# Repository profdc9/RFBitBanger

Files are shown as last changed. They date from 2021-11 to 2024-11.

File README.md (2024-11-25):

# RFBitBanger
The RFBitBanger is an off-the-grid QRP radio.  It is not just designed to be used off the grid, it is designed to be assembled and maintained off-the-grid.  Most radios require specialized parts that would be difficult to obtain in an extreme parts shortage or in remote places.  This radio is designed to be assembled and maintained using the most common jellybean components that might be in a hobbyist junkpile.  It will mainly support low bandwidth/digital modes to make the most of limited power.  

A presentation presented at the 2023 QSO Today conference on the RFBitBanger can be viewed on Youtube [here](https://www.youtube.com/watch?v=Fbgs_4QsKnE).

Design goals:

* A single band double-sideband radio, with the band changed by pluggable external filters on 20 m to 80 m.  A double-balanced ring mixer is used to provide good rejection of strong stations while not requiring any custom ICs such as SA612 or FST3253.  The mixer has strong drive to reduce nonlinearity.
* Can be assembled and operated by a properly licensed individual that may not have a great deal of electronics experience or experience at making HF contacts.  The radio is made from readily available through-hole parts which are widely available and have multiple vendor alternatives.  
* The parts needed are very common so that cheap spare parts can be stockpiled or scrounged from other equipment so that the radio may be more easily maintained in off-grid conditions.  The includes ATMEGA328P/Arduino Nano, LM358 op-amp, LM386 audio amplifier, 2N7000 MOSFETs, 2N3904 NPN transistor, SS8550 PNP transistor, and a HD44780 display.  It can use a SI5351A frequency synthesizer IC soldered to the board, or a plug-in SI5351A developmnet module.  There is a MS5351 workalike for this IC as well.  Ferrite cores are needed for transformers/chokes which can be easily bought (FT50-43) or scrounged as EMI suppression beads from cables.
* The radio has a novel digital mode called SCAMP, implemented on a ATMEGA328P (Arduino processor) which performs coherent FSK demodulation and forward error correction to achieve excellent performance in weak signal conditions.  No PC is required for this digital mode; it is implemented all on the Arduino.  The mode is designed to be simple to set up to make it easy to initiate a contact.
* It has a 50 ohm output and can use a simple quarter wave wire as an antenna.  A built-in RF ammeter with LED helps one adjust the length of the antenna for maximum radiation.
* The output power amplifier consists of 3 2N7000 transistors driven by a fourth 2N7000 transistor.  2N7000 transistors can be found generically for $0.03 each.  The output power stage is a class E amplifier with 3.5 to 5.0 W output based on serial resonance filters.  The best performance is obtained by using NP0/C0G capacitors and T50-6 core inductors, however, high voltage ceramic disc capacitors and air-core inductors can be used as substitutes with reduced performance.  The serial resonance filter is on a pluggable module that is replaced for each band.  BS170 transistors may be substituted for 2N7000 transistors easily as these have the reverse pinout to the 2N7000.
* It has PCBs available for the transceiver, but it could also be built on perfboard or using point-to-point wiring.  The PCB, however, is likely to be better performing.  There are also PCBs available for the filters.
* A jumper allows the amplifier board to be bypassed on receive to achieve MF and HF coverage.  The DSB receiver can be used with limitations as a receiver for the AM broadcast band and AM broadcast shortwave bands.
* It has an audio speaker output based on the LM386 IC.
* A second display board breaks out the display, and optional inputs for a microphone, a straight or iambic key, and a headphone/speaker jack.  
* A PS/2 keyboard is supported for full operation of the transceiver, including message entry, frequency selection, and data mode selection.
* There are five buttons corresponding to four arrow keys and an enter key.  Alphanumeric messages may be entered this way if necessary.
* There is a full complement of support for CW, including keyclick elimination on transmit, a built-in CW decoder, a CW encoder, and straight and iambic key support.
* RTTY 45/170 is supported as a mode for transmit and reception.
* Uses a common 2X16 HD44780-based LCD display.
* Supports SSB transmission based on the same method of the uSDX of frequency tracking and envelope recovery.
* Includes a 3d printable case, a 3d printable iambic key, and 3d printable coil forms for air core inductors.
* The PCBs are licensed under the CC-BY-SA 4.0 open source license, and the source code is licensed under the zlib open source license.

The RFBitBanger folder is the schematic and PCB for the radio itself.  The MatchTest is a PCB that has a directional coupler for measuring forward/reverse power as well as a reflection bridge to help match antenna impedance.  The Code folder contains the current RFBitBanger code.  The CAD directory contains FreeCAD parametric models and STL files. The Docs directory contains a guide to the transceiver and the details of the SCAMP digital mode implementation.

This design was started after a discuss on the [Collapse OS](http://collapseos.org) mailing list about hardware is maintainable even without access to parts suppliers, for example Digikey/Mouser, etc. or even Amazon.  Projects such as [civboot](https://github.com/civboot/civboot) seek to provide a means of resurrecting technology and infrastructure after a catastrophic event.  This design is to provide a means of communication if other forms of communications become unavailable, especially in rural areas or urban environments with compromised infrastructure.

Any comments to profdc9 AT gmail.com.

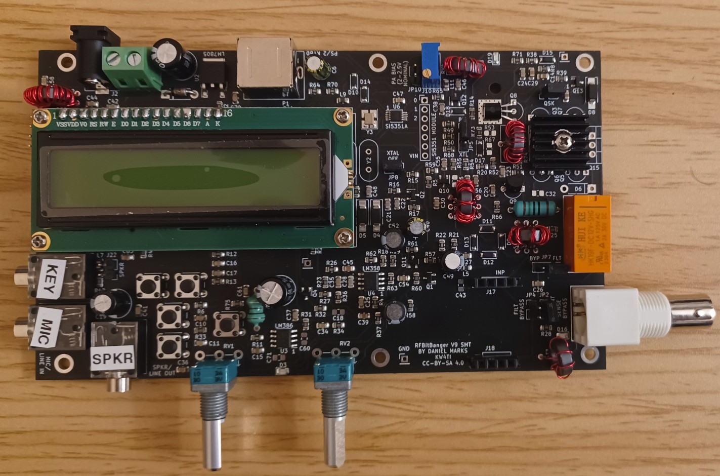
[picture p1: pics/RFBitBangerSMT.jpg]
RFBitBangerSMT

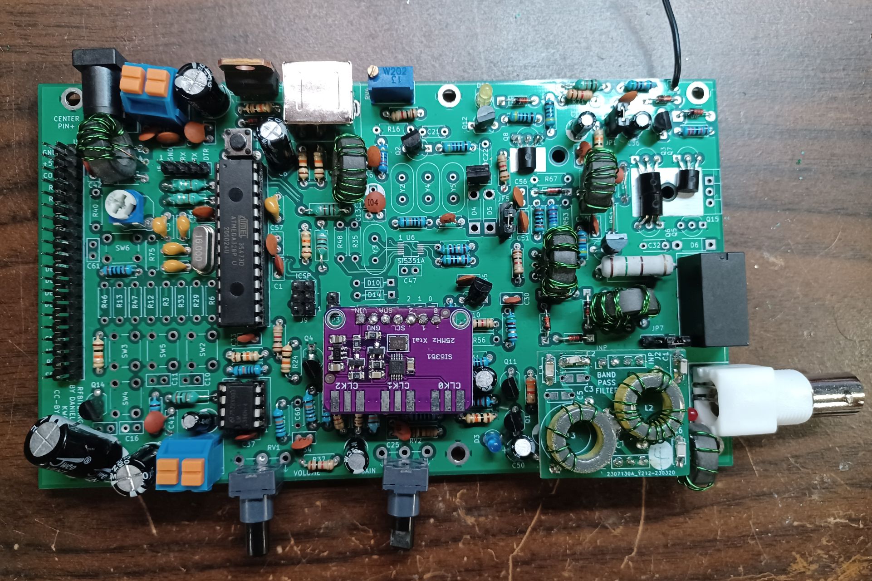
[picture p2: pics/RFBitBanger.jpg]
RFBitBanger

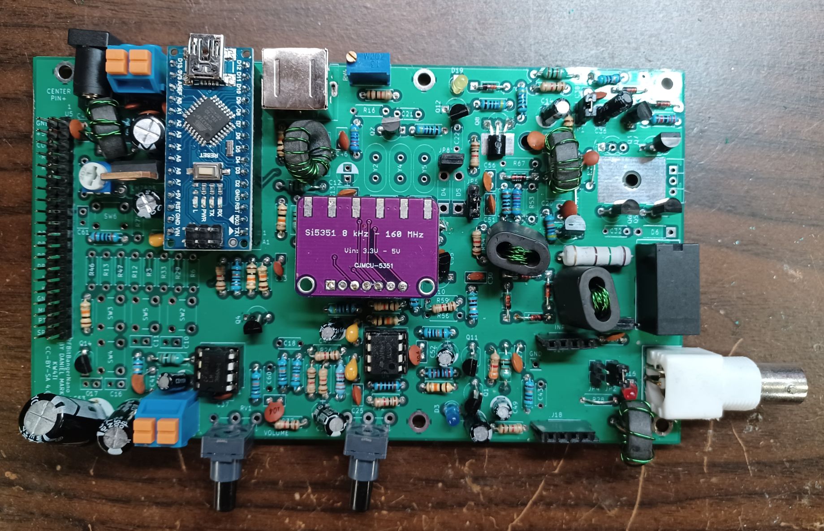
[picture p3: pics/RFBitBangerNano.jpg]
RFBitBangerNano


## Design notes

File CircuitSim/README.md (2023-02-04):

# RFBitBanger Circuit Simulations
These are simulations that were performed to verify aspects of the operation of the RFBitBanger.  They are created with [Qucs-S](https://https://ra3xdh.github.io/).  Only the schematic files are included and so the graphs and tables with the simulation results are blank when first loaded.  To perform the simulations, press F2 or click on the gear icon to compute the simulation results, and the graphs and tables of each simulation should be filled in.

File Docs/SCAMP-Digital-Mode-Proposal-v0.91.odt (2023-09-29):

Simple Conversational Amateur Messaging Protocol (SCAMP)

by Daniel Marks, KW4TI

Draft v0.91 2023-9-20

# Abstract

Modern digital modes for amateur radio tend to require complicated transceiver architectures. For example, most need upper sideband modulation with a very stable local oscillator. Furthermore, methods such as multiple FSK can be susceptible to effects such as intermodulation from strong adjacent stations. Earlier modulations such as CW, which uses on-off keying (OOK), and RTTY45, which uses 2 frequency-shift-keying (FSK) were usable on transceivers with much less demanding requirements. Recently, there has been a trend towards sending data with a very low symbol rate (e.g. FT8 and QRSS) in order to achieve communication with very low transmitter power and/or with poor receiving conditions. This is a proposal for a simple digital mode, Simple Conversational Amateur Messaging Protocol (SCAMP), that can be implemented with OOK or 2FSK for conversational or amateur radio contest QSOs, can be implemented with relatively crude transceivers, and on simple 8-bit microprocessors such as the ATMEGA328P used for the Arduino Uno or Nano. It has both conversational and data transfer modes, but is tailored more to low bit rate text connections.

# Introduction

There is now an abundance of amateur radio data modes. Early digital modes used FSK, for example, RTTY45, AMTOR, and its successors in packet radio. As personal computers became widely available with increasing processing power, as well as receivers with stable local oscillators, phase sensitive modes such as PSK31 and methods with small frequency shifts such as multiple frequency-shift keying (MFSK) (Olivia/Contestia) became possible, adding increased resistance to noise. Protocols specializing in very short messages, synchronized with a global time standard such as JT65/FT8/FT4 were designed for making QSOs with low power and in poor conditions. While there have been remarkable improvements in amateur radio data modes, with FT8 especially becoming quite popular, these require transceivers with very stable local oscillators that are resistant to intermodulation and other distortions. Furthermore, the computation required to decode some of these protocols requires a computer with powerful digital signal processing capability. There are instances when simple transmitters and receivers are desirable, that for example may only be capable of OOK (such as is used for CW transmission) or FSK (by selecting a PLL frequency or modulating a crystal oscillator). It would be further desirable if the processing ability of a microcontroller (for example, ATMEGA328P) was sufficient to encode and decode the data mode modulation. QRP transceivers, for example, often use simplified hardware, based on a PLL synthesizer or crystal oscillator with a direct conversion receiver. Controlled by a microprocessor, such QRP radios can be solar powered, are highly portable, and can serve as message relays, for telemetry, or for emergency use.

A de-facto specification for an efficient, reliable, portable HF communication protocol called Automatic Link Establishment exists, as specified in MIL-STD-188/141A. This protocol uses MFSK, forward error correction (FEC), frame interleaving, and automatic repeat request (ARQ), among other methods. This protocol has been very successful for its intended use, however, it requires the kind of complex transceivers and modems that this method wishes to avoid. However, there are aspects of such methods that can be adapted. In particular, few amateur radio modes combine simple modulation and forward error correction. Simple forms of forward error correction can be implemented on 8-bit processors, and other techniques like interleaving may also be used. Most forms of FEC require significant processing power to decode and use either dedicated hardware or high speed processors to implement methods like the Viterbi or Berlekamp-Massey algorithm. The extended (24,12,8) Golay code has been used in ALE and is a happy medium which achieves a ½ code rate and is able to correct 3 of 24 bits. Its primary disadvantage is that its short code length requires that the data is interleaved to be resistant to long error bursts. This is problematic for conversational modes for which long latency is an issue, especially for contesting. The Walsh/Hadamard codes used in Olivia/Contestia have this problem in particular because of their low code rate. The venerable extended (24,12,8) Golay code is a compromise solution that can be decoded by an 8-bit microcontroller, has reasonable latency, good code rate, and can correct up to 12.5% bit errors.

# Modulation layer

The modulation layer is of one of two types:

On Off Keying (OOK)– The carrier alternates between full power transmission and no transmission as a non-return to zero (NRZ) line code. The mark condition (or one bit) is transmitting and the space condition (or zero bit) is no transmission. Care should be taken that the transmitter does not significantly chirp the carrier when initiating a transmission. Envelope modulation may be built into the keying circuitry to prevent keyclick. The interval of each bit (transmitting or not transmitting) is identical and is given by the reciprocal of the baud rate.

2 Frequency Shift Keying (FSK) – When transmitting, the carrier alternates between two frequencies as a return-to-zero (RZ) line code. The mark condition corresponds to transmitting at one frequency and the space condition is transmitting on the other frequency. The mark frequency may be higher or lower than the space frequency. The separation between the two is determined by the baud rate. Ideally the separation is a multiple of ½ the baud rate, with a multiple of one corresponding to minimum shift keying (MSK). However, it is not expected that the transmitter can achieve a perfect separation frequency, nor can the receiver perfectly coherently decode a MSK signal. Therefore a separation equaling a multiple of the baud rate is used, so that for 100 mark or space intervals per second, these would be separated by 100 Hz. This nominally retains the orthogonality of the mark and space conditions but increases the tolerance to error in the separation frequency or local oscillator phase.

# Digital Encoding

Messages are sent as 30 bit data frames, in order of most significant bit to least significant bit (left to right as shown here). The format of each frame is

C XXXX C XXXX C XXXX C XXXX C XXXX C XXXX

MSB LSB

The 24 “X” are 24 data bits to be sent in the frame which are a Golay code word. Each “C” is the complement of the bit immediately following it. This ensures there are no more than five consecutive mark or spaces (ones or zeros) in a valid codeword or consecutive codewords. The transition between the mark and space condition is used to aid in clock recovery and to allow an initial or resynchronization phase to be recognized.

# Golay code word

Each Golay code word consists of two halves.

PPPP PPPP PPPP XXXX XXXX XXXX

MSB LSB

The Golay code word is a 24 bit code word that contains 12 bits of data payload to be sent, represented by “X” and 12 bits of parity, represented by “P”. The parity bits are calculated from the data bits using the (24,12,8) extended Golay encoding algorithm as given in the Appendix.

# Golay code word types

The Golay code word types are the 12-bit payload to be sent in the Golay code word. There are two Golay code word types.

Data code word type

1111 XXXX XXXX

MSB LSB

This encodes 8-bit raw binary data XXXX XXXX in order of MSB to LSB. This message is intended to be used for exchanging data for file transfer protocols and other uses left up to the users. It is not an efficient encoding of this data but is included so that the connection may be used for purposes other than text exchange.

Text code word type

YYYYYY XXXXXX

MSB LSB

These encode two 6 bit symbols XXXXXX and YYYYYY. The symbol XXXXXX precedes that of YYYYYY in the data stream, that is, when considered as part of a message, the symbol corresponding to XXXXXX precedes YYYYYY. The symbols encode characters as specified in a table in the Appendix. The 6-bit code corresponding to 000000 indicates “No symbol” so that no character should be decoded in the message for this 6-bit code. If only one code is to be sent in the code word, then XXXXXX should be the code, and YYYYYY should be 000000. A code word with both XXXXXX and YYYYYY being 000000 is valid and should be considered as two no symbols. This symbol may be sent continuously during a connection one wishes to send a real-time typing message, or alternatively one can initiate a resynchronization.

For additional redundancy, the same text code word may be sent multiple times in a row. If the receiver decodes the same code multiple times before receiving a different code, it should discard the redundant decodes of the code word. If the same code word needs to be sent multiple times and not have its redundant copies discarded, at least one no symbol code (000000 000000) should be sent between the code word and its next copy so that the receiver decodes a different code. Redundant copies should be sent in immediate succession, that is, there should be no delay between sending the redundant copies of the code word. This enables the copies of the code word to be coherently summed by the receiver. Redundantly sent data code words (as opposed to text code words) should not be discarded.

Reserved code word type

XXXXYY 1111YY

MSB LSB

where XXXX is not 1111. There are 240 possible reserved codes. These codes are listed in the Appendix.

# Frame Synchronization

One of the aspects of a protocol that is most susceptible to corruption is desynchronization of the bit stream, that is, incorrectly starting a 30-bit frame at the wrong point in the bit stream. Therefore a synchronization protocol is necessary that can synchronize the beginning of a 30-bit frame. A fixed 30-bit synchronization frame is used that the receiver can recognize to indicate when a full frame has been received, with the next 30-bit data frame starting immediately afterwards. To not be mistaken as a data frame, the synchronization codeword must not be likely to be received as a valid data frame, even with added noise corruption. As the 30-bit data frame has complement bits inserted into it, the synchronization code word should not have complement bits at the same positions for as few shifts of the code word as possible so that the synchronization and data frames are unlikely to be confused with added noise. Furthermore, the synchronization frame should have low autocorrelation sidelobes so that it is unlikely that a shift of the frame in the presence of noise triggers a synchronization.

The synchronization frame is given by the 30 bit number

11111 01101 00011 00111 01000 11110 or 0x3ED19D1E

which is sent MSB to LSB, or in order of left to right as written here. This codeword has a maximum of two complemented bits for any shift and an autocorrelation, given a bipolar encoding such that 1 is +1 and 0 is -1:

30 3 -2 -3 0 -1 -2 3 0 -3 -2 -1 4 1 2 -1 -4 1 2 3 -4 1 -2 -1 4 3 2 1 0 -1

so that the maximum off-peak autocorrelation without noise has a magnitude of 4 for a noise rejection capability of 20 log10 (30/4) = 17.5 dB. The receiver should continuously cross-correlate the incoming bit stream with this code word and reset the clock edge timer so that the first bit of the subsequent data code word is sampled at one bit interval after the peak of the cross-correlation occurs, or the synchronization frame is approximately matched by the last 30 bits. The codeword may be resent periodically to aid in resynchronization.

When first keying up a transmission, a receiver must be given time to start receiving. Furthermore, if the FSK mode is used, the receiver must determine which of the two FSK frequencies corresponds to the mark condition. To do this, a sequence of 24 mark intervals are sent at the beginning of the transmission, followed by 010101 to make a total of 30 bits to complete a frame, and finally the 30-bit synchronization code word. This pattern may be restarted at any time during the transmission to resynchronize the receiver with the transmitter. So in full, at the beginning of the transmission the following is sent:

11 1111 1111 1111 1111 1111 1101 0101

11 1110 1101 0001 1001 1101 0001 1110

The initial 24 one bit intervals provides sufficient time for the receiver to begin to receive. If the FSK mode is used, the receiver uses the received frequency with at least 15 consecutive bit lengths to denote the one bit. The 010101 provides six bit edges to synchronize with to make 30 bits for the first frame. The second frame is the synchronization frame to help ensure that the subsequent frames of 30 bits are correctly separated.

When a data frame is received without error, six pairs of complement bits should be received corresponding to the bit pairs 1 and 2, 6 and 7, 11 and 12, 16 and 17, 21 and 22, and 26 and 27. If six pairs of complement bits are not received, there are several possibilities as to what caused the error. Firstly, one of the bits may have been inverted, so for example only five rather than six pairs of complement bits are observed. However, another possibility is that an extra bit transition was observed, or a bit transition was missed. With the erroneous bit transition, it is unlikely that the six complemented bits will be observed in their proper positions. If an extra bit transition occurs in error, then the thirty bits of a frame occurs one bit sooner than it should for the uncorrupted frame. In this case, if the number of complement bits are counted for the frame with the frame being advanced one bit, ideally five complement bits should be counted, as this indicates that waiting for another bit transition would add the sixth complement bit pair and therefore complete the frame, though with bit errors (which might be corrected using FEC). If a bit transition is missed, then by examining the frame delayed by one bit, one should ideally count six complement bits, and this indicates that one counted an extra bit during the frame, and that the frame is the thirty bits that are delayed by one bit from the current bit. Furthermore, the most recently received bit is the first bit of the next frame. Importantly, by examining the number of complement bits in frames delayed or advanced by one bit, one can detect frame synchronization errors and possibly correct them by advancing or delaying the bit stream by one bit to compensate for the error.

# Appendices

## Six-bit symbol encoding

The following is a table of the six bit code. One or two of these codes form a 12-bit Golay code word which can send one or two character symbols. The six bit code is as follows:

| 000 | 001 | 010 | 011 | 100 | 101 | 110 | 111
000xxx | No symbol | Backspace | End of Line | (space) | ! (exclam- ation mark) | “ (double quote) | ‘ (single quote) | ( left parenthesis
001xxx | ) right parenthesis | * (asterisk) | + (plus) | , (comma) | - (minus) | . (period) | / (slash) | 0
010xxx | 1 | 2 | 3 | 4 | 5 | 6 | 7 | 8
011xxx | 9 | : (colon) | ; (semi colon) | = (equal) | ? (question mark) | @ (at) | A | B
100xxx | C | D | E | F | G | H | I | J
101xxx | K | L | M | N | O | P | Q | R
110xxx | S | T | U | V | W | X | Y | Z
111xxx | \ (backslash) | ^ (carat) | ` (grave) | ~ (tilde) | INVALID | INVALID | INVALID | INVALID

The codes 111100, 111101, 111110, and 111111 are invalid and are never to be used.

For languages that have diacritics, the single quote, carat, grave, tilde, and backslash may be interpreted as diacritics, with the diacritic applying to the previously sent character. The backslash may be interpreted as an umlaut. It is highly recommended to send the character and the diacritic in the same Golay codeword so that these are decoded in the same word. A “No symbol” (000000) can be placed in the previous codeword to ensure that the next symbol is included with its diacritic.

For other characters representable by 8-bit bytes, for example UTF-8 encoding could be used. However, as UTF-8 has variable length symbols, missed bytes could result in sustained decoding failures, which is a serious drawback for amateur communications unless there is a redundancy check and an automatic retransmit request mechanism.

## Reserved Word Code Types

The following reserved words are defined. Note that the first four binary digits of the reserved word must not be 1111.

000000 111100: End of transmission. This instructs the receiver to return to listening for the synchronization protocol so that further data/text frames are not decoded until another synchronization protocol is completed. This may be sent multiple times at the end of transmission as it is idempotent.

XXXXXX 111111: 28 codes that are reserved for switching to a character set. A reserved word to switch to a character set may be sent multiple times to ensure the correct character set is selected; these codes are idempotent. For standard six bit encodings, there are only 59 available characters to define in each set (000001-111011) with 0 and 60-63 reserved. Because of this, there many be some compromises to a language’s orthography. For twelve bit encodings which encode only one character in each frame (for example Chinese or Devanagari), there are 59×59=3481 possible codes which are likely to correspond to Unicode characters. Here are tentative codes designated for some common character sets:

000000 111111: Latin (6 bit)

000001 111111: Augmented Latin (12 bit)

000010 111111: Cyrillic (6 bit)

000011 111111: Greek (6 bit)

000100 111111: Arabic (6 bit)

000101 111111: Hebrew (6 bit)

000110 111111: Simplified Chinese (12 bit)

000111 111111: Traditional Chinese (12 bit)

001000 111111: Japanese (Wabun Japanese text in Morse code character set) (6 bit)

001001 111111: Japanese (Hiragana, Katakana, and Kanji) (12 bit)

001010 111111: Hangul (6 bit)

001011 111111: Devanagari (12 bit)

## It is quite likely that embedded applications with limited storage will only support subsets of these characters, for example, Hiragana/Katakana only for Japanese.

## Golay Matrix and Encoding/Decoding

The Golay matrix is for the extended (24,12,8) Golay code. The code is implemented using the perfect (23,11,7) Golay code with an extra parity bit included. This can be implemented by multiplying the 12-bit code word with the Golay parity check matrix to obtain the 12-bit Golay parity check word. The Golay matrix is its own inverse, so that applying the matrix to a 12-bit word, and then again to the result, yields the original word. The implementation of the Golay coding is in the code Appendix.

The encoded word is simply the 12-bit word to be send with the 12-bit parity code prepended to it. The Golay code can correct up to 3 bit errors, and so to decode every possible error up to 3 bits, this code performs the following:

1. Check to see if all three error bits are in the sent parity bits by calculating the parity code of the sent 12-bit word and seeing if there are three or fewer difference bits between the sent parity and the calculated parity. If so, the sent 12-bit word is correct.

2. Check to see if all three errors are in the sent 12-bit word. Calculate the 12-bit word that would be obtained with the given parity code and see if there are three or fewer difference bits between the sent word and the calculated word. If so, the calculated word is correct.

3. Try flipping every bit in the sent 12-bit word and see if there are 2 or fewer errors between the calculated parity and the sent parity. If so, we know which bit of the 12-bit word is wrong and it is corrected.

4. Try flipping every bit in the sent parity code and see if there are 2 or fewer errors between the calculated 12-bit word and the sent word. If so, we know which bits are wrong in the sent word and it is corrected.

5. Otherwise, the error is uncorrectable or undetectable.

## Golay Implementation Example

const uint16_t golay_matrix[12] =

{

0b110111000101,

0b101110001011,

0b011100010111,

0b111000101101,

0b110001011011,

0b100010110111,

0b000101101111,

0b001011011101,

0b010110111001,

0b101101110001,

0b011011100011,

0b111111111110

};

uint16_t golay_mult(uint16_t wd_enc)

{

uint16_t enc = 0;

uint8_t i;

for (i=12;i>0;)

{

i--;

if (wd_enc & 1) enc ^= golay_matrix[i];

wd_enc >>= 1;

}

return enc;

}

uint8_t golay_hamming_weight_16(uint16_t n)

{

uint8_t s = 0, v;

v = (n >> 8) & 0xFF;

while (v)

{

v = v & (v - 1);

s++;

}

v = n & 0xFF;

while (v)

{

v = v & (v - 1);

s++;

}

return s;

}

uint32_t golay_encode(uint16_t wd_enc)

{

uint16_t enc = golay_mult(wd_enc);

return (((uint32_t)enc) << 12) | wd_enc;

}

uint16_t golay_decode(uint32_t codeword, uint8_t *biterrs)

{

uint16_t enc = codeword & 0xFFF;

uint16_t parity = codeword >> 12;

uint8_t i, biterr;

uint16_t syndrome, parity_syndrome;

/* if there are three or fewer errors in the parity bits, then

we hope that there are no errors in the data bits, otherwise

the error is uncorrected */

syndrome = golay_mult(enc) ^ parity;

biterr = golay_hamming_weight_16(syndrome);

if (biterr <= 3)

{

*biterrs = biterr;

return enc;

}

/* check to see if the parity bits have no errors */

parity_syndrome = golay_mult(parity) ^ enc;

biterr = golay_hamming_weight_16(parity_syndrome);

if (biterr <= 3)

{

*biterrs = biterr;

return enc ^ parity_syndrome;

}

/* we flip each bit of the data to see if we have two or fewer errors */

for (i=12;i>0;)

{

i--;

biterr = golay_hamming_weight_16(syndrome ^ golay_matrix[i]);

if (biterr <= 2)

{

*biterrs = biterr+1;

return enc ^ (((uint16_t)0x800) >> i);

}

}

/* we flip each bit of the parity to see if we have two or fewer errors */

for (i=12;i>0;)

{

i--;

uint16_t par_bit_synd = parity_syndrome ^ golay_matrix[i];

biterr = golay_hamming_weight_16(par_bit_synd);

if (biterr <= 2)

{

*biterrs = biterr+1;

return enc ^ par_bit_synd;

}

}

return 0xFFFF; /* uncorrectable error */

}

## Implementation of the Finite Impulse Reponse (FIR) filters

The following describes a method of implementing the FIR filters that can be performed with only two multiplications per sample per filter. The FIR filter prevents cumulative error from precision loss. Therefore low precision multiplication operations (even 8 by 8 bit or 16 by 16 bit multiplication operations) can be used.

The following approach is used. An analog anti-aliasing filter can be applied before the signal from the mixer is samples by an analog-to-digital converter (ADC). This removes harmonics that do not need to be filtered in software, making the application of a quadrature demodulator and low-pass filter relatively easy.

The filters are driven by a master sample clock which is typically the sample rate of the ADC. This frequency is denoted here by f and the corresponding sampling period T=1/f. Each period T, the ADC is sampled as a sample x[n], usually as the first operation in an interrupt service routine to apply the filter. In-phase and quadrature filters must be applied to the data stream. Because of this, the filter length N must be divisible by four. The recursive FIR filter formula for a filter of length m is

yi[n] = yi[n-1] + Im[n mod m](x[n] – x[n-N])

yq[n] = yq[n-1] + Qm[n mod m](x[n] – x[n-N])

A circular buffer of samples of length N may be used to hold previous samples. Because the same value is subtracted at the beginning and end of the filter, there is no cumulative error. An approximation to the magnitude of the signal may be calculated as

mr[n] = max(abs(yi[n]),abs(yq[n])) + floor[(abs(yi[n])+abs(yq[n])) / 2]

The divide by two operation is an unsigned right shift by one bit operation.

The 16-bit representations of the filters used in SCAMP are as follows:

I8[n]={ 16384,-11585,0,11585,-16384,11585,0,-11585 } (750 Hz)

Q8[n]={ 0,11585,-16384,11585,0,-11585,16384,-11585 }

I12[n]={ 16384,-8192,-8192,16384,-8192,-8192,16384,-8192,-8192,16384,-8192,-8192 } (667 Hz)

Q12[n]={ 0,14189,-14189,0,14189,-14189,0,14189,-14189,0,14189,-14189 }

I16[n]={ 16384,-6270,-11585,15137,0,-15137,11585,6270,-16384,6270,11585,-15137,0,15137,-11585,-6270 } (625 Hz)

Q16[n]={ 0,15137,-11585,-6270,16384,-6270,-11585,15137,0,-15137,11585,6270,-16384,6270,11585,-15137 }

I20[n]={ 16384,-5063,-13255,13255,5063,-16384,5063,13255,-13255,-5063,16384,-5063,-13255,13255,5063,-16384,5063,13255,-13255,-5063 } (600 Hz)

Q20[n]={ 0,15582,-9630,-9630,15582,0,-15582,9630,9630,-15582,0,15582,-9630,-9630,15582,0,-15582,9630,9630,-15582 }

I24[n]={ 16384,-4240,-14189,11585,8192,-15826,0,15826,-8192,-11585,14189,4240,-16384,4240,14189,-11585,-8192,15826,0,-15826,8192,11585,-14189,-4240 } (583 Hz)

Q24[n]={ 0,15826,-8192,-11585,14189,4240,-16384,4240,14189,-11585,-8192,15826,0,-15826,8192,11585,-14189,-4240,16384,-4240,-14189,11585,8192,-15826 }

Two of these filters are mutually orthogonal if a filtering period is taken that is the least common multiple of the length of the filter. For example, the filters of length 12 and 20 have a least common multiple of 60, so N must be a multiple of 60 for the filters to be orthogonal. Similarly, the filters 8 and 24 have a least common multiple of 24, so N must be a multiple of 24 for the filters to be orthogonal. The symbol period is then a multiple of N samples for the orthogonality to be preserved.

The standard sample rate for SCAMP is 2000 Hz, so that the filter 8 length frequency corresponds to 750 Hz, the filter 12 length frequency corresponds to 667 Hz, the filter 16 length frequency corresponds to 625 Hz, the filter 20 length frequency corresponds to 600 Hz, and the filter 24 length frequency corresponds to 583 Hz.

## Standard SCAMP Modes and Variable Frequency Oscillator (VFO) frequency selection

SCAMP is intended to be used with both double sideband (DSB) transceivers and single sideband (SSB) transceivers in the upper sideband. To accommodate this, the following conventions are used.

For direct conversion double sideband transceivers (such as the RFBitBanger), there is an ambiguity because a SCAMP signal may be decoded either on the upper or lower sideband. For SCAMP OOK modes, there is a single frequency fmark, while for FSK modes there are two frequencies fmark and fspace. If the VFO is set to a frequency fvfo, for OOK modes the transmitted SCAMP signal mark frequency is fvfo while for FSK modes, the mark transmission is at the frequency fvfo+(fmark-fspace)/2 and the space transmission is at the frequency fvfo+(fspace-fmark)/2 (note the difference in order) so that the mark and space frequencies are symmetrically separated about fvfo. When receiving, the local oscillator (LO) is set to fvfo-fmark for OOK modes, and fvfo-(fspace+fmark)/2 for FSK modes. Therefore the beat frequency for the mark tone is at fmark and the beat frequency for the space tone (for FSK modes) is fspace. This will place the mark and space beat frequencies aligned with the digital filters so that the audio sampling can demodulate them. Note that if the VFO is tuned above a received SCAMP transmission center frequency by fmark (OOK) or (fspace+fmark)/2 (FSK) (rather than below as would normally occur), reception will occur successfully on the lower sideband rather than the upper sideband, however, response transmissions will be above the frequency at which the other station expects the response by a frequency of 2fmark (OOK) or (fspace+fmark) (FSK). Therefore an operator of the DSB radio must ensure that the upper sideband is selected by tuning the VFO such that the tone frequency of the receiving station decreases as the VFO frequency is increased.

For single sideband transceivers operated in the upper sideband (USB), the choice of VFO frequency depends on the type of modem used. A software modem implemented on a personal computer or mobile phone with sufficient signal processing power can dynamically change filter frequencies and/or transmitted signal frequencies easily and so can accommodate processing the SCAMP signals at any frequency within the USB passband (usually 1.5 -3.0 kHz wide), and furthermore, frequently such software modems may decode several received signals simultaneously within the USB passband. For modems without much processing power (for example ATMEGA328P-based hardware), however, the audio signal must be aligned with digital filter frequencies programmed into the SCAMP modem. The VFO of the SSB transceiver must then be set to place the received SCAMP frequencies to be aligned with the digital filter frequencies within the USB passband. This would typically be accomplished by tuning the VFO of the transceiver with a signal strength indicator on the modem determining when the received signal is aligned with the digital filter frequencies.

The following are the standard modes for SCAMP. The sample clock signal is 2 kHz, so one sample corresponds to 0.5 ms. For FSK modes, the MARK and SPACE frequencies are interchangeable. Note that the tuning sensitivity is approximately ¼ to 1/3 the symbol rate, so for example, the SCAMP FSK SLOW mode with a symbol rate of 16.7 bits/second needs to be tuned within 2-4 Hz to be properly decoded. The SCAMP FSK VSLW mode is even more stringent, with tuning within 1-2 Hz for the most reliable decoding. This is a reason why a method of easily and accurately aligning transmitting and receiver LO is needed.

SCAMP OOK:

MARK IF = 625 Hz (length 16 filter)

Symbol length N=64 samples (32 ms, 31.25 bits per second, 25.0 WPM)

SCAMP OOK SLOW:

MARK IF = 625 Hz (length 16 filter)

Symbol length N=144 samples (72 ms, 13.89 bits per second, 11.1 WPM))

SCAMP FSK:

SPACE IF=600 Hz (length 20 filter), MARK IF=667 Hz (length 12 filter).

Symbol length N=60 samples (30 ms, 33.3 bits per second, 26.6 WPM).

SCAMP FSK FAST:

SPACE IF=583 Hz (length 24 filter), MARK IF=750 (length 8 filter).

Symbol length N=24 samples (12 ms, 83.3 bits per second, 66.7 WPM).

SCAMP FSK SLOW:

SPACE IF=625 Hz (length 16 filter), MARK IF=667 Hz (length 12 filter).

Symbol length N=144 samples (72 ms, 13.89 bits per second, 11.1 WPM).

SCAMP FSK VERY SLOW:

SPACE IF=312.5 Hz (length 16 filter), MARK IF=333.3 Hz (length 12 filter,

1000 Hz sample rate achieved by summing together every two samples at 2000 Hz).

Symbol length N=144 samples (144 ms, 6.94 bits per second, 5.56 WPM).

## Error probability and frame probabilty vs. Eb/N0

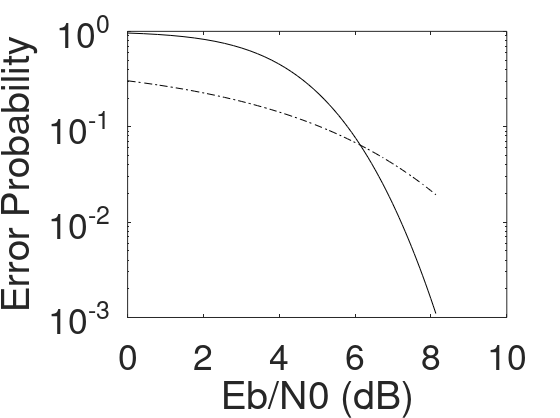
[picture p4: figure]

Dotted curve, bit error rate (BFSK).

Solid curve, frame error rate (probability of 4 or more bit errors).

Conversion between 2500 Hz SNR_per_bit, SNR@2500 Hz and Eb/N0:

Eb/N0 = SNR_per_bit / k (k=1 for BFSK, k=2 for 4FSK, k=3 for 8FSK, etc.)

SNR@2500Hz = SNR_per_bit (bits per second / 2500 Hz)

For 10⁻³ frame error, the Eb/N0 required is 8.1 dB, and the SNR_per_bit is 8.1 dB.

For SCAMP FSK FAST, the SNR@2500Hz required is 8.1 dB – 10 log(83.3/2500) = -6.67 dB

For SCAMP FSK, the SNR@2500Hz required is 8.1 dB – 10 log(26.6/2500) = -11.6 dB

For SCAMP FSK SLOW, the SNR@2500Hz required is 8.1 dB – 10 log(13.9/2500) = -14.5 dB

For SCAMP FSK VERY SLOW, the SNR@2500Hz required is 8.1 dB – 10 log(6.9/2500) = -17.5 dB

## A crude implementation of the FIR filters

If one does not have a hardware integer multiplication unit available, the processor may be too slow even to apply two multiplications per sample per filter. In this case, an approximation that uses only adds and subtracts may be used. These filters admit odd harmonics of the fundamental frequency and so analog filtering is required to reduce these to prevent aliasing. Note that the length 8 and length 24 filters are not orthogonal, and so this method can not be used for the SCAMP FSK FAST mode. Here are the filters in FIR form:

I8[n]={ 1,1,1,1,-1,-1,-1,-1 } (250 Hz)

Q8[n]={ 1,1,-1,-1,-1,-1,1,1 }

I12[n]={ 1,1,1,1,1,1,-1,-1,-1,-1,-1,-1 } (167 Hz)

Q12[n]={ 1,1,1,-1,-1,-1,-1,-1,-1,1,1,1 }

I16[n]={ 1,1,1,1,1,1,1,1,-1,-1,-1,-1,-1,-1,-1,-1, } (125 Hz)

Q16[n]={ 1,1,1,1,-1,-1,-1,-1,-1,-1,-1,-1,1,1,1,1 }

I20[n]={ 1,1,1,1,1,1,1,1,1,1,-1,-1,-1,-1,-1,-1,-1,-1,-1,-1 } (100 Hz)

Q20[n]={ 1,1,1,1,1,-1,-1,-1,-1,-1,-1,-1,-1,-1,-1,1,1,1,1,1 }

I24[n]={ 1,1,1,1,1,1,1,1,1,1,1,1,-1,-1,-1,-1,-1,-1,-1,-1,-1,-1,-1,-1 } (83.3 Hz)

Q24[n]={ 1,1,1,1,1,1,-1,-1,-1,-1,-1,-1,-1,-1,-1,-1,-1,-1,1,1,1,1,1,1 }

## These have the simple form that is more convenient for implementation:

Im[n] = 1 for 0 ≤ n < m/2

Im[n] = -1 for m/2 ≤ n < m

Qm[n] = 1 for 0 ≤ n < m/4 or 3m/4 ≤ n < m

Qm[n] = -1 for m/4 ≤ n < 3m/4

Note that the offsets of the filters are 500 Hz lower than the offsets in the integer multiplication versions of the FIR filters. To match up the send and receive frequencies between a transmitter using the higher offsets, a receive incremental tuning (RIT) method could be used to offset the receive frequency from the VFO frequency by 500 Hz.

## Other candidate synchronization code words

During the search for code words, these other candidate 30-bit code words were discovered. The chosen code word was decided by having the maximum number of preceding ones so it would be part of a constant carrier signal. These code words all have a maximum of two complement bits for any shift of the word and a correlation magnitude of 4. These were found by exhaustive computer search.

syncword: 1,0,0,0,0,1,1,1,0,1,0,0,0,1,1,0,0,1,1,1,0,1,0,0,1,0,0,0,0,0

autocor: 30 3 -2 -3 0 -1 -2 3 0 -3 -2 -1 4 1 2 -1 -4 1 2 3 -4 1 -2 -1 4 3 2 1 0 -1

syncword: 1,0,0,0,0,1,1,1,1,0,1,1,1,1,1,0,0,1,0,1,0,0,1,1,1,0,1,1,0,0

autocor: 30 3 -2 -1 -4 3 -2 1 -4 -3 -4 -1 4 3 4 -3 2 3 -2 3 -2 -3 -2 -3 0 -1 2 3 0 -1

syncword: 1,0,0,0,0,1,1,1,1,1,0,0,1,1,1,0,1,1,1,0,1,1,1,0,1,0,0,1,0,0

autocor: 30 3 -2 -1 2 -3 0 1 4 3 -2 -3 -2 1 0 1 -2 -3 0 -3 -4 -1 2 -3 2 1 0 3 0 -1

syncword: 1,0,0,0,0,1,1,1,1,1,0,1,1,1,1,0,0,1,1,0,1,1,0,1,1,0,0,0,1,0

autocor: 30 3 -4 3 -2 -3 4 3 -4 -1 -2 1 4 -1 0 1 -2 -1 -2 -3 -4 -1 -2 3 2 1 0 -1 2 -1

syncword: 1,0,1,1,1,0,0,1,0,0,1,0,0,1,1,0,0,0,0,1,0,0,0,0,0,1,1,1,1,0

autocor: 30 3 -4 3 -2 -3 4 3 -4 -1 -2 1 4 -1 0 1 -2 -1 -2 -3 -4 -1 -2 3 2 1 0 -1 2 -1

syncword: 1,0,1,1,1,0,1,0,0,1,0,0,0,0,1,0,0,0,1,1,0,0,0,0,0,1,1,1,0,0

autocor: 30 3 -2 -3 0 3 2 3 2 1 -2 -1 4 -1 -2 -1 4 -1 -2 -1 -4 1 0 3 0 -1 -2 1 0 -1

syncword: 1,1,0,0,0,1,1,1,1,0,1,0,0,0,1,0,0,0,1,1,0,0,1,0,0,1,0,0,0,0

autocor: 30 3 -4 -1 2 -1 0 1 4 1 -4 3 4 3 2 -1 -4 3 2 -1 -2 -3 -2 -3 2 3 0 -1 -2 -1

syncword: 1,1,0,0,0,1,1,1,1,1,0,0,1,1,1,0,1,1,1,1,0,1,1,0,1,0,0,0,1,0

autocor: 30 3 -2 -3 0 3 2 3 2 1 -2 -1 4 -1 -2 -1 4 -1 -2 -1 -4 1 0 3 0 -1 -2 1 0 -1

syncword: 1,1,0,0,1,0,0,0,1,1,0,1,0,1,1,0,0,0,0,0,1,0,0,0,0,1,1,1,1,0

autocor: 30 3 -2 -1 -4 3 -2 1 -4 -3 -4 -1 4 3 4 -3 2 3 -2 3 -2 -3 -2 -3 0 -1 2 3 0 -1

syncword: 1,1,0,1,1,0,1,0,0,0,1,0,0,0,1,0,0,0,1,1,0,0,0,0,0,1,1,1,1,0

autocor: 30 3 -2 -1 2 -3 0 1 4 3 -2 -3 -2 1 0 1 -2 -3 0 -3 -4 -1 2 -3 2 1 0 3 0 -1

syncword: 1,1,0,1,1,0,1,1,1,1,0,0,1,1,1,0,0,0,1,0,1,1,1,1,0,1,0,0,0,0

autocor: 30 3 0 -1 -4 3 -2 -3 0 3 -2 1 2 3 4 -3 -2 3 0 1 -4 -1 2 -3 0 -1 -2 -1 -2 -1

syncword: 1,1,1,0,0,1,1,0,1,0,1,0,1,1,0,1,1,1,1,1,0,1,1,1,1,0,0,0,0,0

autocor: 30 3 4 1 0 3 2 1 -2 -3 -4 3 -4 -1 -2 -1 4 3 2 -1 -2 1 4 1 0 -1 -2 -3 -2 -1

syncword: 1,1,1,1,0,1,0,0,0,0,1,0,1,1,1,0,0,0,1,1,0,0,0,0,1,0,0,1,0,0

autocor: 30 3 0 -1 -4 3 -2 -3 0 3 -2 1 2 3 4 -3 -2 3 0 1 -4 -1 2 -3 0 -1 -2 -1 -2 -1

syncword: 1,1,1,1,0,1,1,0,1,1,0,0,1,1,1,0,1,1,1,0,1,0,0,0,0,1,1,1,0,0

autocor: 30 3 -4 -1 2 -1 0 1 4 1 -4 3 4 3 2 -1 -4 3 2 -1 -2 -3 -2 -3 2 3 0 -1 -2 -1

syncword: 1,1,1,1,1,0,0,0,0,1,0,0,0,0,0,1,0,0,1,0,1,0,1,0,0,1,1,0,0,0

autocor: 30 3 4 1 0 3 2 1 -2 -3 -4 3 -4 -1 -2 -1 4 3 2 -1 -2 1 4 1 0 -1 -2 -3 -2 -1

syncword: 1,1,1,1,1,0,1,1,0,1,0,0,0,1,1,0,0,1,1,1,0,1,0,0,0,1,1,1,1,0

autocor: 30 3 -2 -3 0 -1 -2 3 0 -3 -2 -1 4 1 2 -1 -4 1 2 3 -4 1 -2 -1 4 3 2 1 0 -1

## Software License for Code

The code examples in this document are licensed under the zlib license, the text of which is included below.

/*

* Copyright (c) 2021 Daniel Marks

This software is provided 'as-is', without any express or implied

warranty. In no event will the authors be held liable for any damages

arising from the use of this software.

Permission is granted to anyone to use this software for any purpose,

including commercial applications, and to alter it and redistribute it

freely, subject to the following restrictions:

1. The origin of this software must not be misrepresented; you must not

claim that you wrote the original software. If you use this software

in a product, an acknowledgment in the product documentation would be

appreciated but is not required.

2. Altered source versions must be plainly marked as such, and must not be

misrepresented as being the original software.

3. This notice may not be removed or altered from any source distribution.

*/

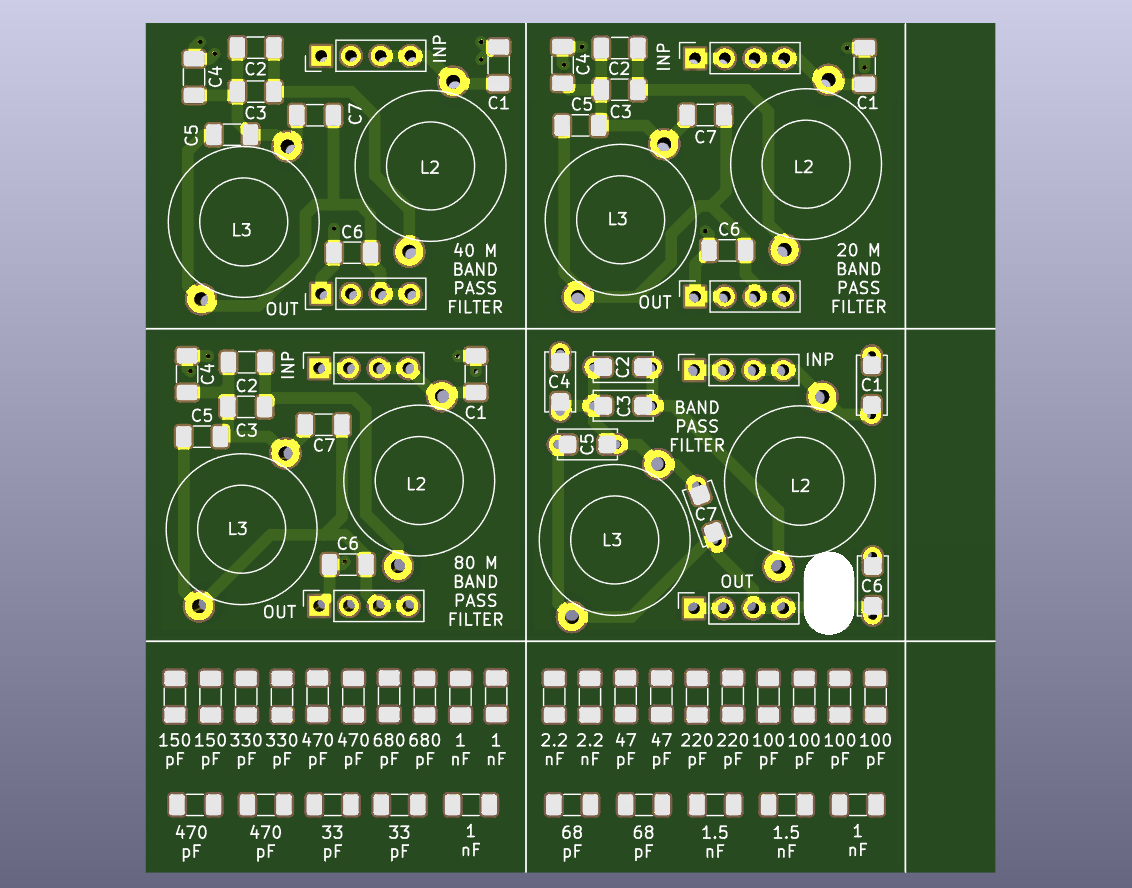
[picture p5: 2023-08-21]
SerialResonantFilterSMT/SerialResonantFilter.png

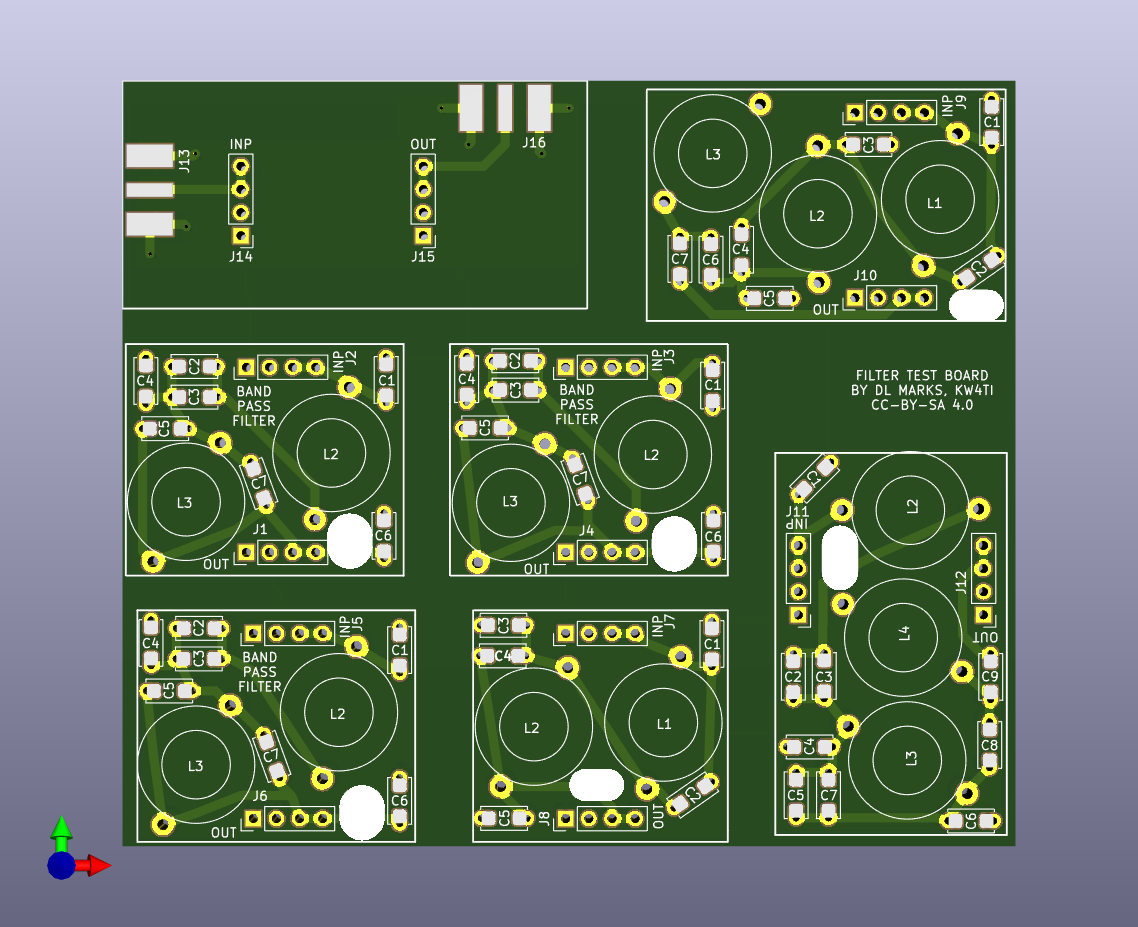
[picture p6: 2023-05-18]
BandPassFilter/BandPassFilter.png

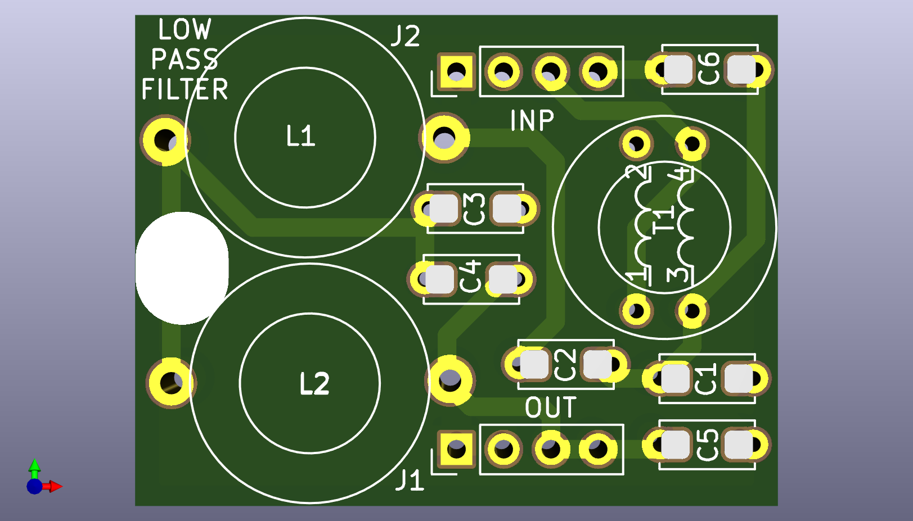
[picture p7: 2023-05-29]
LowPassFilter/LowPassFilter.png

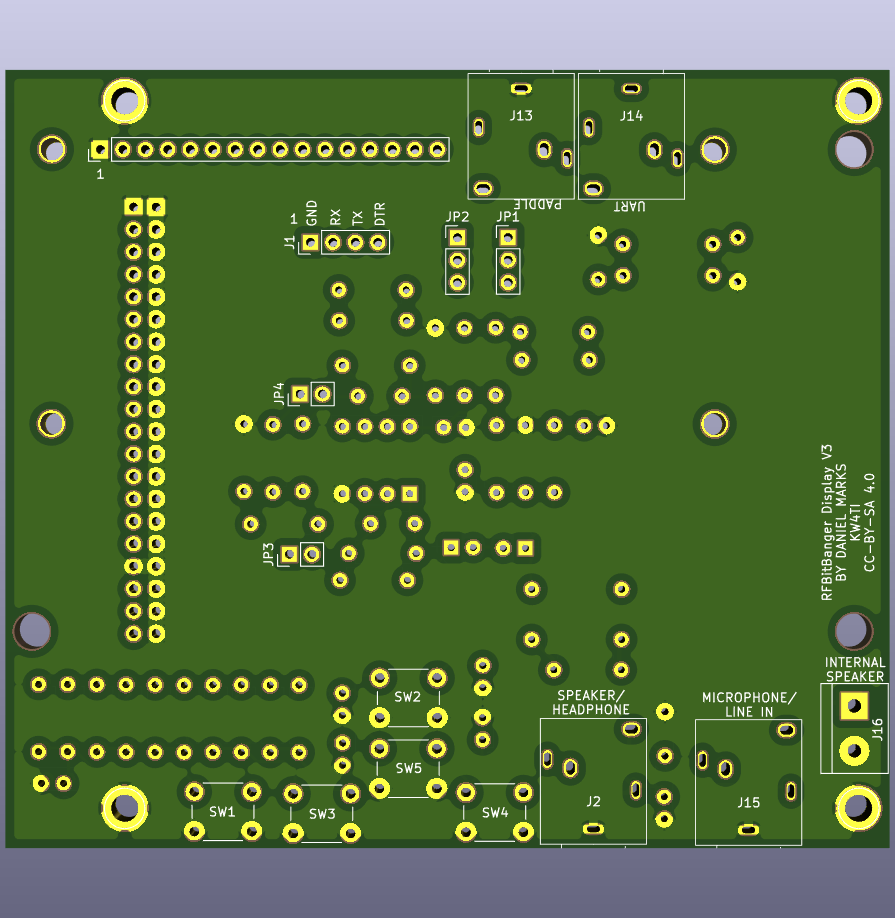
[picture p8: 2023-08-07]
BitBangDisplay/BitBangDisplay.png

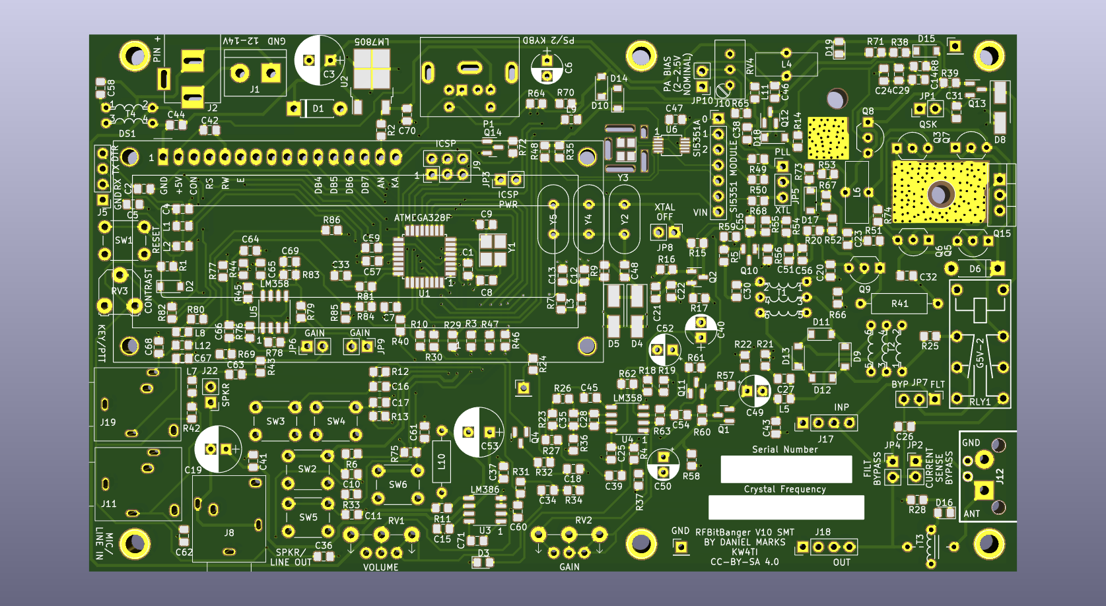
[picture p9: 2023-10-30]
RFBitBangSMT/RFBitBangSMT.png

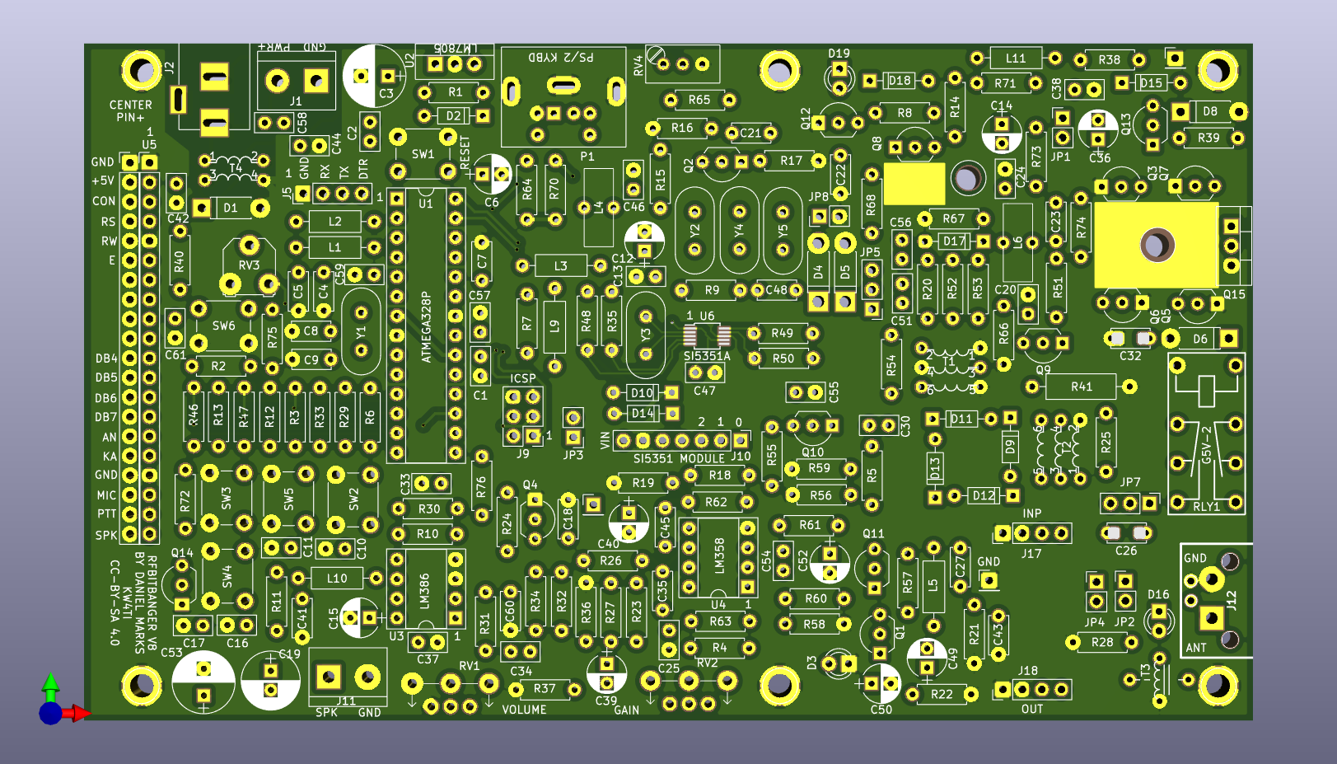
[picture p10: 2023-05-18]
RFBitBanger/RFBitBanger.png

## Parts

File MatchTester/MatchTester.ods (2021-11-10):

 | DirectionalCoupler Bill of Materials
Ref | Value
 | FT50-43 ferrite toroid with 15 secondary turns of 0.25 to 0.5 mm wire
 | FT50-43 ferrite toroid with 15 secondary turns of 0.25 to 0.5 mm wire
C1 | 10 nF 50 V ceramic disc capacitor
C2 | 10 nF 50 V ceramic disc capacitor
C3 | 10 nF 50 V ceramic disc capacitor
C4 | 10 nF 50 V ceramic disc capacitor
C5 | 10 nF 50 V ceramic disc capacitor
C6 | 10 nF 50 V ceramic disc capacitor
C7 | 10 nF 50 V ceramic disc capacitor
C8 | 10 nF 50 V ceramic disc capacitor
C12 | 10 nF 50 V ceramic disc capacitor
D1 | 1N5711 (or ebay “1N60P”)
D2 | 1N5711 (or ebay “1N60P”)
D3 | 1N4744A
D4 | 1N4004
D5 | 1N4004
D7 | 1N4148
D8 | 1N4148
F1 | Keystone 3544-2 / SL-506P
J1 | 2 position 5.08 mm screw terminal block
J2 | 2 position 5.08 mm screw terminal block
J3 | 2 position 5.08 mm screw terminal block or right-angle BNC isolated PCB receptacle
J4 | 2 position 5.08 mm screw terminal block or right-angle BNC isolated PCB receptacle
J17 | DC Barrel_Jack
J18 | 2 position 5.08 mm screw terminal block or right-angle BNC isolated PCB receptacle
J19 | 2 position 5.08 mm screw terminal block
J20 | 2 position 5.08 mm screw terminal block or right-angle BNC isolated PCB receptacle
J33 | 1 rows of 3 pin headers 2.54 mm spacing
JP1 | 1 rows of 3 pin headers 2.54 mm spacing
JP2 | 1 rows of 2 pin headers 2.54 mm spacing
JP3 | 1 rows of 2 pin headers 2.54 mm spacing
JP4 | 1 rows of 2 pin headers 2.54 mm spacing
JP5 | 1 rows of 2 pin headers 2.54 mm spacing
JP6 | 1 rows of 2 pin headers 2.54 mm spacing
JP7 | 1 rows of 2 pin headers 2.54 mm spacing
JP8 | 1 rows of 2 pin headers 2.54 mm spacing
JP9 | 1 rows of 2 pin headers 2.54 mm spacing
JP12 | 1 rows of 2 pin headers 2.54 mm spacing
L1 | 100 uH RF choke inductor wound around ferrite rod
R1 | 100R 1 watt resistor
R2 | 100R 1 watt resistor
R3 | 100R 1 watt resistor
R4 | 100R 1 watt resistor
R5 | 10k ¼ watt resistor
R6 | 10k ¼ watt resistor
R7 | 10k ¼ watt resistor
R8 | 10k ¼ watt resistor
R21 | 10k ¼ watt resistor
R23 | 1k ¼ watt resistor

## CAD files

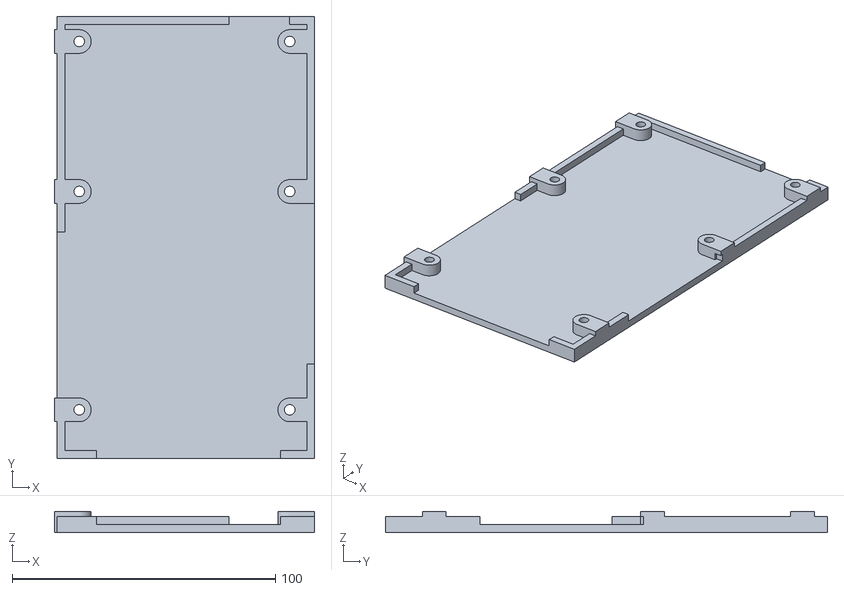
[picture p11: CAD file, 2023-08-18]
CAD/BottomCase-SMT-BottomCaseBody.stl
99.0 x 168.0 x 8.00

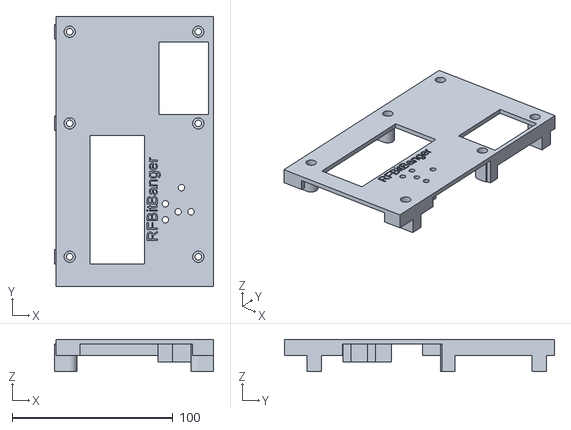
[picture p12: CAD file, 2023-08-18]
CAD/TopCase-SMT-TopCaseBody.stl
99.0 x 168.0 x 20.0

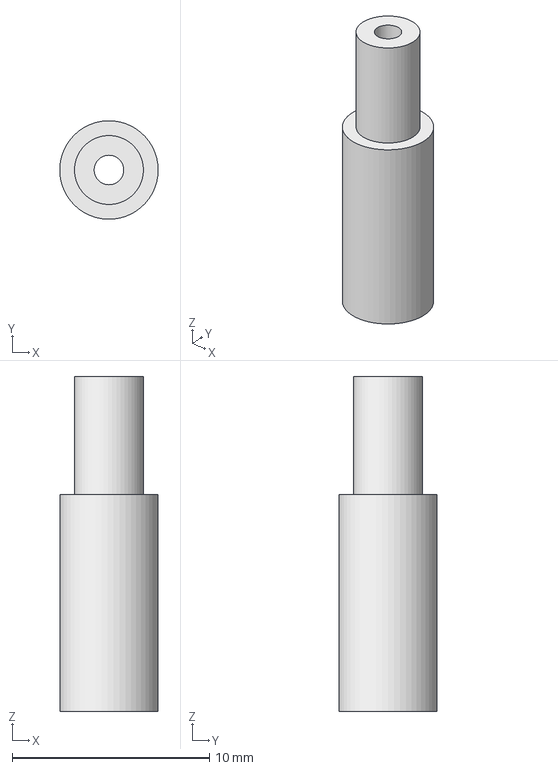
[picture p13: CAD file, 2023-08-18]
CAD/ButtonExtension.FCStd
5.00 x 5.00 x 17.0 mm

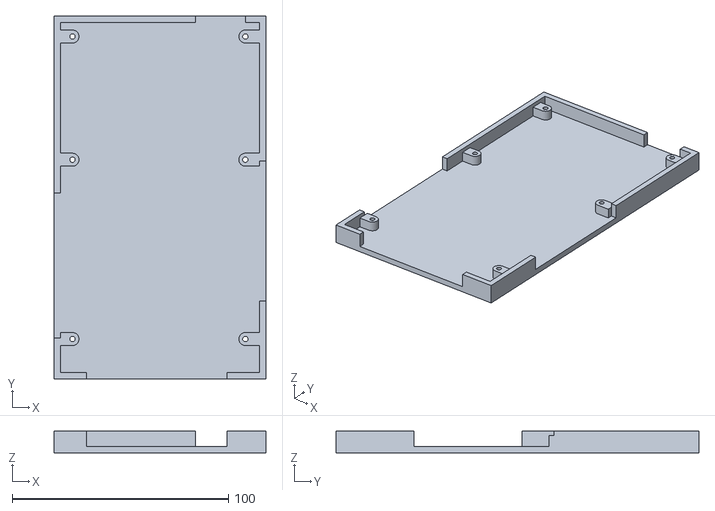
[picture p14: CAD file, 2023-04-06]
CAD/BottomCase-BottomCaseBody.stl
98.0 x 168.0 x 10.0

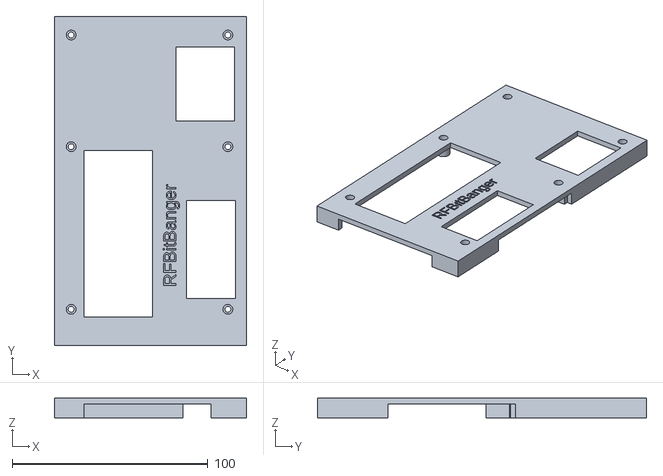
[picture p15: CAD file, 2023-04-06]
CAD/TopCase-TopCaseBody.stl
98.0 x 168.0 x 10.0

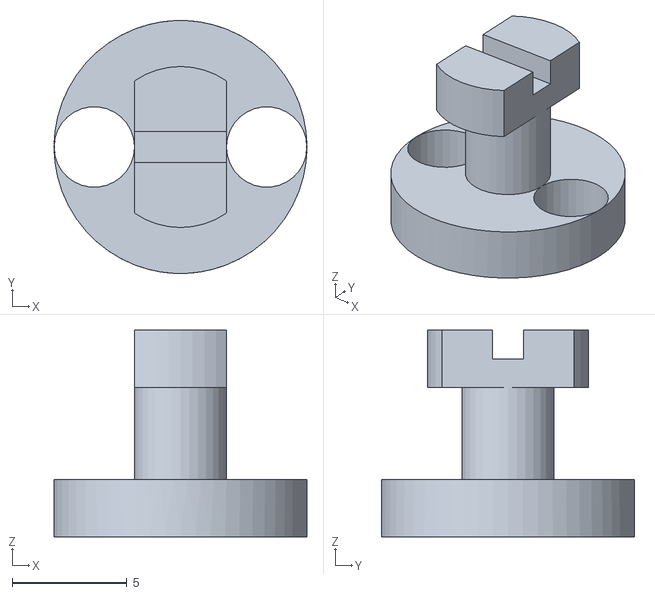
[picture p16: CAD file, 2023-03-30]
CAD/InductorBobbin-BobbinT-180nH.stl
11.0 x 11.0 x 9.00

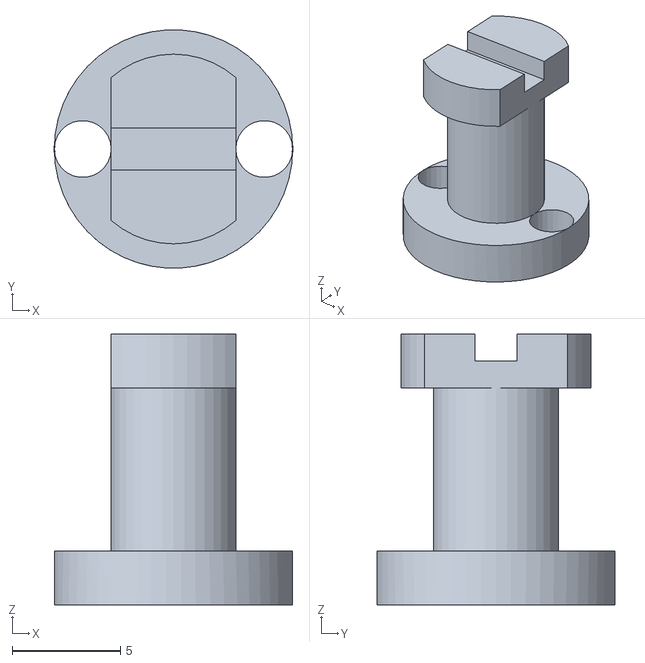
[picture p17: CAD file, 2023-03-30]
CAD/InductorBobbin-BobbinT-750 nH.stl
11.0 x 11.0 x 12.5

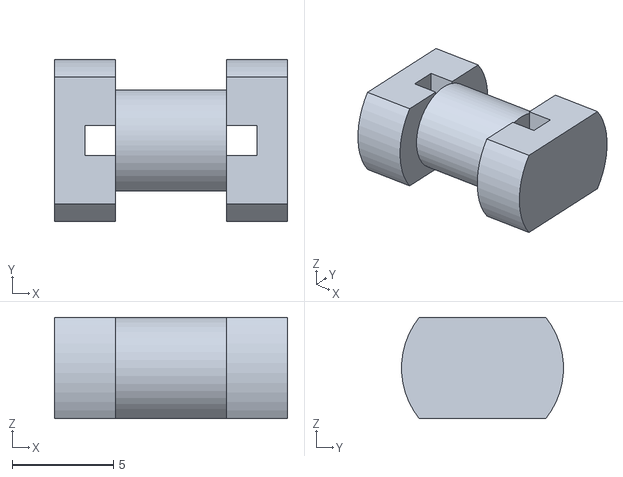
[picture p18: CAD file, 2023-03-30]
CAD/AxialInductorBobbin-AxialBobbinT-360 nH.stl
11.5 x 7.98 x 5.00

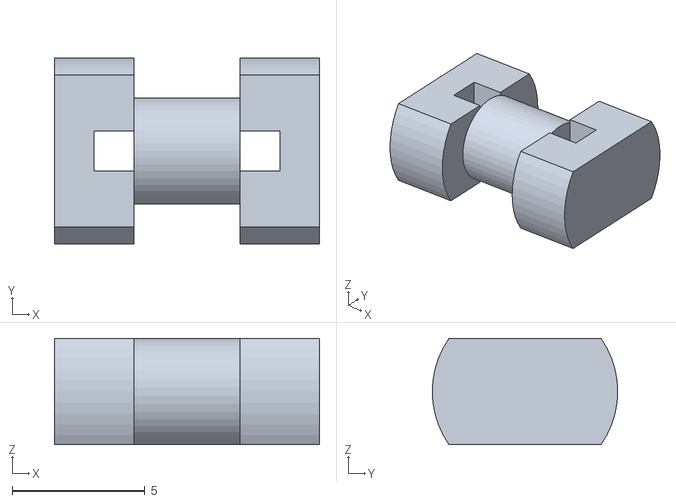
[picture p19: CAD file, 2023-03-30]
CAD/AxialInductorBobbin-AxialBobbinT-180 nH.stl
10.0 x 7.00 x 4.00

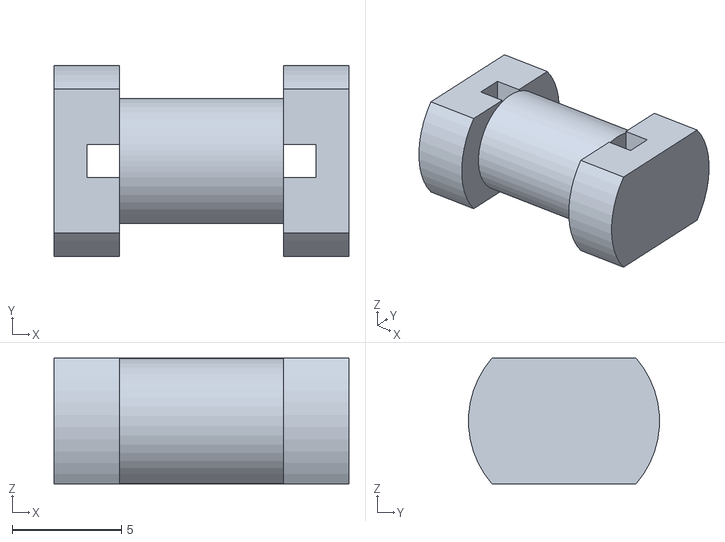
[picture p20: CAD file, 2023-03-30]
CAD/AxialInductorBobbin-AxialBobbinT-750 nH.stl
13.5 x 8.73 x 5.75

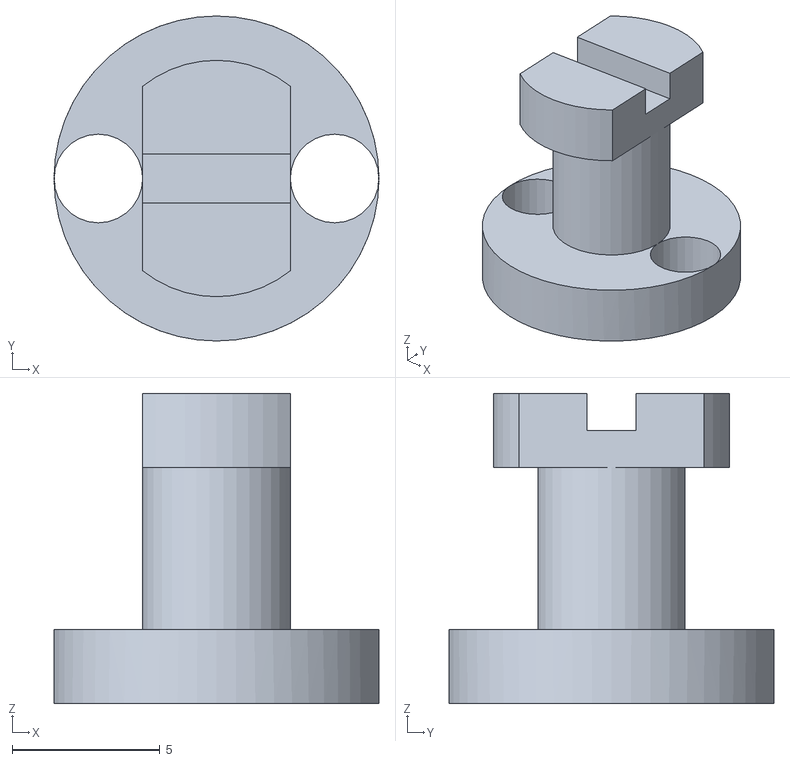
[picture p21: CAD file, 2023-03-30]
CAD/InductorBobbin-BobbinT-360nH.stl
11.0 x 11.0 x 10.5

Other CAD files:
CAD/BottomCase-SMT.FCStd
CAD/ButtonExtension-ButtonBody.stl
CAD/TopCase-SMT.FCStd
CAD/TopCase.FCStd
CAD/BottomCase.FCStd
CAD/InductorBobbin.FCStd
CAD/AxialInductorBobbin.FCStd
CAD/PaddlesKey-PaddlesKeyBody.stl
CAD/PaddlesKey.FCStd
CAD/PaddlesKeyGroundCenter-PaddlesKeyBody.stl
CAD/PaddlesKeyGroundCenter.FCStd

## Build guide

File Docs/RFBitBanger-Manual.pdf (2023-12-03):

# RFBitBanger Manual

# by Daniel Marks, KW4TI

2023-Oct-15, document version 0.7
NOTE: If you intend to be able to use the RFBitBanger without a computer available to view this document, print out these instructions and keep them with your radio.
Make a note of the calibrated crystal frequencies here in case the nonvolatile memory of the radio is corrupted. This can be found in the “Xtal Freq” under the “Cfg” menu. This frequency is usually close to 25 MHz.

## Radio Serial Number Crystal Frequency (Hz)

NOTE: The operator of the radio is responsible for compliance with all applicable telecommunications regulations, especially those regarding operating high frequency transmitters. An amateur radio license is generally required to be permitted to transmit with this radio in most countries.

1

## Introduction

The RFBitBanger is a self-contained high frequency long-distance two-way transceiver radio (frequencies 1.8 MHz to 30 MHz). It is designed to be easy to build, easy to maintain, easy to operate, and able to communicate hundreds or thousands of kilometers with low levels of RF power. It can be built without any surface mount parts. It is constructed from the minimum number of specialized parts so that replacement parts can be located more easily. The design of this radio prioritizes robustness and maintainability over efficiency. Parts have been selected on the basis of high availability and low cost when performance is not significantly compromised. The radio has many features included intended to make long-distance contacts easier to conduct.
The RFBitBanger is intended to be self-contained so that only the transceiver itself is needed to communicate alphanumeric messages long distances. The radio specializes in text-based transactions, through CW, RTTY, or a new protocol created for this radio called SCAMP which uses forward error correction to achieve more reliable transmission. It provides keyboard input to make control easier, but the transceiver can be operated from just five buttons. The radio can also be controlled remotely using a sound card, so that FSK modes, for example, FT8 may also be used. Therefore it is hoped that this can be used for ordinary contacts, but also be usable and maintainable should there we widespread supply chain or communications disruptions. This radio receives dual sideband DSB and can transmit voice (phono) upper or lower sideband (USB/LSB) using a frequency tracking/PLL and envelope modulation method.
This radio is intended to be able to be assembled and maintained off the grid without access to parts suppliers. The parts should be sufficiently inexpensive so that many replacement parts can be kept on hand. Where possible, there should be multiple vendors that can provide similarly working parts. For example, the ATMEGA328P is used in the transceiver which is one of the most common microcontrollers available as it is used in the Arduino Uno and Nano, and furthermore Logic Green has a part that is designed to be a near drop-in replacement. The SI5351A is used as a frequency synthesizer, which is readily available in the form of a prototyping board, and there is also a work-alike MS5351 part. LM358 and LM386 are used which are produced by many manufacturers. A diode ring mixer is constructed from 1N4148 diodes which are some of the most commonly available diodes. The 2N7000 is used as an RF MOSFET, which is very similar to the BS170 except for the 2N7000 having a pinout of source-gate-drain, and the BS170 having the opposite pinout drain-gate-source. The
MOSFET is the most likely part to be damaged. At the time of this writing 2N7000 transistors can be bought for approximately $0.03 each USD in quantity 100. The HD44780-type displays are probably the most common LCDs available.

2

The radio is first and foremost intended to be used with low-bandwidth modes such as CW and RTTY. A new protocol called SCAMP was created especially for this radio. SCAMP is designed to be simple enough to be implemented on an 8-bit microcontroller but incorporates features such as forward error correction. It has several modes which can be selected based on desired symbol rate and receiving conditions, and user selectable levels of redundancy which can be increased to compensate for poor receiving conditions. This protocol is both described in a standards document and has an open source implementation included with the RFBitBanger.

## Features and specifications

The RFBitBanger has the following features and specifications:
- Supports the high frequency (HF) band between 1.8 and 30 MHz, with the best performance obtained at the 80m, 60m, 40m, 30m, and 20m bands (3.5 to 14.35 MHz).
- Uses a simple direct conversion receiver architecture with demodulation using a double sideband (DSB) balanced ring mixer. This does not require any specialized integrated circuits, only 1N4148 diodes and 2N3904 NPN transistors.
- Achieves 4 W or greater radiated power on the 80 to 20 m bands.
- Supports CW (Morse code) transmission and reception, with a built-in decoder.
- Supports RTTY (radio teletype) transmission and reception.
- Supports a new protocol called SCAMP for teletype-like communication that is narrow bandwidth and uses forward error correction.
- Supports upper sideband (USB) or lower sideband (LSB) voice/phono communication using a frequency tracking/PLL and envelope modulation method.
- Has an external control mode which can be used with the audio card of a PC for FSK data protocols, for example FT8.
- Supports replaceable bandpass modules for each frequency band.
- All functions can be controlled with five buttons, even alphanumeric message entry.
- Supports an external PS/2 keyboard for easier message entry.
- Signal strength bar graph to aid in tuning.
- Has an external speaker for listening to audio and data signals.
- Volume and gain control potentiometers.

3

- External microphone, line out, and keyer jacks.
- A jumper can be pulled to support full break-in QSK.

## Radio Ports

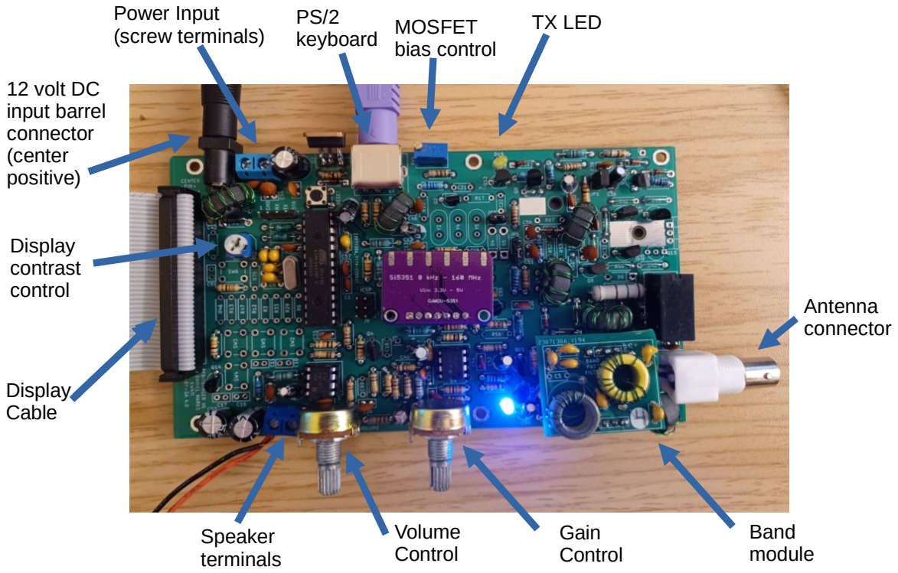
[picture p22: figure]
Display Cable; Display contrast control; Power Input; (screw terminals); MOSFET; bias control; PS/2 keyboard; TX LED; Speaker terminals; Antenna connector; Band module; Gain Control; Volume Control; 12 volt DC input barrel connector (center positive)
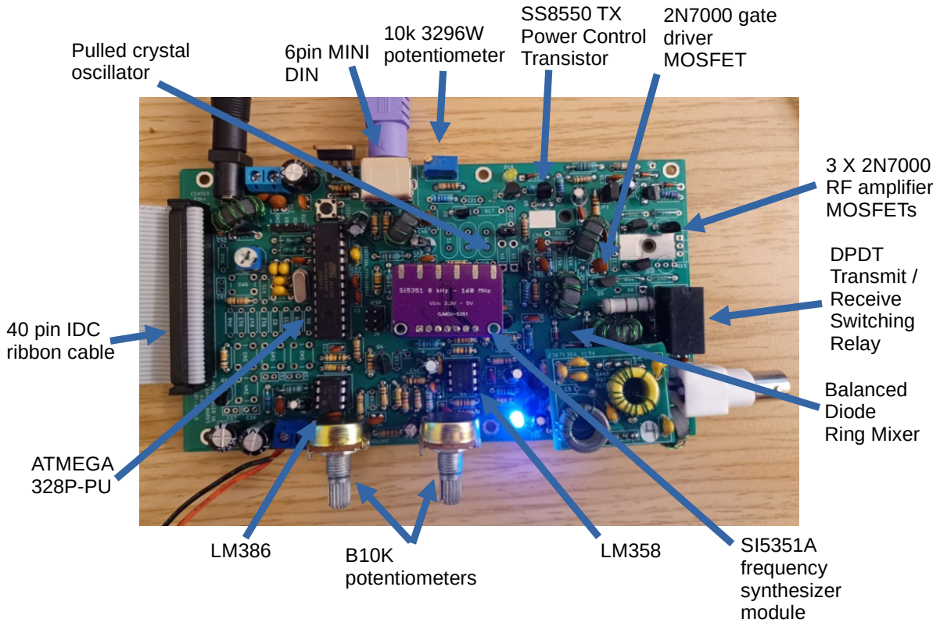
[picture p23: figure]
ATMEGA 328P-PU; 10k 3296W 6pin MINI potentiometer DIN; Pulled crystal oscillator; DPDT Transmit / Receive Switching Relay; SI5351A frequency synthesizer module; potentiometers; SS8550 TX Power Control Transistor; 3 X 2N7000 RF amplifier MOSFETs; Balanced Diode Ring Mixer; 40 pin IDC ribbon cable; 2N7000 gate driver MOSFET

4

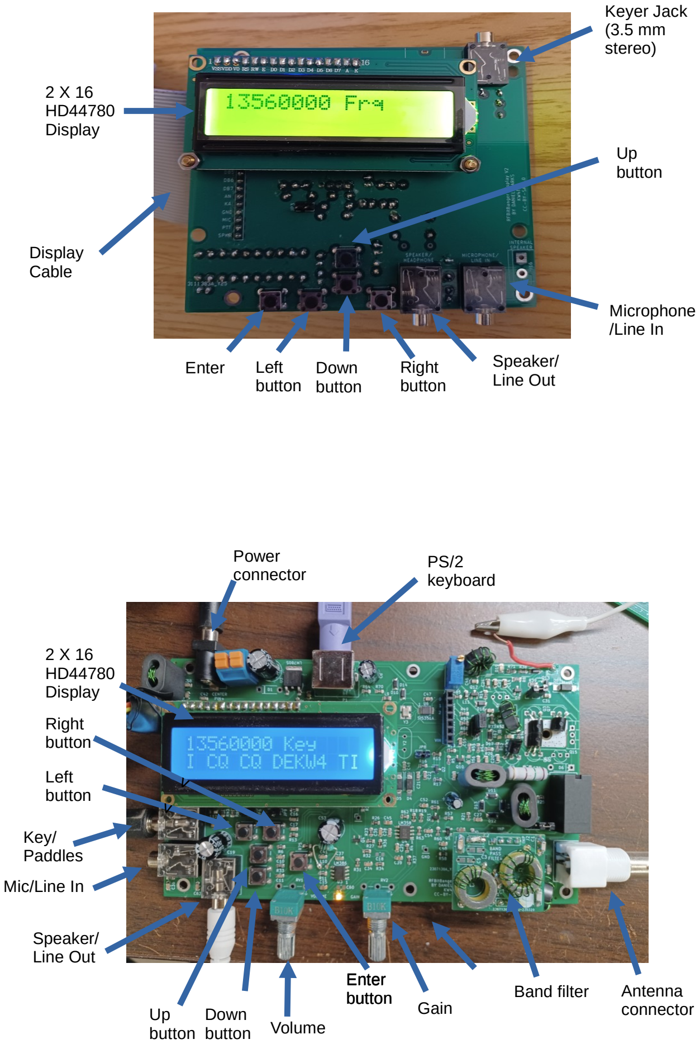
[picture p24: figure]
Display Cable; Microphone /Line In; 2 X 16 HD44780 Display; Keyer Jack (3.5 mm stereo); Down button; Speaker/ Line Out; Enter; Left; button; Right button; Up button; Antenna connector; Key/ Paddles; Enter button; Power connector; Left button; Gain; Volume; Mic/Line In; Band filter; PS/2 keyboard

5

## Before operating the transceiver

Check the following before operating the transceiver:
- For the through-hole version of the RFBitBanger, check that the main transceiver PCB and the display PCB are connected using a 40-pin IDC ribbon cable.
- A 12V to 14.6V DC power supply is connected to the barrel jack or screw terminals. The center pin of the barrel jack is positive.
- Connect an antenna for a particular frequency band to the antenna connector. This antenna may operate only on a single band, or may be designed to operate on multiple bands.
- Insert a bandpass module, which has dual 4 pin sockets, onto the dual 4-pin connectors. One of the pin sockets and pins is silkscreened “INP,” and the other of the pin sockets is silkscreened “OUT.” Plug the 4 pin socket on the band module marked “INP” to the 4 pin port on the transceiver marked “INP.” Similarly, plug the 4 pin socket on the band module marked “OUT” to the 4 pin port on the transceiver marked “OUT.” Check to make sure that both are firmly secured and are not offset by a pin.
- Ensure the bandpass module is appropriate to the frequencies being used. Consult the bandpass module table to determine which band module is indicated for each set of frequencies. A white spot on the band module silkscreen is reserved so that a number indicating the identity of the band module can be written on it.
- A PS/2 keyboard may be connected to the mini 6 pin DIN connector if used.
- If operating using a sound card, connect 3.5 mm stereo patch cables, one from the SPEAKER/HEADPHONE output of the transceiver to the microphone input of the sound card, and a second from the MICROPHONE/LINE IN of the transceiver to the line output of the sound card. Jumpers JP6/JP9 on the SMT version and jumpers JP3/JP4 on the RFBitBanger display board should be closed if a microphone input is used, and left open if line-level input is used.
- If using a key, connect it to the keyer jack. If using a push-to-talk (PTT) button, this can be connected to the keyer jack. The “dit” paddle of a keyer or a straight key may be used as the PTT button. The dah paddle should not be pressed when input audio is present.

6

## Bandpass module frequency ranges

Bandpass module / number | Frequencies (Hz)
160 m / “16” | 1800000 – 2000000
80 m / “8” | 3500000 – 4000000
60 m / “6” | 5250000 – 5450000
40 m / “4” | 7000000 – 7300000
30 m / “3” | 10000000 – 10150000
20 m / “2” | 14000000 – 14350000
17 m / “17” | 18068000 – 18168000
15 m / “15” | 21000000 – 21450000
12 m / “12” | 24890000 – 24990000
10 m / “10” | 28000000 – 29700000

7

## Gain, volume, and sensitivity

The RFBitBanger has two potentiometer controls for adjusting reception: gain and volume. The gain control determines the amount of amplification of a demodulated radio frequency before it is decoded by digital processing or amplified for the audio speaker. When adjusting the gain so that a signal can be decoded off of the air, there is a bar graph on the upper right hand corner of the display. Increasing the gain (turning the knob clockwise) increases the magnitude of the signal as shown on the bar graph. It also increases the loudness of the sound in the speaker or headphones. There are four bar positions of the bar graph. The ideal setting of the gain is such that the magnitude of the bar graph barely reaches the fourth bar. If the gain is too high, the noise is overly amplified and reduces the ability of the noise to be distinguished from the signal. If the gain is too low, the signal is insufficient to be decoded. If there is strong interference near the decoded signal, decreasing the gain may help the digital processing reject the interference while keeping enough of the desired signal to decode.
The maximum gain is over 120 dB (amplifying 1 uV to 1 V) to ensure that the sensitivity of the receiver is limited only by the noise in the receiver and not the gain. However, at the highest gain and volume settings, one will notice some microphonic noise, especially with no antenna connected, when buttons are pressed in the speaker as even tiny vibrations of circuit board components are amplified to produce an audible signal. This is normal and generally does not prevent successful decoding of signals.
The volume does not affect the signal being decoded by the digital processing, only the loudness of the sound in the speaker or headphones. Therefore the gain should be adjusted for the most accurate digital processing (signal level in the bar graph), and the volume adjusted for the desired loudness. The loudness control is generally set to a much higher setting for an external speaker than headphones. When connecting the speaker output to a computer line-in, the volume should be set at a low level as to not exceed the limits of the analog-to-digital converter.
The RFBitBanger is a direct conversion receiver with a VFO generated by a fractional phase-locked-loop integrated circuit (SI5351A) or a crystal oscillator. A fractional phase-locked-loop integrated circuit generates many spurious frequencies internally in the process of synthesizing an output frequency. Because of the high sensitivity of the RFBitBanger receiver, and the fact that it is a direct conversion receiver, these frequencies can be detected by the receiver and unfortunately interfere with a desired signal. This is an unfortunate disadvantage of a PLL synthesizer and the simple direct conversion architecture used. These frequencies tend to be confined to 1-10 Hz bandwidths and so can be worked around by tuning the frequency slightly.

8

## Operating the menu system

The user interface consists of an alphanumeric LCD and five buttons, the buttons being up, down, left, right, and enter. The transceiver can be completely controlled using only these give buttons: menus of the transceiver may be navigated, and numbers and messages may be entered using these buttons. If a PS/2 keyboard is connected, the four arrow keys of the PS/2 keyboard act as the left/right/up/down buttons, and the enter key on the keyboard acts as the enter key on the transceiver. Numbers and alphanumeric messages can be entered using the keyboard as well. For example, the frequency may be changed in the “Frq” menu option using either the numeric keys or the arrow keys.
To navigate a menu, the up/down buttons are used, and to select a menu option, the left/right buttons or the enter buttons are pressed.

## The radio main menu:

The 2 by 16 LCD display is divided into several areas:

In the main menu, the current frequency is displayed at the upper left. The current menu option is displayed next to it (for example “Frq”), and to the right of that is a signal strength bar indicating the signal strength of the signal being decoded in the current mode.
The bottom line is reserved for decoded text. For example, if “CW” transmission mode is selected, when CW is decoded, the message scrolls across the bottom line of the display.
When entering an alphanumeric message, the top line is replaced by the message being entered. Pressing the up/down buttons cycles through the various main menu options, with three letters indicating the option being displayed in the top line. An option can be selected by pressing the left or right button, or the enter button.

## Changing the frequency

To change the VFO frequency, select the “Frq” option. If the left button is pressed, the cursor is placed on the rightmost (least significant) digit. If the right button or enter button is pressed, the cursor is placed on the leftmost (most significant) digit.

9

07000000 Frq||||
CQ CQ DE KW4TI

07000000 Frq||||
CQ CQ DE KW4TI

Pressing the up/down button on a digit increments or decrements that digit by one. The frequency is immediately changed, and the demodulated audio can be heard in the speaker.
When tuning the frequency for best reception of a data mode, the signal strength bar can be used. For on-off keying modes, such as CW, the signal strength bar pulses with the transmission. Tune the frequency for the maximum bar length when the signal is received. For frequency-shift keying modes, such as RTTY or SCAMP, tune the signal strength bar so that the bar is as long as possible, and the bar is on constantly. The frequency-shift keying mode consists of two tones, and if the signal strength indicates a strong signal when only one of the two tones occurs, the frequency is only aligned with one of the two tones, and should be changed by a small amount (less than 250 Hz) so that both tones cause the signal strength bar to remain at a high level. For very low data rate modes, often 1 to 10 Hz increment adjustments may be necessary to maximize the signal.
The buttons are used in lieu of a rotary encoder to change frequency as replacements for buttons may be more readily improvised than a replacement rotary encoder.

## Scanning for a signal

The RFBitBanger can automatically scan for a signal with high signal strength. The “ScF” option scans for a signal “fast” or with 100 Hz scan increments, while the “ScS” option scans for a signal “slow” with 30 Hz scan increments. Select the “ScF” or “ScS” option with the up/down buttons. Pressing the right button scans with increasing frequency starting at the current frequency, while pressing the left button scans with decreasing frequency starting at the current frequency. Pressing the enter button aborts scanning.
The RFBitBanger will step in a 100 or 30 Hz increments until it finds a high strength signal. It will then back up and scan back over the last 300 Hz of bandwidth with smaller 10 Hz steps to maximize the signal strength. The RFBitBanger stops once it maximizes the signal. If the signal is not found when backing up, three attempts are made are finding the signal, and if this fails, the scanning is resumed to look for a new strong signal.

## Selecting a transmission mode

10

07000000 ScF||||
CQ CQ DE KW4TI
CW | TrM|||| CQ CQ DE KW4TI

To select the transmission mode, the “TrM” menu option may be selected. The transmission mode can then be selected using the left and right buttons, with the enter button selecting a transmission mode. As of the time of writing, these are the available modes:
- CW continuous wave (Morse code) with the BFO 667 Hz below the transmitted frequency (USB).
- USB. Upper sideband voice (phono) transmission.
- LSB. Lower sideband voice (phono) transmission.
- RTTY, or radioteletype 45/170, that is 45.45 symbols per second with a 170 Hz separation between mark and space frequencies, with the space frequency 583 Hz above the VFO, and the mark frequency 750 Hz above the VFO.
- RTTYREV, or radioteletype 45/170 on the lower sideband, with the space frequency 750 Hz below the VFO, and the mark frequency 583 Hz below the VFO.
- SCAMPFSK, the standard SCAMP FSK mode. Use this mode by default for SCAMP communications. See the SCAMP protocol description document for more details (26 bits/s).
- SCAMPOOK, the standard SCAMP OOK mode (26 bits/s).
- SCFSKFST the higher symbol rate FSK SCAMP (83 bits/s).
- SCFSKSLW the slow symbol rate FSK SCAMP (14 bits/s).
- SCOOKSLW the slow symbol rate OOK SCAMP (14 bits/s).
- SCFSKVSL the very slow symbol rate FSK SCAMP (7 bits/s).
Generally the slower the symbol rate, the high the signal-to-noise ratio and the lower the communications error rate.
If a new mode is selected, the “Mode Set” message appears briefly.
Because USB/LSB uses audio input rather than key/paddle or text input, transmission is activated differently. Rather than using the “Key” or “Tx” modes, the push-to-talk (PTT) button is pressed, and one speaks into a microphone plugged into the MIC/Line In jack, and the transmitter is automatically keyed. The PTT input is the same as the “dit” paddle/straight key input. One will not receive a band-change warning in this instance. For sufficient amplification of the audio signal, the gain jumpers (JP6/JP9 on SMT board or JP3/JP4 on display board) should be placed on the microphone audio circuit. While one is transmitting, the signal strength bar shows the magnitude of the audio signal. Speak so that it fills the entire range of the bar, but only briefly peaks at the end of the range rather than spending most of its time peaked, so that the audio is not overmodulated.

11

## Reviewing the receive buffer

To review the received decoded message buffer, the “Rxv” option may be selected. If the option is selected with the enter or right button, the leftmost edge of the buffer is shown. If the option is selected with the left button, the rightmost edge of the buffer is shown. The left/right buttons may be used to move through the receive buffer to show its entire contents across the bottom line of the display. New decodes are added to the message buffer when received. Press the enter button to leave the review mode.

## Transmit message mode

To enter and transmit a message, select the “Tx” option. If the right or enter button is pressed, the cursor is placed at the left edge of the transmit buffer. If the left button is pressed, the cursor is placed at the right edge of the transmit buffer. Any previous message remains in the transmit buffer until it is deliberately cleared or power is lost. To enter a character, the up and down buttons may be used to scroll through the available characters with which a message may be composed at the current cursor position. The left or right buttons may be used to change the cursor position. If a PS/2 keyboard is present, this may be used to enter a message.
When one has finished composing the message, the enter button can be pressed. The top line then contains transmit options, which may be viewed using the up and down buttons, and selected with the enter button. The options are:
- Return: return to message composition.
- Txmit: transmit the message immediately. As the message is transmitted, the outgoing message is scrolled across the display, with the cursor indicating the current symbol being transmitted. Pressing enter again aborts the transmission.
- Quit: leave the transmit message mode back to the main menu. The contents of the transmit message buffer are preserved.
- Clear: clear the contents of the transmit buffer and re-enter the transmit buffer compose mode, with the cursor at the left edge of the buffer.

12

07000000 Rxv||||
OLD MESSAGE CQCQ

_
CQ CQ DE KW4TI

## Band change warning

If one attempts to transmit at a frequency that does not correspond to an amateur frequency band, the following message is displayed when entering transmit, keying, and external control modes:

For example, this is an ISM band frequency (13.56 MHz), which is not a valid amateur radio band frequency, and so the RFBitBanger reminds the operator that this is not a valid frequency.
If one attempts to transmit in a known band, but this band is different than the last band in which the radio transmitted, the following message is displayed:

For example, if the last transmission was in the 40 meter band, perhaps 7.074 MHz, and a transmit is attempted in the 20 meter band, at 14.074 MHz, this message is displayed.
When these messages are displayed, the right button may be pressed to proceed, or the left button may be pressed to return to the main menu.
When one attempts to transmit with the radio the first time after powering on, the “Chg band module” message is displayed to remind the operator to check to see if the installed band module is appropriate for the transmit frequency.
The “Band Warn Off” under the configuration “Cfg” may be set to 1 to eliminate this warning. However, having the wrong band module inserted when transmitting may cause damage to the output RF transistors, so it is wise to keep the warning turned on so that one is reminded to change the band module any time the transmit band is changed.

## Keying Mode

Keying mode may be entered by selecting the “Key” option. “Keying Mode” is briefly displayed when entering this mode. To exit this mode, press the enter button, and “Keying Exit” is briefly displayed. The CW transmission mode is automatically selected when entering the keying mode. In this mode, one can use an external key or the buttons to send CW. Either a straight key may be used, in which case the tip of the connector is the key, or an iambic key is supported, with the tip being the dit and the ring being the dah. The CW WPM should be configured if iambic key is used to control the lengths of

13

13560000 Tx ||||
Unknown band

14074000 Tx ||||
Chg band module

07000000 Key||||
CQ CQ DE KW4TI the dits, dahs, and interelement pauses. The down button can be used to key the transmitter in straight key mode. The transmitted signal at the shown VFO frequency and the BFO frequency is 667 Hz below the VFO frequency. Incoming CW transmissions are decoded with the built-in CW decoder if these fall within the receive filter centered at the VFO frequency. Outgoing transmissions are also decoded.
If the “CW Practice” option in the configuration “Cfg” menu is set to 1, the transceiver does not transmit when in the keying mode and decodes the keyed input, so that one can practice keying with the built-in radio CW decoder.

## External Control Mode

External control mode may be used to operate the transceiver using a sound card with FSK modes. This would be commonly used for FT8 and other modes of WSJTX. Digital mode software should be configured for VOX rig control as the presence of a tone is used to key the transmitter. Before entering the external control mode, the frequency should be set to the VFO frequency assuming upper sideband modulation (for example 7.074 MHz for FT8 in the 40 m band). Select the external control mode and press the enter button, and the “Ext Mode” message is displayed briefly. Tones received in the microphone input port prompt the transmitter to key up and transmit the tone at an offset from the VFO frequency. The received audio is transmitted through the speaker/headphone jack. The volume and gain should be set at a moderate level so that the software can decode the signal. Pressing the enter button leaves the external control mode, with the message “Ext Exit” being displayed briefly.

## Configuration Mode

The configuration mode brings up a menu of items that can be changed to customize the radio’s operation and calibrate the crystal frequency. Each item is a number that may be changed by using the left and right buttons to select a digit, up and down buttons to change the digit, and the enter button to accept the change. The options are:
- Quit: return to the main menu.
- Save Conf: save the configuration in EEPROM to be restored on power-up.

14

07074000 Ext||||

CW WPM
20

- Calib Xtal Src: calibrate the crystal frequency by tuning to an external transmission (see procedure).
- Wide Filters: 0 for narrowband standard filters for CW and RTTY decode, 1 for wide filters.
- Backlight: backlight off (0) or on (1).
- CW WPM: send speed for CW in words per minute.
- SSB Gain: a number from 0-31 indicating the gain of the audio signal.
- SCAMP Resync: how often a resync signal should be sent during a SCAMP transmission. Zero means only send at the beginning of a transmission. A nonzero number indicates a sync to be resent again after the number of frames have been transmitted. More frequent resync transmissions prevents desynchronization at the receiver.
- SCAMP Repeat: how many times each SCAMP frame should be repeated. The default is one, which means each frame should be sent only once, but it can be increased to try and ensure the message gets through.
- RTTY Repeat: how many times letters and figures codes should be repeated. The default is one, but more repeats can help the receiver be more resistant to selecting the wrong character set.
- RIT Shift Freq: The RIT (Receiver Incremental Tuning) frequency is an offset that the receiving frequency should be from the transmitting frequency. Normally this is zero, so that a transmitted and received signal occur at the same frequency. By specifying a nonzero RIT shift frequency, the receive frequency may be above or below the transmit frequency.
- RIT Dir 0+ 1-: This specifies the direction of the frequency shift for RIT. 0 means that the receive frequency is higher than the transmit frequency by the shift frequency, 1 means the receive frequency is lower than the transmit frequency by the shift frequency.
- Sidetone Freq: frequency in Hz that should be sounded over the speaker (not over the transmission) when a dit or dah is transmitted.
- Sidetone On: whether or not a sound should occur over the speaker when a dit or dah is transmitted. 0 is no sidetone, 1 adds sidetone.
- Ext Fast Mode: set to one for a faster but less accurate way to measure external tone frequency in external control mode which is useful for faster FSK modes. Generally set this to zero for WSJTX.
- Ext LSB: directs the external control mode to transmit on the lower side band (=1) rather than the upper side band (=0). Generally leave this zero.

15

- CW Iambic: Iambic paddle mode (1) or straight key mode (0).
- CW Iambic Type: Iambic mode B (1) or iambic mode A (0).
- Iambic switch: swap the dit and dah paddles (1) or do not swap (0).
- CW Practice: if this equals one, then the radio does not transmit in Keyer mode and decodes the keyed input.
- CW Mark->Spaces: Determine the spaces timing from the marks timing when decoding CW, rather than determining these independently.
- CW Smooth: Smooth the received amplitude envelope when decoding CW, which is helpful when decoding slow CW in heavy noise. It is recommended to use smooth or sticky interval at a given time, but not both.
- CW Sticky Interval: Increase/decrease the amount of time before a change in or mark or space is registered when decoding CW. It is recommended to use smooth or sticky interval at a given time, but not both. A longer sticky interval (6 to 9) is useful for slower CW receive speeds with noisy conditions.
- Band Warn Off: If this equals one, disable band change warnings. If this equals zero, display a band change warning when first transmitting on startup, and also when transmitting on a different band than before.
- Erase on send: erase the outgoing message buffer after sending the message (1), or keep the outgoing message buffer and it must be manually erased (0).
- Xtal Freq: the frequency of the crystal on the SI5351A oscillator. It can be calibrated using a frequency counter by setting the Xtal Freq to 25000000 Hz, setting the VFO frequency to 25000000 Hz, and then measuring the frequency on jumper JP5 with the frequency counter. This frequency can then be entered as the Xtal Freq. If the crystal calibration becomes corrupted, changing the Xtal Freq back to 25000000 Hz can be useful as a default calibration.

## Calibrating the crystal oscillator frequency with a source on the air

The crystal in the radio can be calibrated using a broadcasted frequency standard such as WWV at 10 MHz. Here is the procedure for doing so:

1. Turn on the radio and wait 15 minutes or so for the crystal to reach an equilibrium temperature.

16

2. Set the transmission mode to CW.
3. Set the VFO frequency (in the Frq menu option) to the nominal calibration frequency, for example, for WWV at 10 MHz, set the VFO to 10000000.
4. Tune the VFO frequency down until the signal strength bar indicates a maximum amplitude. One should be able to get the signal strength to vary on a scale of +/- 10 Hz. Make sure the calibration signal is in the upper sideband (the BFO frequency is below the calibration frequency). If one increases the VFO frequency, the beat frequency tone should lower in pitch, and if one decreases the VFO frequency, the beat frequency tone should raise in pitch, if the calibration frequency is above the BFO frequency. If it is reversed, decrease the VFO frequency by approximately 1300 Hz and tune again for maximum amplitude.
5. Once the signal strength bar is maximized in amplitude, enter the “Cfg” menu option and the “Calib Xtal Src.”
6. Use the buttons to enter the actual nominal frequency. The frequency should already be filled in with a value close to the actual nominal frequency. For example, if the broadcasted frequency is 10 MHz, enter 10000000 and press the enter button.
7. The radio performs an adjustment of the crystal frequency. Save the data to EEPROM memory and turn the radio off and on to have the calibration take effect.
8. Select the “Xtal Freq” in the “Cfg” menu. This should show the calibrated crystal frequency.
9. Set the radio to CW mode and tune to the actual nominal frequency. The signal strength should now be peaked at the nominal frequency if the procedure is performed properly.
10. Write this frequency on the front page of this document to save it in case the calibration should be erased from the EEPROM memory.

17

## Using the serial port for external control

The serial port of the ATMEGA328P may be used for various functions. It is set up at 2400 baud, 8 bits, 1 stop bit, no parity. A USB-TTL interface such as a FT232R, FT232H, CP2102, or CH340 serial TTL converter may be used to connect to the RFBitBanger for both control of the transceiver and to flash the firmware. The GND pin of the RFBitBanger should be connected to the GND of the serial TTL converter, the RX of the RFBitBanger should be connected to the TX of the serial TTL converter, and the TX of the RFBitBanger should be connected to the RX of the serial TTL converter. The DTR pin of the RFBitBanger should be connected to the DTR pin of the serial TTL converter ONLY when flashing new firmware onto the RFBitBanger.
It is best used with a “split terminal” program with separate areas for inputting data to be sent to the RFBitBanger serial port, and another area to display data received from the RFBitBanger serial port. The Arduino serial terminal is a split terminal. Another split terminal program is ScriptCommunicator ( https://sourceforge.net/projects/scriptcommunicator/ ) which does not require the full Arduino development environment and is available for Windows, Mac OS X, or Linux.
Any text that is decoded by the RFBitBanger is sent to the serial port so that it might be logged by the terminal software. Menu options can be selected through the serial port by either entering a digit (1-9) for menu options 1 to 9, or (A-Z) for menu options 1 to 26 for menus that have more than 9 options. The “!” (exclamation point) character may be sent to abort from a menu, so that sending the “!” multiple times can abort multiple menus to return to the top-level menu.
By selecting the “Tx” menu option and entering message composition mode, text may be sent through the serial port to fill the transmit buffer, and then by sending the carriage return twice, the message is transmitted. This way the serial terminal may be used to enter messages and receive the decoded text. The decoded text received is prefixed by “rx:” and the transmitted text prefixed by “tx:” in the receive window so that it shows a transcript of the communication. The received text is word-wrapped to an 80 character terminal.

18

## Constructing a wire antenna

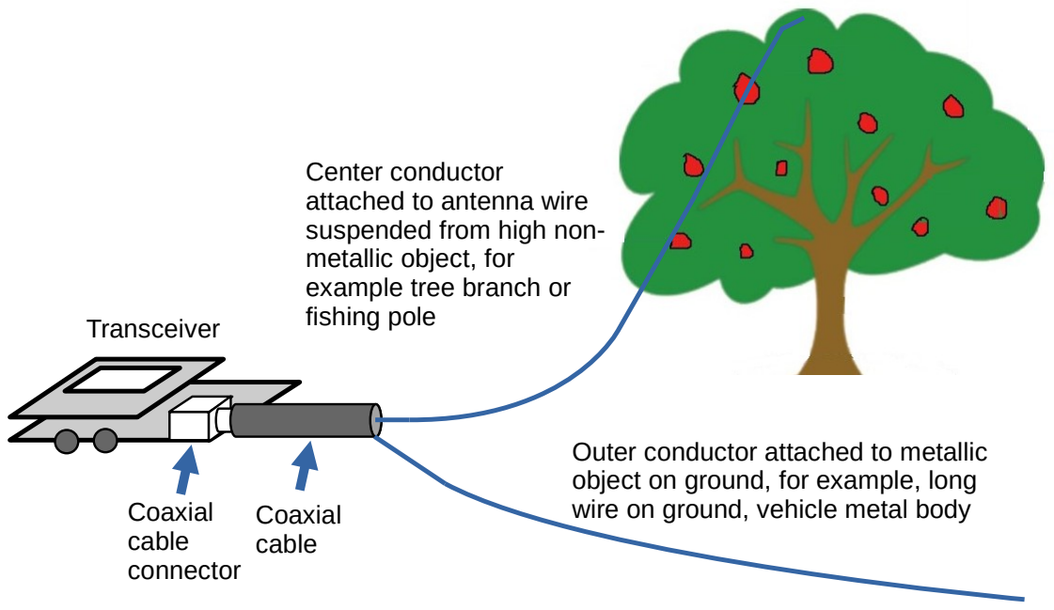
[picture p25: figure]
Transceiver; Center conductor attached to antenna wire suspended from high non- metallic object, for example tree branch or fishing pole; Coaxial cable connector; Coaxial cable; Outer conductor attached to metallic object on ground, for example, long wire on ground, vehicle metal body

A quarter-wavelength wire antenna can be easily constructed for a particular frequency band. The length of an antenna for a frequency band with a given wavelength is 0.235 to 0.24 times the wavelength, so for example, for the 40 meter band, the antenna length would be 9.4 to 9.6 m. If more objects are closer to the antenna, or the antenna element is closer to the ground, the antenna length tends to be shorter. In feet, the antenna length is 0.75 to 0.79 times the band wavelength in meters, so for example, for the 40 meter band, the antenna length is 30 to 31.6 feet long. If you are unsure of how long the antenna should be, start off with the antenna cut long because it is much more difficult to add length to an antenna than to cut off length. The following table shows the range of antenna lengths for the common bands:

Bandpass module / number | Antenna length range (meters) | Antenna length range (feet)
160 m / “16” | 36.8 – 38.4 m | 120.0 – 126.4 ft (120’0” – 126’5”)
80 m / “8” | 18.4 – 19.2 m | 60.0 – 63.2 ft (60’0” - 63’2”)
60 m / “6” | 13.8 – 14.4 m | 45.0 – 47.4 ft (45’0” - 47’5”)

19

40 m / “4” | 9.2 – 9.6 m | 30.0 – 31.6 ft (30’0” – 31’7”)
30 m / “3” | 6.9 – 7.2 m | 22.5 – 23.7 ft (22’6” – 23’8”)
20 m / “2” | 4.6 – 4.8 m | 15.0 – 15.8 ft (15’0” – 15’10”)
17 m / “17” | 3.9 – 4.1 m | 12.7 – 13.5 ft (12’8” – 13’6”)
15 m / “15” | 3.45 – 3.6 m | 11.3 – 11.8 ft (11’4” – 11’10”)
12 m / “12” | 2.75 – 2.9 m | 9.0 – 9.5 ft (9’0” – 9’6”)
10 m / “10” | 2.3 – 2.4 m | 7.5 – 7.9 ft (7’6” - 7’11”)

The antenna system consists of two parts: the wire antenna, which needs to be cut to the correct length and suspended from a high, nonconductive object such as a tree branch, and the ground, which is a large metallic object placed on or near the ground. The ground may be a long wire on the ground, a metal plate or sheet metal shed, a metal vehicle body, a water pipe, or other such improvised metal objects. Do not use pipes containing natural gas or other flammable contents as the ground.
The transceiver has two types of connections for antennas: a coaxial cable connection and a screw terminal connection. The coaxial cable connection is a metallic round connector over which a coaxial cable is connected. The coaxial cable has an inner conductor surrounded by an insulating dielectric, and an outer conductor which surrounds the inner conductor. The inner and outer conductor may be carefully separated so that they are not touching or electrically shorted together by ensuring the insulator between them remains intact. The antenna wire can be attached to the inner conductor by twisting the two wires together, or alternatively soldering or crimping them together. The outer conductor can be twisted with the ground wire, or the ground wire can be tied tightly around the conductor. Keep the wire connecting the outer conductor and the ground object (for example vehicle body) as short as possible, and try to get the end of the antenna wire as high as possible. For example, one might be able to tie the end of the antenna wire to a weight and throw the weight up into a tree. The transceiver may be equipped with screw terminals for the antenna and ground wire connections rather than a coaxial connector. If this is the case, the terminal closer to the corner of the circuit board is the antenna terminal and should be marked “ANT” while the ground terminal is further from the corner of the circuit board and should be marked “GND.” A small screwdriver may be used to loosen the antenna terminal screw and open and widen the gap which holds the wires. One should see the gap widen as one loosens the screw. Insert the end of the wire into the gap and tighten the screw in order to secure it. The gap closes as the screw is tightened, clasping the wire. After the screw is tightened, give the wire a gentle tug to make sure it is being held firmly by the terminal.

20

## Using the built-in RF ammeter

There is a built-in RF ammeter that can be used to optimize the antenna length for maximum power output. This is enabled by removing a shorting jumper from JP2. The red LED D16 glows brighter as the RF current through the antenna port increases. The power and LED brightness is maximized when the length of the antenna is slightly less than one-quarter wavelength at the frequency used as explained in the previous section. Output power can be transmitted briefly by entering Keying mode and using the down button to key up the transmitter. A dummy load such as a 50 ohm, 3 watt resistor may be attached to see how brightly the LED should glow with a matched antenna. A ground should be connected to the radio such as a large metallic object or counterpoise wire. The jumper JP2 should be replaced for normal operation. It is normal for the red LED to glow weakly during normal transmission even with JP2 shorted.
To tune an antenna, start with the antenna wire longer than the expected. Test the antenna by attempting to transmit. Note the level of glowing of the LED, and compare the brightness of glowing to that of the 50 ohm dummy load resistor. Disconnect the antenna wire from the transmitter, shorten it about 5 cm at a time by clipping the end of the wire, reconnect the new end into the transmitter, and transmit again. As the wire is shortened, it should become a more efficient radiator and the LED should gradually get brighter. The antenna may not be able to light up the LED quite as brightly as the dummy load, but the levels should be comparable.

21

## Choosing a frequency band

High frequency radio waves (1.8 MHz to 30 MHz) rely on a number of effects to be able to propagate around the world, and it is beyond the scope of this document to describe these effects. Propagation on a particular frequency band depends on the time of day, season, and current solar activity, among other factors. Some simple rules of thumb may be used to select a frequency band.
The frequency band that is most likely to be available at any time is the 40 m band (7000 to 7300 kHz in Region 2, 7000 to 7200 kHz other regions), and so if the most reliable communication is required, this band should be considered first. It is generally available both during the daytime and at nighttime, with night propagation being slightly better.
During the day, the most likely frequency band that is useful is the 20 m band (14000 to 14350 kHz). This band typically becomes available in the early morning and lasts until dusk. Propagation is most likely on this band between two stations that are both on the daylight side of the planet.
During the night, a useful frequency band is the 80 m band (3500 to 4000 kHz). This band becomes available in early evening and lasts until dawn. During summer months, lightning strikes and thunderstorms can create a significant noise background heard as pops in the receiver. Propagation is most likely on this band between two stations that are both on the nighttime side of the planet.
The 60 m, 30 m, 17 m, and 12 m bands are known as WARC bands and tend to be less frequented, but also less congested, than the main three bands of 20, 40, and 80 m bands.
Each band generally has a “band plan” which indicates which types of transmissions that are favored by amateur radio operators on particular frequency ranges inside the band. A response is more likely if the transmission type conforms to the band plan. Generally, the lowest frequencies of a band are reserved for low bandwidth modes such as CW, RTTY, and low bandwidth data modes, and the higher frequencies tend to be phone/AM/SSB and high bandwidth data modes. For example, CW is most often communicated in CW in the 80 meter band at 3500-3570 kHz, in the 40 meter band at 7000-7070 kHz, and in the 20 meter band at 14000-14070 kHz. These are not hard limits and only guidelines. Because the RFBitBanger specializes in low bandwidth modes, a response is more likely to a call on the lower frequencies on a band as permitted by one’s station license.

22

## International Amateur Radio Union Emergency Communications Frequencies

The following is a table of the frequencies designated by the IARU for emergency communications. This does not include other frequencies that countries designate for emergency communications. Because of message traffic congestion, one may need to connect on a nearby frequency up to 20 kHz from the designated frequency.
Region 1
Europe, Africa, Russia, Middle
East west of the Persian Gulf (kHz)

Region 2
North America, South America, Greenland
(kHz)

Region 3
East Asia, India, Australia, New Zealand, Oceania, Middle East east of the Persian Gulf (kHz)
3760 | 3750 or 3985 | 3600
7110 | 7060, 7240, or 7275 | 7110
14300 | 14300 | 14300
18160 | 18160 | 18160
21360 | 21360 | 21360

The IARU has information about published emergency communications frequencies: https://www.iaru-r1.org/about-us/committees-and-working-groups/emcomm/emergency-communications-frequencies/ (https://www.iaru-r1.org/about-us/committees-and-working-groups/emcomm/emergency-communications-frequencies/)
Write down any emergency frequencies below:

Frequency (kHz) Description

23

## Listening to terrestrial AM broadcasts and shortwave stations with the RFBitBanger

The RFBitBanger may be used to listen to AM (amplitude modulation) stations in the terrestrial broadcast band in the range of 530 to 1700 kHz, however, it is not ideal for doing so. If the radio receiver is tuned to an AM broadcast station, a strong tone is likely to be heard as well as a “warbling” sound. This is because the demodulator of the RFBitBanger uses a mixer, not an envelope detector, as a typical AM broadcast receiver would use. However, if one tunes the receive frequency so that the tone is as low frequency as possible as to be inaudible, so that the receiver frequency is closely aligned with the carrier frequency of the AM station, the tone and warbling effects are minimized and the station can become clearly audible. However, this may require tuning the radio to a frequency accuracy better than 10 Hz.
Similarly, shortwave radio stations that use AM broadcasting can be similarly tuned. The following are common shortwave broadcast bands:
Frequency Range
2.3 – 2.5 MHz | Mostly used locally in tropical regions.
3.2 – 3.4 MHz | Mostly used locally in tropical regions.
3.9 – 4.0 MHz | Mostly used in the Eastern Hemisphere after dark.
4.75 – 4.995 MHz | Mostly used locally in tropical regions.
5.9 – 6.2 MHz | Night-time reception year-round.
7.2 – 7.45 MHz | Good reception at night, 7.2 – 7.3 MHz is in 40 m amateur radio band in ITU
| Region 2.
9.4 – 9.9 MHz | Night-time reception year-round, during the day at various times of the year.
11.6 – 12.1 MHz | Best during the summer and around sunset every season.
13.57 – 13.87 MHz | Used in Europe and Asia, best in summer.
15.1 – 15.83 MHz | Daytime reception is good, nighttime intermittent, best season is summer.
17.48 – 17.9 MHz | Daytime reception is good, nighttime intermittent, best season is summer.

24

## Constructing the RFBitBanger

The RFBitBanger is designed to have options for its construction:
- A SI5351A may be used as the oscillator for the VFO. A SI5351A and crystal may be soldered directly to the PCB, or a SI5351A module may be plugged into the PCB through a seven pin socket.
- A pulled crystal oscillator may also be used as the VFO, which can tune over a narrow bandwidth.
- The RFBitBanger may be constructed to not require the display PCB. The push buttons may be added to the main PCB, or may be added to the display PCB. The HD44780 display itself can be attached to the main PCB or the display PCB. Push buttons should not be soldered onto the main PCB and the display PCB at the same time or both sets of buttons may become inoperable.
- The MOSFETs may either be 2N7000 or BS170 types. 2N7000 types have the order of the leads as source-gate-drain, while BS170 have the order as drain-gate-source, and so BS170s may be used in place of the 2N7000s if these are soldered in the opposite way.
- Transistors Q3, Q5, Q6, Q7, and Q8 may be placed in contact with the PCB so that the PCB can act as a heatsink. Holes in the PCB can be used with appropriate screws, nuts, and washers (4/40 or M3) to put pressure on the transistors against the PCB, and heatsink compound between the transistors and the PCB can also help heat conduction.
- Two different types of potentiometers are supported: B10K-types, and ALPS miniature types, both being 10k in maximum resistance.
- The 100 uH axial RF choke inductors can be wound on small ferrite beads or cores if the axial inductors are not available, as the value of the inductance is not sensitive.

## Schematic indications and footprints

- Resistors and capacitors that are marked as “NC” indicate no connection and should be omitted.
- Resistors that are marked as “0R” mean 0 ohms and may be substituted with a zero ohm resistor or a wire.
- All resistors are ¼ watt through-hole types, except where as indicated.

25

- 10 nF and 100 nF are 2.5 mm lead spacing ceramic disc capacitors, all others are 5 mm lead spacing capacitors, except for a few 10 and 100 nF capacitors that also have 5 mm lead spacing.
- All TO-92 devices use a wide lead spacing for easy mounting and repair.

## Winding and mounting the toroids

- The wire used should be a minimum of 0.5 mm diameter (26 AWG) magnet wire.
- The wire enamel may be removed from the wire by drawing the wire through sandpaper several times with gentle pressure applied. A razor blade may also be used to scrape the enamel off carefully, as the copper wire cuts easily.
- L4 and L6 are RF chokes wound on T37-43 or T50-43. There should be at least 12 turns of 0.5 mm wire on these toroids. These will stand up on the PCB.
- T4 is a bifilar common-mode choke wound on a T37-43 or T50-43 core. Twist two magnet wires together for a total length of approximately 30 cm. Wind them together around the core at least 7 times. Separate the two pairs of wires on each side and use a continuity tester to determine which wire is connected to the other on each side. Keep the two ends of the two wires together on each side; do not swap the ends of the wires. Solder one of the connected wires between the pads marked 1 and 2, and the other connected wire between be pads marked 3 and 4. If the two ends of the two wires are kept together and soldered into pads 1 and 3, and the other two ends of the two wires are soldered into the other two pads 2 and 4, the toroid should stand up freely on the PCB and not be twisted over by the wires. The silkscreening shows the pads that are connected together by wires through the ferrite core.
- T1 and T2 are trifilar (three winding) balun transformers wound on a T37-43 or T50-43 core. Twist three wires together for a total length of approximately 30 cm. Wind them together around the core at least 5 times. Separate the ends of the three wires on each side and use a continuity tester to determine which wire on each side is connected to each wire on the other side. Keep each end of the three wires separated on each side; do not swap the ends of the wires. Solder one of the connected wire between the pads marked 1 and 2, another of the wires between the pads marked 3 and 4, and a last of the three wires between the pads marked 5 and
6. If the three ends of the wires are kept together on one side and soldered in pads 1, 3, and 5, and the other three ends of the wires are kept together on the other side and soldered in the pads market 2, 4, and 6, the toroid should stand up freely on the PCB and not be twisted over by the wires.
- T3 is the current sampling transformer. There are five turns around T3 that connect to the two pads with the undulating line between them. There is a single turn (a wire passing through) the

26 center of the toroid which is soldered between the two pads that are connected by the dotted line.
- The toroids on the band pass filter PCBs are on T37-2 or T50-6 forms. Wind the indicated number of turns through the toroid and solder the toroid down to the PCB through the mounting holes. These lay flat on the PCB.

## Jumpers used on the main PCB

JP1: This is normally shorted, and is removed for full break in QSK.
JP2: This is shorted to take the RF current sample LED out of the circuit, or opened so that the RF sample LED grows brightly with added RF current at the antenna port.
JP4: This may be placed to bypass the output bandpass filter. The transceiver should always be operated with a bandpass filter in order to comply with telecommunications regulations, however, in an emergency, this jumper may be placed to bypass the filter so that a signal may be transmitted.
JP5: This selects either the SI5351A oscillator or the pulled crystal oscillator.
JP8: This should be shorted if the pulled crystal oscillator is not used.
JP6/JP9: SMT only-Closed when a microphone is attached to input, open for line-level audio input.

## Jumpers used on the display PCB (through-hole only)

JP1, JP2: Swap RX/TX to tip/ring of 3.5 mm jack used for a serial connection.
JP3/JP4: Closed when a microphone is attached to input, open for line-level audio input.

## Adjustment potentiometers

RV3: This is used to adjust the contrast on the LCD. If the LCD appears blank or has dark bars on it, adjust this so that the letters appear.
RV4: This is the MOSFET bias adjustment. This should be adjusted so that the bias on the MOSFET gates Q3, Q5, Q6, Q7, Q15 is 2.0 to 2.5 volts. If power consumption is excessive when transmitting,

27 this voltage may be reduced. The voltage on the MOSFET gates can be measured using a voltmeter either at the center lead of Q3, Q5, Q6, or Q7, or at the cathode of diode D17.

## Connecting the main and display PCB

A 40 pin dual female IDC ribbon cable is used to connect the main and display PCB. A short cable can be made by pressing two 40 pin IDC female connectors onto a 40 pin ribbon cable, all of which often can be found from old IDE cables. If the cable is too long, often the connector can be pried off the cable and reclamped at another place.

## Constructing the serial resonant bandpass filters

Each serial resonant bandpass filter is assembled onto a small PCB that plugs into the main PCB in the lower right corner. There are two pin sockets on the filter, the input socket “INP” and the output socket “OUT” which are connected to the same silkscreened sockets on the main PCB. The components used in each filter are denoted in the table below. The capacitors C2 and C3 may be either a single capacitor of the full value, or two capacitors that add up to the total capacitance. The range of capacitance and two common values capacitances that add up to the total capacitance are suggested in the table. Similarly, C5 and C7 may be a single capacitor or two capacitors that add up to the total capacitance shown in the table. There are two inductors L2 and L3. These should be wound onto the toroid types given, for example T50-6 (which is a ½ inch or 50/100” diameter toroid made of type 6 powder iron core material and is a yellow color, or T37-2 (which is a 37/100” diameter toroid made of type 2 powder iron core material and is a red color). For the smallest values of inductance, an air core inductor may be used, which is wound on a 1/4” or 3/8” diameter form. A drill bit is convenient to use as a form. The wire used is 1 mm diameter or 18 AWG so that it more readily holds its shape. The inductance of the air core may be fine tuned by separating the coils to decrease the inductance. Paper may be placed over the form before winding the coil, especially a slippery paper such as wax paper, so that it is easier to slide the coil off of the form after winding.
The capacitors used in the serial resonant bandpass filter should be NP0/C0G which have low loss and a nearly constant capacitance with temperature. The capacitors found in most ceramic capacitor assortment kits are X7R or Y5V type and are unfortunately unsuitable, and so it is likely that NP0/C0G types have to be specially obtained. Unfortunately, through-hole ceramic disc NP0/C0G capacitors have become quite rare and expensive as of the time of this writing. Mica capacitors can also be substituted as well, but may be even harder to obtain. For this reason, 1206-size NP0/C0G surface mount capacitors are recommended to be used. These are relatively inexpensive and large enough to handle so that most people comfortable who can solder ceramic disc capacitors can also solder 1206-size surface mount capacitors. The surface mount capacitors can be held with tweezers or tacked

28 down temporarily with tape so that one terminal of the capacitor is soldered, at which point the temporary support can be removed and the other terminal soldered. The footprints on the serial resonant filter PCB are designed to take either a 1206 surface mount or a ceramic disc through-hole capacitor, and a 0805-size capacitor can be attached as well.
The 4 pin headers should be added last to the serial resonant bandpass PCB as this will make the PCB easier to assemble. These should be inserted into the bottom side of the PCB. There is a white region of the silkscreen on which a number indicating the filter band may be written.

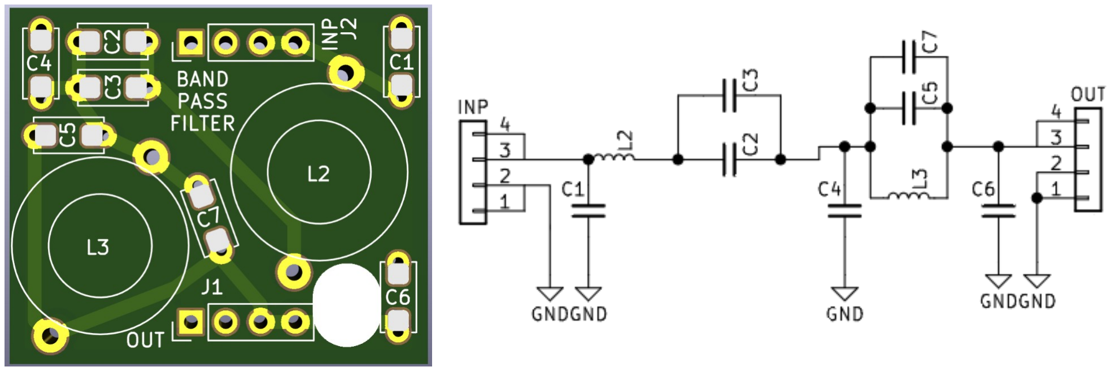
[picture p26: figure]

Under normal circumstances, the transceiver should be operated with the appropriate bandpass filter so that when transmitting, the signal being transmitted complies with telecommunications regulations. However, in an emergency, the JP4 jumper may be closed to bypass the bandpass filter. The resulting radiated signal will be inefficient and rich in harmonics, however, the signal should be able to be received.

## Serial resonant bandpass filters component values

29

Band | C1 | C2+C3 | C4, C6 | C5+C7 | L2 | L3
80 m | 680 pF | 2200 pF | 2200 pF | 680 pF | 1.45 uH T50-6 or T37-2, 19 turns air coil, 1 mm wire, 13-14 turns around 12.5 mm (1/2” drill bit) form | 0.68 uH T50-6 or T37-2, 13 turns air coil, 1 mm wire, 10-11 turns around 9.5 mm (3/8” drill bit) form
60 m | 470 pF | 1500 pF | 1500 pF | 470 pF | 1.05 uH T50-6 or T37-2, 16 turns air coil, 1 mm wire, 10-11 turns around 12.5 mm (1/2” drill bit) form | 0.49 uH T50-6 or T37-2, 8-9 turns air coil, 1 mm wire, 15-16 turns around 9.5 mm (3/8” drill bit) form
40 m | 330 pF | 1000 pF | 1000 pF | 330 pF | 0.77 uH T50-6 or T37-2, 12 turns air coil, 1 mm wire, 12-13 turns around 9.5 mm (3/8” drill bit) form | 0.36 uH T50-6 or T37-2, 8 turns air coil, 1 mm wire, 7-8 turns around 9.5 mm (3/8” drill bit) form
30 m | 220 pF | 680 pF | 680 pF | 220 pF | 0.54 uH T50-6 or T37-2, 11 turns air coil, 1 mm wire, 9-10 turns around 9.5 mm (3/8” drill bit) form | 0.25 uH T50-6 or T37-2, 7 turns air coil, 1 mm wire, 5-6 turns around 9.5 mm (3/8” drill bit) form
20 m | 150 pF | 470 pF | 470 pF | 150 pF | 0.39 uH T50-6, 9 turns, air coil, 1 mm wire, 7-8 turns around 9.5 mm (3/8” drill bit) form | 0.18 uH T50-6, 5 turns air coil, 1 mm wire, 4-5 turns around 9.5 mm (3/8” drill bit) form
17 m | 100 pF | 390 pF | 390 pF | 100 pF | 0.32 uH T50-6, 8 turns air coil, 1 mm wire, 5-6 turns around 9.5 mm (3/8” drill bit) form | 0.14 uH T50-6, 5 turns air coil, 1 mm wire, 5-6 turns around 9.5 mm (3/8” drill bit) form
15 m | 68 pF | 330 pF | 330 pF | 100 pF | 0.26 uH T50-6, 8 turns air coil, 1 mm wire, 5-6 turns around 9.5 mm (3/8” drill bit) form | 0.12 uH T50-6, 5 turns air coil, 1 mm wire, 5-6 turns around 6.25 mm (1/4” drill bit) form
12 m | 47 pF | 330 pF | 330 pF | 100 pF | 0.22 uH T50-6, 7 turns air coil, 1 mm wire, 5-6 turns around 9.5 mm (3/8” drill bit) form | 0.10 uH T50-6, 4 turns air coil, 1 mm wire, 5-6 turns around 6.25 mm (1/4” drill bit) form
10 m | 33 pF | 270 pF | 220 pF | 82 pF | 0.19 uH T50-6, 7 turns air coil, 1 mm wire, 4-5 turns around 9.5 mm (3/8” drill bit) form | 0.09 uH T50-6, 4 turns air coil, 1 mm wire, 4-5 turns around 6.25 mm (1/4” drill bit) form

30

Nominal air-core inductance values calculated from 1 mm diameter wire with 1 to 1.5 mm turn spacing. When in doubt, an extra turn or two can be added to the coil length and the inductance decreased by spacing coils apart.

## Troubleshooting the serial resonant bandpass filters

The serial resonant bandpass filters are resonant and so tuning the filter for maximum power is generally desirable. Because the capacitors are fixed values, the inductors are easier to tune in value. By spacing the turns on an inductor toroid or solenoid further apart, the inductance may be decreased. Therefore an extra turn or two may be wound on the inductor to increase the inductance over the nominal value and then the inductance increased by spacing out the turns, or increased by bunching up the turns. The components L2 and C2+C3 form a series resonant circuit that is tuned so that it is resonant at the frequency band of interest, or perhaps up to 10% in frequency above the band of interest. The components L3 and C5+C7 form a parallel resonant circuit that is tuned so that it is resonant at the second harmonic (two times) the frequency band of interest, or up to 20% above the frequency band of interest. If one has access to a VNA such as the NanoVNA, one can sweep out the frequency range between 1 MHz and 30 MHz. In the frequency band of interest, generally the transmitted power S21 should be -1 dB to 0 dB. At the second harmonic, the transmitted power should be -40 dB or less. One then can adjust the spacing of the inductor turns to adjust the inductance. Once the desired inductance value is achieved, cyanoacrylate glue can be placed on the turns to tack them down to immobilize the turns. Moisture, such as from one’s breath, can be used to accelerate the curing of the glue.
In case a NanoVNA or other VNA is not available, there are some other tips to try. If one has access to a dummy load with a power meter, one can troubleshoot the filter by measuring the power output. By temporarily shorting across L3, one can remove the influence of the second harmonic filter. If the power improves, then it is likely that the parallel resonant frequency of the combination of L3 and C5+C7 is too low. One can separate the turns of L3 to increase the parallel resonant frequency, or if that is insufficient, remove a turn from L3. If even after shorting across L3 the power is still too low, one can tune the series resonance frequency of the combination of L2 and C2+C3 by spreading or bunching the coils of L2. One can try transmitting into the dummy load on frequencies above or below the frequency of interest to determine if the power improves, taking care to minimize the spurious radiation. If one transmits into the dummy load at a lower frequency than the desired band and the power improves, then the resonance frequency needs to be increased by either spreading the turns of L2 apart, removing a turn from L2, or in some cases decreasing C2+C3 by substituing in a smaller capacitance. If one transmits into the dummy load at a higher frequency than the desired band and the power improves, then bunching up the turns on L2, or perhaps adding a turn to L2, or in some cases increasing the capacitance of C2+C3 by adding a small capacitor can improve the power. In some

31 cases, decreasing C1 may also help increase output power but may decrease overall efficiency of the amplifier.
One can construct a dummy load with a peak detector to measure the power being outputted by the RFBitBanger. A simple circuit can be used to measure the power output of the transceiver as shown below. The CW mode with a straight key (down button) may be used to transmit a continuous wave signal for measurement. A dummy load of 50 ohm and 5 W resistor is used, or perhaps two 100 ohm resistors in parallel rated for 3 W, and it should be a thick or thin film metal resistor or a carbon resistor, but not a wirewound resistor which has significant inductance. The dummy load should be placed into a shielded metal enclosure to minimize spurious radiation with the shield of the coaxial cable connected to the enclosure. One can wrap aluminum or copper tape around an insulating box if a metal enclosure is not available. A diode is used to rectify the RF voltage and it is measured on a ceramic capacitor using a voltmeter (for example a multimeter or galvanometer). The voltage output V is the peak RF voltage, and the RF power P can be calculated by P=V

2
/100 so for example 20 V peak output voltage corresponds to 4 W of RF power.

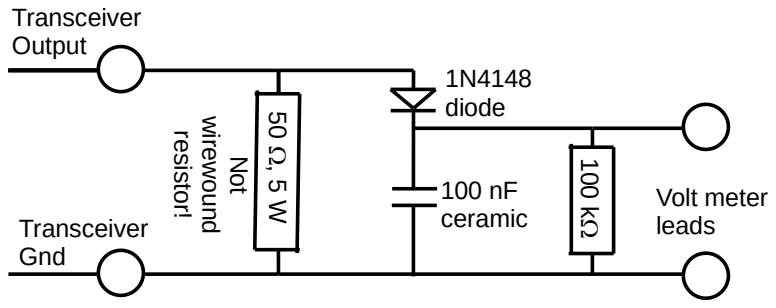
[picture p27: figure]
Transceiver Output; Transceiver Gnd; 1N4148 diode; 100 nF ceramic; wire; w ound; resistor!; Volt meter leads

32

## 3-D printable parts in the RFBitBanger project

There are a number of helpful 3-D printable forms included in the RFBitBanger project. These were designed with the FreeCAD software ( https://www.freecad.org/ ) as parametric models and so their dimensions can be modified by changing values in a spreadsheet.
RFBitBanger Case for SMT version: a case consists of three files “TopCase-SMT.stl,” “BottomCase-SMT.stl,” and “ButtonExtension.stl.” The “TopCase-SMT” and “BottomCase-SMT” files are a top and bottom piece that clamp over the SMT version of the radio. They are held together by 4-40 X ½” screws and nuts or M2.5 X 12 screws and nuts. Five “ButtonExtension” parts are used to push through the “Topcase-SMT” part so that the buttons on the PCB can be pressed from the outside of the case.

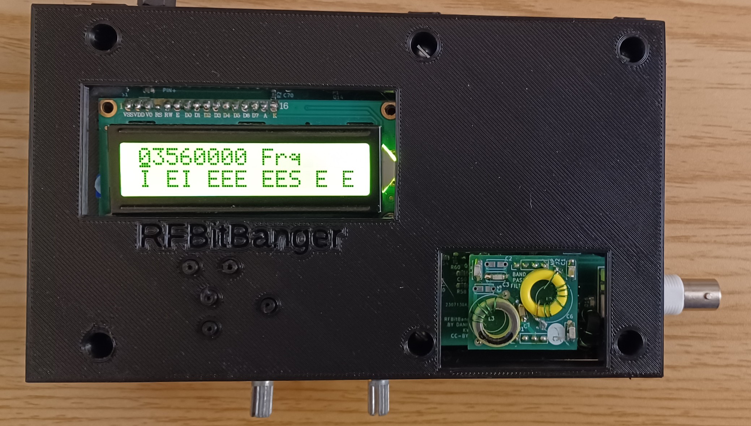
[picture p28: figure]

“InductorBobbin” and “AxialInductorBobbin”: these are parametric FreeCAD files that can be used to design printable coil forms for air core inductors. The various dimensions of the form are entered at the top of the form and the part is modified to conform to these dimensions. At the same time, the wire diameter may be entered to determine the pitch. The inductance, resistance, and reactance of the coil form with the given wire diameter and number of turns is calculated, and the form dimensions may be adjusted to achieve a desired inductance. The axial inductor bobbin and the corresponding spreadsheet is shown below.

33

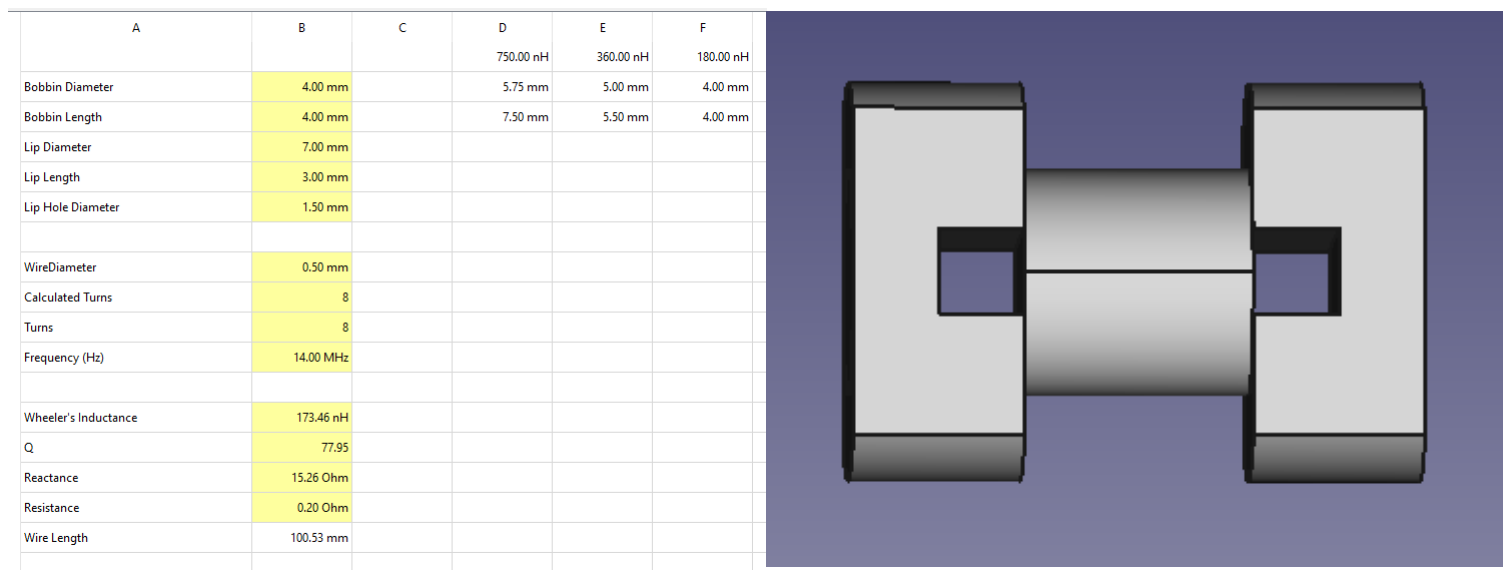
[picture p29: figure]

“PaddlesKey” and “PaddlesKeyGroundCenter”: two iambic keys, the difference between them being that the ground center is the more common arrangement with the two paddles wire to the tip and ring of the jack and a grounded post between the paddles, while the other arrange is with the less common arrangement with two posts wired to the tip and the ring, and each paddle grounded.

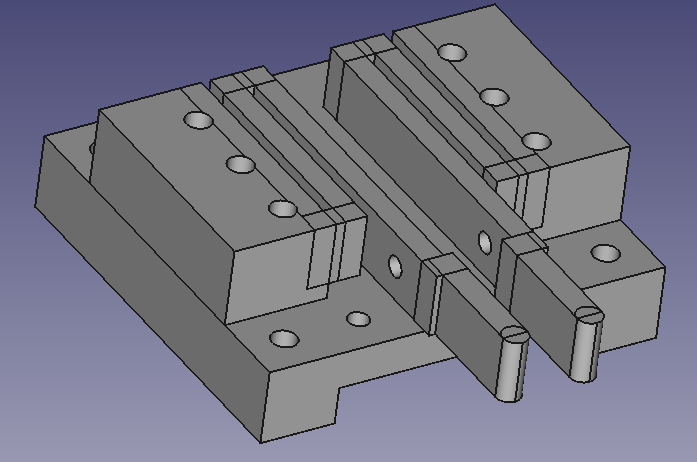
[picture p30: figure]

34

## Replacing the crystal with a temperature compensated crystal oscillator (TCXO)

The crystal may be replaced with a TCXO for additional frequency stability, which is especially helpful when using low bit rate SCAMP modes. A 3225-sized TCXO may be fitted, with pin 1 of the TCXO coinciding with the corner of the L shape on the silkscreen. This has been tested with the ECS-TXO-3225MV-250-TR TCXO, 25 MHz, 2 ppm -40 to 85 C TCXO. This TCXO has pin 1 floating, pin 2 grounded, pin 3 oscillator output, and pin 4 connected to 3.3V. The ABRACON I538-2O7- 25.000 MHz may also be suitable as well. To install the TCXO, first remove the existing crystal. A hot air rework station may be used to remove it. The TCXO may be placed, applying flux to the pads, placing the TCXO on the pads, and using hot air to solder the TCXO to the pads. Then cut the trace from pin 3 of the SI5351A to pin 1 of the TCXO, so that pin 1 of the TCXO is floating, which is shown in the picture below surrounded by double black boxes. Note other TCXOs may require pin 1 to be grounded. The solder jumper JP11 should be bridged to connect power to the TCXO.

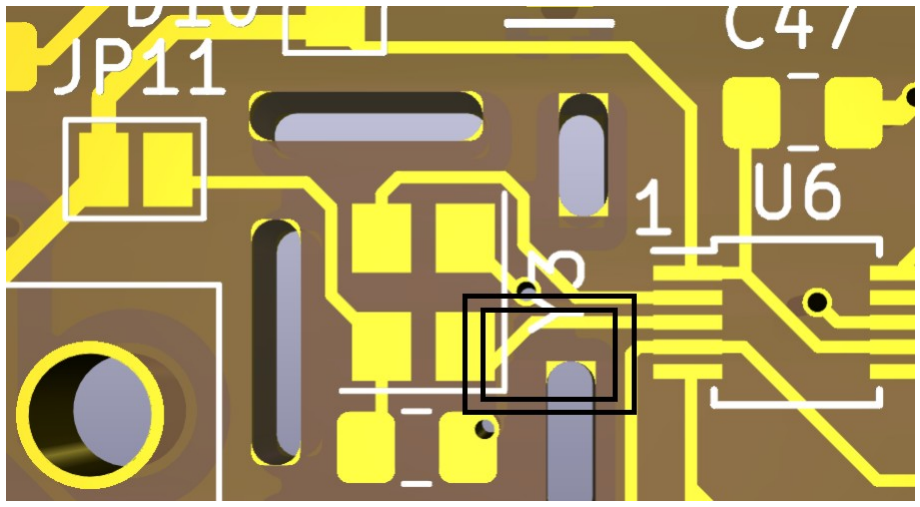
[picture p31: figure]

35

## Troubleshooting problems with the RFBitBanger

If the RFBitBanger stops functioning, usually it is due to a few types of problems.
First, make sure the gain and volume are turned up so that the audio can be heard and that the speaker is connected.
Like any electronic device, 90% of the time when there is a failure, it is because of a mechanical problem. It can be, for example, a loose cable or a worn connector. One can gently push on a questionable connector or part with one’s finger to determine if it is making intermittent contact. If so, sometimes the problem is because the connector is worn and needs to be replaced. If integrated circuits are socketed, push the integrated circuits back into their sockets to make sure these are firmly seated and no pins are bent out of the socket. Near the integrated circuit socket, the digit “1” has been silkscreened to indicate the position of pin 1 of the integrated circuit. The side of the integrated circuit with pin 1 is usually marked with a notch on the edge of the package, or a dot on the package in the corner with pin 1. Cables should also be pushed back onto their pins to make sure they are seated properly, and are not offset by a row or column of pins.
Sometimes it is because of a solder joint that has either cracked, because solder is a brittle metal, or because the solder joint was not formed properly. In either case, one can reheat the solder joint with a soldering iron to melt and reform the joint. There is usually little risk in reheating a solder joint, so any questionable connections can be reheated as needed as long as the heat is applied only long enough for the solder to melt. If electricity is not available, there are soldering irons that are heated by butane torches, or the end of a metal rod can be heated and placed in contact with the solder joint.
If the radio does not transmit, it is likely that one or more of the 2N7000 transistors which are positions Q3,Q5,Q6, and Q7 could be damaged. If when transmitting, one or more of the transistors becomes too hot to touch in a few seconds, this transistor has likely failed. The transistor should be removed and replaced. The flat side of the transistor should face the same direction as the flat side of the half-circle showing the orientation of the transistor on the silk screen.
The thin magnet wires on the toroids should be inspected to see there are any kinks or cuts as these are rather thin and can be severed easily. If the wire on the toroid is broken, it can be replaced with an insulated wire that is thin enough to be wrapped a sufficient number of times around the toroid.

36

## Schematic and PCB Layout of the Main PCB

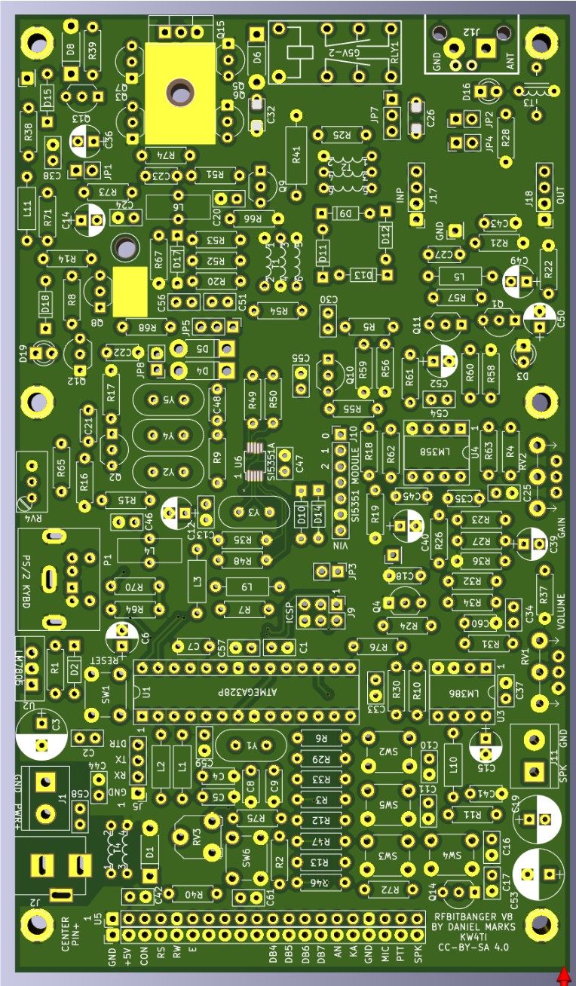
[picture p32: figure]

37

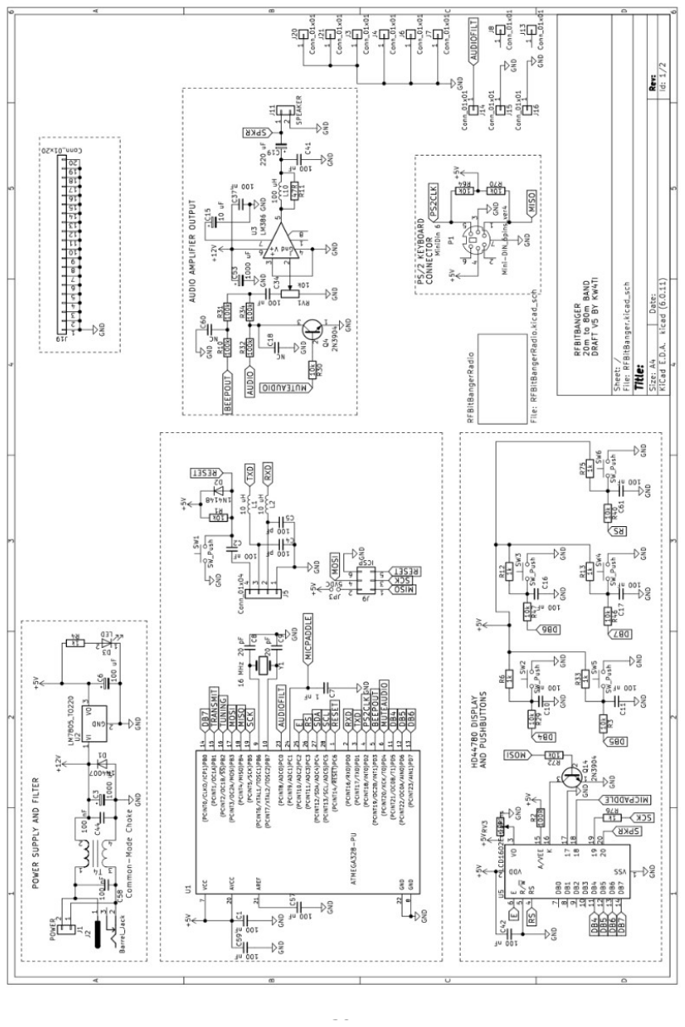
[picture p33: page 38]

38

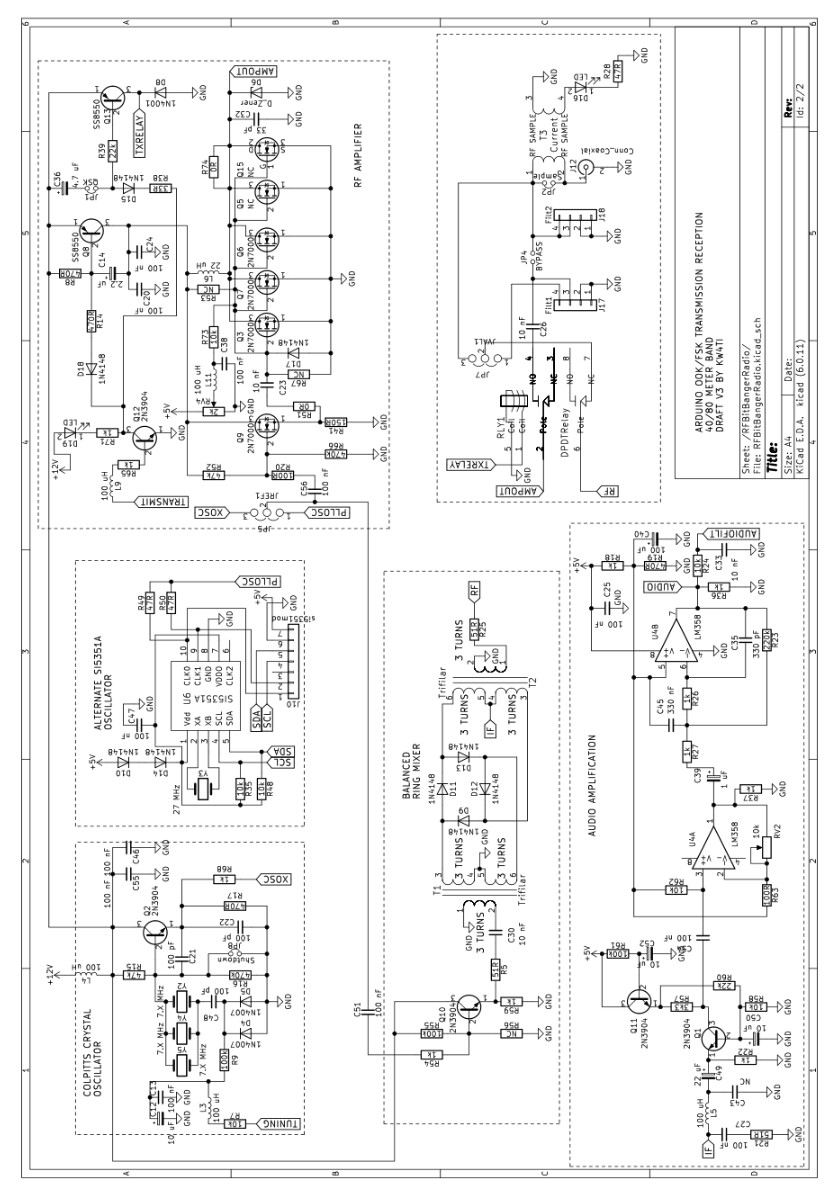
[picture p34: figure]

39

## Bill of Materials, Main PCB

Ref | Value | Footprint
C1 | 100 nF | 50 V, 2.5 mm lead spacing ceramic disc capacitor
C2 | 100 nF | 50 V, 2.5 mm lead spacing ceramic disc capacitor
C3 | 1000 uF | 10 mm, 25 V radial electrolytic capacitor
C4 | 100 pF | 50 V, 5 mm lead spacing ceramic disc capacitor
C5 | 100 pF | 50 V, 5 mm lead spacing ceramic disc capacitor
C6 | 100 uF | 50 V, 2.5 mm lead spacing ceramic disc capacitor
C7 | 1 nF | 50 V, 5 mm lead spacing ceramic disc capacitor
C8 | 20 pF | 50 V, 5 mm lead spacing ceramic disc capacitor
C9 | 20 pF | 50 V, 5 mm lead spacing ceramic disc capacitor
C10 | 100 nF | 50 V, 2.5 mm lead spacing ceramic disc capacitor
C11 | 100 nF | 50 V, 2.5 mm lead spacing ceramic disc capacitor
C12 | 10 uF | 5 mm, 25 V radial electrolytic capacitor
C13 | 100 nF | 50 V, 2.5 mm lead spacing ceramic disc capacitor
C14 | 2.2 uF | 50 V, 2.5 mm lead spacing ceramic disc capacitor
C15 | 10 uF | 5 mm, 25 V radial electrolytic capacitor
C16 | 100 nF | 50 V, 2.5 mm lead spacing ceramic disc capacitor
C17 | 100 nF | 50 V, 2.5 mm lead spacing ceramic disc capacitor
C18 | NC | Open circuit
C19 | 220 uF | 8 mm, 25 V radial electrolytic capacitor
C20 | 100 nF | 50 V, 2.5 mm lead spacing ceramic disc capacitor
C21 | 100 pF | 50 V, 5 mm lead spacing ceramic disc capacitor
C22 | 100 pF | 50 V, 5 mm lead spacing ceramic disc capacitor
C23 | 10 nF | 50 V, 2.5 mm lead spacing ceramic disc capacitor
C24 | 100 nF | 50 V, 2.5 mm lead spacing ceramic disc capacitor
C25 | 100 nF | 50 V, 2.5 mm lead spacing ceramic disc capacitor
C26 | 10 nF | 50 V, 2.5 mm lead spacing ceramic disc capacitor
C27 | 100 nF | 50 V, 2.5 mm lead spacing ceramic disc capacitor
C30 | 10 nF | 50 V, 2.5 mm lead spacing ceramic disc capacitor
C32 | 33 pF | 50 V, 5 mm lead spacing ceramic disc capacitor
C33 | 10 nF | 50 V, 2.5 mm lead spacing ceramic disc capacitor
C34 | 100 nF | 50 V, 2.5 mm lead spacing ceramic disc capacitor
C35 | 330 pF | 50 V, 5 mm lead spacing ceramic disc capacitor
C36 | 4.7 uF | 5 mm, 25 V radial electrolytic capacitor
C37 | 100 nF | 50 V, 2.5 mm lead spacing ceramic disc capacitor
C38 | 100 nF | 50 V, 2.5 mm lead spacing ceramic disc capacitor
C39 | 1 uF | 5 mm, 25 V radial electrolytic capacitor
C40 | 100 uF | 50 V, 2.5 mm lead spacing ceramic disc capacitor
C41 | 100 nF | 50 V, 2.5 mm lead spacing ceramic disc capacitor
| | 40

C42 | 100 nF | 50 V, 2.5 mm lead spacing ceramic disc capacitor
C43 | NC | 50 V, 2.5 mm lead spacing ceramic disc capacitor
C44 | 100 nF | 50 V, 2.5 mm lead spacing ceramic disc capacitor
C45 | 330 nF | 50 V, 5 mm lead spacing ceramic disc capacitor
C46 | 100 nF | 50 V, 2.5 mm lead spacing ceramic disc capacitor
C47 | 100 nF | 50 V, 2.5 mm lead spacing ceramic disc capacitor
C48 | 100 pF | 50 V, 5 mm lead spacing ceramic disc capacitor
C49 | 22 uF | 5 mm, 25 V radial electrolytic capacitor
C50 | 10 uF | 50 V, 2.5 mm lead spacing ceramic disc capacitor
C51 | 100 nF | 50 V, 2.5 mm lead spacing ceramic disc capacitor
C52 | 10 uF | 50 V, 2.5 mm lead spacing ceramic disc capacitor
C53 | 1000 uF | 10 mm, 25 V radial electrolytic capacitor
C54 | 100 nF | 50 V, 2.5 mm lead spacing ceramic disc capacitor
C55 | 100 nF | 50 V, 2.5 mm lead spacing ceramic disc capacitor
C56 | 100 nF | 50 V, 2.5 mm lead spacing ceramic disc capacitor
C57 | 100 nF | 50 V, 2.5 mm lead spacing ceramic disc capacitor
C58 | 100 nF | 50 V, 2.5 mm lead spacing ceramic disc capacitor
C59 | 100 nF | 50 V, 2.5 mm lead spacing ceramic disc capacitor
C60 | NC | NC
C61 | 100 nF | 50 V, 2.5 mm lead spacing ceramic disc capacitor
D1 | 1N4007 | DO-41 axial diode
D2 | 1N4148 | DO-35 axial diode
D3 | LED | LED 3 mm
D4 | 1N4007 | DO-41 axial diode
D5 | 1N4007 | DO-41 axial diode
D6 | D_Zener | optional zener diode DO-41 1N4757A
D8 | 1N4007 | DO-41 axial diode
D9 | 1N4148 | DO-35 axial diode
D10 | 1N4148 | DO-35 axial diode
D11 | 1N4148 | DO-35 axial diode
D12 | 1N4148 | DO-35 axial diode
D13 | 1N4148 | DO-35 axial diode
D14 | 1N4148 | DO-35 axial diode
D15 | 1N4148 | DO-35 axial diode
D16 | LED | RED LED 3 mm
D17 | 1N4148 | DO-35 axial diode
D18 | 1N4148 | DO-35 axial diode
D19 | LED | LED 3 mm
J1 | POWER | 5.08 mm spacing screw terminal block
J2 | Barrel_Jack | Dc Barrel Jack 2.5 mm
J5 | Conn_01x04 | 4 pin header 2.54 mm pitch
J9 | ICSP | 2 by 3 (6 pins) header 2.54 mm pitch
J10 | si5351mod | 7 pin socket 2.54 mm pitch
| | 41

J11 | SPEAKER | 5.08 mm spacing screw terminal block
J12 | Conn_Coaxial | PCB BNC Board Edge Connector e.g. (LCSC C2837588, Shenzhen
| | Kinghelm Elec KH-BNC75-3511)
J17 | Filt1 | 4 pin header 2.54 mm pitch
J18 | Filt2 | 4 pin header 2.54 mm pitch
J19 | Conn_01x20 | 20 pin header 2.54 mm pitch
JP1 | QSK | 2 pin header 2.54 mm pitch
JP2 | Sample | 2 pin header 2.54 mm pitch
JP3 | 5VDC | 2 pin header 2.54 mm pitch
JP4 | BYPASS | 2 pin header 2.54 mm pitch
JP5 | JREF1 | 3 pin header 2.54 mm pitch
JP7 | JVAL1 | 3 pin header 2.54 mm pitch
JP8 | Shutdown | 2 pin header 2.54 mm pitch
L1 | 10 uH | 10 uH axial inductor, 100 mA maximum
L2 | 10 uH | 10 uH axial inductor, 100 mA maximum
L3 | 100 uH | 100 uH axial inductor, 100 mA maximum
L4 | 100 uH | RF choke, FT37-43 or FT50-43, wind to instructions
L5 | 100 uH | 100 uH axial inductor, 100 mA maximum
L6 | 22 uH | RF choke, FT37-43 or FT50-43, wind to instructions
L9 | 100 uH | 100 uH axial inductor, 100 mA maximum
L10 | 100 uH | 100 uH axial inductor, 100 mA maximum
L11 | 100 uH | 100 uH axial inductor, 100 mA maximum
P1 | Mini-DIN_6pins_ver4 | MiniDin 6 female connector, e.g. (LCSC C77848, CONNFLY
| | DS1093-01-PN60)
Q1 | 2N3904 | TO-92 NPN transistor, EBC
Q2 | 2N3904 | TO-92 NPN transistor, EBC
Q3 | 2N7000 | TO-92 N-channel MOSFET, SGD
Q4 | 2N3904 | TO-92 NPN transistor, EBC
Q5 | NC | Optional fourth TO-92 MOSFET, EBC
Q6 | 2N7000 | TO-92 N-channel MOSFET, SGD
Q7 | 2N7000 | TO-92 N-channel MOSFET, SGD
Q8 | SS8550 | TO-92 PNP transistor (LCSC C8541), 1.5A max collector current,
| | EBC
Q9 | 2N7000 | TO-92 N-channel MOSFET, SGD
Q10 | 2N3904 | TO-92 NPN transistor, EBC
Q11 | 2N3904 | TO-92 NPN transistor, EBC
Q12 | 2N3904 | TO-92 NPN transistor, EBC
Q13 | SS8550 | TO-92 PNP transistor (LCSC C8541), 1.5A max collector current,
| | EBC
Q14 | 2N3904 | TO-92 NPN transistor, EBC
Q15 | NC | NC (optional TO-220 MOSFET, e.g. IRF510), GDS
R1 | 10k | ¼ watt axial resistor metal film
R2 | 100R | ¼ watt axial resistor metal film
| | 42

R3 | 10k | ¼ watt axial resistor metal film
R4 | 1k | ¼ watt axial resistor metal film
R5 | 51R | ¼ watt axial resistor metal film
R6 | 1k | ¼ watt axial resistor metal film
R7 | 10k | ¼ watt axial resistor metal film
R8 | 470R | ¼ watt axial resistor metal film
R9 | 100k | ¼ watt axial resistor metal film
R10 | 100k | ¼ watt axial resistor metal film
R11 | 47R | ¼ watt axial resistor metal film
R12 | 1k | ¼ watt axial resistor metal film
R13 | 1k | ¼ watt axial resistor metal film
R14 | 470R | ¼ watt axial resistor metal film
R15 | 47k | ¼ watt axial resistor metal film
R16 | 470k | ¼ watt axial resistor metal film
R17 | 470R | ¼ watt axial resistor metal film
R18 | 1k | ¼ watt axial resistor metal film
R19 | 470R | ¼ watt axial resistor metal film
R20 | 100R | ¼ watt axial resistor metal film
R21 | 51R | ¼ watt axial resistor metal film
R22 | 1k | ¼ watt axial resistor metal film
R23 | 220k | ¼ watt axial resistor metal film
R24 | 10k | ¼ watt axial resistor metal film
R25 | 51R | ¼ watt axial resistor metal film
R26 | 1k | ¼ watt axial resistor metal film
R27 | 1k | ¼ watt axial resistor metal film
R28 | 47R | ¼ watt axial resistor metal film
R29 | 10k | ¼ watt axial resistor metal film
R30 | 10k | ¼ watt axial resistor metal film
R31 | 100k | ¼ watt axial resistor metal film
R32 | 100k | ¼ watt axial resistor metal film
R33 | 1k | ¼ watt axial resistor metal film
R34 | 100k | ¼ watt axial resistor metal film
R35 | 10k | ¼ watt axial resistor metal film
R36 | 1k | ¼ watt axial resistor metal film
R37 | 1k | ¼ watt axial resistor metal film
R38 | 33R | ¼ watt axial resistor metal film
R39 | 22k | ¼ watt axial resistor metal film
R40 | 10k | ¼ watt axial resistor metal film
R41 | 150R | 2 watt axial resistor metal film
R46 | 10k | ¼ watt axial resistor metal film
R47 | 10k | ¼ watt axial resistor metal film
R48 | 10k | ¼ watt axial resistor metal film
R49 | 47R | ¼ watt axial resistor metal film
| | 43

R50 | 47R | ¼ watt axial resistor metal film
R51 | 0R | Wire jumper
R52 | 47k | ¼ watt axial resistor metal film
R53 | NC | Open circuit
R54 | 1k | ¼ watt axial resistor metal film
R55 | 100k | ¼ watt axial resistor metal film
R56 | NC | Open circuit
R57 | 3k3 | ¼ watt axial resistor metal film
R58 | 10k | ¼ watt axial resistor metal film
R59 | 1k | ¼ watt axial resistor metal film
R60 | 22k | ¼ watt axial resistor metal film
R61 | 100k | ¼ watt axial resistor metal film
R62 | 10k | ¼ watt axial resistor metal film
R63 | 100R | ¼ watt axial resistor metal film
R64 | 10k | ¼ watt axial resistor metal film
R65 | 1k | ¼ watt axial resistor metal film
R66 | 470k | ¼ watt axial resistor metal film
R67 | NC | Open circuit
R68 | 1k | ¼ watt axial resistor metal film
R70 | 10k | ¼ watt axial resistor metal film
R71 | 1k | ¼ watt axial resistor metal film
R72 | 10k | ¼ watt axial resistor metal film
R73 | 10k | ¼ watt axial resistor metal film
R74 | 0R | Wire jumper
R75 | 1k | ¼ watt axial resistor metal film
R76 | 1k | ¼ watt axial resistor metal film
RLY1 | DPDTRelay | Omron G5V-2 type DPDT relay, e.g. Hongfa HK19F, 12 volt coil,
| | LCSC C42803
RV1 | 10k | B10K potentiometer
RV2 | 10k | B10K potentiometer
RV3 | 10k | 10k trimmer-type potentiometer (e.g. BOURNS 3306P-1-103,
| | LCSC C840697)
RV4 | 2k | 2k 3296W-type potentiometer, e.g. LCSC C118206
SW1 | SW_Push | 6 mm normally open push button, e..g Diptronics DTS-62K-V,
| | LCSC C100057
SW2 | SW_Push | 6 mm normally open push button, e..g Diptronics DTS-62K-V,
| | LCSC C100057
SW3 | SW_Push | 6 mm normally open push button, e..g Diptronics DTS-62K-V,
| | LCSC C100057
SW4 | SW_Push | 6 mm normally open push button, e..g Diptronics DTS-62K-V,
| | LCSC C100057
SW5 | SW_Push | 6 mm normally open push button, e..g Diptronics DTS-62K-V,
| | LCSC C100057
| | 44

SW6 | SW_Push | 6 mm normally open push button, e..g Diptronics DTS-62K-V,
| | LCSC C100057
T1 | Trifilar | Transformer (balun) on FT37-43, FT50-43 core, wind according to
| | instructions
T2 | Trifilar | Transformer (balun) on FT37-43, FT50-43 core, wind according to
| | instructions
T3 | RF Current Sampler | Transformer on FT37-43, FT50-43 core, wind according to
| | instructions
T4 | Common-Mode Choke | Transformer on FT37-43, FT50-43 core, wind according to
| | instructions
U1 | ATMEGA328-PU | ATMEGA328P-PU 28 pin DIP microcontroller
U2 | LM7805_TO220 | LM7805 5 volt regulator
U3 | LM386 | LM386 8-pin DIP speaker amplifier
U4 | LM358 | LM358 8-pin DIP dual opamp
U5 | LCD1602ExtraPins | 20 pin header 2.54 mm pitch
U6 | SI5351A | SI5351A integrated circuit (only install if no module)
Y1 | 16 MHz | HC-49 16 MHz crystal
Y2 | 7.X MHz | HC-49 crystal for pulled oscillator
Y3 | 25 MHz | 25 MHz crystal for SI5351A (only install if no module)
Y4 | 7.X MHz | HC-49 crystal for pulled oscillator
Y5 | 7.X MHz | HC-49 crystal for pulled oscillator

45

## Schematic and PCB Layout of the Display PCB

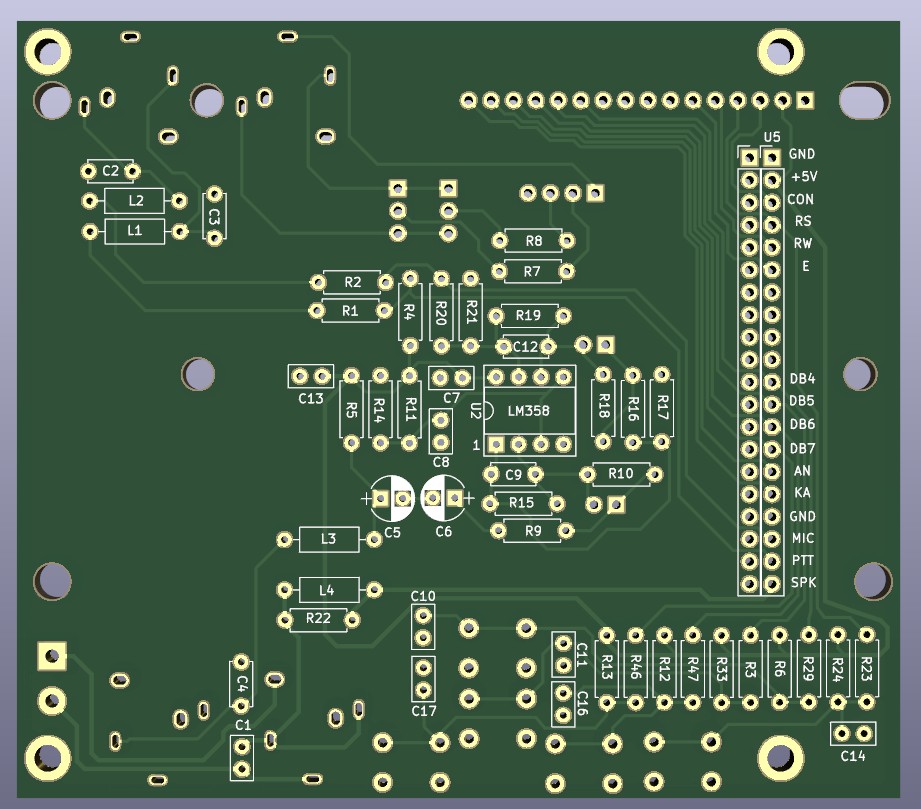
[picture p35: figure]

46

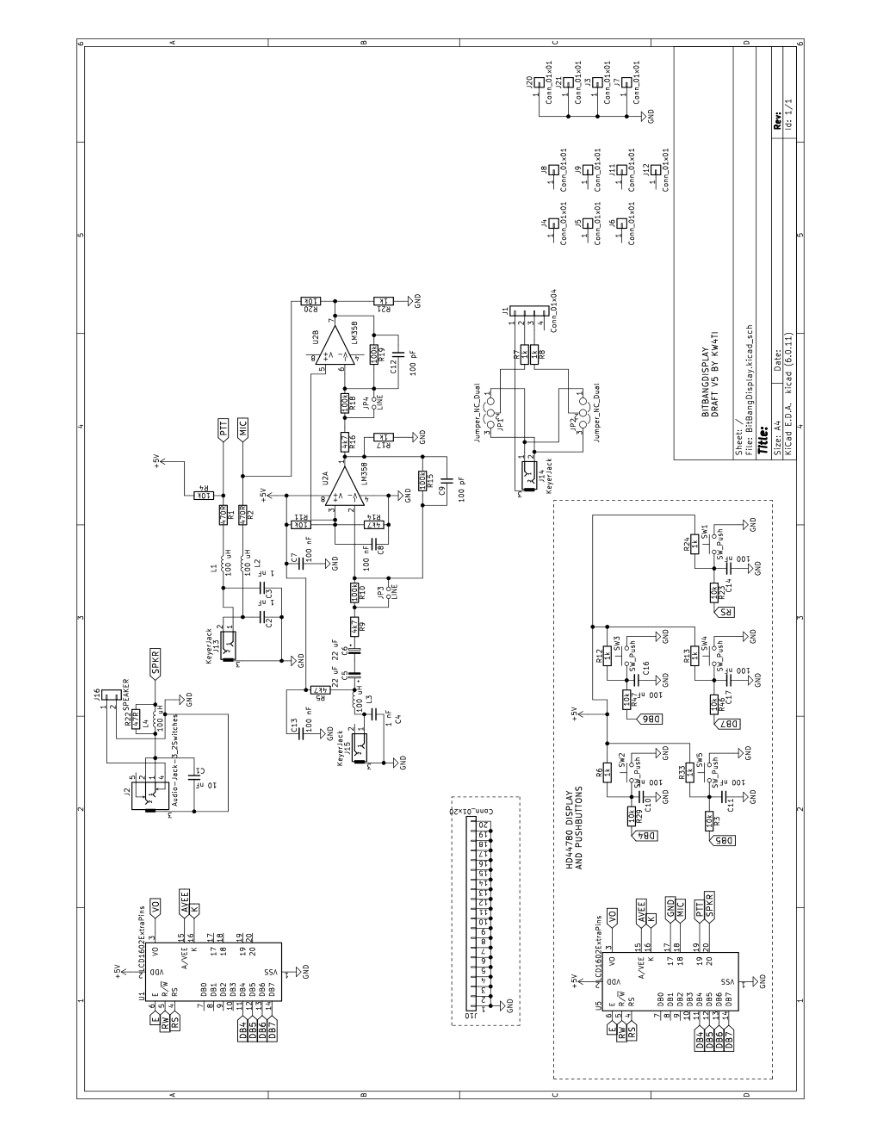
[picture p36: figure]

47

## Bill of Materials, Display PCB

Ref | Value | Component
C1 | 10 nF | 50 V, 2.5 mm lead spacing ceramic disc capacitor
C2 | 1 nF | 50 V, 5 mm lead spacing ceramic disc capacitor
C3 | 1 nF | 50 V, 5 mm lead spacing ceramic disc capacitor
C4 | 1 nF | 50 V, 5 mm lead spacing ceramic disc capacitor
C5 | 22 uF | 5 mm, 25 V radial electrolytic capacitor
C6 | 22 uF | 5 mm, 25 V radial electrolytic capacitor
C7 | 100 nF | 50 V, 2.5 mm lead spacing ceramic disc capacitor
C8 | 100 nF | 50 V, 2.5 mm lead spacing ceramic disc capacitor
C9 | 100 pF | 50 V, 5 mm lead spacing ceramic disc capacitor
C10 | 100 nF | 50 V, 2.5 mm lead spacing ceramic disc capacitor
C11 | 100 nF | 50 V, 2.5 mm lead spacing ceramic disc capacitor
C12 | 100 pF | 50 V, 5 mm lead spacing ceramic disc capacitor
C13 | 100 nF | 50 V, 2.5 mm lead spacing ceramic disc capacitor
C14 | 100 nF | 50 V, 2.5 mm lead spacing ceramic disc capacitor
C16 | 100 nF | 50 V, 2.5 mm lead spacing ceramic disc capacitor
C17 | 100 nF | 50 V, 2.5 mm lead spacing ceramic disc capacitor
J1 | Conn_01x04 | 4 pin header 2.54 mm pitch
J2 | 3.5 mm stereo jack | 3.5 mm stereo jack (Korean Hroparts Elec, PJ-3240-
| | 5A, LCSC C148514)
J10 | Conn_01x20 | 20 pin header 2.54 mm pitch
J13 | 3.5 mm stereo jack | 3.5 mm stereo jack (Korean Hroparts Elec, PJ-3240-
| | 5A, LCSC C148514)
J14 | 3.5 mm stereo jack | 3.5 mm stereo jack (Korean Hroparts Elec, PJ-3240-
| | 5A, LCSC C148514)
J15 | 3.5 mm stereo jack | 3.5 mm stereo jack (Korean Hroparts Elec, PJ-3240-
| | 5A, LCSC C148514)
J16 | Speaker connector | 5.08 mm spacing screw terminal block
JP1 | Jumper_NC_Dual | 3 pin header 2.54 mm pitch
JP2 | Jumper_NC_Dual | 3 pin header 2.54 mm pitch
JP3 | LINE | 2 pin header 2.54 mm pitch
JP4 | LINE | 2 pin header 2.54 mm pitch
L1 | 100 uH | 100 uH axial inductor, 100 mA max
L2 | 100 uH | 100 uH axial inductor, 100 mA max
L3 | 100 uH | 100 uH axial inductor, 100 mA max
L4 | 100 uH | 100 uH axial inductor, 100 mA max
R1 | 470R | ¼ watt axial resistor metal film
R2 | 470R | ¼ watt axial resistor metal film
R3 | 10k | ¼ watt axial resistor metal film
| | 48

R4 | 10k | ¼ watt axial resistor metal film
R5 | 4k7 | ¼ watt axial resistor metal film
R6 | 1k | ¼ watt axial resistor metal film
R7 | 1k | ¼ watt axial resistor metal film
R8 | 1k | ¼ watt axial resistor metal film
R9 | 4k7 | ¼ watt axial resistor metal film
R10 | 100k | ¼ watt axial resistor metal film
R11 | 10k | ¼ watt axial resistor metal film
R12 | 1k | ¼ watt axial resistor metal film
R13 | 1k | ¼ watt axial resistor metal film
R14 | 4k7 | ¼ watt axial resistor metal film
R15 | 100k | ¼ watt axial resistor metal film
R16 | 4k7 | ¼ watt axial resistor metal film
R17 | 1k | ¼ watt axial resistor metal film
R18 | 100k | ¼ watt axial resistor metal film
R19 | 100k | ¼ watt axial resistor metal film
R20 | 10k | ¼ watt axial resistor metal film
R21 | 1k | ¼ watt axial resistor metal film
R22 | 47R | ¼ watt axial resistor metal film
R23 | 10k | ¼ watt axial resistor metal film
R24 | 1k | ¼ watt axial resistor metal film
R29 | 10k | ¼ watt axial resistor metal film
R33 | 1k | ¼ watt axial resistor metal film
R46 | 10k | ¼ watt axial resistor metal film
R47 | 10k | ¼ watt axial resistor metal film
SW1 | SW_Push | 6 mm normally open push button, e..g Diptronics
| | DTS-62K-V, LCSC C100057
SW2 | SW_Push | 6 mm normally open push button, e..g Diptronics
| | DTS-62K-V, LCSC C100057
SW3 | SW_Push | 6 mm normally open push button, e..g Diptronics
| | DTS-62K-V, LCSC C100057
SW4 | SW_Push | 6 mm normally open push button, e..g Diptronics
| | DTS-62K-V, LCSC C100057
SW5 | SW_Push | 6 mm normally open push button, e..g Diptronics
| | DTS-62K-V, LCSC C100057
U1 | LCD1602ExtraPins | 16 pin header 2.54 mm pitch, HD44780 display
U2 | LM358 | 8 pin DIP socket
U5 | LCD1602ExtraPins | 20 pin header 2.54 mm pitch

49

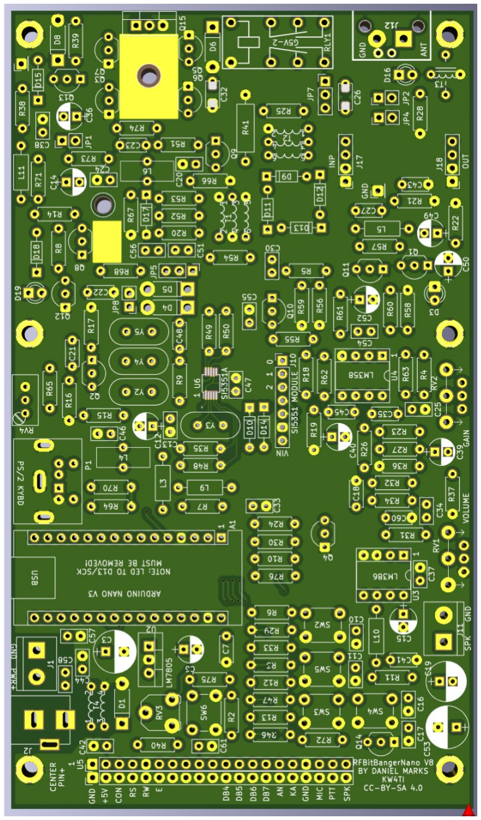
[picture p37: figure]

50

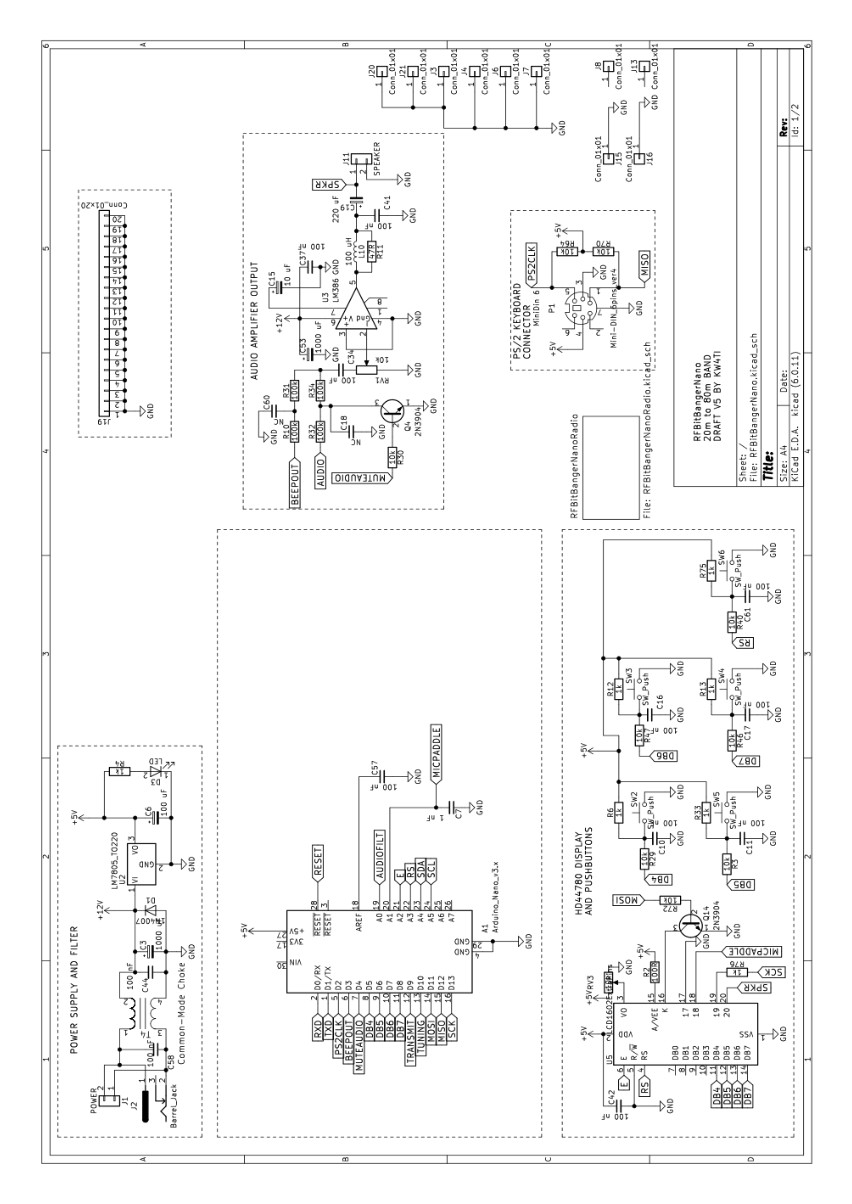
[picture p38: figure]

51

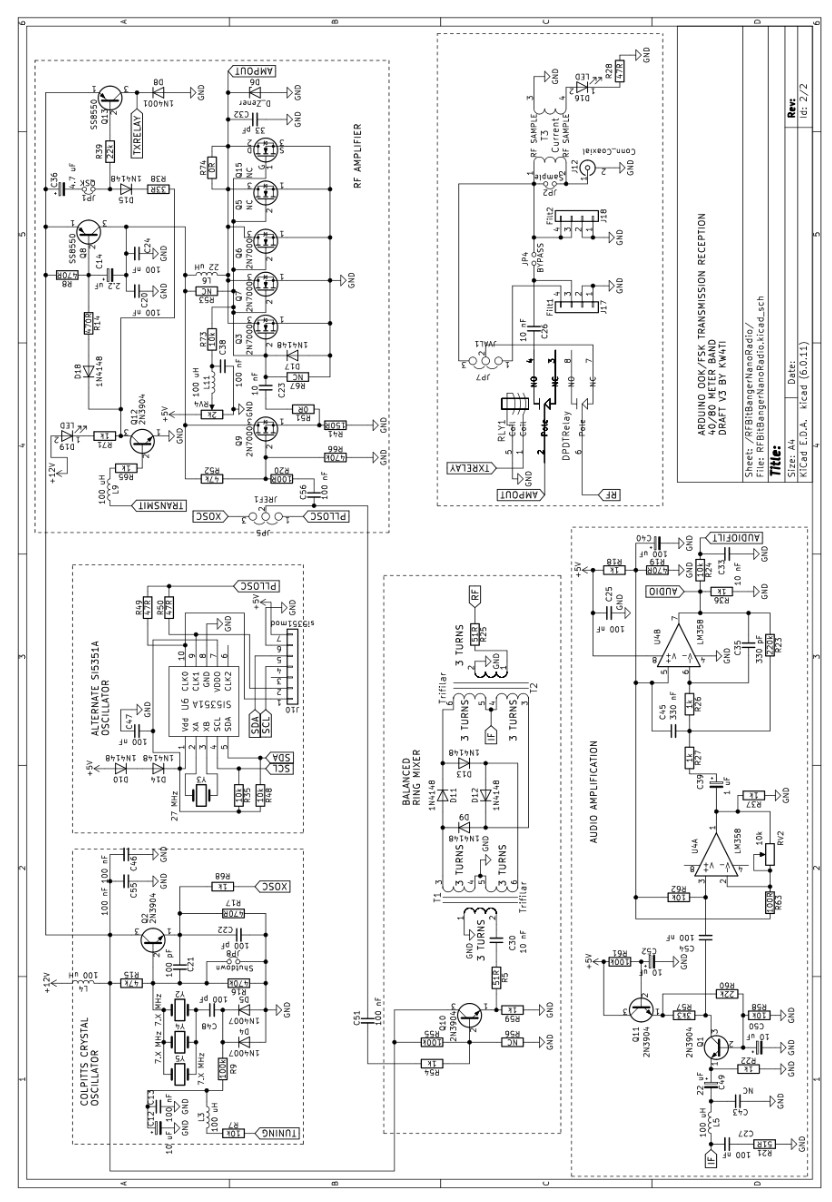
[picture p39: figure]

52

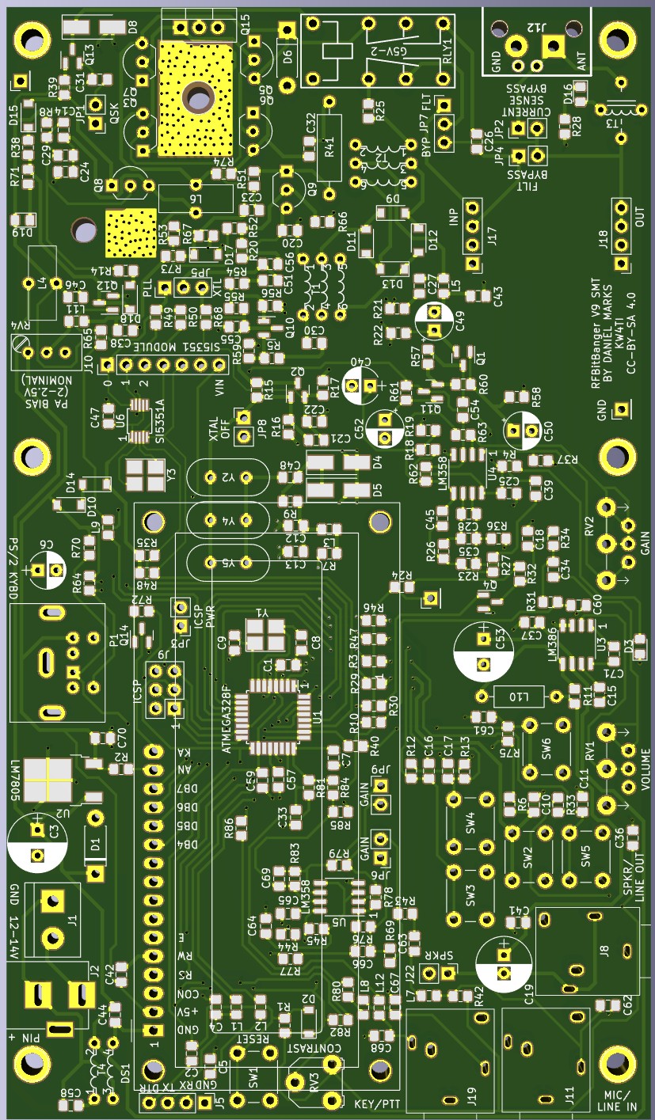
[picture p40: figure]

53

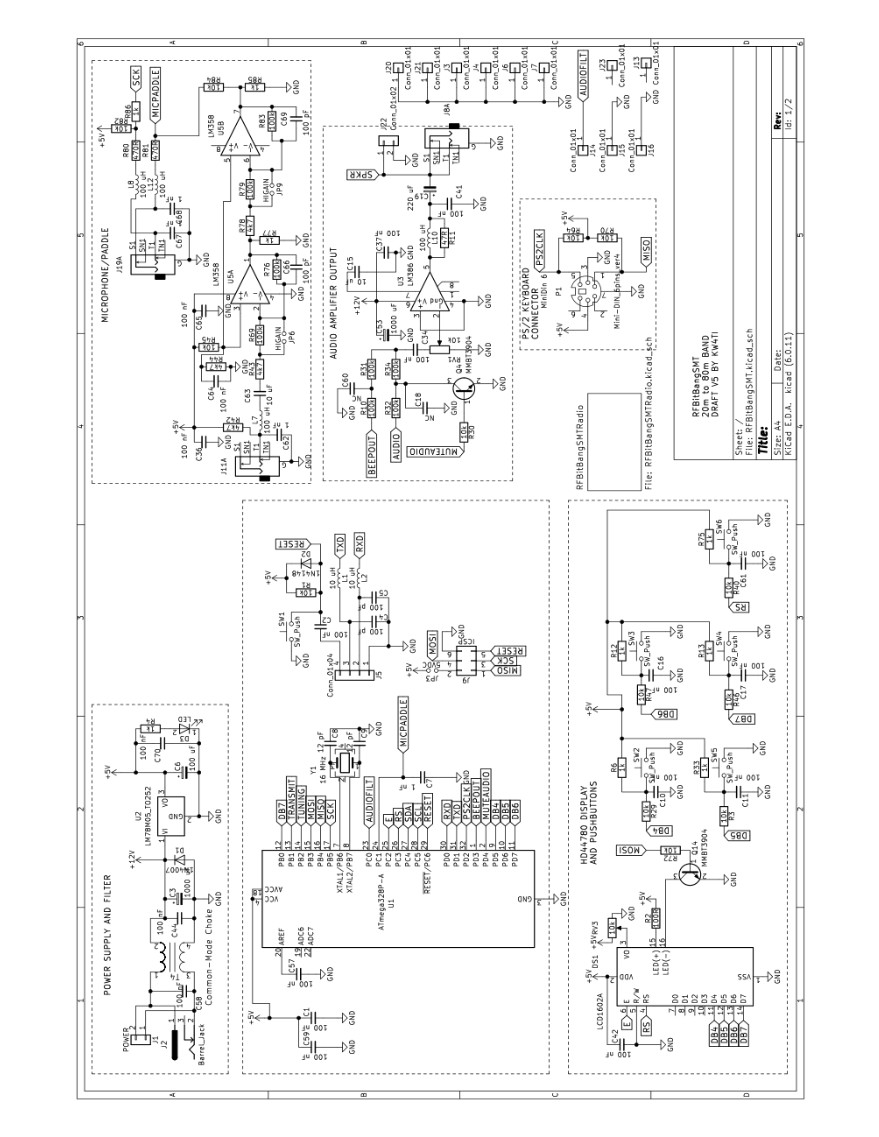
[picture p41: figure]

54

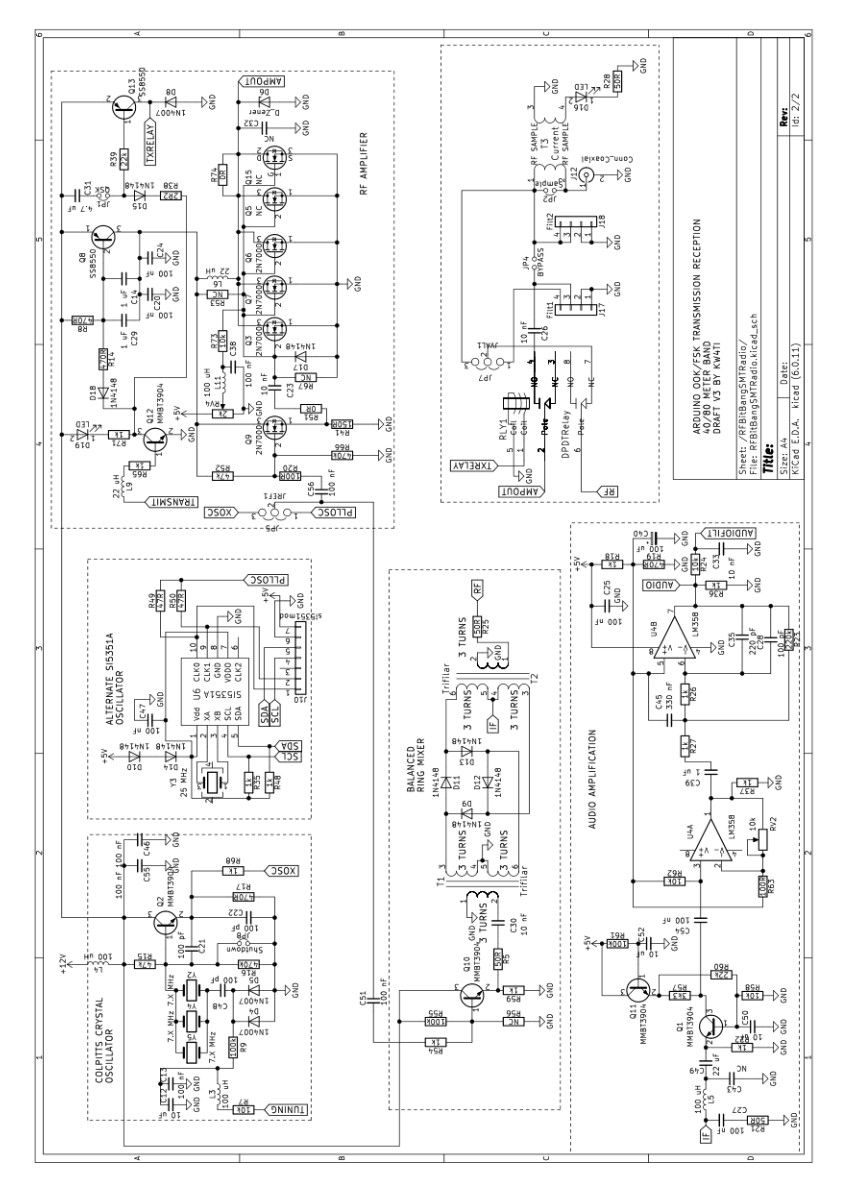
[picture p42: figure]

55

## Arduino Uno/Nano equivalent pins to ATMEGA328P

If one constructs the transceiver using an Arduino Uno/Nano and point-to-point wiring, here is the correspondence between the Arduino Uno/Nano pins and the ATMEGA328P pins:

PD0 | 2 | Digital Pin 0
PD1 | 3 | Digital Pin 1
PD2 | 4 | Digital Pin 2
PD3 | 5 | Digital Pin 3
PD4 | 6 | Digital Pin 4
PD5 | 11 | Digital Pin 5
PD6 | 12 | Digital Pin 6
PD7 | 13 | Digital Pin 7
PB0 | 14 | Digital Pin 8
PB1 | 15 | Digital Pin 9
PB2 | 16 | Digital Pin 10
PB3 | 17 | Digital Pin 11
PB4 | 18 | Digital Pin 12
PB5 | 19 | Digital Pin 13
PC0 | 23 | Analog Input 0
PC1 | 24 | Analog Input 1
PC2 | 25 | Analog Input 2
PC3 | 26 | Analog Input 3
PC4 | 27 | Analog Input 4
PC5 | 28 | Analog Input 5
PC6 | 1 | Reset
AREF | 21 | Analog Reference (Leave Open)
AVCC | 20 | Analog Voltage (Connect to +5V)
VCC | 7 | LM7805 5V output
GND | 8,22 GND

## Programming the ATMEGA328P/Arduino

The RFBitBanger software has been created to be compiled in the Arduino IDE environment with the Arduino Uno/Nano as a target. The ATMEGA328P operates at a frequency and with fuse bits identical to the standard Arduino Uno/Nano configuration. The Arduino bootloader may be flashed onto the ATMEGA328P. To do this, a ISP programmer such as the ArduinoISP or ATTinyUSB may be connected to the ICSP connector and the “Burn Bootloader” may be invoked in the Arduino development environment with the “Arduino Uno” or “Arduino Nano” selected as the target / board.

| | 56

This programs the bootloader and the correct fuse bits for operation of the ATMEGA328P with the RFBitBanger software.
A serial/TTL USB interface (e.g. CP2102 or CH340) may be used to program the ATMEGA328P once the bootloader is installed. The four pin header J5 has a ground pin, RX, TX, and DTR/reset pins. The ground on the RFBitBanger should be connected to the serial programmer ground, the RX pin on the RFBitBanger should be connected to the TX pin on the serial programmer, the TX pin on the RFBitBanger should be connected to the RX pin on the serial programmer, and the DTR pin should be connected to the DTR pin on the serial programmer. Once these are connected, the RFBitBanger can be programmed using the Upload Sketch function of the Arduino IDE. The RFBitBanger needs to be powered on to be programmed. The serial programmer should be able to reset the ATMEGA328P through the DTR pin to invoke the bootloader, but if it fails to do so, holding down the reset button on the RFBitBanger after invoking the Upload Sketch function and releasing it when it starts to attempt to upload usually allows successful contact with the bootloader.

57

## Hardware and Software Licenses

Hardware is licensed under the Creative Commons, Share-Alike, Attribution 4.0 license (CC-BY-SA 4.0).
Software is licensed under the zlib license:

/*
* Copyright (c) 2021 Daniel Marks

This software is provided 'as-is', without any express or implied warranty. In no event will the authors be held liable for any damages arising from the use of this software.

Permission is granted to anyone to use this software for any purpose, including commercial applications, and to alter it and redistribute it freely, subject to the following restrictions:

1. The origin of this software must not be misrepresented; you must not claim that you wrote the original software. If you use this software in a product, an acknowledgment in the product documentation would be appreciated but is not required.
2. Altered source versions must be plainly marked as such, and must not be misrepresented as being the original software.
3. This notice may not be removed or altered from any source distribution. */

58

## Alphabetical Index

2N7000 | 2, 21
AM broadcasts | 20
Amateur radio | 1, 10
Antenna | 5, 15ff., 23
Arduino | 2, 41f.
ATMEGA328P | 2, 36, 41f.
Balun | 22, 36
Band change warning | 10, 13
Bandpass module | 3, 5f., 15
Bifilar | 22
Bill of Materials | 31, 39
BS170 | 2, 21
Calibrating the crystal oscillator frequency | 14
Coaxial | 16, 33
Common-Mode Choke | 22, 36
Configuration | 11f., 41
Current sampling transformer | 22
CW | 2f., 7ff., 11ff., 18
EEPROM | 12, 14
Emergency Communications Frequencies | 19
External control mode | 3, 11ff.
Frequency band | 3, 5, 10, 15, 18
FT8 | 2f., 11
Jumpers | 23

59

Keyer | 3, 6, 11, 13
Keying mode | 8, 11, 17
LCD | 7
License | 1, 43
LM358 | 2, 36, 40
LM386 | 2, 36
PCB Layout | 28, 37
Potentiometers | 3, 21, 23
PS/2 keyboard | 3, 6f., 10
Pulled crystal | 21, 23
QSK | 3, 23, 33
Receive | 9, 11
Ribbon cable | 5, 24
RIT | 12f.
RTTY | 2f., 8f., 12, 18
SCAMP | 2f., 8f., 12
Scanning for a signal | 8
Schematic | 21, 28, 37
Serial resonant bandpass filters | 24f.
Shortwave stations | 20
SI5351A | 2, 13, 21, 23, 36
Signal strength | 3, 7f., 14
Speaker | 3, 6, 8, 12ff., 33, 36, 39
Transmit | 1, 9ff., 17
Trifilar | 22, 36
VFO | 7, 9, 11ff., 21

60

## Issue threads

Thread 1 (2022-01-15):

RFBitBanger

gdelpech, 2022-01-15:
Hello Daniel

I have order the PCB from JLCPCB.
But I have the old versions. Does the project still have to move or is it already a stable version?
I am interested in the project because I am part of the emergency network in France.
We train to make transmissions in MFSK64 or 128 with FLDIGI.

73 QRO Gilles F1BFU  ADRASSEC 79/FNRASEC

profdc9, 2022-01-16:
I'm still working on it... please don't order it yet!  It's very much a
word in progress.  I would be happy to accept any help  to develop it.  I
just started it recently and got the hardware working.  I am preparing the
next version which fixes a lot of stuff.

The radio is optimized to actually send/receive low bandwidth protocols
directly with the arduino, not requiring a computer.  It will support
CW/RTTY and a new mode I am designing called SCAMP directly on the radio
itself.  The requirement to implement the digital signal processing
directly on the Arduino results in some limitations of the protocols that
can be implemented.  But I'm always open to having my expectations
surpassed.

Dan

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

fermino, 2023-08-20:
Hi! I'm super interested in the project! What is the status of it? Is there any help needed? Thanks! :)

profdc9, 2023-08-21:
You might consider joining the slack channel at the Open Research Institute
( http://www.openresearch.institute ).  It is currently being offered as a
kit by them for a donation.

https://www.openresearch.institute/2023/08/08/rfbitbanger-kit-defcon31-show-special/

I am working on getting the project into the hands of those who have
ordered the kit.  I hope they will help provide feedback on the transceiver
and help improve it.  My main interest right now is to finalize the feature
set and make the radio software and hardware robust.  So if you can get
your hands on a radio, whether you order it or build it yourself, using the
radio and SCAMP and providing feedback would be valuable.

73,
Dan
KW4TI

On Sun, Aug 20, 2023 at 6:21 PM Fermín Olaiz ***@***.***>
wrote:

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

profdc9, 2023-08-21:
You can send an email to

***@***.***

to joint the slack channel.

On Sun, Aug 20, 2023 at 6:21 PM Fermín Olaiz ***@***.***>
wrote:

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

hello42world, 2023-08-24:
Question from a passerby: What would be the approximate range of this device when working in this text transmission SCAMP mode?

profdc9, 2023-08-24:
Well, not to be evasive, but it depends a lot on band conditions.  If we
relate it to similar modes like FT8, then probably on the order of hundreds
to thousands of km.  The distance can depend very strongly on the time of
the day and the state of the ionosphere between two stations.  For a mode
like FT8, often the goal is to make contacts, but not contacts in specific
places at specific times, and SCAMP like FT8 should be able to accomplish
that.  If your goal is to reliably establish a connection between two
particular stations at any time, this requires selecting a suitable band
(especially given the time of day and season) and above all having a
matched antenna as high as you can get it.

On Thu, Aug 24, 2023 at 12:42 PM hello42world ***@***.***>
wrote:

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

profdc9, 2023-08-24:
You should look up NVIS (Near Vertical Incident Skywave) for the kind of
propagation suitable to your application.

On Thu, Aug 24, 2023 at 1:37 PM hello42world ***@***.***>
wrote:

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

FK8IH, 2024-03-30:
With my Hermes Lite 2 and an EFHW antenna I realized 15,000KM range QSO using FT8 mode on frequencies well fitted to the conditions of the day, currently high HF like 15 or 10M bands. No doubt a RFBitBanger can do marvels with SCAMP mode.

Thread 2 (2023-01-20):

Pi pico viability?

jdude104, 2023-01-20:
Would the Arduino component be able to be easily replaced with a pico as the target board? Well the atmel chip is good for a SHTF scenario, in the current global climate it's much easier to get a bulk amount of picos, so being able to use one in place would increase the usability.

profdc9, 2023-01-20:
I seriously looked into this, however, the ADC bug on the current Pico is
going to compromise the sensitivity of the receiver by probably 10 dB at
least.  It would be a much superior chip to use in many ways, and if this
bug did not exist in the current silicon, would be a viable target.

https://electronics.stackexchange.com/questions/613537/how-is-this-peak-dnl-error-in-rp2040-adc-realised-in-actual-use
https://forums.raspberrypi.com/viewtopic.php?t=323704

That said, it may be worth pursuing now in anticipation it will be fixed at
a later date.

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

kholia, 2024-08-30:
Pico 2 has fixed this ADC bug and should be available widely in next 4 to 6 weeks.

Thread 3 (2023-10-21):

Can't get FT8 working correctly.

larryl719, 2023-10-21:
Hi,

First, I'd like to say Thanks!  This is a very interesting radio and was easy to assemble and play with.  I have built a full set of band boards and am starting to put it to use.

Maybe I'm missing something (that would be great!) but when I'm trying to get it to operate on FT8, I see a couple of things happening:
1. I need to use EXT mode to control the transceiver and it says it is the way to do it.
    When I enter EXT mode and the words "EXT Mode" appear and then go away, I can hear the frequency of the receiver shifting.  My measurements seem to indicate a move of about 700Hz.  If I keep the radio tuned to 14.074, my audio output ends up 700Hz too high, and in many cases, it's above the audio passband of the signal so that no one can hear me.  Tuning lower might be the answer but then there appears to be another issue. (below)
    When exiting EXT mode, the frequency returns to the original value.  I only really figured this out by using another radio to monitor my transmission and see that my signal was above the audio passband used for FT8.

2. When transmitting FT8 signals in EXT mode (and possibly shifting the frequency), I notice that it sounds "choppy" with some additional "artifacts" on the signal; normal FT8 signals tend to sound very smooth.  When I use "Tune" mode in WSJTX, the signal is very clean and sounds normal.  (My X6100 shows the audio spectrum on the display and there are "lobes" at lower amplitude under the main signal.  Also, the signal sounds very different on the X6100 than other FT8 signals.)

3. In the manual there are instructions (In the EXT mode description) to tune to the upper sideband (14.074) when doing FT8.  This is the normal way of doing FT8, so that's not unusual.  But, in looking at the code (and watching what happens), when EXT mode has been activated the mode is changed to CW and stays there.  While I don't think that is an issue exactly, I was wondering why change it and whether it might be related to the above problems in some way.
4. I'm sorry to say I haven't tested out the other modes like SCAMP or RTTY mostly because 10m is really open so far this year and I'm having a great time making QRP contacts on 10m all over the world.  That has also meant that I've spent a lot of time trying to get a bit more power out at 10m (with "normal" builds of the boards I'm getting about 0.5W out).  IF everything else was working well, I'd enjoy the challenge of the QRP contacts at 0.5W, but so far the issues above are keeping me from making contacts.

If there is anything I can do or try, please let me know, I'd be happy to help.  I haven't tried reprogramming the radio yet because I wanted to spend more time with the original design before I mess with it in any way.

Thanks again!
Larry, WB6JSO (wb6jso@hotmailDOTcom)

profdc9, 2023-10-21:
Here are a few hints:

1.  Make sure the output of your soundcard is turned up to maximum volume.
You may also want to fit a jumper onto JP6 (this will involve temporarily
removing the LCD).  The radio measures the audio frequency from the sound
card.  It can be a square wave, so it's ok to have it distorted.  It's not
like a normal transceiver where an overdriven input creates harmonics.
2.  The mode is not actually used in Ext mode, it is just set to CW to
force the SSB code to turn off.  The code below it takes control of the
frequenc
3.  When you are in CW mode, the BFO is set to 667 Hz below the selected
VFO frequency so that the CW creates a beat of 667 Hz (the sidetone
frequency).  So for example, if you tune 14074000 Hz, and you are in CW
mode, before the Ext mode is selected, you should hear a faint signal from
the BFO of 14074000 Hz - 667 Hz = 14073333 Hz.  Once the Ext mode is
selected, the BFO should be at 14074000 Hz.  That's why it is jumping up by
about 700 Hz.
4. When the soundcard sends a tone, for example 1.2 kHz, the radio should
transmit a frequency of 14074000 + 1200 Hz = 14075200 Hz.  If this is not
the case then there is something wrong.

Check these things and see if that helps.

73,
Dan
KW4TI

  When external control mode is selected, the BFO should increase to
2.  The operation in Ext mode doesn't depend on the selected mode.

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

larryl719, 2023-10-22:
I've gotten some pictures of the results...

With the RFBitBanger in EXT mode, tuned to 14074 and using WSJTX to "TUNE" at 2000 Hz (and later at 1000Hz), the signal received on the X6100 showed a strong signal at about 2700 Hz and at 1700 Hz.  BTW, the radio was in CW mode when I put it into EXT mode (I figured using SSB didn't make sense since it would change anyway.).  I'm wondering if the 667Hz is being added twice.  (or on top of the actual frequency)
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

I hope this helps,
Larry
WB6JSO

profdc9, 2023-10-22:
Just to be sure, are you using the latest build from the RFBitBanger code
repository?  If not, could you upload the new code and see if that helps?

73,
Dan
KW4TI

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

profdc9, 2023-10-22:
BTW, I tested the FT8 again yesterday on the RFBitBanger ext mode and I was
able to make 6 or 7 contacts on 20 meters, so I'm a little baffled as to
what's going on.

73,
Dan
KW4TI

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

profdc9, 2023-10-22:
Also, did you calibrate the frequency using WWV?  The instructions are in
the manual.  If not, since it's not using a TCXO, the frequency could be
off by as much as several hundred Hz.

73,
Dan
KW4TI

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
>>> I've gotten some pictures of the results...
>>>
>>> With the RFBitBanger in EXT mode, tuned to 14074 and using WSJTX to
>>> "TUNE" at 2000 Hz (and later at 1000Hz), the signal received on the X6100
>>> showed a strong signal at about 2700 Hz and at 1700 Hz. BTW, the radio was
>>> in CW mode when I put it into EXT mode (I figured using SSB didn't make
>>> sense since it would change anyway.). I'm wondering if the 667Hz is being
>>> added twice. (or on top of the actual frequency)
>>> [image: IMG_20231021_214236]
>>> <https://user-images.githubusercontent.com/36279690/277146385-8525e59c-be5d-4900-9f62-7af420862c35.jpg>
>>> [image: IMG_20231021_214151]
>>> <https://user-images.githubusercontent.com/36279690/277146435-5ec80a8e-7bc4-4688-96e1-c84c6b7a26fc.jpg>
>>> [image: vlcsnap-2023-10-21-22h24m32s605]
>>> <https://user-images.githubusercontent.com/36279690/277146879-accb60a3-781a-47e0-8304-ad51989efa27.png>
>>>
>>> I hope this helps,
>>> Larry
>>> WB6JSO
>>>
>>> —
>>> Reply to this email directly, view it on GitHub
>>> <https://github.com/profdc9/RFBitBanger/issues/3#issuecomment-1774000747>,
>>> or unsubscribe
>>> <https://github.com/notifications/unsubscribe-auth/AKFIJZBLHLQZK6B3HYXGB2LYASWC3AVCNFSM6AAAAAA6KH2CVSVHI2DSMVQWIX3LMV43OSLTON2WKQ3PNVWWK3TUHMYTONZUGAYDANZUG4>
>>> .
>>> You are receiving this because you commented.Message ID:
>>> ***@***.***>
>>>
>>

larryl719, 2023-10-22:
Thanks Dan,

I am running the code delivered with this first production run.  (1.0?)  I will take a look at the newer code and try that.  I am one of "those people" who often load the latest right away and I've had my share of bricking things, so I decided to hold back this time and test the actual release first.  (I have been itching to try reloading it... :-)

I did calibrate it once on WWV but wasn't confident that it had all come out right, so I backed it out.  My first attempt did give me something like 300Hz and, lacking confidence ( I get a fair amount of noise on WWV at times), I figured I'd see how things worked otherwise first.  I'll go redo that and try the later code.  I'll let you know what I find out.

The fact that it's working great for you makes me feel much more confident, thanks!

Larry
WB6JSO

larryl719, 2023-10-22:
Dan,

Success!  The issue was the calibration.  I redid it with WWV a couple of times but did have a lot of noise.  I finally realized that I could set the frequency to match what I wanted to see on 14.074 FT8 and then calibrate that.  I'm now within Hertz of where it needs to be.  My XTAL calibration is 25001602 Hz, so it was off a bunch.

I don't know if it can help anyone else, but what I did was:

1. Transmit on FT8, see (using my X6100) where it was "landing" in the passband in EXT mode  (which does shift the frequency) and WSJTX.
2. Adjust the frequency (down in this case) by the amount I was off in FRQ menu. (Goes back to CW frequency)
3. Repeat until I was close when transmitting.
4. In CFG, calibrate the XTAL to 14.074MHz (where it should have started).
5. Check it again, repeat if necessary.

I made three contacts on 20m at about 4W and 1 on 10m with 1.5W.

Now I can really play with it.

Thanks so much for your help,
Larry
WB6JSO

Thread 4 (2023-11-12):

Adjustments needed to support non-Arduino builds for SCAMP encode/decode

brucemack, 2023-11-12:
Issue created to track a few minor adjustments that will allow the SCAMP encode/decode to be built outside of the Arduino environment.

profdc9, 2023-11-18:
I pulled your request and merged it with the main line after a few modifications.  Please check it out and if its satisfactory, close the PR.

brucemack, 2023-11-21:
Looks good, many thanks!

Closed 2023-11-21.

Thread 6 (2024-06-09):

Manual errata: serial resonant bandpass filters component values

vk2tty, 2024-06-09:
TL;DR:
- 40m should read L2=0.58µH, L3=0.26µH not L2=0.77µH, L3=0.36µH
- 10m, 15m, 80m bands seem OK
- 80m C1=680pF mismatch batch 2 winding table C1=1000pF
- Remaining data might benefit from checking

G'day! I spotted a discrepancy in the band filter L2 and L3 columns while taking notes for a quick LCR check before soldering. Double-checking against [toroids.info](https://toroids.info/T50-6.php) for the 80m, 40m, 15m. and 10m bands found another typo. I haven't checked the others.

I also noticed the 80m C1 values didn't line up with the batch 2 builder's notes in OpenResearchInstitute/[RFBitBanger-kit](https://github.com/OpenResearchInstitute/RFBitBanger-kit) but don't know what to use as a tie-breaker.

While you're in there, tightening the C2+C3 column might let you widen L2 and L3 in turn making the table short enough to fit on the page with its header, which is currently widowed? Tiny nit-pick, I know.

73, VK2TTY

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

vk2tty, 2024-07-10:
G'day again! The manual's main PCB bill of materials gives 22µH for L6 and 100µH for L4.

The winding guide advises 12 turns on an FT37-43 for both, which toroids.info calculates as 50µH: half the manual's L6 inductance, and double the manual's L4 inductance. For what it's worth, both mine measured at 50µH with 12 turns.

Which of these figures should be corrected, and how?

gweep, 2025-05-19:
Hi vk2tty,   My 80m and 40m filters work well as-built to the batch-2 instructions.  I did have to play with the winding spacing to get a nice filter response.

My 20m filter (again built to batch-2 instructions) seems to be better suited for 17m with a peak around 18.1 MHz and a notch better suited for 20m (about 29MHz).

Double checked my parts count and it appears I used all the correct parts.

It looks like I am going to have to add turns to my 20m L2.   What is the source of your table above?  Not finding it in the Batch-2 docs.

Does anyone have a link to the design equations for the RFBB low pass output filters?  I am not finding a suitable reference.

Thanks,   (the slack message board is just a clutter of posts.  I find it hard to use.)

Mike

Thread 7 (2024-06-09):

Question on measuring the inductors

vk2tty, 2024-06-09:
Are there any calculators that take how much of the toroid is wound into account, or ways to measure them that'll give the values indicated in the calculators and table?

I thought I'd measure my inductors after I'd would them, hoping to avoid the (tr)uSDX tuning game of soldering, measuring, de-soldering, dropping a turn, lathering, rinsing, and repeating. Now I've done so, I regret I've got another mystery on my hands.

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

|turns|measured|calculated|
|-|-|-|
|4|0.13|0.06|
|5|0.23|0.10|
|7|0.35|0.20|
|8|0.38|0.26|
|12|0.89|0.58|
|13|1.07|0.68|
|15|1.44|0.90|
|16|1.59|1.02|
|17|1.72|1.16|
|18|1.96|1.30|
|19|2.10|1.44|

Measurements with Peak® atlas LCR45 at 200kHz, 15–19 turns using the 80m toroid dropping a turn at a time until I got within cooee of the required value. Calculations with [toroids.info](https://toroids.info/T50-6.php) at 0.2MHz.

vk2tty, 2024-07-22:
Belated update: after eventually trusting my LCR and VNA and dropping turns until the inductors measured within cooee, I confirmed correct resonance and suppression for the 10m band with my VNA.

Overall method might end up:

- Try the instructions‘ turn count
- Adjust spread and turn count until measurement OK
- THEN solder
- Short out the pi filter
- Adjust spread of serial resonance coil to move S11 resonance
- Remove short
- Adjust spread of pi filter coil to move notch on S21 log mag
- THEN plug into radio
- Check power and efficiency

I'll post turn counts and suggested amendments to the procedure when I've done the lot for 10m, 15m, 40m, and 80m.

If you're using batch 2 with the included wire, you might be able to save time in the second step by starting with fewer turns per my measurements above:

- Find the batch 2 winding guide turn count on the X axis
- Trace up until you hit the “calculated” line
- Trace left until you hit the “measured” line
- Trace down to the X axis for your adjusted starting turn count

If you've substituted your own wire, or your own toroids, try measuring from 19 turns down to 4 to make your own graph or lookup table.

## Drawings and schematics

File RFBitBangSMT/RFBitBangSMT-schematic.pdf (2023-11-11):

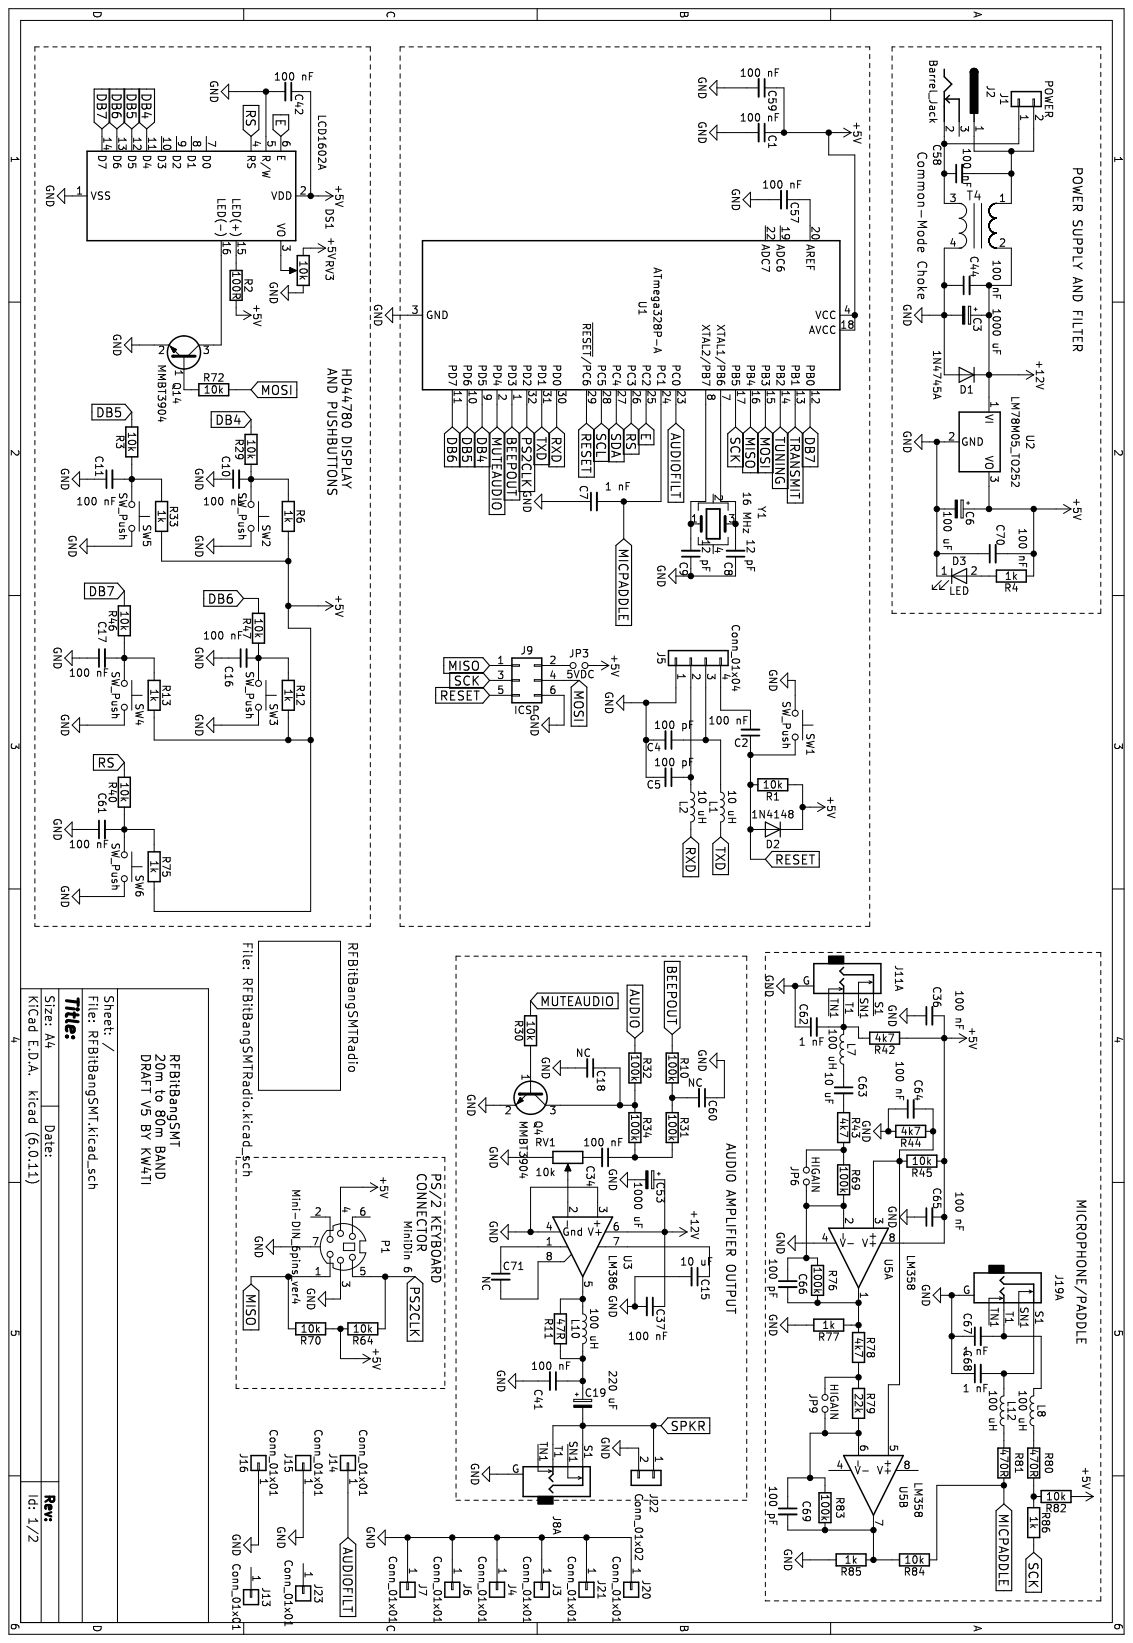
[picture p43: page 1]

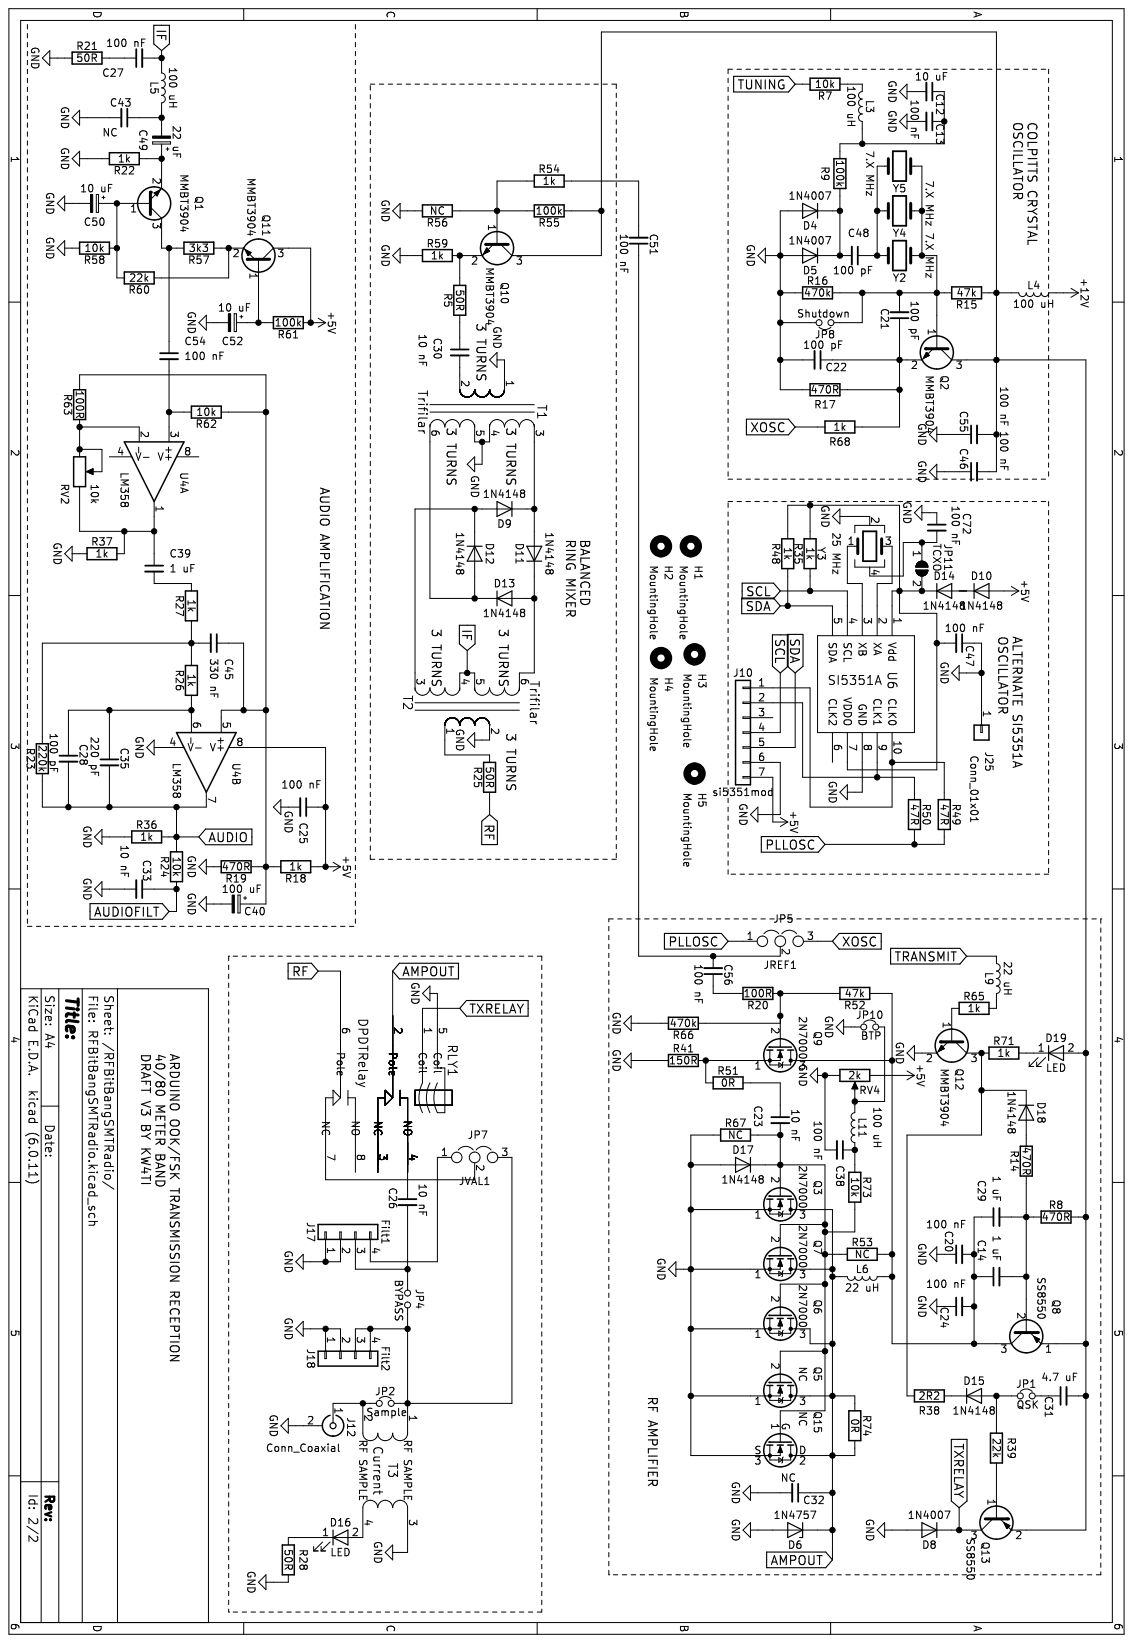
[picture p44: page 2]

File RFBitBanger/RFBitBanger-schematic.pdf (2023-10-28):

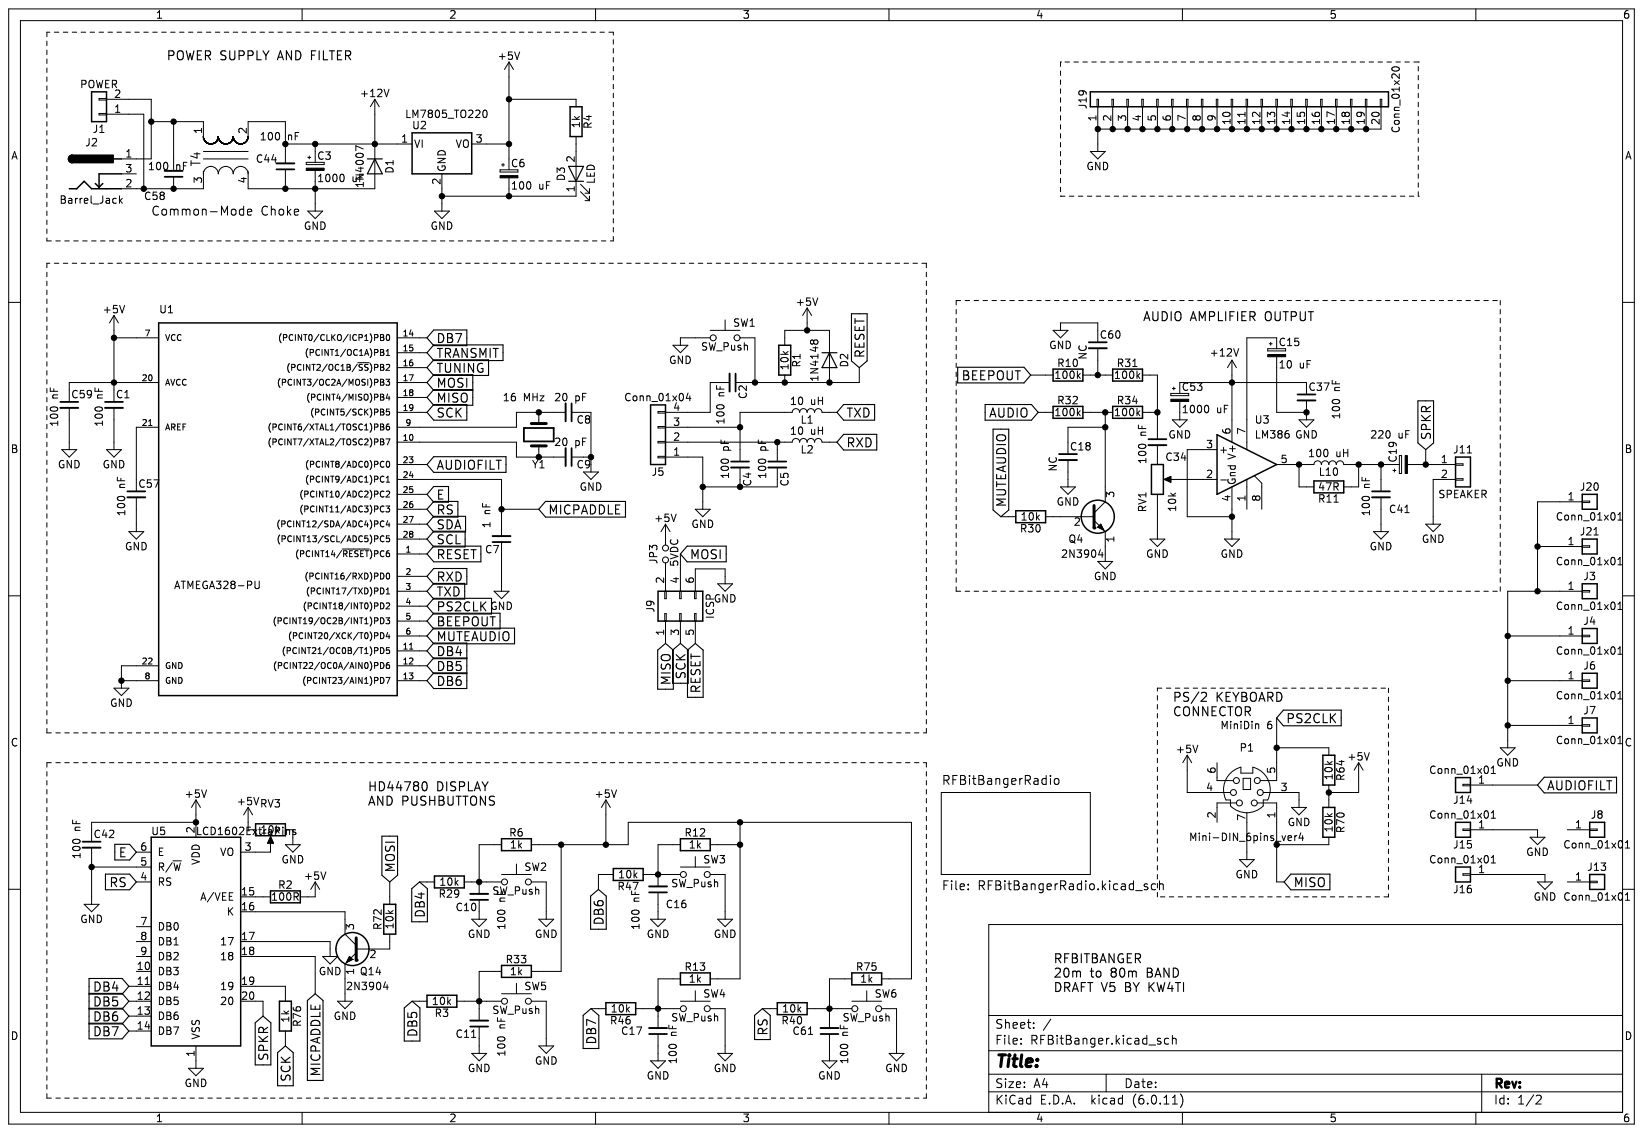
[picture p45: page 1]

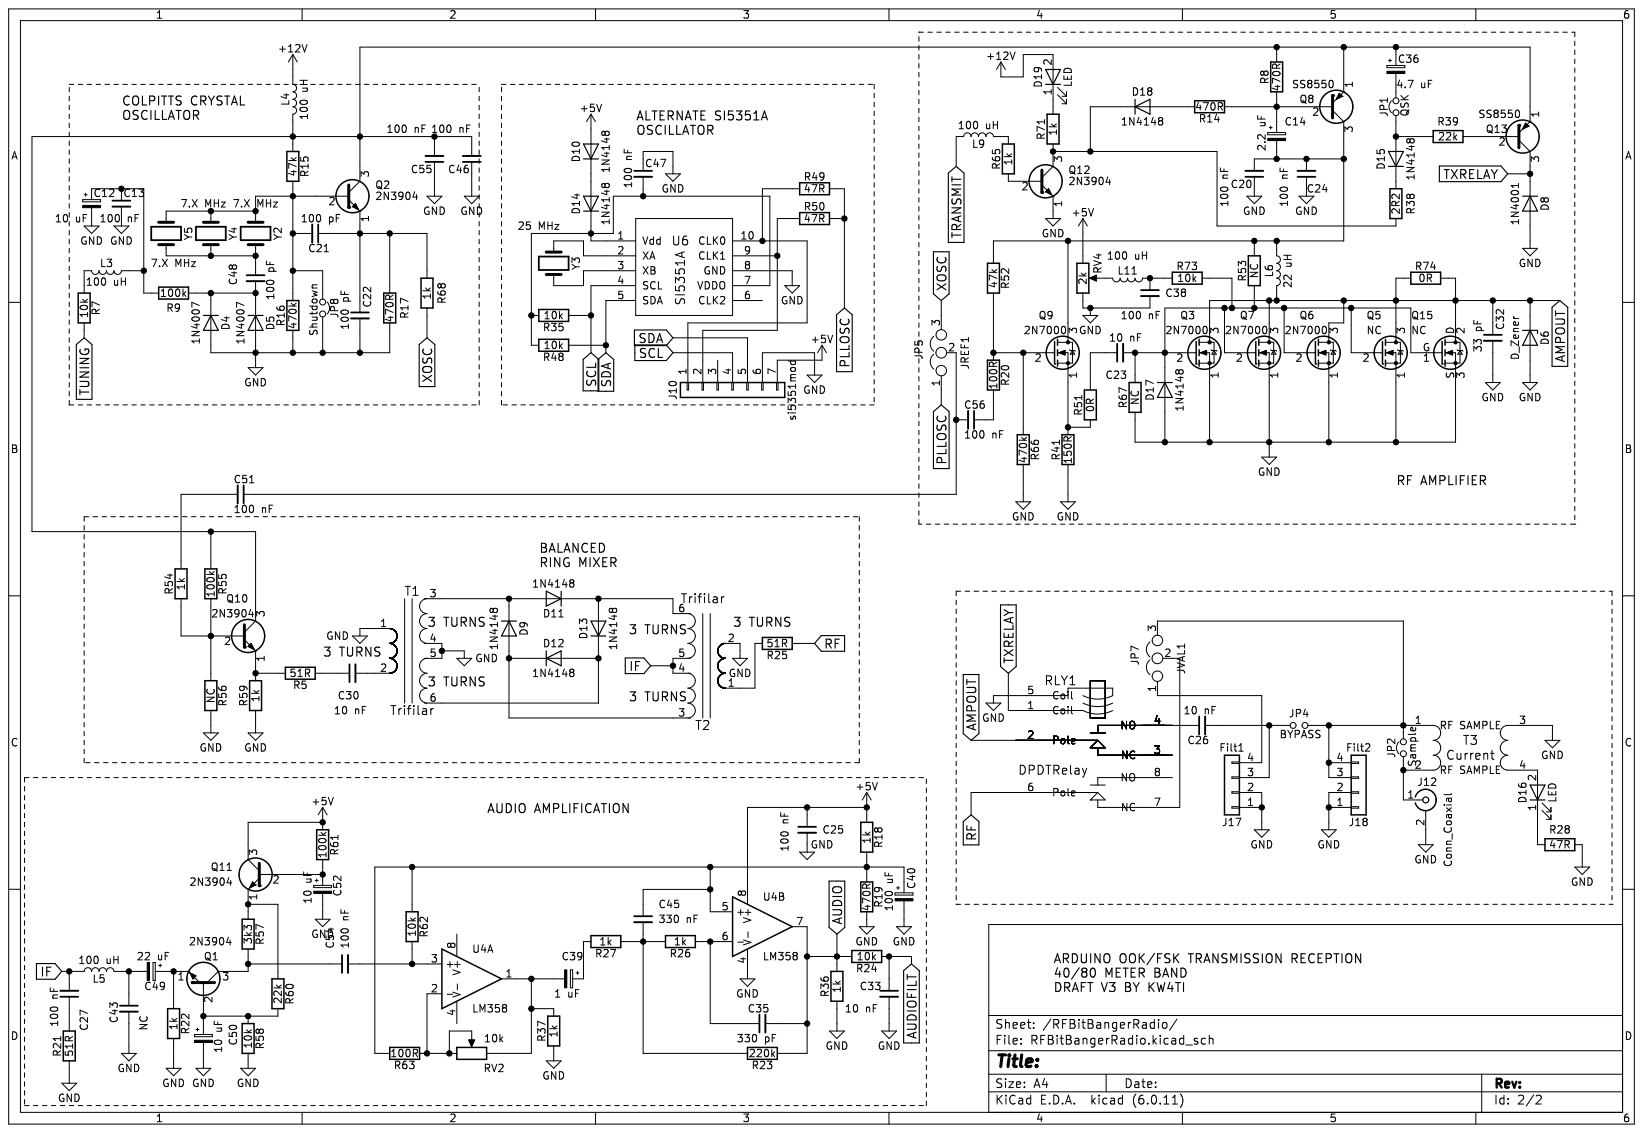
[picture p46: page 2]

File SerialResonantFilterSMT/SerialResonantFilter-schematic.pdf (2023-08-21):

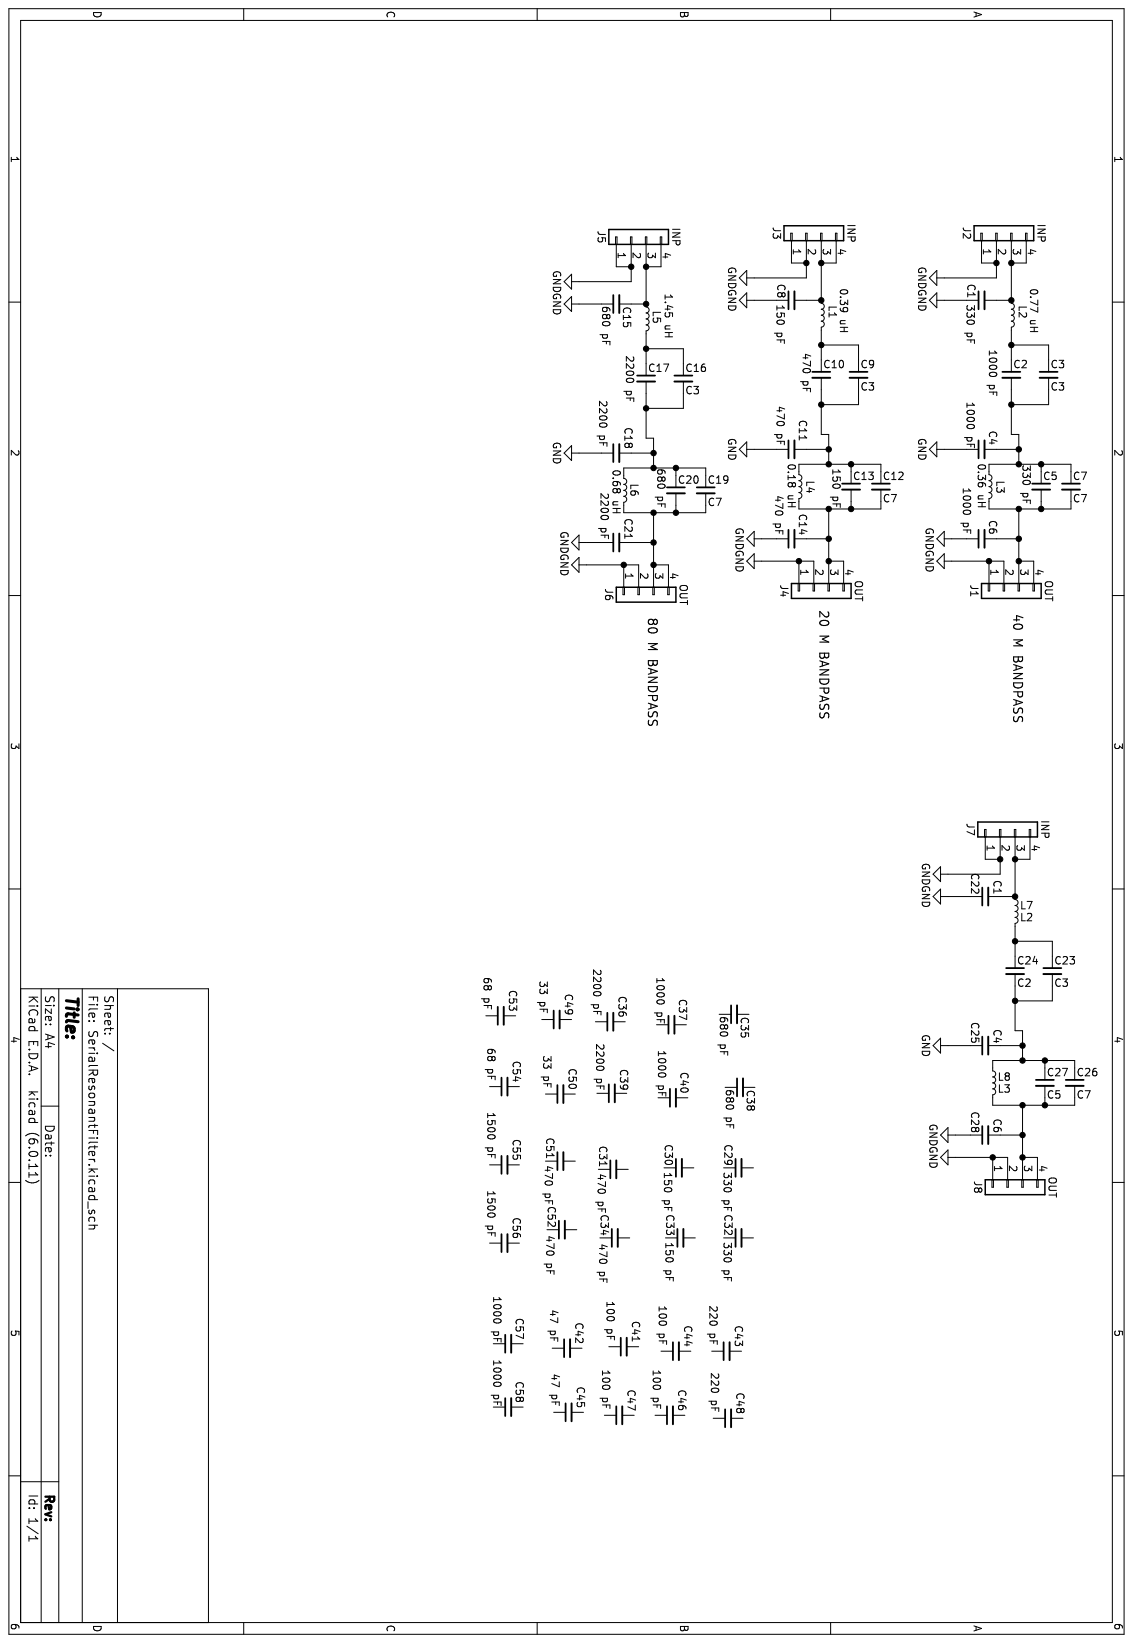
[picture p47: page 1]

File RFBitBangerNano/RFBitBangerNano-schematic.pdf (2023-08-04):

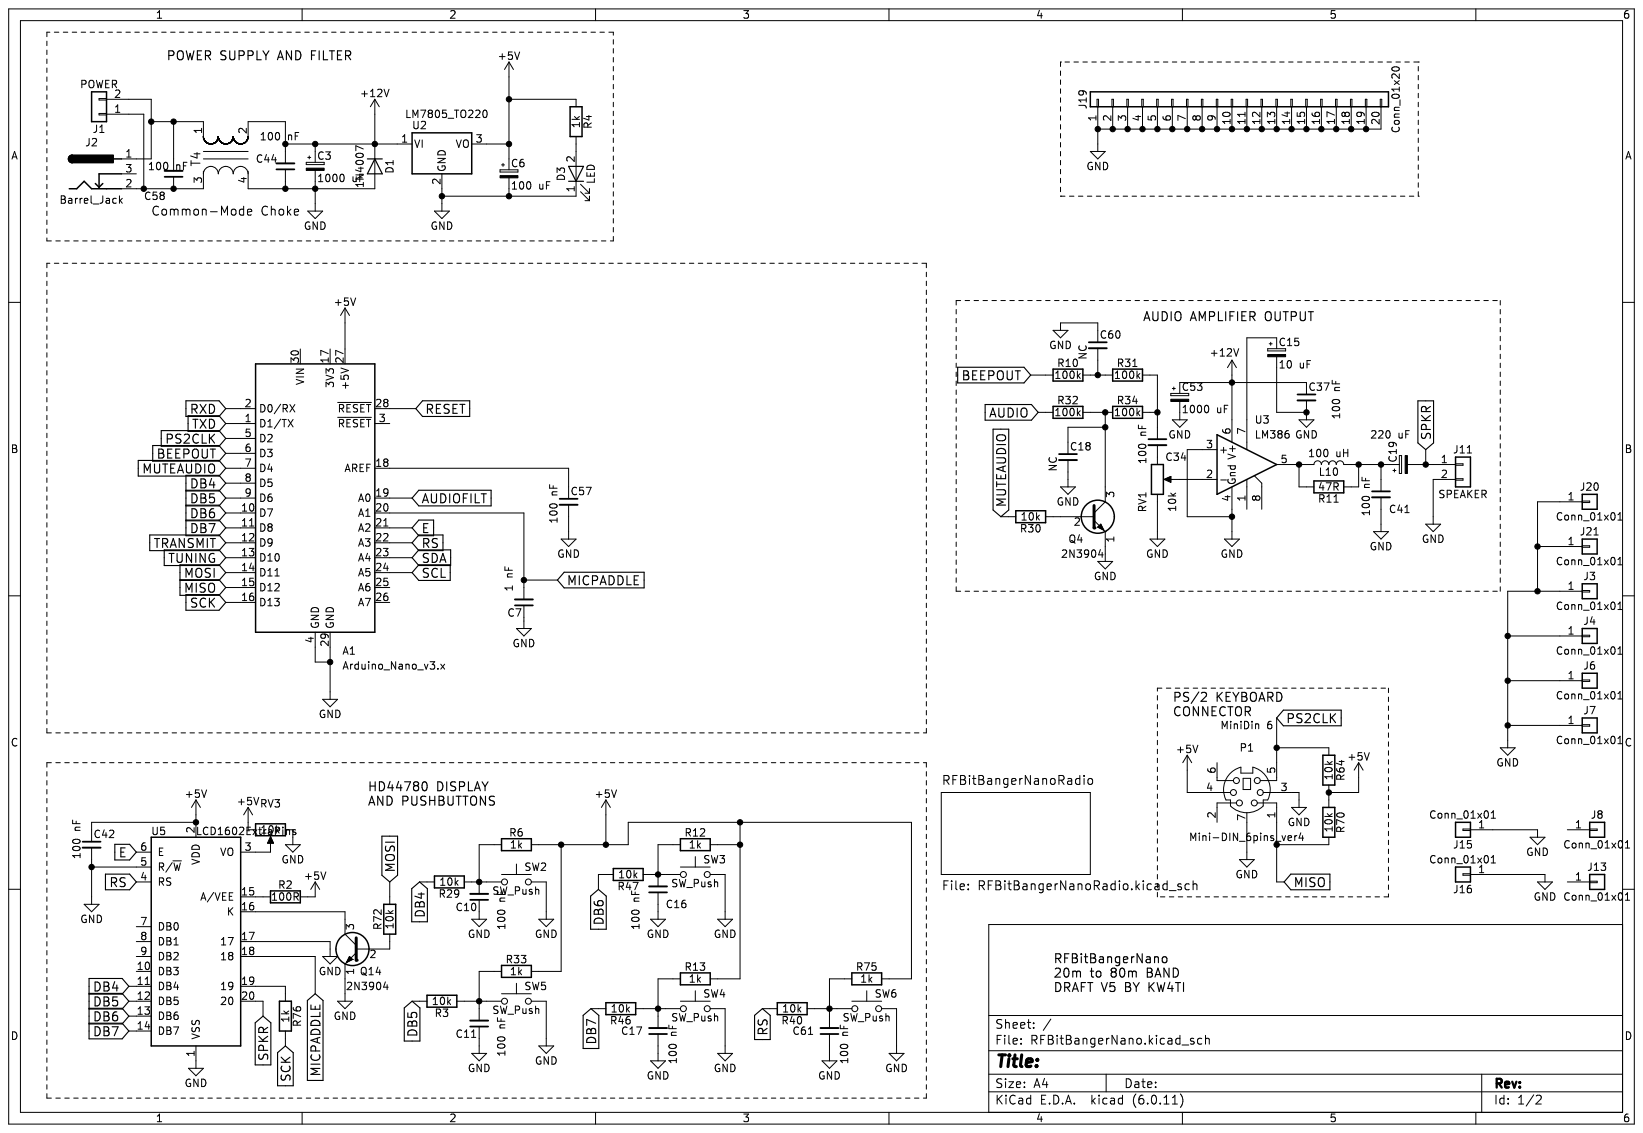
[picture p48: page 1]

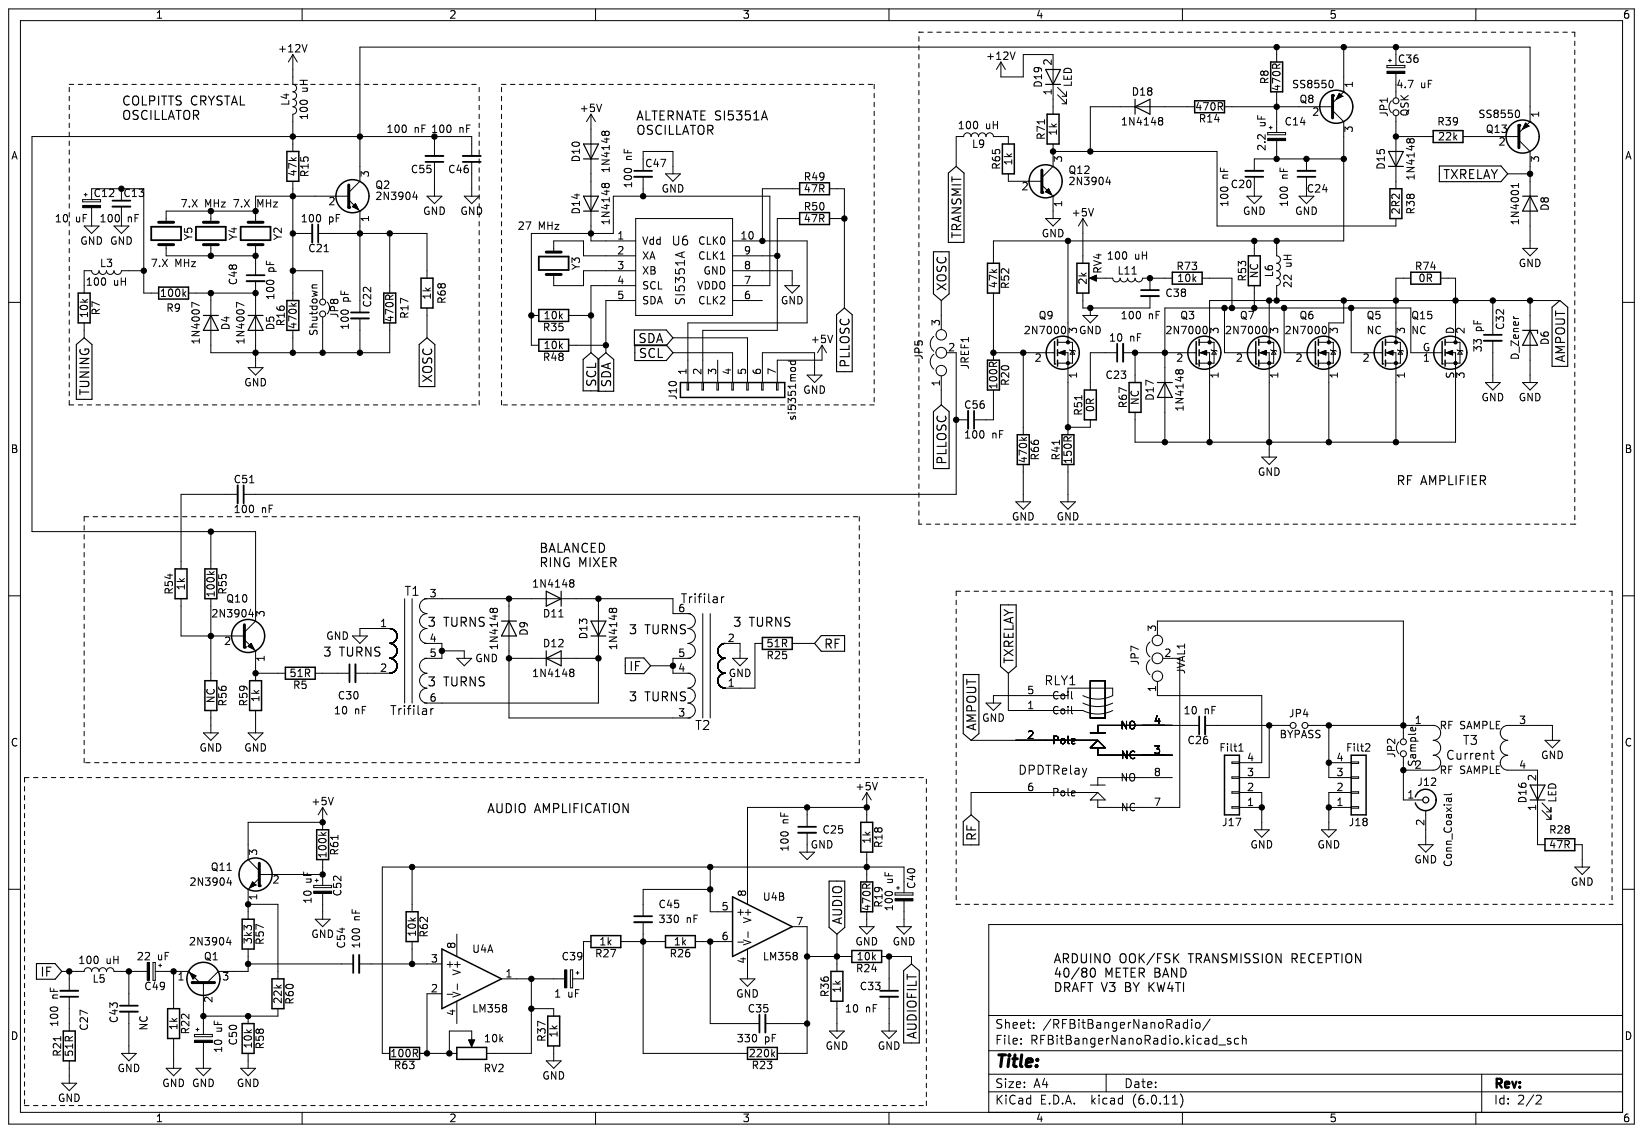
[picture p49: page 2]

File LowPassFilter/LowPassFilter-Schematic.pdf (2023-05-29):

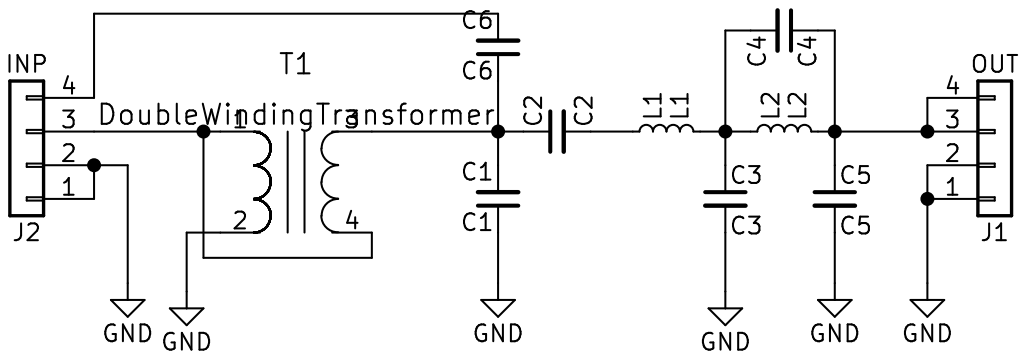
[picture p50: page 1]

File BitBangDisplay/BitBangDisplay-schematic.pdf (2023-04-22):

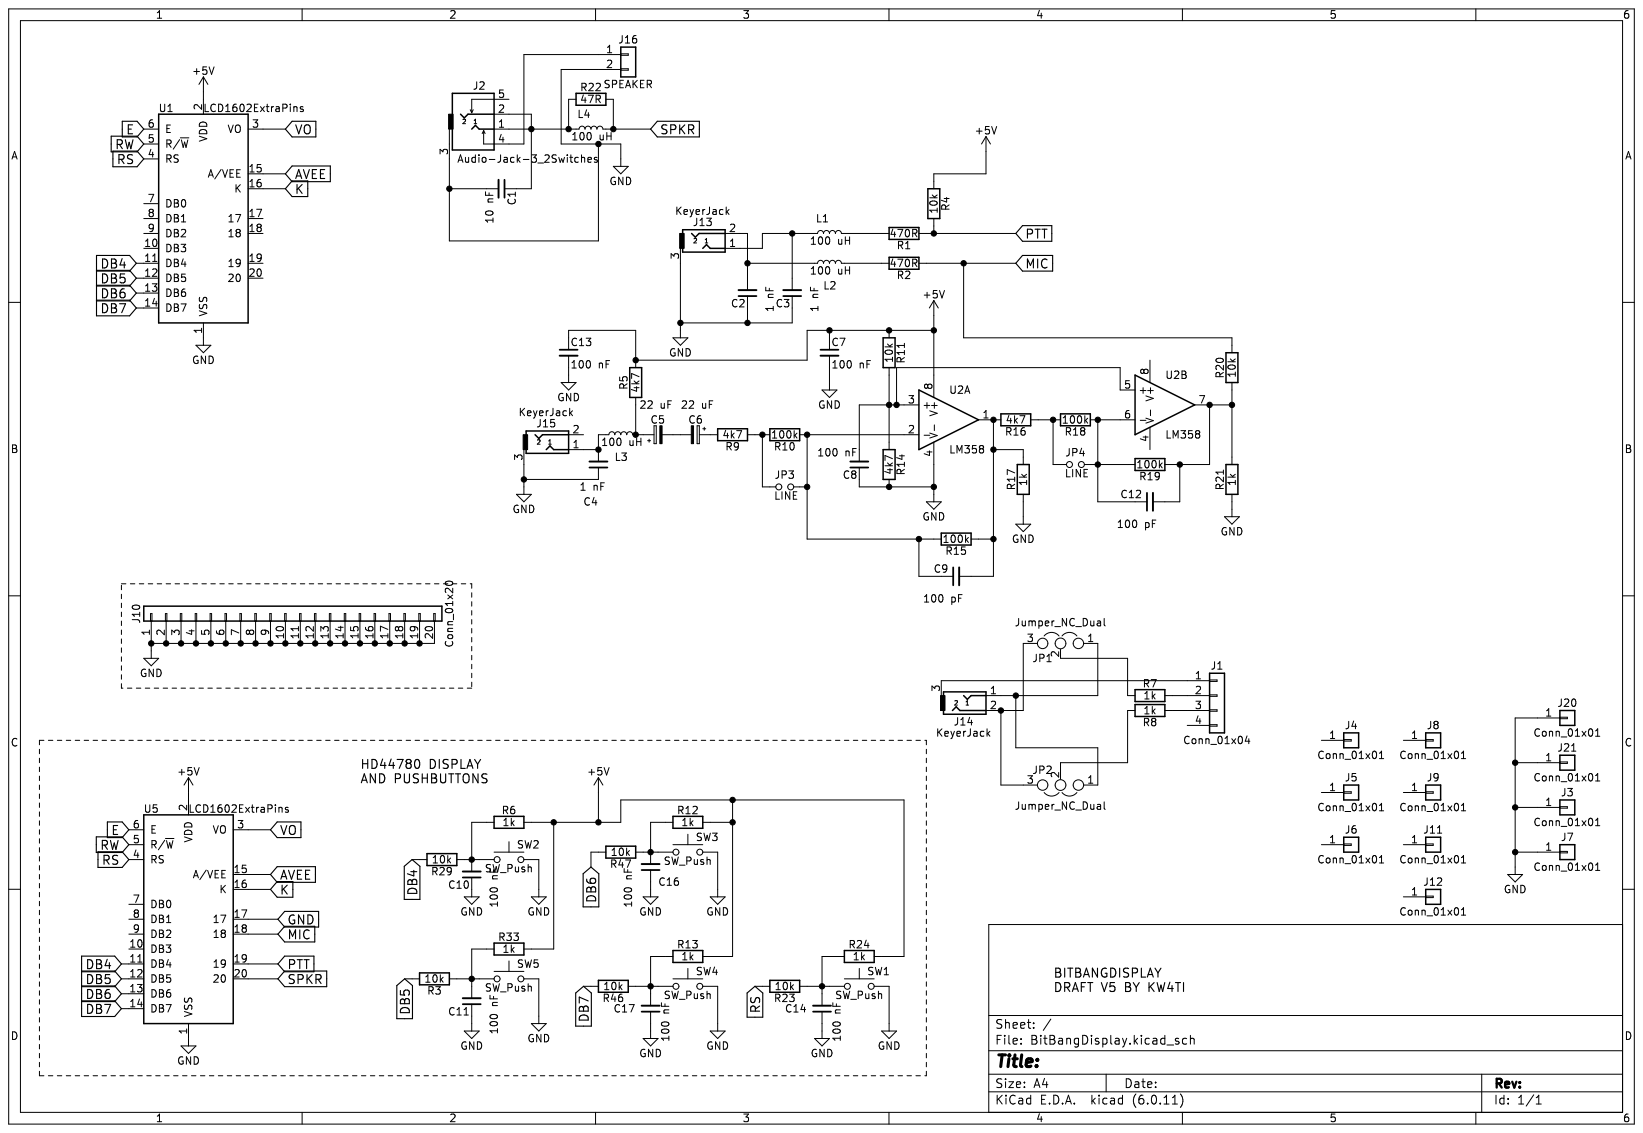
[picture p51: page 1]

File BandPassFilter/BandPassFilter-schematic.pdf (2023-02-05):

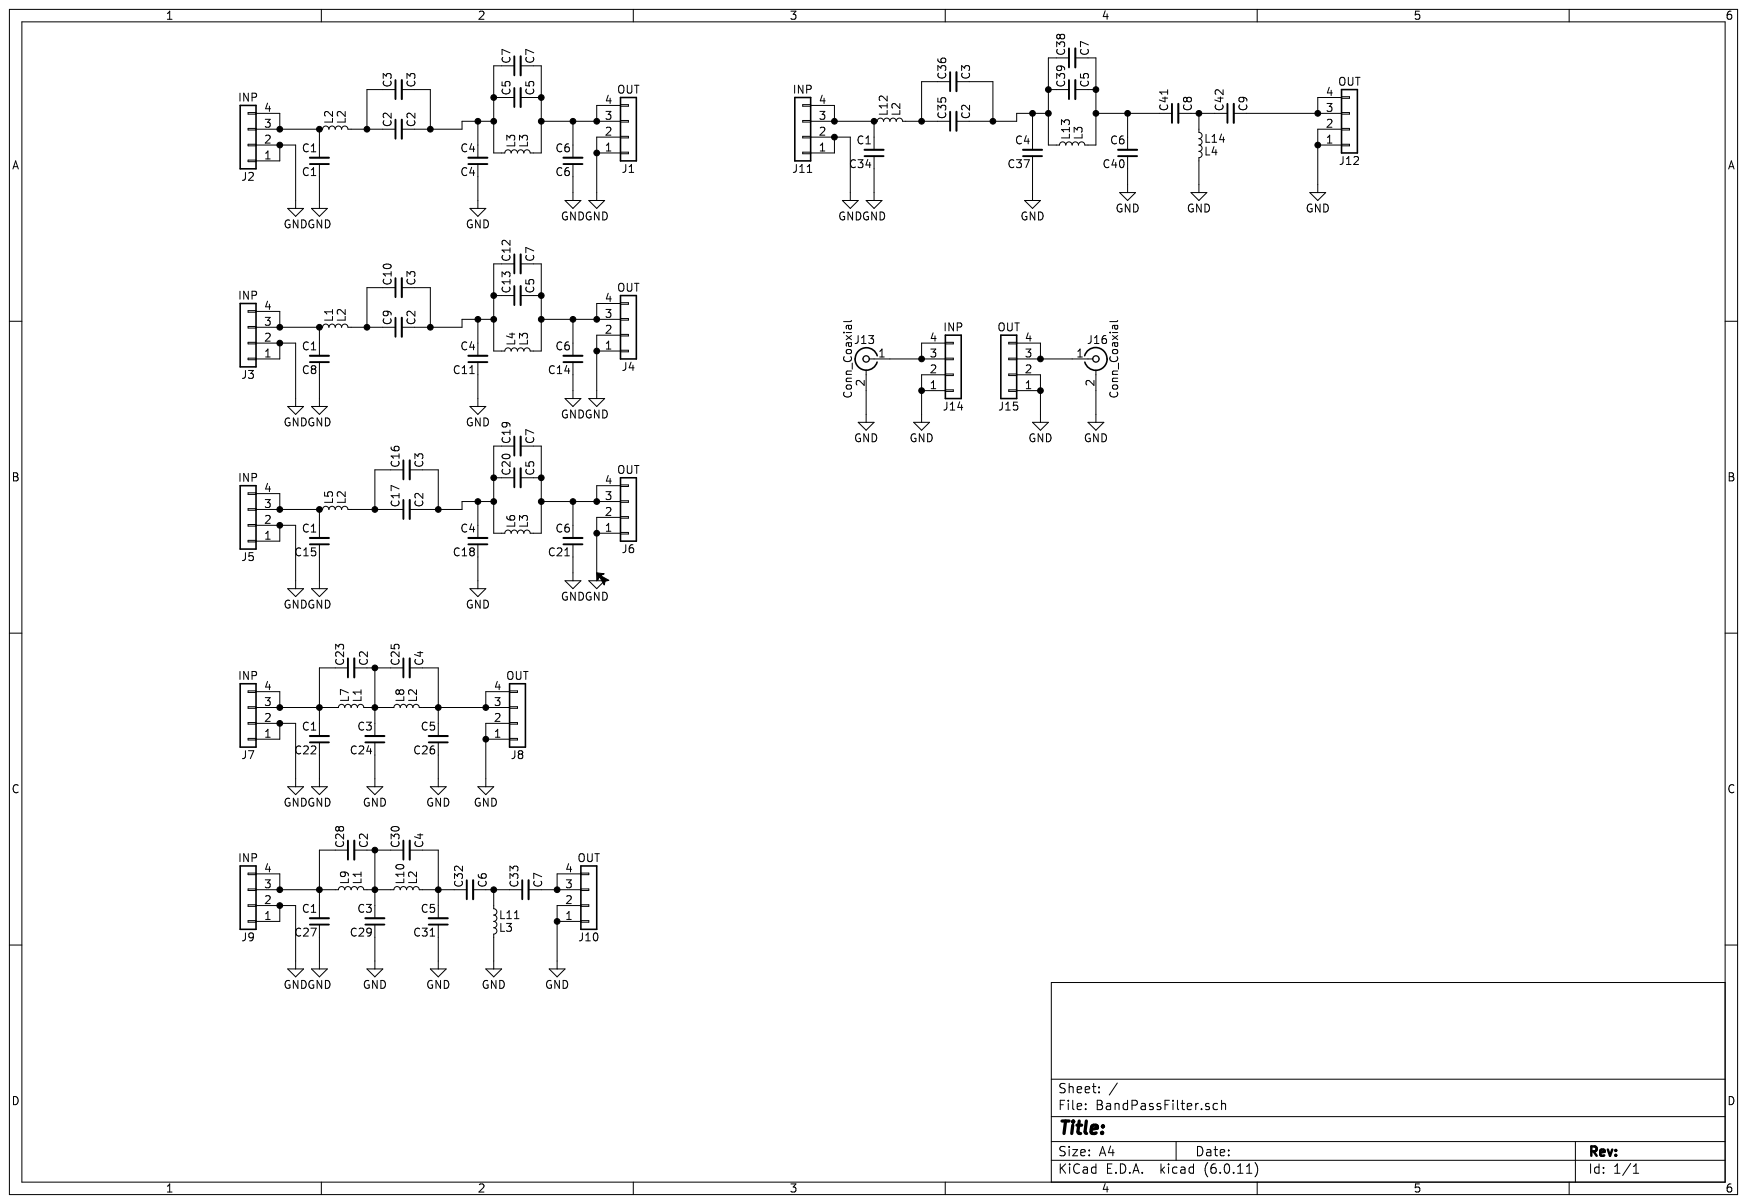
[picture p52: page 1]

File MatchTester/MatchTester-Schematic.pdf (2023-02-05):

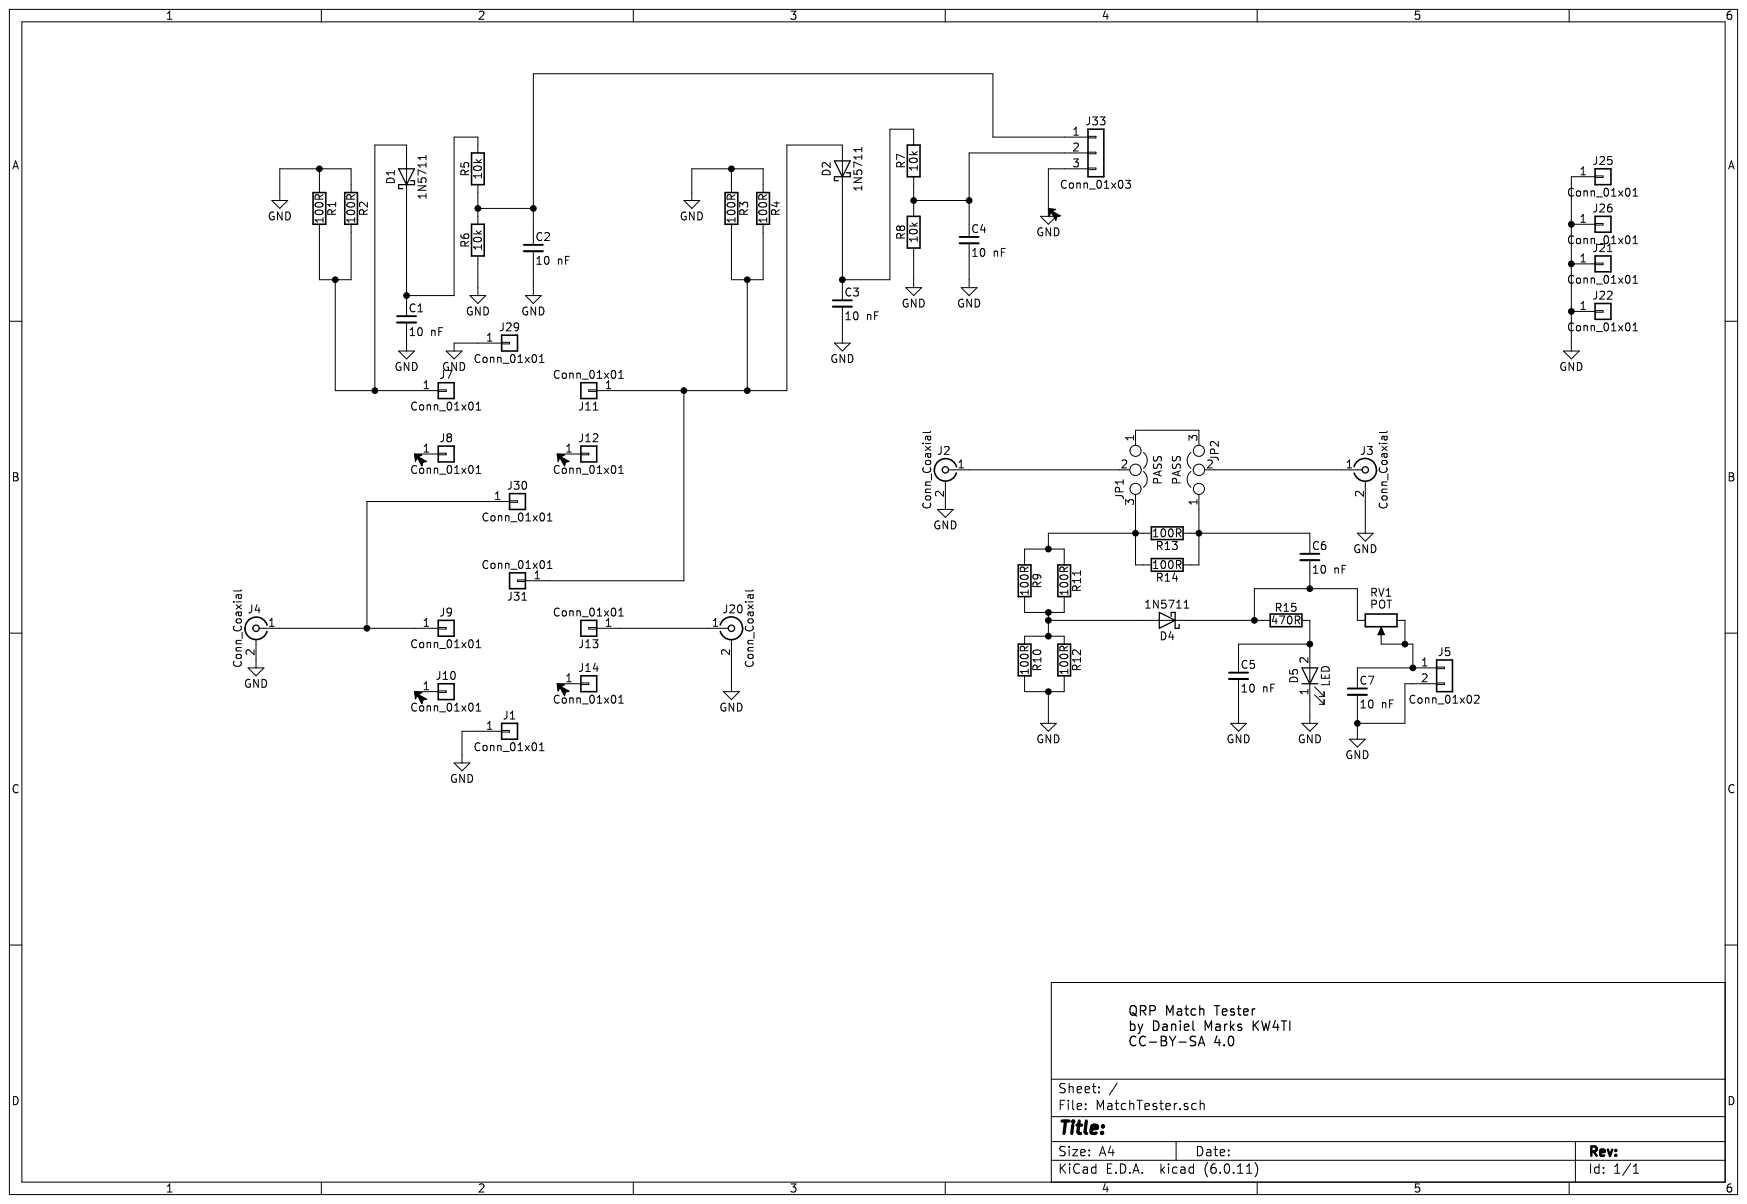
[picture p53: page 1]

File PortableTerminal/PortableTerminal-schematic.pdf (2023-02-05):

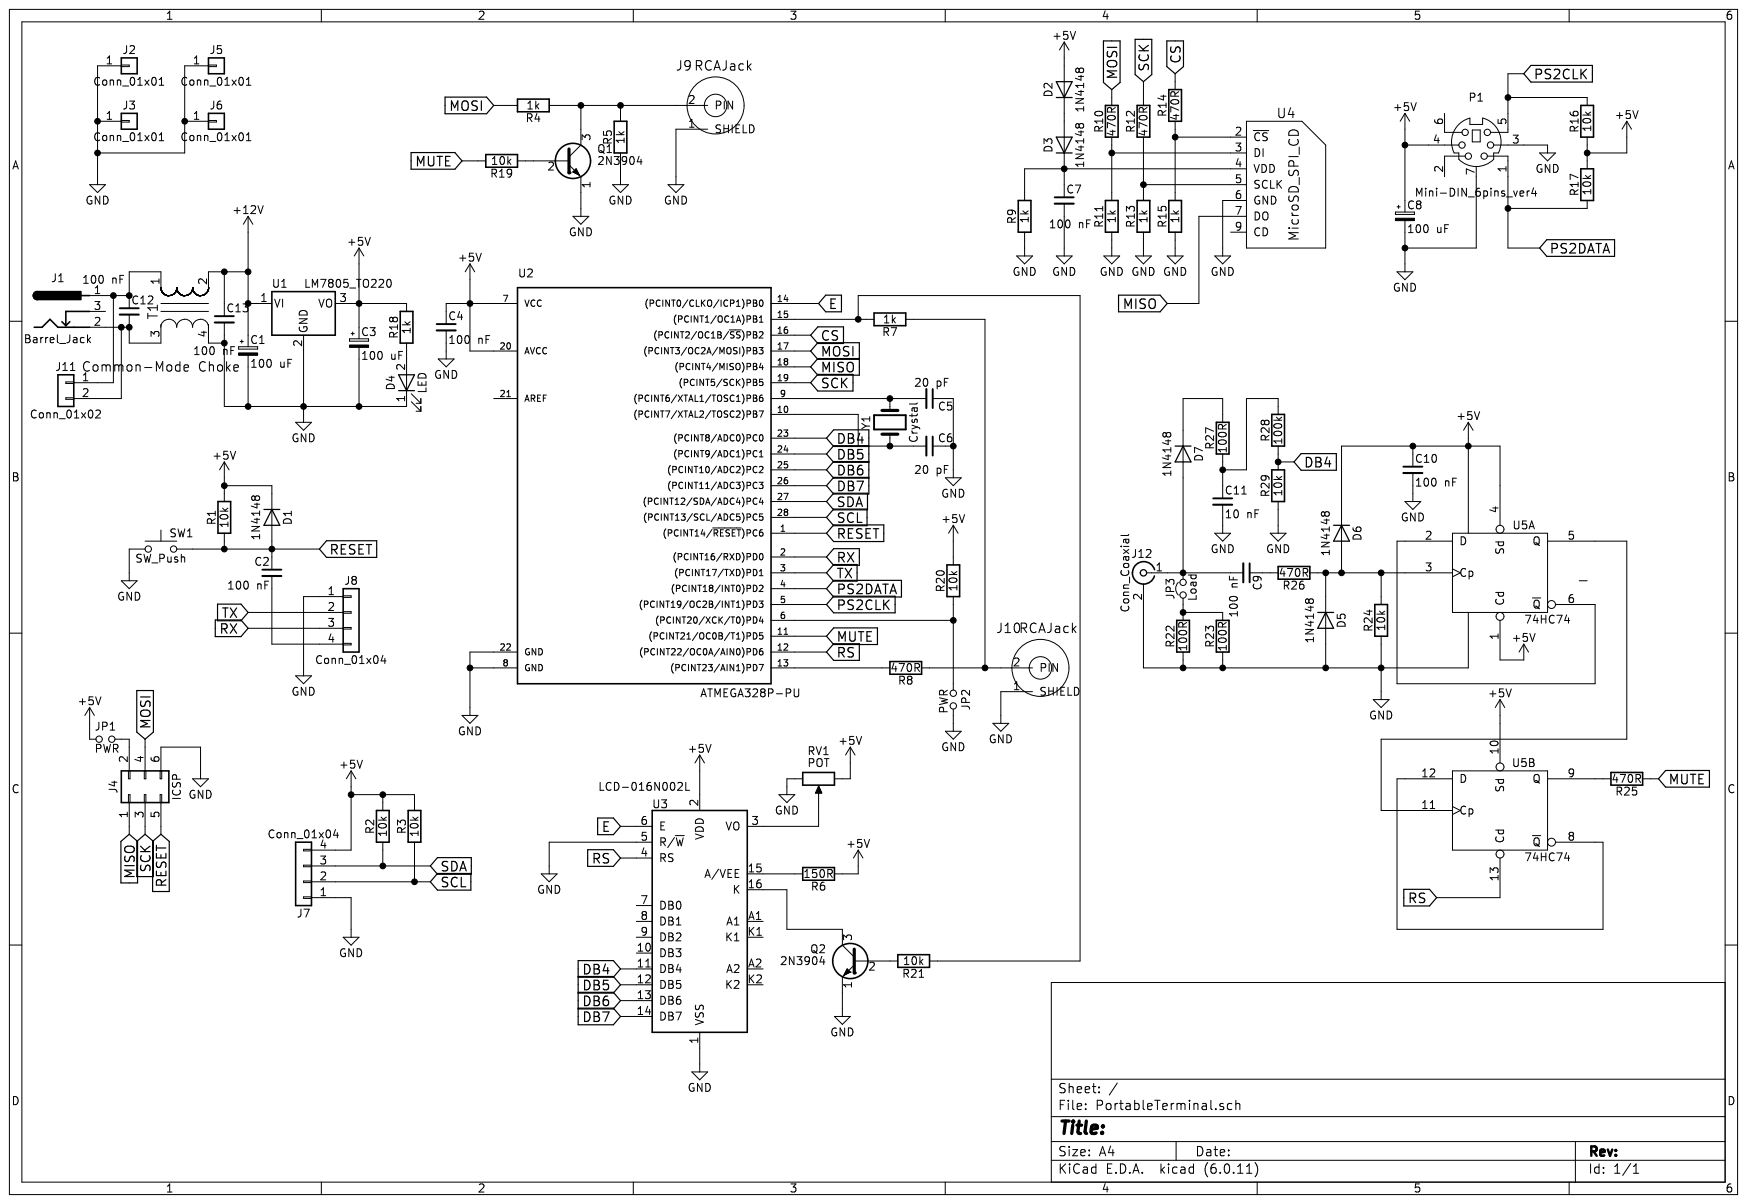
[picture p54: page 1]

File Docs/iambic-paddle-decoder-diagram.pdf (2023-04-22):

Dit debounce; Dit; Dah debounce; Dit register; Dah register; Set; Yes; Dit latch; Dah latch; Poll state; Reverse; symbol register dit↔dah; Dit set?; Symbol; Latch clear; Skip to latch clear; Reverse symbol register dit↔dah; Set timing; Symbol register set to dah; Is symbol register dit?; Set timing register to 1 unit, set mark state; Start symbol; Iambic mode B?; Clear dit and dah latches; End Poll state; Mark state; Timing register expired?; Set space state, set timing register to 1 unit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

Iambic paddle state machine, version 0.1 by Daniel L. Marks KW4TI

Dit and/or
dah register
set?

Both dit and

Set dit latch to
dit register,
dah latch to

Dit latch
and/or dah
latch set?

register
set to dit

Symbol
set to dah

dah latches

Dit latch set
and symbol
register is
dah?

Timing register:
number of units
A timing unit is equal to
1200/WPM in ms

register to 3
units, set mark
state

register:
dit or dah

Asynchronous Key Sampling

Dah latch set
register is dit?

Dah
(Positive logic: dit/dah is high
means paddle pressed)

Rising edge: paddle pressed

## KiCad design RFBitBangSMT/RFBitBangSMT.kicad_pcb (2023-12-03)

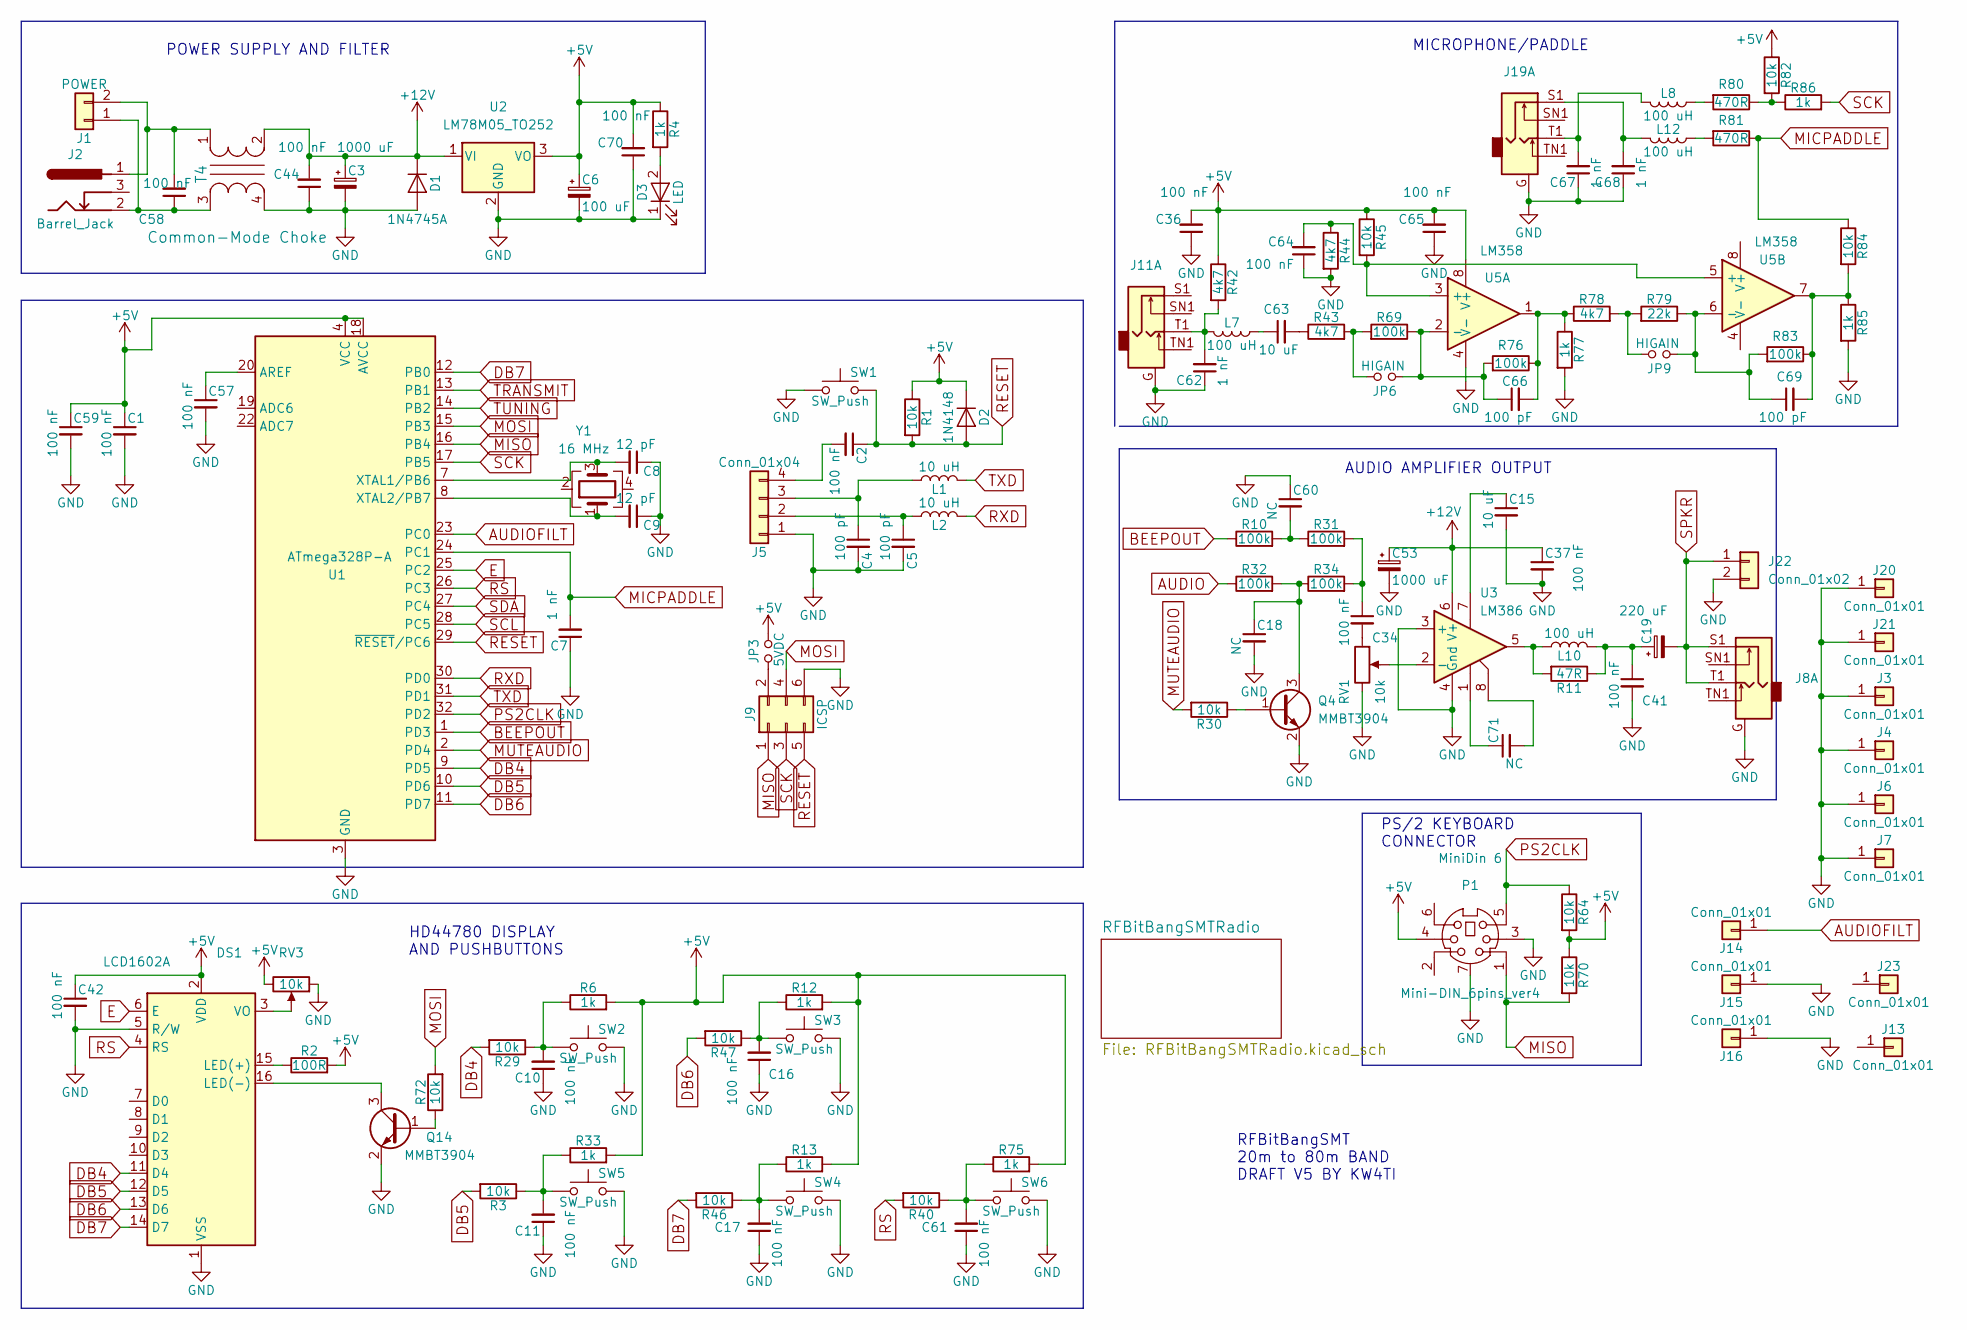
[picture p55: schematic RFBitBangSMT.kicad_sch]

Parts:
C1, C2, C10, C11, C16, C17, C36, C37, C41, C42, C44, C57, C58, C59, C61, C64, C65, C70: 100 nF; C_0805_2012Metric_Pad1.18x1.45mm_HandSolder; LCSC C49678
C3, C53: 1000 uF; CP_Radial_D8.0mm_P3.50mm
C4, C5, C66, C69: 100 pF; C_0805_2012Metric_Pad1.18x1.45mm_HandSolder; LCSC C1790
C6: 100 uF; CP_Radial_D5.0mm_P2.50mm
C7, C62, C67, C68: 1 nF; C_0805_2012Metric_Pad1.18x1.45mm_HandSolder; LCSC C46653
C8, C9: 12 pF; C_0805_2012Metric_Pad1.18x1.45mm_HandSolder; LCSC C1792
C15, C63: 10 uF; C_0805_2012Metric_Pad1.18x1.45mm_HandSolder; LCSC C15850
C18, C60, C71: NC; C_0805_2012Metric_Pad1.18x1.45mm_HandSolder
C19: 220 uF; CP_Radial_D7.5mm_P2.50mm
C34: 100 nF; C_0805_2012Metric_Pad1.18x1.45mm_HandSolder
D1: 1N4745A; D_DO-41_SOD81_P7.62mm_Horizontal
D2: 1N4148; D_SOD-123; LCSC C81598
D3: LED; LED_0805_2012Metric_Pad1.15x1.40mm_HandSolder; LCSC C2296
DS1: LCD1602A; WC1602A
J1: POWER; TerminalBlock_bornier-2_P5.08mm
J2: Barrel_Jack; BARREL_JACK
J3, J4, J6, J7, J13, J20, J21: Conn_01x01; 1pin
J5: Conn_01x04; Pin_Header_Straight_1x04_Pitch2.54mm
J8, J11, J19: AudioJack2_Dual_Ground_Switch; PJ-3240-35mm-stereo
J9: ICSP; Pin_Header_Straight_2x03_Pitch2.54mm
J14, J15, J16: Conn_01x01; Pin_Header_Straight_1x01_Pitch2.54mm
J22: Conn_01x02; PinHeader_1x02_P2.54mm_Vertical
J23: Conn_01x01; MountingHole_3.2mm_M3
JP3: 5VDC; Pin_Header_Straight_1x02_Pitch2.54mm
JP6, JP9: HIGAIN; PinHeader_1x02_P2.54mm_Vertical
L1, L2: 10 uH; L_0805_2012Metric_Pad1.15x1.40mm_HandSolder; LCSC C1046
L7, L8, L12: 100 uH; L_0805_2012Metric_Pad1.15x1.40mm_HandSolder; LCSC C68035
L10: 100 uH; L_Axial_L6.6mm_D2.7mm_P10.16mm_Horizontal_Vishay_IM-2; LCSC C1017
P1: Mini-DIN_6pins_ver4; MiniDin 6
Q4, Q14: MMBT3904; SOT-23; LCSC C20526
R1, R3, R29, R30, R40, R45, R46, R47, R64, R70, R72, R82, R84: 10k; R_0805_2012Metric_Pad1.20x1.40mm_HandSolder; LCSC C17414
R2: 100R; R_0805_2012Metric_Pad1.20x1.40mm_HandSolder; LCSC C17408
R4, R6, R12, R13, R33, R75, R77, R85, R86: 1k; R_0805_2012Metric_Pad1.20x1.40mm_HandSolder; LCSC C17513
R10, R31, R32, R34, R69, R76, R83: 100k; R_0805_2012Metric_Pad1.20x1.40mm_HandSolder; LCSC C149504
R11: 47R; R_0805_2012Metric_Pad1.20x1.40mm_HandSolder; LCSC C17714
R42, R43, R44, R78: 4k7; R_0805_2012Metric_Pad1.20x1.40mm_HandSolder; LCSC C17673
R79: 22k; R_0805_2012Metric_Pad1.20x1.40mm_HandSolder; LCSC C17560
R80, R81: 470R; R_0805_2012Metric_Pad1.20x1.40mm_HandSolder; LCSC C17710
RV1: 10k; Potentiometer_Big_Small_Combined
RV3: 10k; Potentiometer_Triwood_RM-065
SW1, SW2, SW3, SW4, SW5, SW6: SW_Push; SW_PUSH_6mm
T4: Common-Mode Choke; DoubleWindingTransformer
U1: ATmega328P-A; TQFP-32_7x7mm_P0.8mm; LCSC C14877
U2: LM78M05_TO252; TO-252-2; LCSC C58069
U3: LM386; SOP-8_3.9x4.9mm_P1.27mm; LCSC C383071
U5: LM358; SOP-8_3.9x4.9mm_P1.27mm; LCSC C7950
Y1: 16 MHz; Crystal_SMD_3225-4Pin_3.2x2.5mm_HandSoldering; LCSC C13738

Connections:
+5V: C1.1, C6.1, C36.2, C42.1, C59.1, C65.2, C70.2, D2.1 (K), DS1.2 (VDD), JP3.2, P1.4, R1.1, R2.2, R4.1, R6.2, R12.2, R13.2, R33.2, R42.1, R45.1, R64.2, R70.1, R75.2, R82.1, RV3.3, U1.4 (VCC), U1.6 (VCC), U1.18 (AVCC), U2.3 (VO), U5.8 (V+); also elsewhere on the board
+12V: C3.1, C37.1, C44.2, C53.1, D1.1 (K), T4.2, U2.1 (VI), U3.6 (V+); also elsewhere on the board
AUDIO: R32.1; also elsewhere on the board
AUDIOFILT: J14.1, U1.23 (PC0); also elsewhere on the board
BEEPOUT: R10.1, U1.1 (PD3)
DB4: DS1.11 (D4), R29.2, U1.9 (PD5)
DB5: DS1.12 (D5), R3.2, U1.10 (PD6)
DB6: DS1.13 (D6), R47.2, U1.11 (PD7)
DB7: DS1.14 (D7), R46.2, U1.12 (PB0)
E: DS1.6 (E), U1.25 (PC2)
GND: C1.2, C3.2, C4.2, C5.2, C6.2, C7.1, C8.1, C9.1, C10.1, C11.1, C15.2, C16.1, C17.1, C18.2, C36.1, C37.2, C41.2, C42.2, C44.1, C53.2, C57.2, C59.2, C60.1, C61.1, C62.1, C64.1, C65.1, C67.1, C68.1, C70.1, D1.2 (A), D3.1 (K), DS1.1 (VSS), DS1.5 (R/W), J3.1, J4.1, J5.1, J6.1, J7.1, J8.G, J9.6, J11.G, J15.1, J16.1, J19.G, J20.1, J21.1, J22.2, P1.3, P1.7 (Shell), Q4.2 (E), Q14.2 (E), R44.2, R77.2, R85.2, RV1.3, RV3.1, SW1.1, SW2.2, SW3.2, SW4.2, SW5.2, SW6.2, T4.4, U1.3 (GND), U1.5 (GND), U1.21 (GND), U2.2 (GND), U3.3 (+), U3.4 (Gnd), U5.4 (V-); also elsewhere on the board
MICPADDLE: C7.2, R81.1, R84.1, U1.24 (PC1)
MISO: J9.1, P1.1, R70.2, U1.16 (PB4)
MOSI: J9.4, R72.2, U1.15 (PB3)
MUTEAUDIO: R30.2, U1.2 (PD4)
unnamed: C2.2, J5.4
unnamed: C4.1, J5.3, L1.1
unnamed: C5.1, J5.2, L2.1
unnamed: C8.2, U1.7 (XTAL1/PB6), Y1.3
unnamed: C9.2, U1.8 (XTAL2/PB7), Y1.1
unnamed: C10.2, R6.1, R29.1, SW2.1
unnamed: C11.2, R3.1, R33.1, SW5.1
unnamed: C15.1, U3.7
unnamed: C16.2, R12.1, R47.1, SW3.1
unnamed: C17.2, R13.1, R46.1, SW4.1
unnamed: C18.1, Q4.3 (C), R32.2, R34.1
unnamed: C19.1, C41.1, L10.2, R11.1
unnamed: C34.1, R31.2, R34.2
unnamed: C34.2, RV1.1
unnamed: C57.1, U1.20 (AREF)
unnamed: C58.1, J1.1, J2.2, T4.3
unnamed: C58.2, J1.2, J2.1, T4.1
unnamed: C60.2, R10.2, R31.1
unnamed: C61.2, R40.1, R75.1, SW6.1
unnamed: C62.2, J11.T1, L7.2, R42.2
unnamed: C63.1, L7.1
unnamed: C63.2, R43.1
unnamed: C64.2, R44.1, R45.2, U5.3 (+), U5.5 (+)
unnamed: C66.1, JP6.1, R69.1, R76.2, U5.2 (-)
unnamed: C66.2, R76.1, R77.1, R78.1, U5.1
unnamed: C67.2, J19.T1, L8.2
unnamed: C68.2, J19.S1, L12.2
unnamed: C69.1, JP9.1, R79.1, R83.2, U5.6 (-)
unnamed: C69.2, R83.1, R84.2, R85.1, U5.7
unnamed: C71.1, U3.1
unnamed: C71.2, U3.8
unnamed: D3.2 (A), R4.2
unnamed: DS1.3 (VO), RV3.2
unnamed: DS1.15 (LED(+)), R2.1
unnamed: DS1.16 (LED(-)), Q14.3 (C)
unnamed: J9.2, JP3.1
unnamed: JP6.2, R43.2, R69.2
unnamed: JP9.2, R78.2, R79.2
unnamed: L8.1, R80.2
unnamed: L10.1, R11.2, U3.5
unnamed: L12.1, R81.2
unnamed: Q4.1 (B), R30.1
unnamed: Q14.1 (B), R72.1
unnamed: R80.1, R82.2, R86.1
unnamed: RV1.2, U3.2 (-)
PS2CLK: P1.5, R64.1, U1.32 (PD2)
RESET: C2.1, D2.2 (A), J9.5, R1.2, SW1.2, U1.29 (~RESET/PC6)
RS: DS1.4 (RS), R40.2, U1.26 (PC3)
RXD: L2.2, U1.30 (PD0)
SCK: J9.3, R86.2, U1.17 (PB5)
SCL: U1.28 (PC5); also elsewhere on the board
SDA: U1.27 (PC4); also elsewhere on the board
SPKR: C19.2, J8.S1, J8.T1, J22.1
TRANSMIT: U1.13 (PB1); also elsewhere on the board
TUNING: U1.14 (PB2); also elsewhere on the board
TXD: L1.2, U1.31 (PD1)

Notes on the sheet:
POWER SUPPLY AND FILTER
PS/2 KEYBOARD CONNECTOR
MICROPHONE/PADDLE
AUDIO AMPLIFIER OUTPUT
RFBitBangSMT 20m to 80m BAND DRAFT V5 BY KW4TI
HD44780 DISPLAY AND PUSHBUTTONS

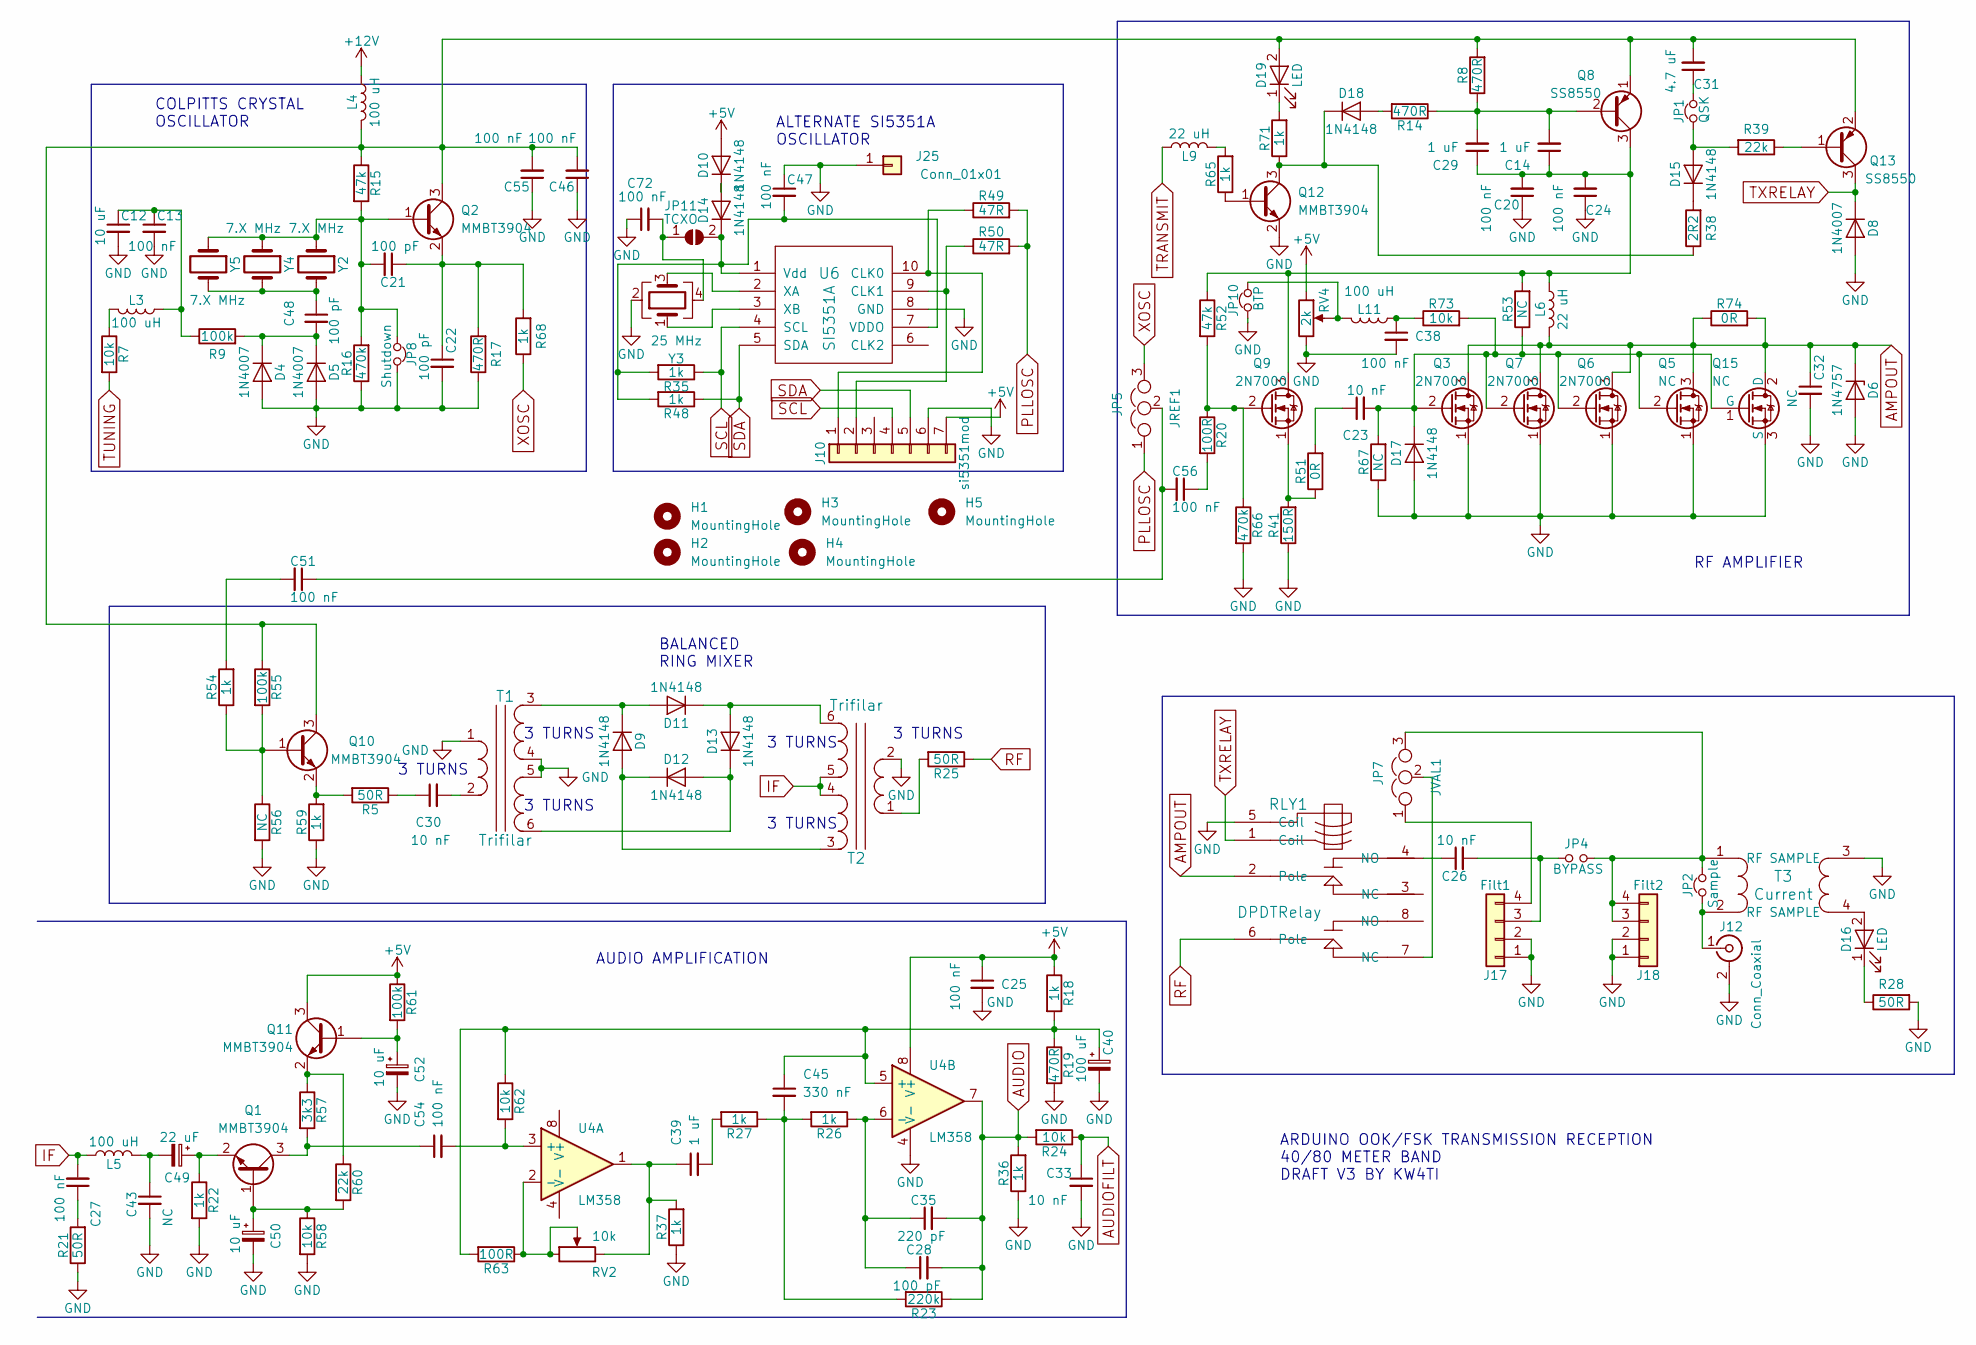
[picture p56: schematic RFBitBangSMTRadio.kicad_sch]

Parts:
C12: 10 uF; C_0805_2012Metric_Pad1.18x1.45mm_HandSolder; LCSC C15850
C13, C20, C24, C25, C27, C38, C46, C47, C51, C54, C55, C56, C72: 100 nF; C_0805_2012Metric_Pad1.18x1.45mm_HandSolder; LCSC C49678
C14, C29, C39: 1 uF; C_0805_2012Metric_Pad1.18x1.45mm_HandSolder; LCSC C28323
C21, C22, C28, C48: 100 pF; C_0805_2012Metric_Pad1.18x1.45mm_HandSolder; LCSC C1790
C23, C26, C30, C33: 10 nF; C_0805_2012Metric_Pad1.18x1.45mm_HandSolder; LCSC C1710
C31: 4.7 uF; C_0805_2012Metric_Pad1.18x1.45mm_HandSolder; LCSC C1779
C32, C43: NC; C_0805_2012Metric_Pad1.18x1.45mm_HandSolder
C35: 220 pF; C_0805_2012Metric_Pad1.18x1.45mm_HandSolder; LCSC C107145
C40: 100 uF; CP_Radial_D5.0mm_P2.50mm
C45: 330 nF; C_0805_2012Metric_Pad1.18x1.45mm_HandSolder; LCSC C1740
C49: 22 uF; CP_Radial_D5.0mm_P2.50mm
C50, C52: 10 uF; CP_Radial_D5.0mm_P2.50mm
D4, D5, D8: 1N4007; D_SMA_Handsoldering; LCSC C95872
D6: 1N4757; D_DO-41_SOD81_P7.62mm_Horizontal
D9, D10, D11, D12, D13, D14, D15, D17, D18: 1N4148; D_SOD-123; LCSC C81598
D16, D19: LED; LED_0805_2012Metric_Pad1.15x1.40mm_HandSolder; LCSC C2296
H1, H2, H3, H4, H5: MountingHole; CutSlot
J10: si5351mod; Pin_Header_Straight_1x07_Pitch2.54mm
J12: Conn_Coaxial; bnc_90_1-1337543-0_pad_combo
J17: Filt1; Pin_Header_Straight_1x04_Pitch2.54mm
J18: Filt2; Pin_Header_Straight_1x04_Pitch2.54mm
J25: Conn_01x01; PinHeader_1x01_P2.00mm_Vertical
JP1: QSK; Pin_Header_Straight_1x02_Pitch2.54mm
JP2: Sample; Pin_Header_Straight_1x02_Pitch2.54mm
JP4: BYPASS; Pin_Header_Straight_1x02_Pitch2.54mm
JP5: JREF1; Pin_Header_Straight_1x03_Pitch2.54mm
JP7: JVAL1; Pin_Header_Straight_1x03_Pitch2.54mm
JP8: Shutdown; Pin_Header_Straight_1x02_Pitch2.54mm
JP10: BTP; PinHeader_1x02_P2.54mm_Vertical
JP11: TCXO; SolderJumper-2_P1.3mm_Open_Pad1.0x1.5mm
L3, L5, L11: 100 uH; L_0805_2012Metric_Pad1.15x1.40mm_HandSolder; LCSC C68035
L4: 100 uH; SmallVerticalToroid
L6: 22 uH; SmallVerticalToroid
L9: 22 uH; L_0805_2012Metric_Pad1.15x1.40mm_HandSolder; LCSC C32375
Q1, Q2, Q10, Q11, Q12: MMBT3904; SOT-23; LCSC C20526
Q3, Q6, Q7, Q9: 2N7000; TO-92_Inline_Wide
Q5: NC; TO-92_Inline_Wide
Q8: SS8550; TO-92_Inline_Wide
Q13: SS8550; SOT-23; LCSC C8542
Q15: NC; TO-220-3_Vertical
R5, R21, R25, R28: 50R; R_0805_2012Metric_Pad1.20x1.40mm_HandSolder; LCSC C17720
R7, R24, R58, R62, R73: 10k; R_0805_2012Metric_Pad1.20x1.40mm_HandSolder; LCSC C17414
R8, R14, R17, R19: 470R; R_0805_2012Metric_Pad1.20x1.40mm_HandSolder; LCSC C17710
R9, R55, R61: 100k; R_0805_2012Metric_Pad1.20x1.40mm_HandSolder; LCSC C149504
R15, R52: 47k; R_0805_2012Metric_Pad1.20x1.40mm_HandSolder; LCSC C17713
R16, R66: 470k; R_0805_2012Metric_Pad1.20x1.40mm_HandSolder; LCSC C17709
R18, R22, R26, R27, R35, R36, R37, R48, R54, R59, R65, R68, R71: 1k; R_0805_2012Metric_Pad1.20x1.40mm_HandSolder; LCSC C17513
R20, R63: 100R; R_0805_2012Metric_Pad1.20x1.40mm_HandSolder; LCSC C17408
R23: 220k; R_0805_2012Metric_Pad1.20x1.40mm_HandSolder; LCSC C17556
R38: 2R2; R_0805_2012Metric_Pad1.20x1.40mm_HandSolder; LCSC C17521
R39, R60: 22k; R_0805_2012Metric_Pad1.20x1.40mm_HandSolder; LCSC C17560
R41: 150R; R_Axial_DIN0309_L9.0mm_D3.2mm_P12.70mm_Horizontal
R49, R50: 47R; R_0805_2012Metric_Pad1.20x1.40mm_HandSolder; LCSC C17714
R51, R74: 0R; R_0805_2012Metric_Pad1.20x1.40mm_HandSolder; LCSC C17477
R53, R56, R67: NC; R_0805_2012Metric_Pad1.20x1.40mm_HandSolder
R57: 3k3; R_0805_2012Metric_Pad1.20x1.40mm_HandSolder; LCSC C26010
RLY1: DPDTRelay; G2VRelay
RV2: 10k; Potentiometer_Big_Small_Combined
RV4: 2k; Potentiometer_Trimmer_Bourns_3296W
T1, T2: Trifilar; TripleWindingTransformerRef
T3: Current; SamplingTransformer
U4: LM358; SOP-8_3.9x4.9mm_P1.27mm; LCSC C7950
U6: SI5351A; MSOP-10_3x3mm_Pitch0.5mm; LCSC C1509083
Y2, Y4, Y5: 7.X MHz; Crystal_HC49-U_Vertical
Y3: 25 MHz; Crystal_SMD_3225-4Pin_3.2x2.5mm; LCSC C9006

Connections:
+5V: C25.1, D10.2 (A), J10.7, Q11.3 (C), R18.1, R61.1, RV4.1, U4.8 (V+); also elsewhere on the board
+12V: L4.1; also elsewhere on the board
AMPOUT: C32.1, D6.1 (K), L6.2, Q3.3 (D), Q5.3 (D), Q6.3 (D), Q7.3 (D), Q15.2 (D), R74.1, R74.2, RLY1.2 (Pole)
AUDIO: C28.2, C35.2, R23.1, R24.2, R36.2, U4.7; also elsewhere on the board
AUDIOFILT: C33.1, R24.1; also elsewhere on the board
GND: C12.2, C13.2, C20.1, C22.2, C24.1, C25.2, C32.2, C33.2, C38.2, C40.2, C43.2, C46.1, C47.1, C50.2, C52.2, C55.1, C72.1, D4.2 (A), D5.2 (A), D6.2 (A), D8.2 (A), D17.2 (A), J10.6, J12.2 (Ext), J17.1, J17.2, J18.1, J18.2, J25.1, JP8.2, JP10.1, Q3.1 (S), Q5.1 (S), Q6.1 (S), Q7.1 (S), Q12.2 (E), Q15.3 (S), R16.1, R17.1, R19.2, R21.1, R22.2, R28.2, R36.1, R37.1, R41.1, R56.2, R58.2, R59.1, R66.2, R67.1, RLY1.5 (Coil), RV4.3, T1.1, T1.4, T1.5, T2.2, T3.3 (SAMPLE), U4.4 (V-), U6.8 (GND), Y3.2; also elsewhere on the board
IF: C27.2, L5.1, T2.4, T2.5
unnamed: C12.1, C13.1, L3.1, R9.1
unnamed: C14.1, C20.2, C24.2, C29.1, L6.1, Q8.3 (C), Q9.3 (D), R52.1, R53.2
unnamed: C14.2, C29.2, Q8.2 (B), R8.1, R14.1
unnamed: C21.1, C22.1, Q2.2 (E), R17.2, R68.2
unnamed: C21.2, JP8.1, Q2.1 (B), R15.2, R16.2, Y2.1, Y4.1, Y5.1
unnamed: C23.1, R51.2
unnamed: C23.2, D17.1 (K), Q3.2 (G), Q5.2 (G), Q6.2 (G), Q7.2 (G), Q15.1 (G), R53.1, R67.2, R73.2
unnamed: C26.1, RLY1.4 (NO)
unnamed: C26.2, J17.3, JP4.1
unnamed: C27.1, R21.2
unnamed: C28.1, C35.1, R26.1, U4.6 (-)
unnamed: C30.1, R5.1
unnamed: C30.2, T1.2
unnamed: C31.1, JP1.2
unnamed: C31.2, C46.2, C55.2, D19.2 (A), L4.2, Q2.3 (C), Q8.1 (E), Q10.3 (C), Q13.2 (E), R8.2, R15.1, R55.1
unnamed: C38.1, L11.1, R73.1
unnamed: C39.1, R37.2, RV2.3, U4.1
unnamed: C39.2, R27.2
unnamed: C40.1, C45.1, R18.2, R19.1, R62.1, R63.2, U4.5 (+)
unnamed: C43.1, C49.2, L5.2
unnamed: C45.2, R23.2, R26.2, R27.1
unnamed: C47.2, D14.1 (K), JP11.2 (B), R35.2, R48.2, U6.1 (Vdd), U6.7 (VDDO)
unnamed: C48.1, Y2.2, Y4.2, Y5.2
unnamed: C48.2, D4.1 (K), D5.1 (K), R9.2
unnamed: C49.1, Q1.2 (E), R22.1
unnamed: C50.1, Q1.1 (B), R58.1, R60.2
unnamed: C51.1, C56.2, JP5.2
unnamed: C51.2, R54.2
unnamed: C52.1, Q11.1 (B), R61.2
unnamed: C54.1, Q1.3 (C), R57.2
unnamed: C54.2, R62.2, U4.3 (+)
unnamed: C56.1, R20.2
unnamed: C72.2, JP11.1 (A), Y3.4
unnamed: D10.1 (K), D14.2 (A)
unnamed: D11.1 (K), D13.2 (A), T2.6
unnamed: D9.1 (K), D11.2 (A), T1.3
unnamed: D9.2 (A), D12.1 (K), T2.3
unnamed: D12.2 (A), D13.1 (K), T1.6
unnamed: D15.1 (K), R38.2
unnamed: D15.2 (A), JP1.1, R39.2
unnamed: D16.1 (K), R28.1
unnamed: D16.2 (A), T3.4 (SAMPLE)
unnamed: D18.1 (K), Q12.3 (C), R38.1, R71.1
unnamed: D18.2 (A), R14.2
unnamed: D19.1 (K), R71.2
unnamed: J10.1, R49.1, U6.10 (CLK0)
unnamed: J10.2, R50.1, U6.9 (CLK1)
unnamed: J12.1 (In), JP2.1, T3.2 (RF)
unnamed: J17.4, JP7.1
unnamed: J18.3, J18.4, JP2.2, JP4.2, JP7.3, T3.1 (RF)
unnamed: JP7.2, RLY1.7 (NC)
unnamed: JP10.2, L11.2, RV4.2
unnamed: L3.2, R7.1
unnamed: L9.2, R65.2
unnamed: Q9.1 (S), R41.2, R51.1
unnamed: Q9.2 (G), R20.1, R52.2, R66.1
unnamed: Q10.1 (B), R54.1, R55.2, R56.1
unnamed: Q10.2 (E), R5.2, R59.2
unnamed: Q11.2 (E), R57.1, R60.1
unnamed: Q12.1 (B), R65.1
unnamed: Q13.1 (B), R39.1
unnamed: R25.2, T2.1
unnamed: R63.1, RV2.1, RV2.2, U4.2 (-)
unnamed: U6.2 (XA), Y3.3
unnamed: U6.3 (XB), Y3.1
PLLOSC: JP5.1, R49.2, R50.2
RF: R25.1, RLY1.6 (Pole)
SCL: J10.4, R35.1, U6.4 (SCL); also elsewhere on the board
SDA: J10.5, R48.1, U6.5 (SDA); also elsewhere on the board
TRANSMIT: L9.1; also elsewhere on the board
TUNING: R7.2; also elsewhere on the board
TXRELAY: D8.1 (K), Q13.3 (C), RLY1.1 (Coil)
XOSC: JP5.3, R68.1

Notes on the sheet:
AUDIO AMPLIFICATION
ARDUINO OOK/FSK TRANSMISSION RECEPTION 40/80 METER BAND DRAFT V3 BY KW4TI
3 TURNS
ALTERNATE SI5351A OSCILLATOR
3 TURNS
COLPITTS CRYSTAL OSCILLATOR
RF AMPLIFIER
BALANCED RING MIXER

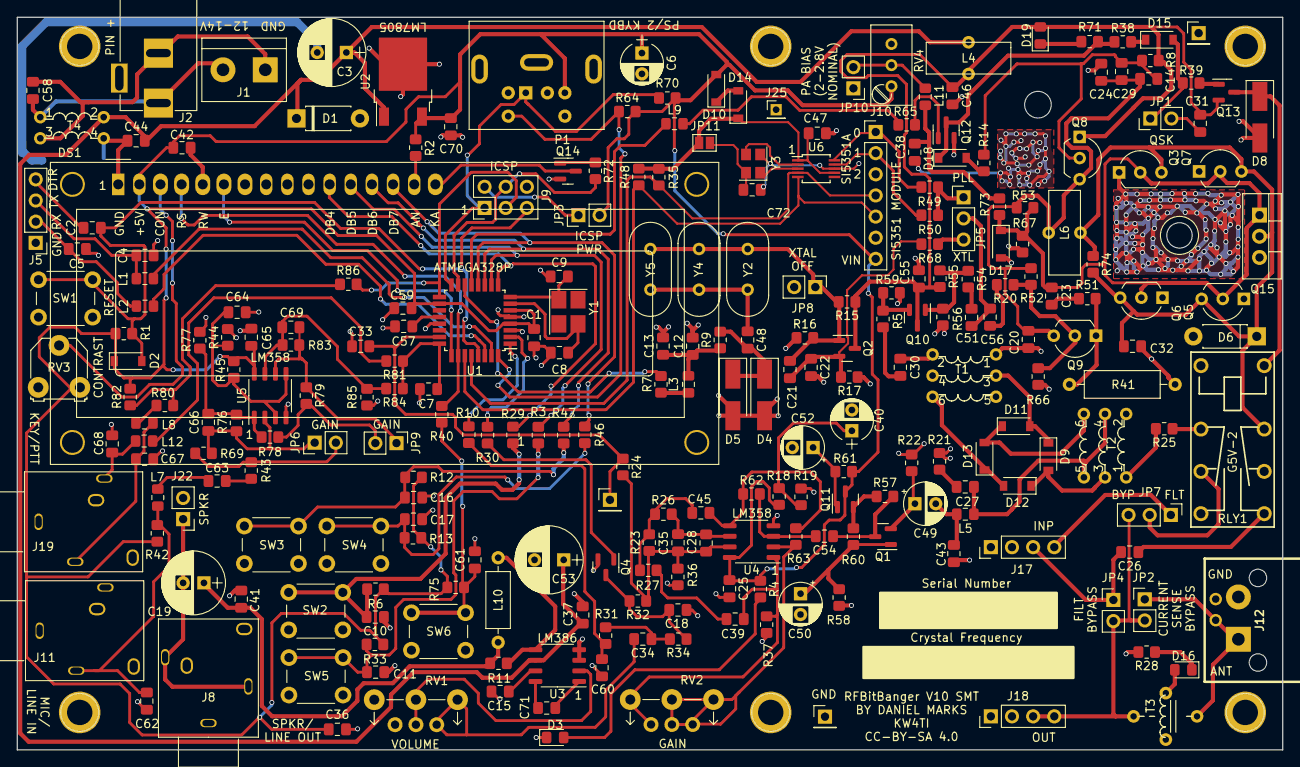
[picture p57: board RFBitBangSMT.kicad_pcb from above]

Board: 2 copper layers, 152.0 x 88.0 mm, 271 parts (0 on the bottom side), 142 nets.

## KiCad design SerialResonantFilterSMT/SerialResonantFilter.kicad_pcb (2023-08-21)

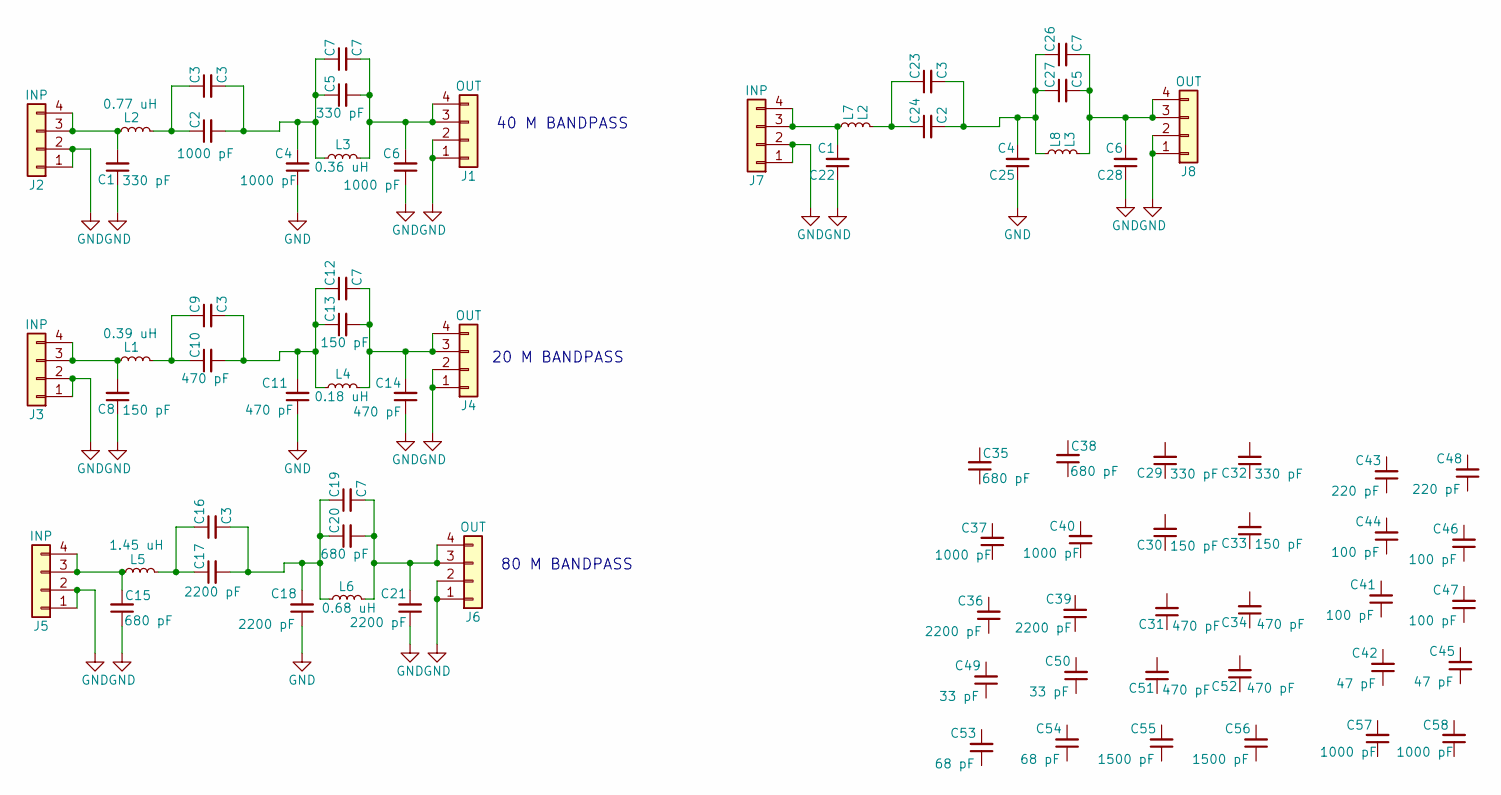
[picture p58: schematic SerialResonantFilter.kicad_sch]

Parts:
C1, C5, C29, C32: 330 pF; C_1206_3216Metric_Pad1.33x1.80mm_HandSolder; LCSC C527285
C2: 1000 pF; C_1206_3216Metric_Pad1.33x1.80mm_HandSolder; LCSC C527339
C3, C9, C16: C3; C_1206_3216Metric_Pad1.33x1.80mm_HandSolder
C4, C6, C37, C40, C57, C58: 1000 pF; C_1206_3216Metric_Pad1.33x1.80mm_HandSolder
C7, C12, C19: C7; C_1206_3216Metric_Pad1.33x1.80mm_HandSolder
C8, C13, C30, C33: 150 pF; C_1206_3216Metric_Pad1.33x1.80mm_HandSolder; LCSC C577189
C10, C31, C34, C51, C52: 470 pF; C_1206_3216Metric_Pad1.33x1.80mm_HandSolder; LCSC C527302
C11, C14: 470 pF; C_1206_3216Metric_Pad1.33x1.80mm_HandSolder
C15, C20, C35, C38: 680 pF; C_1206_3216Metric_Pad1.33x1.80mm_HandSolder; LCSC C541497
C17: 2200 pF; C_1206_3216Metric_Pad1.33x1.80mm_HandSolder; LCSC C527261
C18, C21, C36, C39: 2200 pF; C_1206_3216Metric_Pad1.33x1.80mm_HandSolder
C22: C1; C_Disc_D5.0mm_W2.5mm_P5.00mm_Dual
C23: C3; C_Disc_D5.0mm_W2.5mm_P5.00mm_Dual
C24: C2; C_Disc_D5.0mm_W2.5mm_P5.00mm_Dual
C25: C4; C_Disc_D5.0mm_W2.5mm_P5.00mm_Dual
C26: C7; C_Disc_D5.0mm_W2.5mm_P5.00mm_Dual
C27: C5; C_Disc_D5.0mm_W2.5mm_P5.00mm_Dual
C28: C6; C_Disc_D5.0mm_W2.5mm_P5.00mm_Dual
C41, C44, C46, C47: 100 pF; C_1206_3216Metric_Pad1.33x1.80mm_HandSolder
C42, C45: 47 pF; C_1206_3216Metric_Pad1.33x1.80mm_HandSolder
C43, C48: 220 pF; C_1206_3216Metric_Pad1.33x1.80mm_HandSolder
C49, C50: 33 pF; C_1206_3216Metric_Pad1.33x1.80mm_HandSolder
C53, C54: 68 pF; C_1206_3216Metric_Pad1.33x1.80mm_HandSolder
C55, C56: 1500 pF; C_1206_3216Metric_Pad1.33x1.80mm_HandSolder
J1: OUT; Pin_Header_Straight_1x04_Pitch2.54mm
J2: INP; Pin_Header_Straight_1x04_Pitch2.54mm
J3, J5, J7: INP; PinSocket_1x04_P2.54mm_Vertical
J4, J6, J8: OUT; PinSocket_1x04_P2.54mm_Vertical
L1: 0.39 uH; L_Toroid_Horizontal_D12.7mm_Compact
L2: 0.77 uH; L_Toroid_Horizontal_D12.7mm_Compact
L3: 0.36 uH; L_Toroid_Horizontal_D12.7mm_Compact
L4: 0.18 uH; L_Toroid_Horizontal_D12.7mm_Compact
L5: 1.45 uH; L_Toroid_Horizontal_D12.7mm_Compact
L6: 0.68 uH; L_Toroid_Horizontal_D12.7mm_Compact
L7: L2; L_Toroid_Horizontal_D12.7mm_Compact
L8: L3; L_Toroid_Horizontal_D12.7mm_Compact

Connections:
GND: C1.1, C4.1, C6.1, C8.1, C11.1, C14.1, C15.1, C18.1, C21.1, C22.1, C25.1, C28.1, J1.1, J1.2, J2.1, J2.2, J3.1, J3.2, J4.1, J4.2, J5.1, J5.2, J6.1, J6.2, J7.1, J7.2, J8.1, J8.2
unnamed: C1.2, J2.3, J2.4, L2.1
unnamed: C2.1, C3.1, L2.2
unnamed: C2.2, C3.2, C4.2, C5.1, C7.1, L3.1
unnamed: C5.2, C6.2, C7.2, J1.3, J1.4, L3.2
unnamed: C8.2, J3.3, J3.4, L1.1
unnamed: C9.1, C10.1, L1.2
unnamed: C9.2, C10.2, C11.2, C12.1, C13.1, L4.1
unnamed: C12.2, C13.2, C14.2, J4.3, J4.4, L4.2
unnamed: C15.2, J5.3, J5.4, L5.1
unnamed: C16.1, C17.1, L5.2
unnamed: C16.2, C17.2, C18.2, C19.1, C20.1, L6.1
unnamed: C19.2, C20.2, C21.2, J6.3, J6.4, L6.2
unnamed: C22.2, J7.3, J7.4, L7.1
unnamed: C23.1, C24.1, L7.2
unnamed: C23.2, C24.2, C25.2, C26.1, C27.1, L8.1
unnamed: C26.2, C27.2, C28.2, J8.3, J8.4, L8.2

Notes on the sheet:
40 M BANDPASS
20 M BANDPASS
80 M BANDPASS

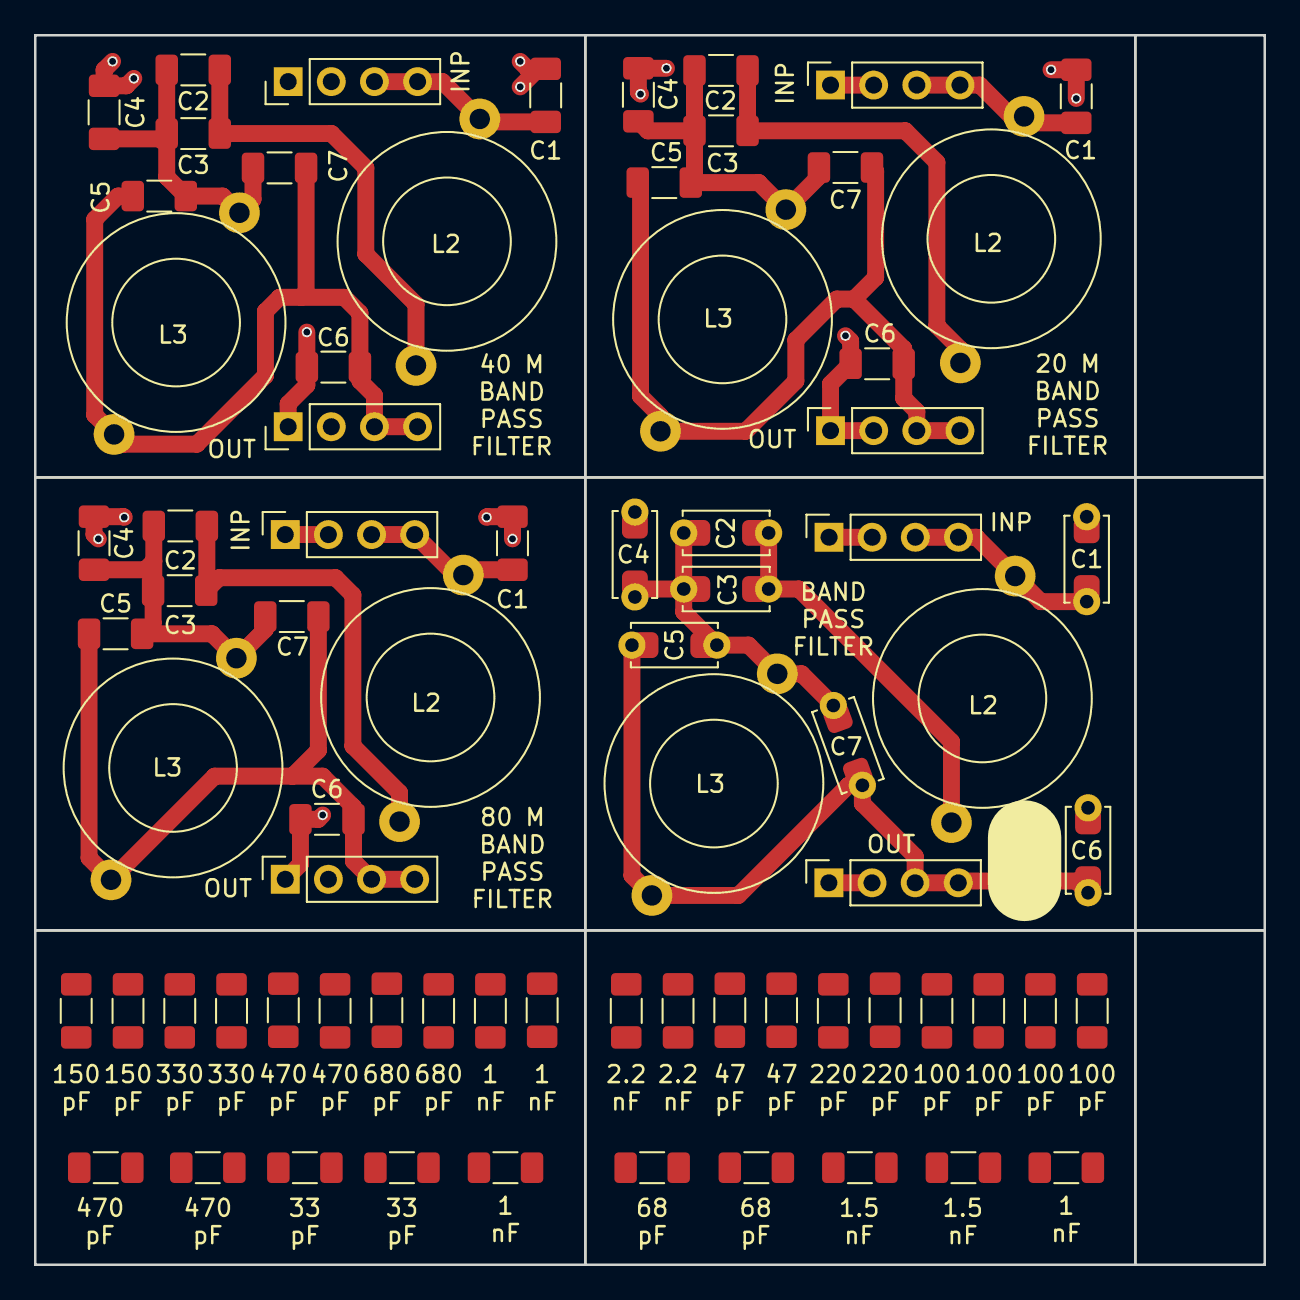
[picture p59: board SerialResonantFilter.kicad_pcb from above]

Board: 2 copper layers, 72.4 x 72.4 mm, 74 parts (0 on the bottom side), 17 nets.

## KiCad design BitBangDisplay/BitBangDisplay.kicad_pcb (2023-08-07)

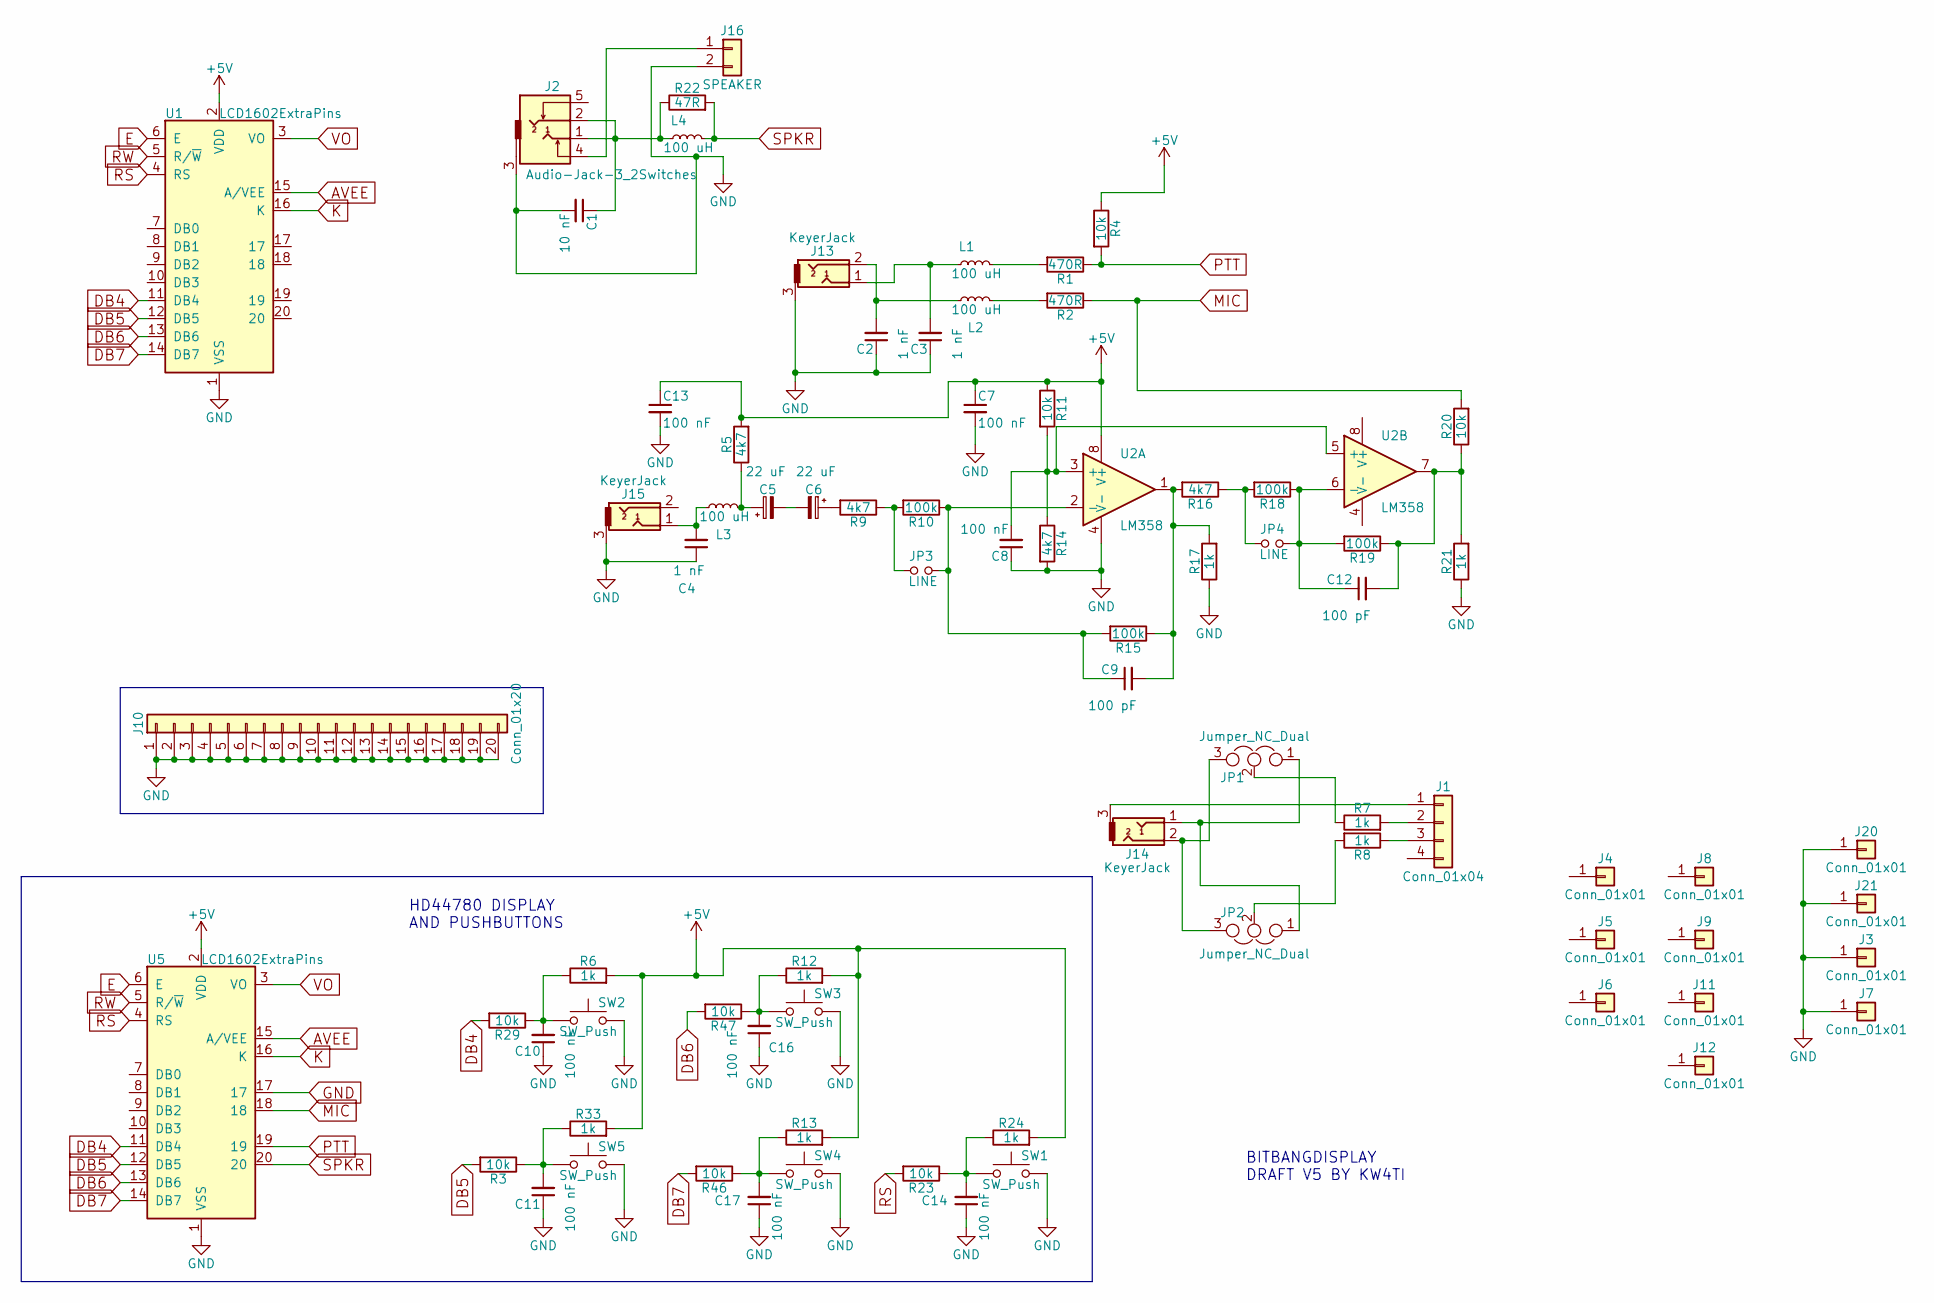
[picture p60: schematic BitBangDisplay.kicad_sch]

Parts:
C1: 10 nF; C_Disc_D5.0mm_W2.5mm_P2.50mm
C2, C3, C4: 1 nF; C_Disc_D5.0mm_W2.5mm_P5.00mm
C5, C6: 22 uF; CP_Radial_D5.0mm_P2.50mm
C7, C8, C10, C11, C13, C14, C16, C17: 100 nF; C_Disc_D5.0mm_W2.5mm_P2.50mm
C9, C12: 100 pF; C_Disc_D5.0mm_W2.5mm_P5.00mm
J1: Conn_01x04; Pin_Header_Straight_1x04_Pitch2.54mm
J2: Audio-Jack-3_2Switches; PJ-3240-35mm-stereo
J3, J7, J20, J21: Conn_01x01; 1pin
J4, J5, J6, J8, J9, J11, J12: Conn_01x01; SimpleHole
J10: Conn_01x20; Pin_Header_Straight_1x20_Pitch2.54mm
J13, J14, J15: KeyerJack; PJ-3240-35mm-stereo
J16: SPEAKER; TerminalBlock_bornier-2_P5.08mm
JP1, JP2: Jumper_NC_Dual; Pin_Header_Straight_1x03_Pitch2.54mm
JP3, JP4: LINE; Pin_Header_Straight_1x02_Pitch2.54mm
L1, L2, L3, L4: 100 uH; L_Axial_L6.6mm_D2.7mm_P10.16mm_Horizontal_Vishay_IM-2
R1, R2: 470R; R_Axial_DIN0207_L6.3mm_D2.5mm_P7.62mm_Horizontal
R3, R4, R11, R20, R23, R29, R46, R47: 10k; R_Axial_DIN0207_L6.3mm_D2.5mm_P7.62mm_Horizontal
R5, R9, R14, R16: 4k7; R_Axial_DIN0207_L6.3mm_D2.5mm_P7.62mm_Horizontal
R6, R7, R8, R12, R13, R17, R21, R24, R33: 1k; R_Axial_DIN0207_L6.3mm_D2.5mm_P7.62mm_Horizontal
R10, R15, R18, R19: 100k; R_Axial_DIN0207_L6.3mm_D2.5mm_P7.62mm_Horizontal
R22: 47R; R_Axial_DIN0207_L6.3mm_D2.5mm_P7.62mm_Horizontal
SW1, SW2, SW3, SW4, SW5: SW_Push; SW_PUSH_6mm
U1: LCD1602ExtraPins; Pin_Header_Straight_1x16_Pitch2.54mm
U2: LM358; DIP-8_W7.62mm_Socket
U5: LCD1602ExtraPins; Pin_Header_Straight_1x20_Pitch2.54mm

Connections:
+5V: C7.1, C13.1, R4.1, R5.2, R6.2, R11.1, R12.2, R13.2, R24.2, R33.2, U1.2 (VDD), U2.8 (V+), U5.2 (VDD)
AVEE: U1.15 (A/VEE), U5.15 (A/VEE)
DB4: R29.2, U1.11 (DB4), U5.11 (DB4)
DB5: R3.2, U1.12 (DB5), U5.12 (DB5)
DB6: R47.2, U1.13 (DB6), U5.13 (DB6)
DB7: R46.2, U1.14 (DB7), U5.14 (DB7)
E: U1.6 (E), U5.6 (E)
GND: C1.2, C2.1, C3.1, C4.1, C7.2, C8.1, C10.1, C11.1, C13.2, C14.1, C16.1, C17.1, J2.3, J3.1, J7.1, J10.1, J10.2, J10.3, J10.4, J10.5, J10.6, J10.7, J10.8, J10.9, J10.10, J10.11, J10.12, J10.13, J10.14, J10.15, J10.16, J10.17, J10.18, J10.19, J10.20, J13.3, J15.3, J16.2, J20.1, J21.1, R14.2, R17.1, R21.1, SW1.2, SW2.2, SW3.2, SW4.2, SW5.2, U1.1 (VSS), U2.4 (V-), U5.1 (VSS), U5.17
K: U1.16 (K), U5.16 (K)
MIC: R2.1, R20.2, U5.18
unnamed: C1.1, J2.1, J2.2, L4.1, R22.1
unnamed: C2.2, J13.2, L2.1
unnamed: C3.2, J13.1, L1.1
unnamed: C4.2, J15.1, L3.1
unnamed: C5.1, L3.2, R5.1
unnamed: C5.2, C6.2
unnamed: C6.1, R9.2
unnamed: C8.2, R11.2, R14.1, U2.3 (+), U2.5 (+)
unnamed: C9.1, JP3.2, R10.1, R15.2, U2.2 (-)
unnamed: C9.2, R15.1, R16.2, R17.2, U2.1
unnamed: C10.2, R6.1, R29.1, SW2.1
unnamed: C11.2, R3.1, R33.1, SW5.1
unnamed: C12.1, JP4.2, R18.1, R19.2, U2.6 (-)
unnamed: C12.2, R19.1, R20.1, R21.2, U2.7
unnamed: C14.2, R23.1, R24.1, SW1.1
unnamed: C16.2, R12.1, R47.1, SW3.1
unnamed: C17.2, R13.1, R46.1, SW4.1
unnamed: J1.1, J14.3
unnamed: J1.2, R7.2
unnamed: J1.3, R8.1
unnamed: J14.1, JP1.1, JP2.1
unnamed: J14.2, JP1.3, JP2.3
unnamed: J2.4, J16.1
unnamed: JP1.2, R7.1
unnamed: JP2.2, R8.2
unnamed: JP3.1, R9.1, R10.2
unnamed: JP4.1, R16.1, R18.2
unnamed: L1.2, R1.2
unnamed: L2.2, R2.2
PTT: R1.1, R4.2, U5.19
RS: R23.2, U1.4 (RS), U5.4 (RS)
RW: U1.5 (R/~W), U5.5 (R/~W)
SPKR: L4.2, R22.2, U5.20
VO: U1.3 (VO), U5.3 (VO)

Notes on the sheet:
BITBANGDISPLAY DRAFT V5 BY KW4TI
HD44780 DISPLAY AND PUSHBUTTONS

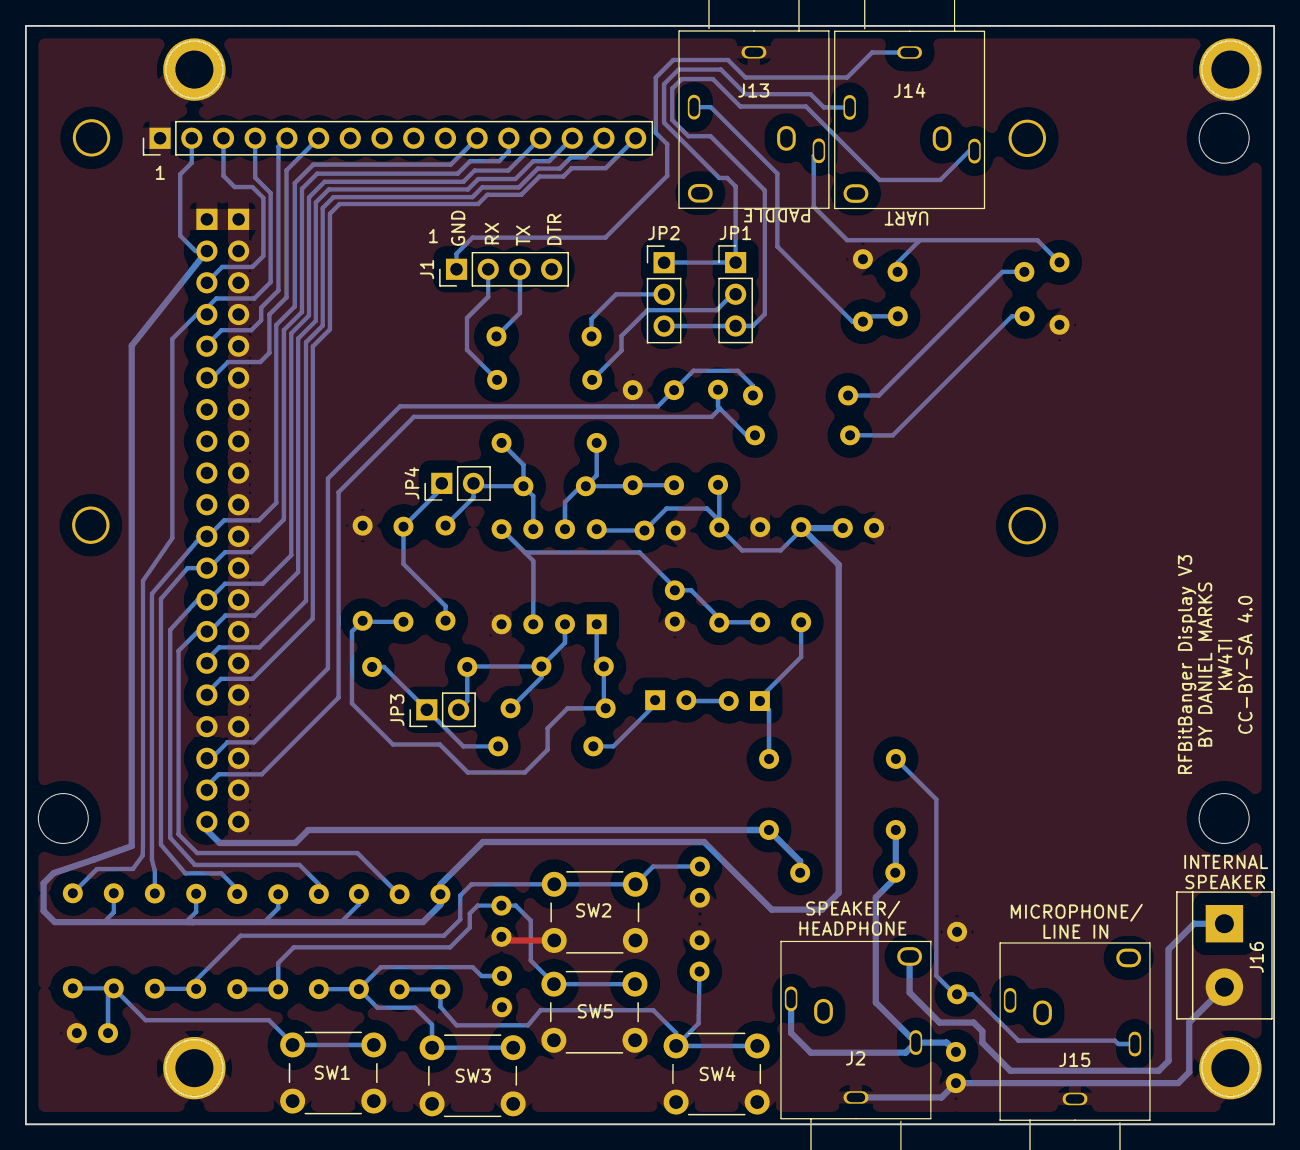
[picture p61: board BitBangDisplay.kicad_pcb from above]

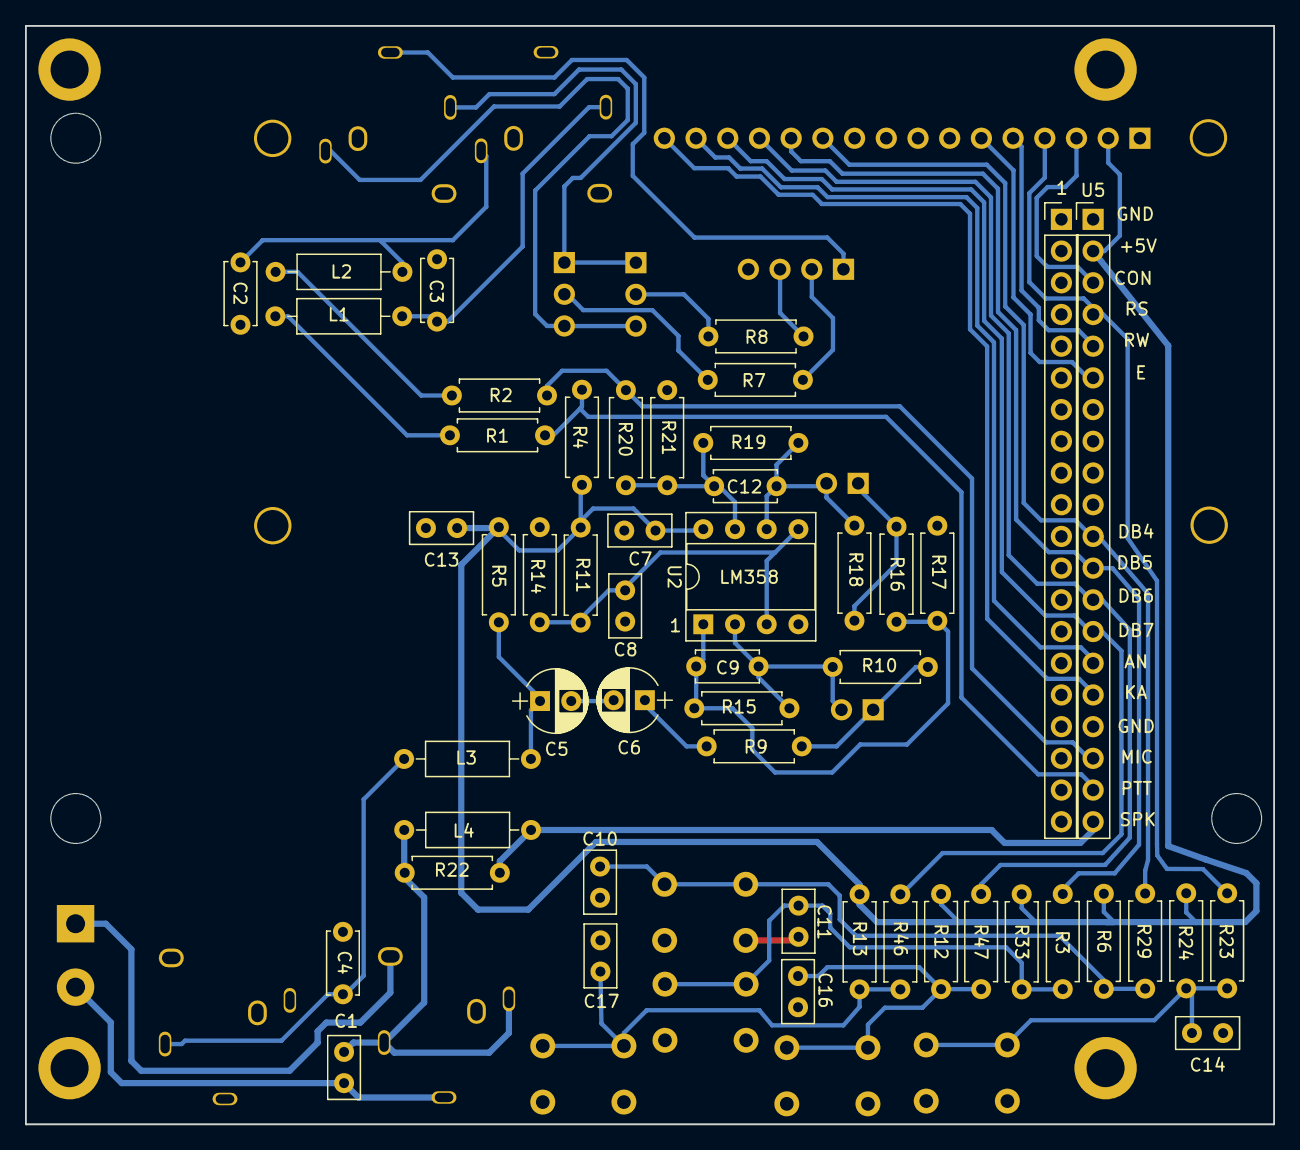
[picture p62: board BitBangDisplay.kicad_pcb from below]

Board: 2 copper layers, 100.0 x 88.0 mm, 78 parts (51 on the bottom side), 44 nets.

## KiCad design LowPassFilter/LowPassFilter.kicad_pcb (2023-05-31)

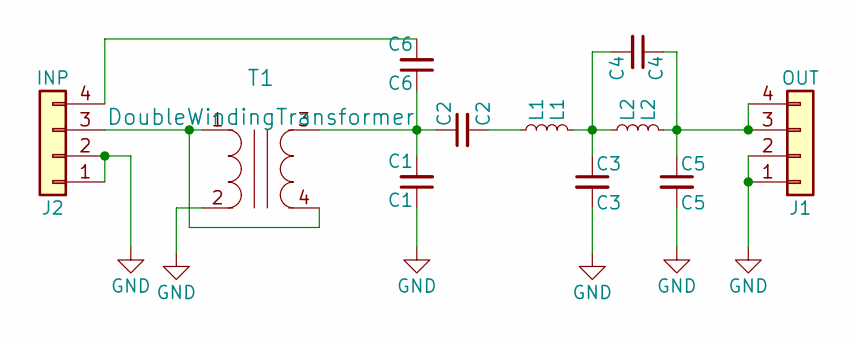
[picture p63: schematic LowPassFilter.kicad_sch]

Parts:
C1: C1; C_Disc_D5.0mm_W2.5mm_P5.00mm_Dual
C2: C2; C_Disc_D5.0mm_W2.5mm_P5.00mm_Dual
C3: C3; C_Disc_D5.0mm_W2.5mm_P5.00mm_Dual
C4: C4; C_Disc_D5.0mm_W2.5mm_P5.00mm_Dual
C5: C5; C_Disc_D5.0mm_W2.5mm_P5.00mm_Dual
C6: C6; C_Disc_D5.0mm_W2.5mm_P5.00mm_Dual
J1: OUT; Pin_Header_Straight_1x04_Pitch2.54mm
J2: INP; Pin_Header_Straight_1x04_Pitch2.54mm
L1: L1; L_Toroid_Horizontal_D12.7mm_Compact
L2: L2; L_Toroid_Horizontal_D12.7mm_Compact
T1: DoubleWindingTransformer; DoubleWindingTransformerHorizontal

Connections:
GND: C1.1, C3.2, C5.2, J1.1, J1.2, J2.1, J2.2, T1.2
unnamed: C1.2, C2.1, C6.1, T1.3
unnamed: C2.2, L1.1
unnamed: C6.2, J2.4
unnamed: J2.3, T1.1, T1.4
unnamed: C3.1, C4.2, L1.2, L2.1
unnamed: C4.1, C5.1, J1.3, J1.4, L2.2

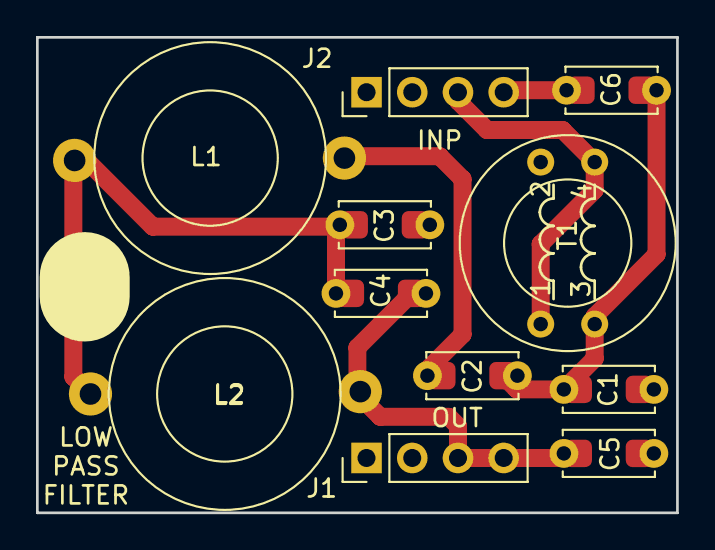
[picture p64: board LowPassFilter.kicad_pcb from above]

Board: 2 copper layers, 35.6 x 26.4 mm, 11 parts (0 on the bottom side), 7 nets.

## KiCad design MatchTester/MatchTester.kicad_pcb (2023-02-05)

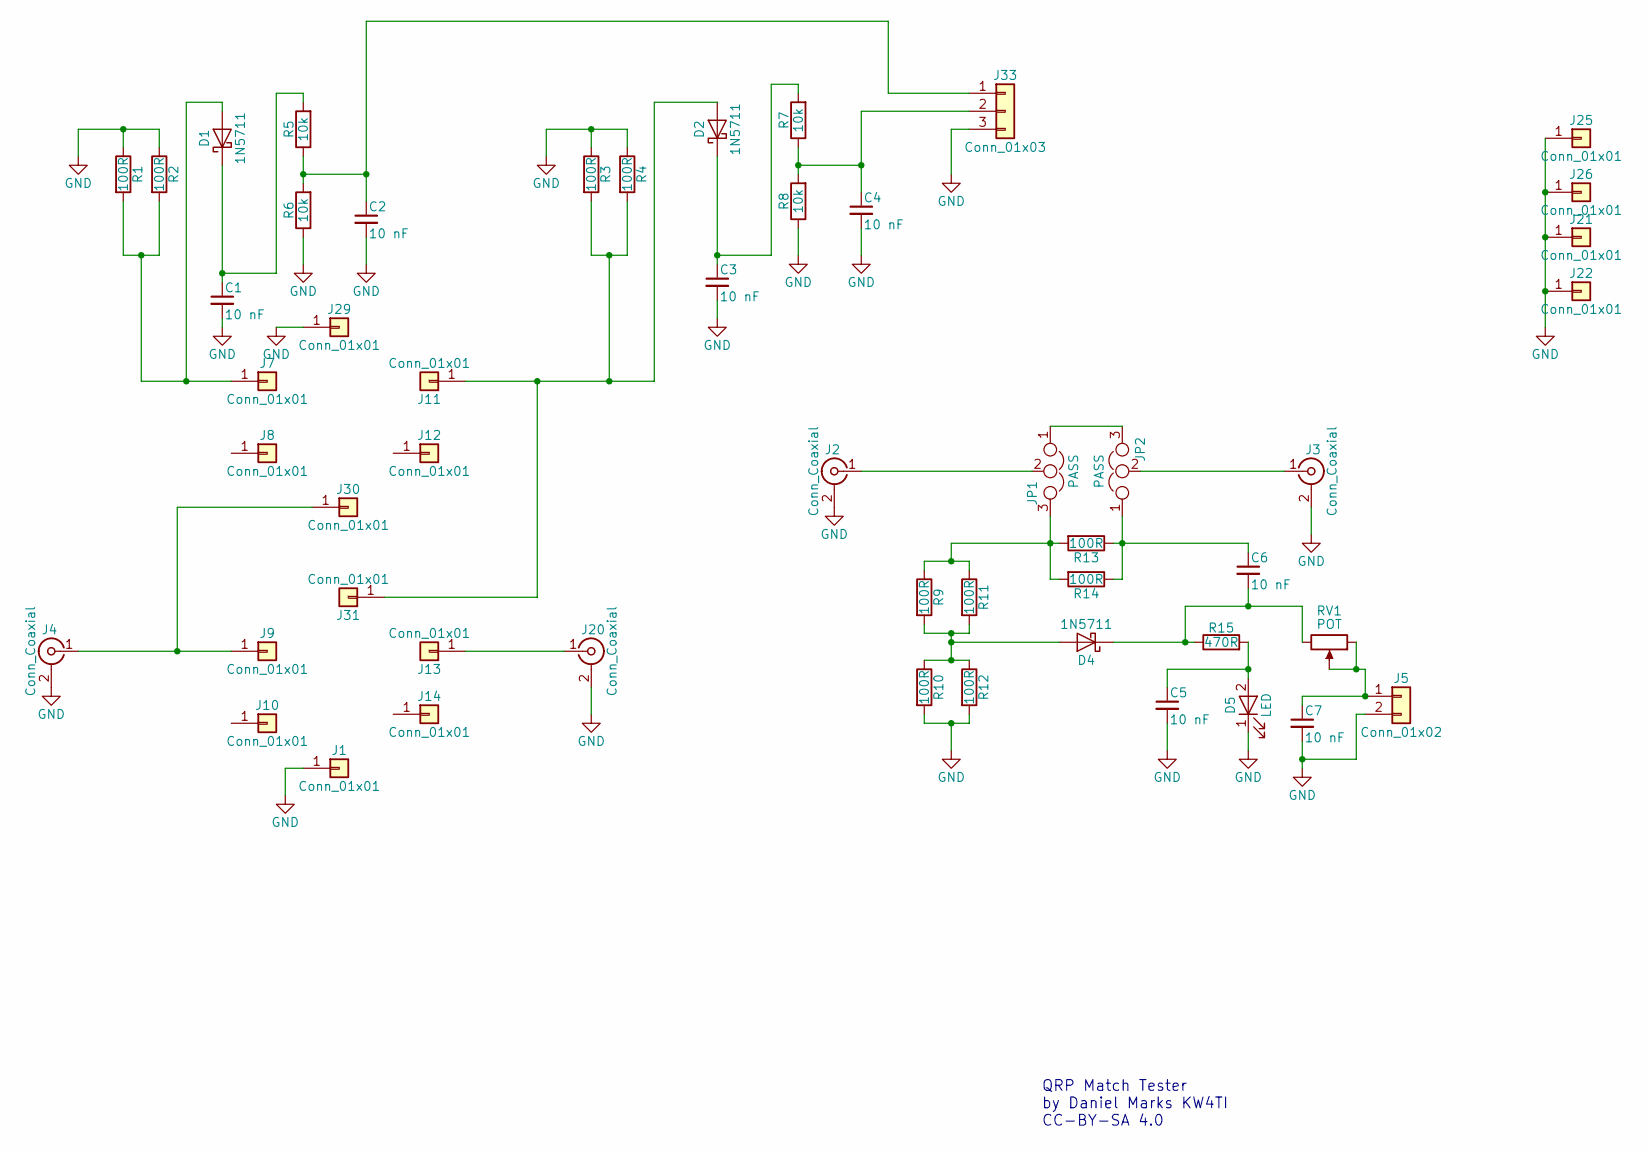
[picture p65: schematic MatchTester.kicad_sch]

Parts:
C1, C2, C3, C4: 10 nF; C_Disc_D5.0mm_W2.5mm_P5.00mm
C5, C6, C7: 10 nF; C_Disc_D5.0mm_W2.5mm_P2.50mm
D1, D2, D4: 1N5711; D_DO-35_SOD27_P7.62mm_Horizontal
D5: LED; LED_D5.0mm
J1, J7, J8, J9, J10, J11, J12, J13, J14, J21, J22, J25, J26, J29, J30, J31: Conn_01x01; 1pin
J2, J3, J4, J20: Conn_Coaxial; bnc_90_1-1337543-0_pad_combo
J5: Conn_01x02; Pin_Header_Straight_1x02_Pitch2.54mm
J33: Conn_01x03; Pin_Header_Straight_1x03_Pitch2.54mm
JP1, JP2: PASS; Pin_Header_Straight_1x03_Pitch2.54mm
R1, R2, R3, R4, R9, R10, R11, R12, R13, R14: 100R; R_Axial_DIN0309_L9.0mm_D3.2mm_P12.70mm_Horizontal
R5, R6, R7, R8: 10k; R_Axial_DIN0207_L6.3mm_D2.5mm_P7.62mm_Horizontal
R15: 470R; R_Axial_DIN0207_L6.3mm_D2.5mm_P7.62mm_Horizontal
RV1: POT; Potentiometer_Trimmer_Bourns_3296W

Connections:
GND: C1.2, C2.2, C3.2, C4.2, C5.2, C7.2, D5.1 (K), J1.1, J2.2 (Ext), J3.2 (Ext), J4.2 (Ext), J5.2, J20.2 (Ext), J21.1, J22.1, J25.1, J26.1, J29.1, J33.3, R1.1, R2.1, R3.1, R4.1, R6.1, R8.1, R10.2, R12.2
unnamed: C2.1, J33.1, R5.1, R6.2
unnamed: C4.1, J33.2, R7.1, R8.2
unnamed: C6.1, JP2.1, R13.1, R14.1
unnamed: C6.2, D4.1 (K), R15.1, RV1.3
unnamed: C7.1, J5.1, RV1.1, RV1.2
unnamed: D2.2 (A), J11.1, J31.1, R3.2, R4.2
unnamed: D4.2 (A), R9.2, R10.1, R11.2, R12.1
unnamed: C5.1, D5.2 (A), R15.2
unnamed: J2.1 (In), JP1.2
unnamed: J3.1 (In), JP2.2
unnamed: J13.1, J20.1 (In)
unnamed: J4.1 (In), J9.1, J30.1
unnamed: JP1.1, JP2.3
unnamed: D1.2 (A), J7.1, R1.2, R2.2
unnamed: C1.1, D1.1 (K), R5.2
unnamed: C3.1, D2.1 (K), R7.2
unnamed: JP1.3, R9.1, R11.1, R13.2, R14.2

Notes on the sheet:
QRP Match Tester by Daniel Marks KW4TI CC-BY-SA 4.0

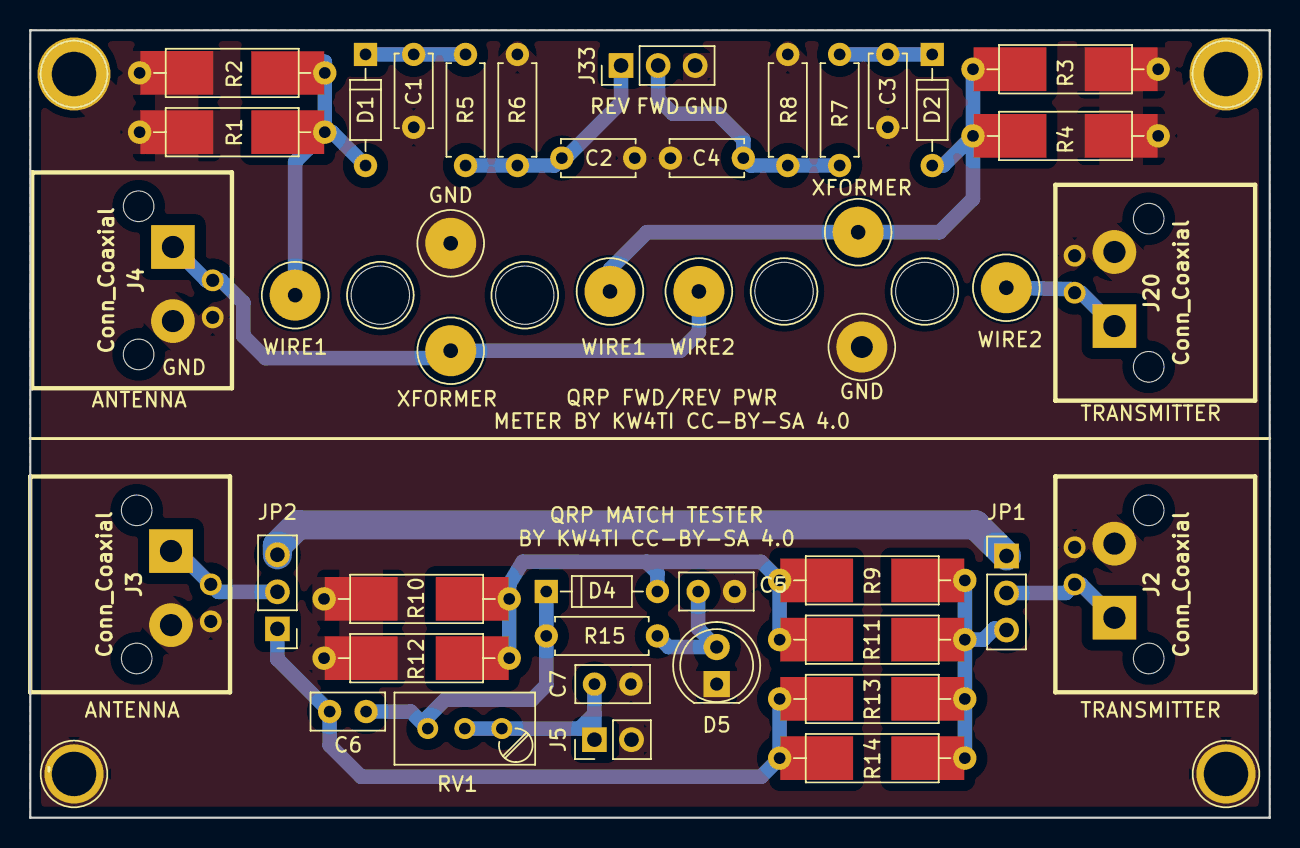
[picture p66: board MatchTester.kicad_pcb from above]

Board: 2 copper layers, 85.0 x 54.0 mm, 51 parts (0 on the bottom side), 18 nets.

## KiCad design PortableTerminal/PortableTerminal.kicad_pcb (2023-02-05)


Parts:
C1, C3, C8: 100 uF; CP_Radial_D5.0mm_P2.50mm
C2, C4, C7, C9, C10, C12, C13: 100 nF; C_Disc_D5.0mm_W2.5mm_P2.50mm
C5, C6: 20 pF; C_Disc_D5.0mm_W2.5mm_P5.00mm
C11: 10 nF; C_Disc_D5.0mm_W2.5mm_P2.50mm
D1, D2, D3, D5, D6, D7: 1N4148; D_DO-35_SOD27_P7.62mm_Horizontal
D4: LED; LED_D3.0mm
J1: Barrel_Jack; BARREL_JACK
J2, J3, J5, J6: Conn_01x01; 1pin
J4: ICSP; Pin_Header_Straight_2x03_Pitch2.54mm
J7, J8: Conn_01x04; Pin_Header_Straight_1x04_Pitch2.54mm
J9, J10: RCAJack; RCAConnectorCommon
J11: Conn_01x02; TerminalBlock_bornier-2_P5.08mm
J12: Conn_Coaxial; bnc_90_1-1337543-0_pad_combo
JP1, JP2: PWR; Pin_Header_Straight_1x02_Pitch2.54mm
JP3: Load; Pin_Header_Straight_1x02_Pitch2.54mm
P1: Mini-DIN_6pins_ver4; Connector_Mini-DIN_Female_6Pin_2rows
Q1, Q2: 2N3904; TO-92_Inline_Wide
R1, R2, R3, R16, R17, R19, R20, R21, R24, R29: 10k; R_Axial_DIN0207_L6.3mm_D2.5mm_P7.62mm_Horizontal
R4, R5, R7, R9, R11, R13, R15, R18: 1k; R_Axial_DIN0207_L6.3mm_D2.5mm_P7.62mm_Horizontal
R6: 150R; R_Axial_DIN0207_L6.3mm_D2.5mm_P7.62mm_Horizontal
R8, R10, R12, R14, R25, R26: 470R; R_Axial_DIN0207_L6.3mm_D2.5mm_P7.62mm_Horizontal
R22, R23: 100R; R_Axial_DIN0309_L9.0mm_D3.2mm_P12.70mm_Horizontal
R27: 100R; R_Axial_DIN0207_L6.3mm_D2.5mm_P7.62mm_Horizontal
R28: 100k; R_Axial_DIN0207_L6.3mm_D2.5mm_P7.62mm_Horizontal
RV1: POT; Potentiometer_Triwood_RM-065
SW1: SW_Push; SW_PUSH_6mm
T1: Common-Mode Choke; DoubleWindingTransformer
U1: LM7805_TO220; TO-220-3_Vertical
U2: ATMEGA328P-PU; DIP-28_W7.62mm_Socket
U3: LCD-016N002L; Pin_Header_Straight_1x16_Pitch2.54mm
U4: MicroSD_SPI_CD; GCT-MEM2055-00-190-01-A
U5: 74HC74; DIP-14_W7.62mm_Socket
Y1: Crystal; Crystal_HC49-U_Vertical

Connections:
+5V: C3.1, C4.1, C8.1, C10.1, D1.1 (K), D2.2 (A), D6.1 (K), J7.4, JP1.1, P1.4, R1.2, R2.2, R3.2, R6.1, R16.1, R17.2, R18.2, R20.2, RV1.1, U1.3 (VO), U2.7 (VCC), U2.20 (AVCC), U3.2 (VDD), U5.1 (Cd), U5.4 (Sd), U5.10 (Sd), U5.14 (VCC)
+12V: C1.1, C13.1, T1.2, U1.1 (VI)
CS: R14.2, U2.16 ((PCINT2/OC1B/~SS)PB2)
DB4: R28.1, R29.2, U2.23 ((PCINT8/ADC0)PC0), U3.11 (DB4)
DB5: U2.24 ((PCINT9/ADC1)PC1), U3.12 (DB5)
DB6: U2.25 ((PCINT10/ADC2)PC2), U3.13 (DB6)
DB7: U2.26 ((PCINT11/ADC3)PC3), U3.14 (DB7)
E: U2.14 ((PCINT0/CLKO/ICP1)PB0), U3.6 (E)
GND: C1.2, C3.2, C4.2, C5.1, C6.1, C7.2, C8.2, C10.2, C11.2, C13.2, D4.1 (K), D5.2 (A), J2.1, J3.1, J4.6, J5.1, J6.1, J7.1, J8.1, J9.1 (SHIELD), J10.1 (SHIELD), J12.2 (Ext), JP2.2, P1.3, P1.7 (Shell), Q1.1 (E), Q2.1 (E), R5.1, R9.1, R11.1, R13.1, R15.1, R22.1, R23.1, R24.1, R29.1, RV1.3, SW1.1, T1.4, U1.2 (GND), U2.8 (GND), U2.22 (GND), U3.1 (VSS), U3.5 (R/~W), U4.6 (GND), U5.7 (GND)
MISO: J4.1, U2.18 ((PCINT4/MISO)PB4), U4.7 (DO)
MOSI: J4.4, R4.2, R10.2, U2.17 ((PCINT3/OC2A/MOSI)PB3)
MUTE: R19.2, R25.1, U2.11 ((PCINT21/OC0B/T1)PD5)
unnamed: C2.2, J8.4
unnamed: C5.2, U2.9 ((PCINT6/XTAL1/TOSC1)PB6), Y1.2
unnamed: C6.2, U2.10 ((PCINT7/XTAL2/TOSC2)PB7), Y1.1
unnamed: C9.1, R26.2
unnamed: D2.1 (K), D3.2 (A)
unnamed: D4.2 (A), R18.1
unnamed: D7.1 (K), R27.2
unnamed: C9.2, D7.2 (A), J12.1 (In), JP3.2
unnamed: J4.2, JP1.2
unnamed: J10.2 (PIN), R7.1, R8.1
unnamed: C12.1, J1.1, J11.1, T1.1
unnamed: C12.2, J1.2, J11.2, T1.3
unnamed: JP3.1, R22.2, R23.2
unnamed: Q1.2 (B), R19.1
unnamed: J9.2 (PIN), Q1.3 (C), R4.1, R5.2
unnamed: Q2.2 (B), R21.2
unnamed: Q2.3 (C), U3.16 (K)
unnamed: R6.2, U3.15 (A/VEE)
unnamed: R7.2, R21.1, U2.15 ((PCINT1/OC1A)PB1)
unnamed: R8.2, U2.13 ((PCINT23/AIN1)PD7)
unnamed: C7.1, D3.1 (K), R9.2, U4.4 (VDD)
unnamed: D5.1 (K), D6.2 (A), R24.2, R26.1, U5.3 (Cp)
unnamed: R25.2, U5.9 (Q)
unnamed: C11.1, R27.1, R28.2
unnamed: RV1.2, U3.3 (VO)
unnamed: JP2.1, R20.1, U2.6 ((PCINT20/XCK/T0)PD4)
unnamed: R14.1, R15.2, U4.2 (~CS)
unnamed: R10.1, R11.2, U4.3 (DI)
unnamed: R12.1, R13.2, U4.5 (SCLK)
unnamed: U5.2 (D), U5.6 (~Q)
unnamed: U5.5 (Q), U5.11 (Cp)
unnamed: U5.8 (~Q), U5.12 (D)
PS2CLK: P1.5, R16.2, U2.5 ((PCINT19/OC2B/INT1)PD3)
PS2DATA: P1.1, R17.1, U2.4 ((PCINT18/INT0)PD2)
RESET: C2.1, D1.2 (A), J4.5, R1.1, SW1.2, U2.1 ((PCINT14/~RESET)PC6)
RS: U2.12 ((PCINT22/OC0A/AIN0)PD6), U3.4 (RS), U5.13 (Cd)
RX: J8.3, U2.2 ((PCINT16/RXD)PD0)
SCK: J4.3, R12.2, U2.19 ((PCINT5/SCK)PB5)
SCL: J7.2, R3.1, U2.28 ((PCINT13/SCL/ADC5)PC5)
SDA: J7.3, R2.1, U2.27 ((PCINT12/SDA/ADC4)PC4)
TX: J8.2, U2.3 ((PCINT17/TXD)PD1)


Board: 2 copper layers, 79.0 x 75.0 mm, 76 parts (0 on the bottom side), 53 nets.

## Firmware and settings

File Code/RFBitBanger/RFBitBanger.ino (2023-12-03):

/* RFBitBanger.ino

*/

/*
   Copyright (c) 2021 Daniel Marks

  This software is provided 'as-is', without any express or implied
  warranty. In no event will the authors be held liable for any damages
  arising from the use of this software.

  Permission is granted to anyone to use this software for any purpose,
  including commercial applications, and to alter it and redistribute it
  freely, subject to the following restrictions:

  1. The origin of this software must not be misrepresented; you must not
   claim that you wrote the original software. If you use this software
   in a product, an acknowledgment in the product documentation would be
   appreciated but is not required.
  2. Altered source versions must be plainly marked as such, and must not be
   misrepresented as being the original software.
  3. This notice may not be removed or altered from any source distribution.
*/

#include <Arduino.h>
#include <wiring_private.h>
#include <avr/pgmspace.h>
#include <EEPROM.h>
#include "common.h"
#include "si5351simple.h"
#include "LiquidCrystalButtons.h"
#include "PS2Keyboard.h"
#include "RFBitBanger.h"
#include "ui.h"

#include "dspint.h"
#include "cwmod.h"
#include "scamp.h"
#include "rtty.h"
#include "ssb.h"

LiquidCrystalButtons lcd(LCDB_RS, LCDB_E, LCDB_DB4, LCDB_DB5, LCDB_DB6, LCDB_DB7);
si5351simple si5351(8,25000000u);
PS2Keyboard PSkey;
radio_configuration rc;

const radio_configuration PROGMEM default_rc =
{
  RC_MAGIC_NUMBER,  /* magic_number */
  25000000,  /* frequency_calibratin */
  20,  /* cw_send_speed */
  0,   /* scamp_resync_frames */
  1,   /* scamp_ressend_frames */
  2,   /* rtty_figs_resend */
  667, /* sidetone_frequency */
  1,   /* sidetone_on */
  0,   /* cw_practice */
  0,   /* wide */
  0,   /* ext_fast_mode */
  0,   /* ext_lsb */
  0,   /* band_warning_off */
  0,   /* spaces from mark timing */
  0,   /* cw smooth */
  4,   /* cw sticky interval length */
  0,   /* rit_shift_freq */
  0,   /* rit_shift_dir */
  0,   /* cw_iambic */
  0,   /* cw_iambic_type */
  0,   /* cw_iambic_switch */
  0,   /* erase_on_send */
  8,   /* ssb gain */
  1,   /* backlight */
  7100000  /* default frequency */
};

volatile uint16_t adc_sample_1;

uint8_t mute = 0;

uint8_t srd_buffer[160];
scroll_readout_dat srd_buf = { 0, 1, 16, sizeof(srd_buffer), srd_buffer, 0 };

uint8_t sad_buffer[160];
const uint8_t sad_validchars[] PROGMEM = { ' ',    '!',   0x22,   0x27,    '(',
                                           ')',    '*',    '+',    ',',    '-',    '.',    '/',    '0',
                                           '1',    '2',    '3',    '4',    '5',    '6',    '7',    '8',
                                           '9',    ':',    ';',    '=',    '?',    '@',    'A',    'B',
                                           'C',    'D',    'E',    'F',    'G',    'H',    'I',    'J',
                                           'K',    'L',    'M',    'N',    'O',    'P',    'Q',    'R',
                                           'S',    'T',    'U',    'V',    'W',    'X',    'Y',    'Z',
                                           0x5C,   '^',    '`',    '~' };
                                     
scroll_alpha_dat sad_buf = { 0, 0, 16, sizeof(sad_buffer), sad_buffer, sad_validchars, sizeof(sad_validchars), 0, 0, 0, 0 };

scroll_number_dat snd_freq = { 0, 0, 8, 0, 500000, 29999999, 0, 7000000, 0, 0 };
bargraph_dat bgs = { 4, 12, 0 };

uint8_t adc1_read = 0;

bool check_band_warning(void);

void setupConfiguration(void)
{
  EEPROM.get(EEPROM_CONFIGURATION_ADDRESS, rc);
  if (rc.magic_number != RC_MAGIC_NUMBER)
    memcpy_P((void *)&rc,(void *)&default_rc,sizeof(rc));
  snd_freq.n = rc.default_frequency;
}

void saveConfiguration(void)
{
  EEPROM.put(EEPROM_CONFIGURATION_ADDRESS, rc);
}

void setupADC() {
  ADCSRA = 0;
  PRR &= ~PRADC;
  //ADCSRB = (1 << ADTS2) | (1 << ADTS1);
  ADCSRB = 0;
  ADCSRA = (1 << ADEN) | (1 << ADPS1) | (1 << ADPS0);
  ADCSRA = (1 << ADEN) | (1 << ADPS1) | (1 << ADPS0) | (1 << ADSC);  
  ADMUX = (1 << REFS0);
  DIDR1 = 0;
}

void setupCompare()
{
  cli();
  ADCSRA = 0;
  ADMUX = (1 << REFS0) | (1 << MUX0);
  ADCSRB = (1<<ACME);               // select ADC1 as the source for negative comparator input
  ACSR = (1<<ACBG) | (1<<ACIC);     // select ACBG for positive comparator input, falling edge interrupt
  DIDR1 = 0;
  sei();
}

void stopCompare()
{
  ACSR = (1<<ACD);
  setupADC();
}

void setup_timers_external_control(void)
{
  cli();
  TCCR1A = 0;  
  TCCR1B = (1<<CS10);
  TCCR1B = (1<<ICNC1) | (1<<CS10);  
  ICR1 = 0;
  TCNT1 = 0;
  TIMSK1 = 0;
  TIMSK2 = 0;
  sei();
}

uint16_t external_control_time(void)
{
  uint16_t start_time, end_time;
  TCNT1 = 0;
  while ((ACSR & (1<<ACO)) != 0)
  {
    TCNT1L;
    if (TCNT1H >= 0xF0) return 0; 
  }
  while ((ACSR & (1<<ACO)) == 0)
  {
    TCNT1L;
    if (TCNT1H >= 0xF0) return 0;
  }
  TCNT1 = 0;
  while ((ACSR & (1<<ACO)) != 0)
  {
    TCNT1L;
    if (TCNT1H >= 0xF0) return 0; 
  }
  start_time = ICR1;
  while ((ACSR & (1<<ACO)) == 0)
  {
    TCNT1L;
    if (TCNT1H >= 0xF0) return 0; 
  }
  while ((ACSR & (1<<ACO)) != 0)
  {
    TCNT1L;
    if (TCNT1H >= 0xF0) return 0;
  }
  end_time = ICR1;
  return (end_time - start_time);
}

void ssb_debug(void)
{
#ifdef SSB_DEBUG_REGISTERS
  static uint16_t last_millis = 0;
  uint16_t cur_millis = millis();
  uint8_t act = ds.ssb_active;
  
  if ((uint16_t)(cur_millis-last_millis) < 1000) return;
  last_millis = cur_millis;

  cli();
  int16_t last_sample = ps.ssbs.last_sample;
  int16_t last_sample2 = ps.ssbs.last_sample2;
  uint16_t magnitude = ps.ssbs.magnitude;
  int16_t previous_phase = ps.ssbs.previous_phase;
  uint32_t l = ps.ssbs.no_interrupts;
  sei();

  Serial.print("\r\nprotocol=");
  Serial.print(ps.ssbs.protocol);
  Serial.print(",");
  Serial.println(act);
  Serial.print("last_samples=");
  Serial.print(last_sample);
  Serial.print(",");
  Serial.println(last_sample2);
  Serial.print("cum=");
  Serial.println(ps.ssbs.cumulative_sample);
  Serial.print("dc_level=");
  Serial.println(ps.ssbs.dc_level);
  Serial.print("lpf_z1=");
  Serial.println(ps.ssbs.lpf_z1);
  Serial.print("previous_phase=");
  Serial.println(previous_phase);
  Serial.print("magnitude=");
  Serial.println(magnitude);
  Serial.print("phase_difference=");
  Serial.println(ps.ssbs.phase_difference);
  Serial.print("frequency_shift=");
  Serial.println(ps.ssbs.frequency_shift);
  Serial.print("no_interrupts=");
  static uint32_t last_interrupts = 0;
  Serial.println(l);
  Serial.print("x_interrupts=");
  Serial.println(l - last_interrupts);
  last_interrupts = l;
  Serial.print("phase_inversions=");
  Serial.println(ps.ssbs.phase_inversions);
#endif
}

extern "C" {
  void idle_task(void)
  {
    dsp_dispatch_receive();
    lcd.pollButtons();
    if (IS_SSB_PROTOCOL(ps.ssbs.protocol))
    {
      ssb_state_change(!digitalRead(PTT_PIN));
      //ssb_state_change(1);
  #ifdef SSB_DEBUG_REGISTERS
      ssb_debug();
  #endif
    }
  }
}

#define SET_ADC1_READ(x) adc1_read = (x)

#define SET_SSB_INTERRUPT_MODE(x) (ds.ssb_active) = (x)

ISR(TIMER1_OVF_vect)
{
  static uint8_t avgs = 0;
  static uint16_t totaladc = 0;
  uint16_t adc_sample = ADC;
  //sei();
  if (ds.ssb_active)
  {
    ssb_interrupt((int16_t)adc_sample);
    return;
  }
  if (adc1_read != 0)
  {
    ADMUX = (avgs == (OVERSAMPLING_CLOCKS-1)) ? ((1 << REFS0) | (1 << MUX0)) : (1 << REFS0);
    if (avgs == 0) 
      adc_sample_1 = adc_sample;
    else
      totaladc += adc_sample;
  } else
  {
    ADMUX = (1 << REFS0);
    totaladc += adc_sample;
  }
  ADCSRA = (1 << ADEN) | (1 << ADPS1) | (1 << ADPS0) | (1 << ADSC);  
  if ((++avgs) >= OVERSAMPLING_CLOCKS)
  {
    dsp_interrupt_sample(totaladc / OVERSAMPLING_CLOCKS);
    dsp_dispatch_interrupt();
    totaladc = 0;
    avgs = 0;    
  }
}

void setup_timers(void)
{
  cli();
  // WGM13 = 1, WGM12 = 1, WGM11 = 1, WGM10 = 0
  TCCR1A = (1<<COM1B1) | (1<<WGM11);  
  TCCR1B = (1<<CS10);
  TCCR1B = (1<<WGM13) | (1<<WGM12) | (1<<CS10);
  ICR1 = TIMER1_COUNT_MAX;
  set_transmit_pwm(1);
  set_tuning_pwm(0);
  TIMSK1 = (1<<TOIE1);
  TIMSK2 = 0;
  sei();
}

uint8_t tone_state = 0;
uint8_t tone_last_freq = 0;

extern "C" {
  void tone_off(void)
  {
    if (tone_state)
    {
      pinMode(BEEPOUT_PIN,INPUT);
      tone_state = 0;
    }
  }

  void tone_on(uint8_t freq, uint8_t vol)
  {
    if ((!tone_state) || (freq != tone_last_freq))
    {
      if (!tone_state) pinMode(BEEPOUT_PIN,OUTPUT);  
      TCCR2B = 0;
      OCR2A = freq;
      OCR2B = vol;
      TCNT2 = 0;
      TCCR2A = (1<<COM2B1) | (1 << WGM21) | (1 << WGM20);
      TCCR2B = (1 << WGM22) | (1<<CS22) | (1<<CS21);   // 256 divider
      tone_last_freq = freq;
      tone_state = 1;
    } else
      OCR2B = vol;
  }
  
  void test_tone(uint16_t freq)
  {
    uint8_t freqt = TONEFREQ(freq);
    tone_on(freqt,freq/2);
    delay(500);
    tone_off();
  }

}   /* extern 'C' */

void setup_tone_pcm(void)
{
   TCCR2B = (1 << CS20);  // 1 divider
   TCCR2A = (1<<COM2B1) | (1 << WGM21) | (1 << WGM20); // fast pwm
   TCNT2 = 0;
   OCR2B = 0;
   pinMode(BEEPOUT_PIN,OUTPUT);
}

extern "C" {

  void delayidle(uint32_t ms)
  {
          uint32_t start = micros();
  
          while (ms > 0) {
                  idle_task();
                  while ( ms > 0 && (micros() - start) >= 1000) {
                        ms--;
                        start += 1000;
                  }
          }
  }

  void muteaudio_set(uint8_t seton)
  {
    digitalWrite(MUTEAUDIO_PIN, seton != 0);
  }

  void transmit_set(uint8_t seton)
  {
    //OCR1A = seton != 0 ? TIMER1_COUNT_MAX : 0; 
    digitalWrite(TRANSMIT_PIN, seton != 0);
  }

  void set_clock_onoff_mask(uint8_t on_mask)
  {
    si5351.setOutputOnOffMask(on_mask);
  }

  void set_clock_onoff(uint8_t onoff, uint8_t clockno)
  {
    si5351.setOutputOnOff(clockno,onoff != 0);  
  }

  void set_protocol(uint8_t protocol)
  {
    if (protocol == 0xFF) protocol = ps.ns.protocol;
    dsp_initialize_protocol(protocol, rc.wide);
   set_frequency_receive();
  }

  void set_frequency_offset(int16_t offset)
  {
    si5351.set_offset_fast(offset);
  }


  void set_transmit_pwm(uint16_t pwm) 
  {
    OCR1A = pwm;  
  };

  void set_tuning_pwm(uint16_t pwm)
  {
    OCR1B = pwm;
  };

  void transmit_pwm_mode(uint8_t set)
  {
    if (set) TCCR1A |= ((1 << COM1A1));
      else TCCR1A &= ~((1 << COM1A1));
    TCCR1A &= ~((1 << COM1A0));
  }

  void set_frequency(uint32_t freq, uint8_t clockno)
  {
    si5351_synth_regs s_regs;
    si5351_multisynth_regs m_regs;

#ifdef SSB_PROTOCOL
    if (ds.ssb_active) ssb_state_change(0);
#endif
     si5351.calc_registers(freq, 0, 0, &s_regs, &m_regs, clockno == 0 ? &c_regs : NULL);
    si5351.set_registers(clockno, &s_regs, clockno, &m_regs);
    //si5351.print_c_regs();
  }

  void set_frequency_both(uint32_t freq)
  {
    si5351_synth_regs s_regs;
    si5351_multisynth_regs m_regs;
  
#ifdef SSB_PROTOCOL
     if (ds.ssb_active) ssb_state_change(0);
#endif
     si5351.calc_registers(freq, 0, IS_SSB_PROTOCOL(ps.ssbs.protocol), &s_regs, &m_regs, &c_regs);

    si5351.set_registers(1, &s_regs, 1, &m_regs);
    si5351.set_registers(0, &s_regs, 0, &m_regs);
  }

  static uint8_t chno = 0;
  static uint16_t last_millis_ch = 0;

  void write_char_newline(const char *c)
  {
    Serial.print("\r\n");
    Serial.print(c);
    chno = 0;
  }

  void write_char_serial(char ch)
  {
    uint16_t current_millis = millis();
    if (((current_millis - last_millis_ch) > WRITE_CHAR_SERIAL_RETURN_DELAY) || ((chno > 65) && (ch == ' ')) || (chno > 75))
      write_char_newline(NULL);
    last_millis_ch = current_millis;
    Serial.print(ch);
    chno++;
  }

  void received_character(uint8_t ch)
  {
    if (ch == '\b')
      scroll_readout_back_character(&srd_buf,' ');
    else if ((ch >= ' ') && (ch <= '~'))
      scroll_readout_add_character(&srd_buf, ch);
    write_char_serial((char)ch);
  }
}  /* extern 'C' */

void set_frequency_receive(void)
{
  muteaudio_set(0);
  transmit_set(0);
  set_frequency_both(snd_freq.n + dsp_freq_offset() + (rc.rit_shift_dir ? - rc.rit_shift_freq : rc.rit_shift_freq));
  set_clock_onoff_mask(0x01);
}

void set_frequency_snd(void)
{
  muteaudio_set(0);
  transmit_set(0);
  set_frequency_both(snd_freq.n);
  set_clock_onoff_mask(0x01);
}

void set_backlight(void)
{
  digitalWrite(BACKLIGHT_PIN, rc.backlight);
}

void setup() {
  setupConfiguration();
  si5351.set_xo_freq(rc.frequency_calibration);
  set_protocol(PROTOCOL_CW);
  setupADC();
  stopCompare();
  setup_timers();
  scroll_readout_initialize(&srd_buf);
  PSkey.begin();
  Serial.begin(DEFAULT_BAUDRATE);
  pinMode(PTT_PIN,INPUT);
  pinMode(MIC_PIN,INPUT);
  pinMode(AUDIOFILT_PIN,INPUT);
  pinMode(TRANSMIT_PIN,OUTPUT);
  pinMode(BACKLIGHT_PIN,OUTPUT);
  pinMode(MUTEAUDIO_PIN,OUTPUT);
  TONE_OFF();
  si5351.start();
  set_frequency_receive();
  lcd.begin(20,4);
  transmit_set(0);
  muteaudio_set(0);
  set_backlight();
}

#define UPDATE_MILLIS_BARS 100

uint8_t map_16_to_bar_40(uint16_t b)
{
  if (b < 64)
    return (b >> 3);                  // 0 to 64 is 0 to 7
  if (b < 192)
    return (b >> 4) + 4;              // 64 to 192 is 8 to 15
  if (b < 448)
    return (b >> 5) + 10;             // 192 to 448 is 16 to 23
  if (b < 960)
    return (b >> 6) + 17;             // 448 to 960 is 24 to 32
  if (b < 2048)
    return (b >> 7) + 24;             // 960 and up is 32 to 40
  return 40;
}

uint8_t map_16_to_bar_20(uint16_t b)
{
  return map_16_to_bar_40(b << 1) >> 1;
}

void scroll_redraw_snd(void)
{
  scroll_number_redraw(&snd_freq);
}

#define PTSAMPLECT ((volatile uint8_t *)&ds.sample_ct)

uint16_t accumulate_all_channels(uint8_t ct)
{
  uint8_t last = *PTSAMPLECT;
  uint32_t total = 0;
  while (ct>0)
  {
    uint8_t sample_ct = *PTSAMPLECT;
    if (last != sample_ct)
    {
      last = sample_ct;
      total += dsp_get_signal_magnitude();
      ct--;
    }
  } 
  return total >> 8;
}

void update_bars()
{
  static uint16_t last_update_bars;
  uint16_t cur_update = millis();
  if ((cur_update - last_update_bars) >= UPDATE_MILLIS_BARS)
  {
    last_update_bars = cur_update;
    bgs.bars = ds.ssb_active ? (ssb_get_magnitude()*20)/256 : map_16_to_bar_20(dsp_get_signal_magnitude());
    lcdBarGraph(&bgs);
  }
}

void update_readout()
{
  scroll_readout_display(&srd_buf);  
}

void redraw_readout()
{
  srd_buf.notchanged = 0;
  update_readout();  
}


const char transmittitle[] PROGMEM = "Tx ";
const char receivetitle[] PROGMEM = "Rxv";
const char freqmenutitle[] PROGMEM = "Frq";
const char scanfasttitle[] PROGMEM = "ScF";
const char scanslowtitle[] PROGMEM = "ScS";
const char tranmodetitle[] PROGMEM = "TrM";
const char extctrlmode[] PROGMEM = "Ext";
const char confmodetitle[] PROGMEM = "Cfg";
const char keymodetitle[] PROGMEM = "Key";

const char *const mainmenu[] PROGMEM = {transmittitle,receivetitle,freqmenutitle,scanfasttitle,scanslowtitle,tranmodetitle,keymodetitle,extctrlmode,confmodetitle,NULL };

const char back_title[] PROGMEM = "Back";
const char cw_title[] PROGMEM = "CW";
const char usb_title[] PROGMEM = "USB";
const char lsb_title[] PROGMEM = "LSB";
const char rtty_title[] PROGMEM = "RTTY";
const char rtty_rev_title[] PROGMEM = "RTTYREV";
const char scamp_fsk_title[] PROGMEM = "SCAMPFSK";
const char scamp_ook_title[] PROGMEM = "SCAMPOOK";
const char scamp_fsk_fast_title[] PROGMEM = "SCFSKFST";
#ifdef SCAMP_VERY_SLOW_MODES
const char scamp_fsk_slow_title[] PROGMEM = "SCFSKSLW";
const char scamp_ook_slow_title[] PROGMEM = "SCOOKSLW";
const char scamp_fsk_vslw_title[] PROGMEM = "SCFSKVSL";
#endif

const char *const protocolmenu[] PROGMEM = {back_title,cw_title,usb_title,lsb_title,rtty_title,rtty_rev_title,scamp_fsk_title,scamp_ook_title,scamp_fsk_fast_title,
#ifdef SCAMP_VERY_SLOW_MODES
    scamp_fsk_slow_title,scamp_ook_slow_title,scamp_fsk_vslw_title,
#endif
    NULL };

//const char righttx[] PROGMEM = "Rt Txmit Lf Abt";

void increment_decrement_frequency(int16_t val)
{
  int32_t next_freq = snd_freq.n + val;
  if (next_freq < snd_freq.minimum_number) return;
  if (next_freq > snd_freq.maximum_number) return;
  snd_freq.n = next_freq;
  set_frequency_receive();
}

uint8_t scan_frequency(int8_t stepval, uint16_t maxsteps)
{
  uint16_t avg;
  uint8_t aborted = 0;

  avg = 0;
  for (uint8_t i=0;i<8;i++)
     avg += accumulate_all_channels(64);
  avg >>= 3; 
  for (;;)
  {
    uint16_t val;

    if (maxsteps == 0)
    {
      aborted = 2;
      break;
    } else --maxsteps;
    increment_decrement_frequency(stepval);
    scroll_redraw_snd();
    update_bars();
    if (abort_button_enter())
    {
      aborted = 1;
      break;
    }
    val = accumulate_all_channels(64);
    if (val > (avg*2)) break;
    avg = (15*avg+val) >> 4;    
  }
  if (aborted == 1)
  {
    delay(250);
    lcd.clearButtons();
  }
  return aborted;
}

uint8_t scan_refine(uint8_t dir, uint8_t iter)
{
  uint8_t code;
  set_frequency_receive();
  dsp_initialize_protocol(ps.ns.protocol, rc.wide);
  for (uint8_t i=0;i<iter;i++)
  {
     code = scan_frequency(dir ? -10 : 10, 50);
     if (code < 2) break;
     dir = !dir;
  }
  dsp_initialize_fastscan();
  return code;
}

uint8_t scan_frequency_end(uint8_t code)
{
  set_frequency_receive();
  dsp_initialize_protocol(ps.ns.protocol, rc.wide);
  return code;
}

uint8_t scan_frequency_mode(uint8_t dir, uint8_t stepval)
{
  uint8_t code;
  dsp_initialize_fastscan();
  for (;;)
  {
    code = scan_frequency(dir ? -stepval : stepval, 1000);
    if (code == 0)
    {
      increment_decrement_frequency(dir ? 250 : -250);
      code = scan_refine(dir, 5);
      if (code < 2) return scan_frequency_end(code);
    } else return scan_frequency_end(code);
  }
}

void set_frequency_mode(uint8_t selected)
{
  snd_freq.position = (selected == 1) ? 7 : 0;
  scroll_number_start(&snd_freq);
  while (!snd_freq.entered)
  {
    idle_task();
    scroll_number_key(&snd_freq);
    if (snd_freq.changed)
    {
       set_frequency_receive();
       snd_freq.changed = 0;
    }
    update_bars();
    update_readout();
  }
}

const char mode_set[] PROGMEM = "Mode Set";

void set_transmission_mode(void)
{  
  uint8_t selected;
  menu_str mn = { protocolmenu, 0, 0, 8, 0, 0 };
  mn.item = ps.ns.protocol;
  do_show_menu_item(&mn);
  set_horiz_menu_keys(1);
  do
  {
    update_bars();
    selected = do_menu(&mn);
  } while (!selected);
  set_horiz_menu_keys(0);
  if (mn.item > 0)
  {
    set_protocol(mn.item);
    temporary_message(mode_set);
  }
}

const char txtitle1[] PROGMEM = "Return";
const char txtitle2[] PROGMEM = "Txmit";
const char quittitle[] PROGMEM = "Quit";
const char txtitle4[] PROGMEM = "Clear";
const char txmitting[] PROGMEM = "Transmitting...";

const char *const txmenu[] PROGMEM = {txtitle1,txtitle2,quittitle,txtitle4,NULL };

static uint8_t transmit_message_length(void)
{
  uint8_t len = sad_buf.numchars;
  do
  {
    len--;
    if (sad_buf.buffer[len] != ' ') 
    {
      len++;
      break;
    }
  } while (len > 0);
  return len;
}

void transmit_mode_callback(dsp_txmit_message_state *dtms)
{

  if (dtms->current_symbol < sad_buf.numchars)
     sad_buf.position = dtms->current_symbol;
  scroll_alpha_redraw(&sad_buf);
  if (abort_button_enter())
    dtms->aborted = 1;
  write_char_serial((char)sad_buf.buffer[dtms->current_symbol]);
}


void transmit_mode(uint8_t selected)
{
  menu_str mn = { txmenu, 0, 0, 8, 0, 2 };
  
  if (!check_band_warning()) return;

  sad_buf.position = (selected == 1) ? (sad_buf.numchars-1) : 0;
  for(;;)
  {
    scroll_alpha_start(&sad_buf);
    while ((!sad_buf.entered) && (!sad_buf.exited))
    {
      idle_task();
      scroll_alpha_key(&sad_buf);
      update_readout();
    }
    if (sad_buf.entered)
    {
      mn.item = 1;
      scroll_alpha_clear(&sad_buf);
      do_show_menu_item(&mn);
      uint8_t selected;
      do
      {
        update_readout();
        selected = do_menu(&mn);
      } while (!selected);
      if (mn.item == 1)
      {
        lcdPrintFlashSpaces(0, 0, txmitting, 16);
        uint8_t msg_len = transmit_message_length();
        if (msg_len > 0)
        {
          write_char_newline("tx:");
          uint8_t aborted = dsp_dispatch_txmit(snd_freq.n, sad_buf.buffer, msg_len, NULL, transmit_mode_callback);
          if ((rc.erase_on_send) && (!aborted))
          {
            sad_buf.buffer[0] = 0;
            sad_buf.position = 0;
          }  
          write_char_newline("rx:");
          set_frequency_receive();
        }
        mn.item = 0;
      } else if (mn.item == 2)
      {
        /*quit*/
        break;
      } else if (mn.item == 3)
      {
        sad_buf.buffer[0] = 0;
        sad_buf.position = 0;
      }
    } else break; 
  }
  scroll_alpha_clear(&sad_buf);
}

void receive_scroll_mode(void)
{
  srd_buf.exited = 0;
  while (!srd_buf.exited)
  {
    idle_task();
    update_bars();
    update_readout();
    scroll_readout_key(&srd_buf);
  }  
}


uint8_t current_item = 2;

typedef struct _configuration_entry
{
  void     *entry;
  uint8_t   bytes;
  uint8_t   digits;
  uint32_t  min_value;
  uint32_t  max_value;
} configuration_entry;

const char rf_bitbanger_version[] PROGMEM = RF_BITBANGER_VERSION;
const char scamp_version[] PROGMEM = SCAMP_VERSION;
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
void loop() {
  select_command_mode();
}

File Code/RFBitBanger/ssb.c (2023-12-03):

/*  ssb.c */

/*
 * Copyright (c) 2021 Daniel Marks

This software is provided 'as-is', without any express or implied
warranty. In no event will the authors be held liable for any damages
arising from the use of this software.

Permission is granted to anyone to use this software for any purpose,
including commercial applications, and to alter it and redistribute it
freely, subject to the following restrictions:

1. The origin of this software must not be misrepresented; you must not
   claim that you wrote the original software. If you use this software
   in a product, an acknowledgment in the product documentation would be
   appreciated but is not required.
2. Altered source versions must be plainly marked as such, and must not be
   misrepresented as being the original software.
3. This notice may not be removed or altered from any source distribution.
 */


#undef SSB_DEBUG

#ifdef ARDUINO
#include <Arduino.h>
#endif

#ifdef CWMOD_DEBUG
#include <stdio.h>
#include <stdlib.h>
#include <stdint.h>
#include <string.h>
#include <math.h>
#include <unistd.h>
#endif

#include "common.h"
#include "dspint.h"
#include "ssb.h"

void ssb_state_change(uint8_t state)
{
  if (state == 0)
  {
    if (ds.ssb_active != 0)
    {
      ds.ssb_active = 0;
      transmit_pwm_mode(0);
      delay(3); // wait for any interrupt to finish
      set_frequency_receive();
    }
  } else
  {
    if (ds.ssb_active == 0)
    {
      if (IS_SSB_PROTOCOL(ps.ssbs.protocol))
      {
        muteaudio_set(1);
        set_clock_onoff_mask(0x01); 
        transmit_pwm_mode(1);
        set_transmit_pwm(0);
        ds.ssb_active = 1;
      }
    }
  }
  return;
}

#define SAMPLING_CLOCK (OVERSAMPLING_CLOCKS / 2)  
  // note the base rate is 8000 Hz.  Protocols sample at 2000 Hz, hence the OVERSAMPLING_CLOCKS
  // is (8000 / 2000) Hz = 4.  However, ssb routine works at 4000 Hz, so we cut it in half.

#define SAMPLING_FREQUENCY (TIMER1_INTERRUPT_FREQ / SAMPLING_CLOCK)

// This code is adapted from PE1NNZ ssb() function.   

#define _UA (22*32)                                         

#define FRACTIONAL_MULT_FREQUENCY (uint32_t)(((SAMPLING_FREQUENCY)*256ul)/_UA)

#define ATAN_APPROX(z1,z2) (((((_UA/8) + (_UA/22)) - ((_UA/22) * (z1)) / (z2)) * (z1)) / (z2))  
   // approx Pi/4 + 0.285*z*(1-abs(z)) from 
   // [1] http://www-labs.iro.umontreal.ca/~mignotte/IFT2425/Documents/EfficientApproximationArctgFunction.pdf
   // (8/22)*Pi/4 approx 0.285
   // formula scaled by (1/8+1/22)/(Pi/4+0.285) or 0.159

#define OCTAGON_MAGNITUDE_PHASE(mag,phs,x,y) do { \
   uint16_t ux = ((x) < 0 ? -(x) : (x)); \
   uint16_t uy = ((y) < 0 ? -(y) : (y)); \
   mag = ((uy > ux) ? (uy+ux/4) : (ux+uy/4)); \
   phs = ((uy > ux) ? ((_UA/4) - ATAN_APPROX(ux,uy)) : ((ux == 0) ? 0 : ATAN_APPROX(uy,ux))); \
   phs = (((x) < 0) ? ((_UA/2) - phs) : phs); \
   phs = (((y) < 0) ? -phs : phs); \
} while(0)

#undef PWR_075_AMPLITUDE_TABLE
#undef SQUARE_ROOT_AMPLITUDE_TABLE

#ifdef SQUARE_ROOT_AMPLITUDE_TABLE
#define AMPLITUDE_TABLE_PRESENT
const uint8_t PROGMEM amplitude_table[256] =
{
  0,16,22,27,32,35,39,42,45,48,50,53,55,57,59,61,64,65,67,69,71,73,75,76,78,80,81,83,84,86,87,89,90,91,93,94,96,97,98,99,101,102,103,104,106,107,108,109,110,112,113,114,115,116,117,118,119,120,121,122,123,124,125,126,128,128,129,130,131,132,133,134,135,136,137,138,139,140,141,142,143,144,144,145,146,147,148,149,150,150,151,152,153,154,155,155,156,157,158,159,160,160,161,162,163,163,164,165,166,167,167,168,169,170,170,171,172,173,173,174,175,176,176,177,178,178,179,180,181,181,182,183,183,184,185,185,186,187,187,188,189,189,190,191,192,192,193,193,194,195,195,196,197,197,198,199,199,200,201,201,202,203,203,204,204,205,206,206,207,208,208,209,209,210,211,211,212,212,213,214,214,215,215,216,217,217,218,218,219,219,220,221,221,222,222,223,224,224,225,225,226,226,227,227,228,229,229,230,230,231,231,232,232,233,234,234,235,235,236,236,237,237,238,238,239,240,240,241,241,242,242,243,243,244,244,245,245,246,246,247,247,248,248,249,249,250,250,251,251,252,252,253,253,254,254,255 
};
#endif

#ifdef PWR_075_AMPLITUDE_TABLE
#define AMPLITUDE_TABLE_PRESENT
const uint8_t PROGMEM amplitude_table[256] =
{
 0,4,6,9,11,13,15,17,19,20,22,24,25,27,28,30,32,33,34,36,37,39,40,42,43,44,46,47,48,49,51,52,53,55,56,57,58,60,61,62,63,64,65,67,68,69,70,71,72,74,75,76,77,78,79,80,81,82,84,85,86,87,88,89,90,91,92,93,94,95,96,97,98,99,100,101,102,103,104,105,106,108,108,109,110,111,112,113,114,115,116,117,118,119,120,121,122,123,124,125,126,127,128,129,130,131,132,133,134,134,135,136,137,138,139,140,141,142,143,144,145,145,146,147,148,149,150,151,152,153,153,154,155,156,157,158,159,160,161,161,162,163,164,165,166,167,168,168,169,170,171,172,173,174,174,175,176,177,178,179,179,180,181,182,183,184,184,185,186,187,188,189,189,190,191,192,193,194,194,195,196,197,198,199,199,200,201,202,203,203,204,205,206,207,207,208,209,210,211,211,212,213,214,215,215,216,217,218,219,219,220,221,222,223,223,224,225,226,226,227,228,229,230,230,231,232,233,233,234,235,236,237,237,238,239,240,240,241,242,243,243,244,245,246,246,247,248,249,249,250,251,252,252,253,254,255
};
#endif

void ssb_interrupt(int16_t sample)
{
  uint16_t magnitude;
  int16_t phase, phase_difference, frequency;
  int16_t ac, in_val, quad_val;
  int32_t in_prod, quad_prod;

  if (!ds.ssb_active) return;

  ps.ssbs.cumulative_sample += sample; 
  if ((++ps.ssbs.sampling_clock) < SAMPLING_CLOCK)
   return;

  ps.ssbs.sampling_clock = 0;

  ADMUX = (1 << REFS0) | (1 << MUX0);  // set to sample the ADC1 which is the MIC audio
  ADCSRA = (1 << ADEN) | (1 << ADPS1) | (1 << ADPS0) | (1 << ADSC);  
    
  for (uint8_t i=0;i<SSB_FIR_LENGTH-1;i++)
    ps.ssbs.ssb_fir_buffer[i] = ps.ssbs.ssb_fir_buffer[i+1];

  ac = ps.ssbs.cumulative_sample * 2;
  ac += ps.ssbs.lpf_z1;              // LPF
  ps.ssbs.lpf_z1 = (ps.ssbs.cumulative_sample - (ps.ssbs.lpf_z1 * 4) + ps.ssbs.lpf_z1) / (3 + 1);  // guess that (3+1) is to make this an affine sum
  ps.ssbs.dc_level = (ac + (ps.ssbs.dc_level * 4) - ps.ssbs.dc_level) / (3 + 1); 
  ps.ssbs.ssb_fir_buffer[SSB_FIR_LENGTH-1] = (ac - ps.ssbs.dc_level) / 2;

  in_val = ps.ssbs.ssb_fir_buffer[SSB_FIR_LENGTH/2-1];
  quad_val = ( (ps.ssbs.ssb_fir_buffer[0] - ps.ssbs.ssb_fir_buffer[14]) * 2 + 
               (ps.ssbs.ssb_fir_buffer[2] - ps.ssbs.ssb_fir_buffer[12]) * 8 +
               (ps.ssbs.ssb_fir_buffer[4] - ps.ssbs.ssb_fir_buffer[10]) * 21 + 
               (ps.ssbs.ssb_fir_buffer[6] - ps.ssbs.ssb_fir_buffer[8]) * 15) / 128
           + (ps.ssbs.ssb_fir_buffer[6] - ps.ssbs.ssb_fir_buffer[8]) / 2; 
     // PE1NNZ Hilbert transform, 40dB side-band rejection in 400..1900Hz (@4kSPS) when used in image-rejection scenario; (Hilbert transform require 5 additional bits)
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

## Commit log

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2021-10-09 Fixed stupid disconnected line, added multiple output transistors
    [RFBitBanger-B.Cu.gbr, RFBitBanger-B.Mask.gbr, RFBitBanger-B.SilkS.gbr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]
2021-10-09 Changed to using regular HD44780 6-pin display
    [RFBitBanger-B.Cu.gbr, RFBitBanger-B.Mask.gbr, RFBitBanger-B.SilkS.gbr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]
2021-10-10 Changed wiring around, started documentation
    [RFBitBanger-B.Cu.gbr, RFBitBanger-B.Mask.gbr, RFBitBanger-B.SilkS.gbr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]
2021-10-15 Added SI5351A and code snippets
    [RFBitBanger-B.Cu.gbr, RFBitBanger-B.Mask.gbr, RFBitBanger-B.SilkS.gbr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]
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2021-11-04 Before changing to 74HC86
    [RFBitBanger-B.Cu.gbr, RFBitBanger-B.Mask.gbr, RFBitBanger-B.SilkS.gbr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]
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2021-11-07 Before swapping MUTEAUDIO and TRANSMIT
    [RFBitBanger.sch]
2021-11-09 Before rearrange audio section
    [RFBitBanger-B.Cu.gbr, RFBitBanger-B.Mask.gbr, RFBitBanger-B.SilkS.gbr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]
2021-11-10 Added RF current sensor and Bridge Board
    [DirectionalCoupler-B.Cu.gbr, DirectionalCoupler-B.Mask.gbr, DirectionalCoupler-B.SilkS.gbr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]
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2021-12-13 Completely remade board with common base input
    [DirectionalCoupler-B.Cu.gbr, DirectionalCoupler-B.Mask.gbr, DirectionalCoupler-B.SilkS.gbr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]
2021-12-22 A few minor tweaks to layout
    [RFBitBanger-B.Cu.gbr, RFBitBanger-B.Mask.gbr, RFBitBanger-B.SilkS.gbr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]
2021-12-24 Started RFBitBanger code project
    [RFBitBanger.sch]
2021-12-26 Added bias potentiometer and user interface
    [RFBitBanger-B.Cu.gbr, RFBitBanger-B.Mask.gbr, RFBitBanger-B.SilkS.gbr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]
2021-12-26 Before changing back to HPF
    [RFBitBanger-B.Cu.gbr, RFBitBanger-B.Mask.gbr, RFBitBanger-B.SilkS.gbr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]
2021-12-27 Added common mode choke, put back LPF
    [RFBitBanger-B.Cu.gbr, RFBitBanger-B.Mask.gbr, RFBitBanger-B.SilkS.gbr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]
2021-12-28 Made 3 crystals instead of 2
    [RFBitBanger-B.Cu.gbr, RFBitBanger-B.Mask.gbr, RFBitBanger-B.SilkS.gbr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]
2021-12-28 Added removal of solder mask for heatsinking
    [RFBitBanger-B.Cu.gbr, RFBitBanger-B.Mask.gbr, RFBitBanger-B.SilkS.gbr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]
2021-12-31 Added overvoltage zener and extra key inputs
    [RFBitBanger-B.Cu.gbr, RFBitBanger-B.Mask.gbr, RFBitBanger-B.SilkS.gbr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]
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2022-01-02 Fixed overcommited MOSI pin
    [RFBitBanger-B.Cu.gbr, RFBitBanger-B.Mask.gbr, RFBitBanger-B.SilkS.gbr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]
2022-01-03 Added frequency counter and power measurement circuitry to PortableTerminal
    [PortableTerminal-B.Cu.gbr, PortableTerminal-B.Mask.gbr, PortableTerminal-B.SilkS.gbr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]
2022-01-03 Added common mode choke to PortableTerminal
    [PortableTerminal-B.Cu.gbr, PortableTerminal-B.Mask.gbr, PortableTerminal-B.SilkS.gbr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]
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2022-01-11 Implemented timers, fixed beep audio, fixed key shaping
    [PortableTerminal-B.Cu.gbr, PortableTerminal-B.Mask.gbr, PortableTerminal-B.SilkS.gbr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]
2022-01-12 Rearranged parts for better layout
    [RFBitBanger-B.Cu.gbr, RFBitBanger-B.Mask.gbr, RFBitBanger-B.SilkS.gbr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]
2022-01-16 Changed DSP to higher audible frequencies
    [RFBitBanger-B.Cu.gbr, RFBitBanger-B.Mask.gbr, RFBitBanger-B.SilkS.gbr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]
2022-01-20 Added Display Board on Top
    [BitBangDisplay-B.Cu.gbr, BitBangDisplay-B.Mask.gbr, BitBangDisplay-B.SilkS.gbr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]
2022-01-22 Before trying to put everything onto a single line
    [BitBangDisplay-B.Cu.gbr, BitBangDisplay-B.Mask.gbr, BitBangDisplay-B.SilkS.gbr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]
2022-01-23 Changed external connector for single 20 pin or ribbon cable
    [BitBangDisplay-B.Cu.gbr, BitBangDisplay-B.Mask.gbr, BitBangDisplay-B.SilkS.gbr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]
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2022-01-28 Before changing si5351 code
    [RFBitBanger-B.Cu.gbr, RFBitBanger-B.Mask.gbr, RFBitBanger-B.SilkS.gbr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]
2022-02-04 Before adding SI5351 header
    [BitBangDisplay-B.Cu.gbr, BitBangDisplay-B.Mask.gbr, BitBangDisplay-B.SilkS.gbr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]
2022-02-04 Added connector for SI5351A board
    [RFBitBanger-B.Cu.gbr, RFBitBanger-B.Mask.gbr, RFBitBanger-B.SilkS.gbr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]
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2022-04-23 Added extra row of ground pins for 40 pin connector
    [BitBangDisplay-B.Cu.gbr, BitBangDisplay-B.Mask.gbr, BitBangDisplay-B.SilkS.gbr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]
2022-12-29 Changed around for external filter PCB
    [BandPassFilter-B.Cu.gbr, BandPassFilter-B.Mask.gbr, BandPassFilter-B.SilkS.gbr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]
2022-12-30 BandPassFilter now has six filter boards on it
    [BandPassFilter-B.Cu.gbr, BandPassFilter-B.Mask.gbr, BandPassFilter-B.SilkS.gbr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]
2023-01-07 Working configuration, fixed bugs
    [RFBitBanger.h, RFBitBanger.ino]
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2023-01-11 Fixed many scamp issues
    [RFBitBanger.h, RFBitBanger.ino]
2023-01-17 Fixed external control mode
    [RFBitBanger.ino, cwmod.h, si5351simple.cpp]
2023-01-17 Changed bitbang display values
    [BitBangDisplay.sch]
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2023-01-18 Modified BandPass Filter, Documentation
    [BandPassFilter-B.Cu.gbr, BandPassFilter-B.Mask.gbr, BandPassFilter-B.SilkS.gbr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]
2023-01-23 Changed some component values
    [RFBitBangerRadio.sch]
2023-01-23 Increased size of heatsink pad
    [RFBitBanger-B.Cu.gbr, RFBitBanger-B.Mask.gbr, RFBitBanger-B.SilkS.gbr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]
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2023-02-02 Modified FSK SLOW mode, added section back about +- filters
    [BandPassFilter-B.Cu.gbr, BandPassFilter-B.Mask.gbr, BandPassFilter-B.SilkS.gbr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]
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2023-02-05 Converted all Kicad projects to version 6.0.10
    [BandPassFilter-B.Cu.gbr, BandPassFilter-B.Mask.gbr, BandPassFilter-B.SilkS.gbr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]
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2023-02-17 Added case for RFBitBanger
    [BottomCase-BottomCaseBody.stl, BottomCase.FCStd, PaddlesKey-PaddlesKeyBody.stl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]
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2023-03-30 Added parametric model of air core coil forms
    [AxialInductorBobbin-AxialBobbinT-180 nH.stl, AxialInductorBobbin-AxialBobbinT-360 nH.stl, AxialInductorBobbin-AxialBobbinT-750 nH.stl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]
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2023-04-05 Fixed iambic mode b
    [RFBitBanger.ino]
2023-04-06 Added reinforcement to case standoffs
    [BottomCase-BottomCaseBody.stl, BottomCase.FCStd, TopCase-TopCaseBody.stl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]
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2023-05-28 Minor fixes to SMT
    [RFBitBangSMT.kicad_pcb, RFBitBangSMT.kicad_sch, RFBitBangSMTRadio.kicad_sch]
2023-05-29 Some more minor SMT fixed
    [RFBitBangSMT-B_Cu.gbr, RFBitBangSMT-B_Mask.gbr, RFBitBangSMT-B_Silkscreen.gbr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]
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2023-06-07 A few minor fixes to SMT
    [RFBitBangSMT.kicad_pcb, RFBitBangSMT.kicad_sch, RFBitBangSMTRadio.kicad_sch]
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2023-06-13 A few more fixes
    [RFBitBanger.ino, ssb.c]
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2023-08-04 Fixed problems with manual, added filters
    [RFBitBangSMT-CuBottom.gbr, RFBitBangSMT-CuTop.gbr, RFBitBangSMT-EdgeCuts.gbr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]
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2023-08-07 Aligned mounting holes to new display for BitBangDisplay
    [BitBangDisplay-B_Cu.gbr, BitBangDisplay-B_Mask.gbr, BitBangDisplay-B_Silkscreen.gbr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]
2023-08-07 Swapped UART and PADDLE jacks
    [BitBangDisplay-B_Cu.gbr, BitBangDisplay-B_Mask.gbr, BitBangDisplay-B_Silkscreen.gbr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]
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2023-10-08 Swapped multisynth and PLL integer dividers
    [RFBitBanger.ino, si5351simple.cpp]
2023-10-14 Made input/output buffers bigger, fixed scamp repeat bug
    [RFBitBanger.ino]
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2023-11-12 Issue #4 - Enabling non-Arduino builds for core SCAMP encode/decode
2023-11-12 Issue #4 - Non-Arduino build
2023-11-18 Added portability and fixed some compilation errors
    [RFBitBanger.ino, ssb.c]
2023-12-03 Added TCXO to documentation, finalized JLCPCB for batch 2
    [RFBitBangSMT-CuBottom.gbr, RFBitBangSMT-CuTop.gbr, RFBitBangSMT-EdgeCuts.gbr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]

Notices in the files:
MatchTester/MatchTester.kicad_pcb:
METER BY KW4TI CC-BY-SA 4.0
